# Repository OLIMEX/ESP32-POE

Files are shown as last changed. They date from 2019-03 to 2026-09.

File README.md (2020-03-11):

# ESP32-POE

ESP32-PoE is an IoT WIFI/BLE/Ethernet development board with Power-Over-Ethernet feature.

The Si3402-B chip is IEEE 802.3-compliant, including pre-standard (legacy) PoE support. 

Perfect solution for Internet-of-Things that can be expanded with sensors and actuators taking power from Ethernet cable.

Low-power design consuming less then 100uA in deep sleep mode!

Product page: https://www.olimex.com/Products/IoT/ESP32/ESP32-POE/open-source-hardware

## License
* Hardware is released under Apache 2.0 License
* Software is released under GPL3 License
* Documentation is released under CC BY-SA 3.0

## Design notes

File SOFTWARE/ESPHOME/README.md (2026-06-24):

# ESPHome configurations for Olimex ESP32-POE boards

These YAML files are starter configurations for ESP32-POE and ESP32-POE-ISO
variants.

## Which file to use

- `esp32-poe.yaml`: ESP32-POE with ESP32-WROOM-32E-N4, 4 MB flash.
- `esp32-poe-16mb.yaml`: ESP32-POE with ESP32-WROOM-32E-N16, 16 MB flash.
- `esp32-poe-wrover.yaml`: ESP32-POE with ESP32-WROVER-E-N4R8, 4 MB flash and PSRAM.
- `esp32-poe-iso.yaml`: ESP32-POE-ISO with ESP32-WROOM-32E-N4, 4 MB flash.
- `esp32-poe-iso-16mb.yaml`: ESP32-POE-ISO with ESP32-WROOM-32E-N16, 16 MB flash.
- `esp32-poe-iso-wrover.yaml`: ESP32-POE-ISO with ESP32-WROVER-E-N4R8, 4 MB flash and PSRAM.

External antenna module variants use the same YAML as the matching flash/PSRAM
variant.

## Wi-Fi or Ethernet

The files enable Wi-Fi by default. Add your credentials to `secrets.yaml`:

```yaml
wifi_ssid: "your_wifi_name"
wifi_password: "your_wifi_password"
```

To use Ethernet instead, comment the whole `wifi:` section and
`captive_portal:`, then uncomment the `ethernet:` section in the YAML.

## Notes

- WROOM variants use Ethernet clock output on GPIO17.
- WROVER variants use Ethernet clock output on GPIO0.
- WROVER variants use GPIO33 for UEXT I2C SCL because GPIO16/GPIO17 are used
  by PSRAM.
- UEXT SPI uses GPIO14 SCK, GPIO2 MOSI, GPIO15 MISO, and GPIO5 chip-select.
  These pins are shared with the microSD interface.
- The 16 MB YAMLs set `esp32.flash_size: 16MB`; ESPHome defaults to 4 MB if
  this is not specified.

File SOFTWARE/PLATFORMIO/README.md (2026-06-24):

# PlatformIO board definitions for Olimex ESP32-POE boards

This folder contains custom PlatformIO board manifests for ESP32-POE and
ESP32-POE-ISO variants, plus a `platformio.ini` with ready-to-use environments.

## Which environment to use

- `esp32-poe`: ESP32-POE with ESP32-WROOM-32E-N4, 4 MB flash.
- `esp32-poe-16mb`: ESP32-POE with ESP32-WROOM-32E-N16, 16 MB flash.
- `esp32-poe-wrover`: ESP32-POE with ESP32-WROVER-E-N4R8, 4 MB flash and PSRAM.
- `esp32-poe-iso`: ESP32-POE-ISO with ESP32-WROOM-32E-N4, 4 MB flash.
- `esp32-poe-iso-16mb`: ESP32-POE-ISO with ESP32-WROOM-32E-N16, 16 MB flash.
- `esp32-poe-iso-wrover`: ESP32-POE-ISO with ESP32-WROVER-E-N4R8, 4 MB flash and PSRAM.

External antenna module variants use the same environment as the matching
flash/PSRAM variant.

## How to build

Run PlatformIO from this folder:

```sh
pio run -e esp32-poe
```

Replace `esp32-poe` with the environment for your board. For example:

```sh
pio run -e esp32-poe-iso-16mb
pio run -e esp32-poe-wrover
```

The `platformio.ini` sets `boards_dir = .`, so PlatformIO will find the custom
JSON files in this same folder.

## Board manifest notes

- WROOM N4 manifests set 4 MB flash.
- WROOM N16 manifests set 16 MB flash, `maximum_size: 16777216`, and Arduino
  partition table `default_16MB.csv`.
- WROVER manifests enable PSRAM with `BOARD_HAS_PSRAM` and `psram_type: qspi`.
- All manifests predefine LAN8720 Ethernet macros for Arduino `ETH.begin()`.
- WROOM variants use Ethernet clock output on GPIO17.
- WROVER variants use Ethernet clock output on GPIO0.
- Ethernet MDC is GPIO23, MDIO is GPIO18, PHY address is 0, and PHY power is
  GPIO12.

## Upload and monitor

The manifests allow USB serial upload with `esptool` and OTA upload with
`espota`. Serial monitor speed is set to 115200 in `platformio.ini`.

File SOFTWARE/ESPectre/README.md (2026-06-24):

# Using ESPectre with Olimex ESP32-POE / ESP32-POE-ISO and Home Assistant

This guide shows how to flash an Olimex [ESP32-POE](https://www.olimex.com/Products/IoT/ESP32/ESP32-POE/open-source-hardware) or [ESP32-POE-ISO](https://www.olimex.com/Products/IoT/ESP32/ESP32-POE-ISO/open-source-hardware) board with [ESPectre](https://espectre.dev/) and add it to [Home Assistant](https://www.home-assistant.io/) through ESPHome.

ESPectre is a motion detection system based on Wi-Fi Channel State Information (CSI). It detects movement by analyzing changes in the Wi-Fi signal between an ESP32 board and a Wi-Fi router or access point.

The steps below were tested with:

- Olimex ESP32-POE / ESP32-POE-ISO
- ESPectre `2.8.0`
- Home Assistant running on a Raspberry Pi
- ESPHome integration in Home Assistant

## 1. Install and prepare Home Assistant

First, you need a working Home Assistant server. In this setup, Home Assistant is running on a Raspberry Pi, but you can also use another supported board, mini PC, virtual machine, or computer.

Follow the official Home Assistant installation guide and choose the installation method that fits your hardware:

<https://www.home-assistant.io/installation/>

Make sure you can open your Home Assistant web interface before continuing. For example:

```text
http://homeassistant.local:8123/
```

The Home Assistant server and the ESP32 board must be on the same local network.

## 2. Download the ESPectre firmware

Download the pre-built ESPectre binary for the ESP32 chip from the latest ESPectre release:

<https://github.com/francescopace/espectre/releases/latest>

At the time of writing, this guide used:

<https://github.com/francescopace/espectre/releases/download/2.8.0/espectre-2.8.0-esp32.bin>

If you use a different ESP32 variant, download the correct binary for that chip.

## 3. Flash the Olimex ESP32 board

Connect the Olimex ESP32 board to your computer with a USB data cable.

You can flash the binary using different tools. This guide uses Espressif's online flasher:

<https://espressif.github.io/esptool-js/>

Open the flasher in a supported browser, such as Chrome or Edge.

1. Select a baud rate. A safe option is `115200`.
2. Click **Connect**.
3. Select the serial port for the Olimex ESP32 board.
4. Click **Connect** again.

Set the flash address to:

```text
0x0000
```

This is important. The ESPectre `.bin` file used here is a factory image and must be flashed at address `0x0000`. If it is flashed at another address, for example `0x1000`, the board will not boot correctly.

Click **Choose File** and select the ESPectre binary, for example:

```text
espectre-2.8.0-esp32.bin
```

Leave the other flash settings at their default values unless you have a specific reason to change them.

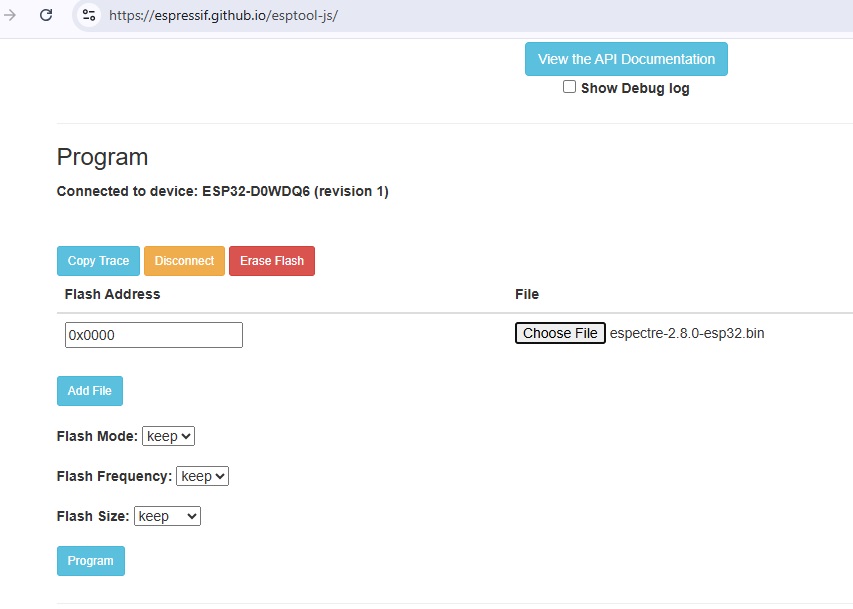
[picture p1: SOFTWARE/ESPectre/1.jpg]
Espressif online flasher configured with ESPectre binary at flash address 0x0000


Click **Program** and wait until flashing completes successfully.

## 4. Connect the board to Wi-Fi

After flashing, the board has the ESPectre firmware installed, but it still needs Wi-Fi credentials.

There are several ways to configure Wi-Fi. This guide uses the fallback Wi-Fi access point from a phone.

1. Reboot the Olimex ESP32 board by pressing the reset button.
2. On your phone, open the Wi-Fi settings.
3. Connect to the network named **ESPectre Fallback**.

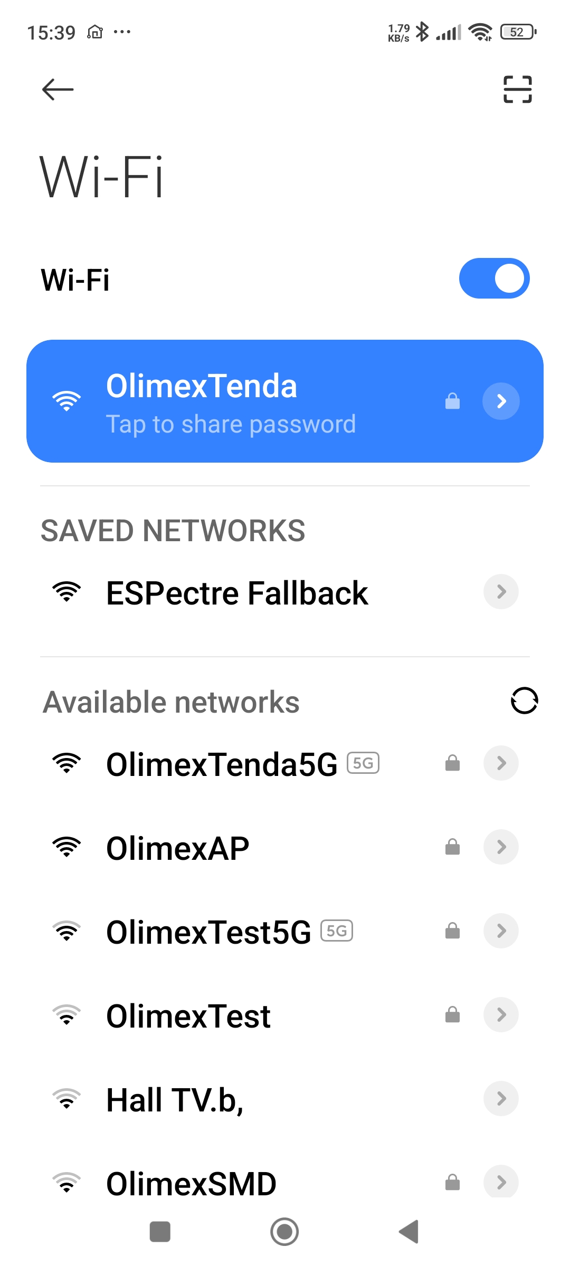
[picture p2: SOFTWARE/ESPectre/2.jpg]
Phone Wi-Fi settings showing the ESPectre Fallback network


After connecting, your phone should open the ESPectre captive portal automatically. If it does not open automatically, try opening:

```text
http://192.168.4.1/
```

Select your normal 2.4 GHz Wi-Fi network and enter its password.

The board and the Home Assistant server must be connected to the same network. In this example, the selected network is `OlimexTenda`.

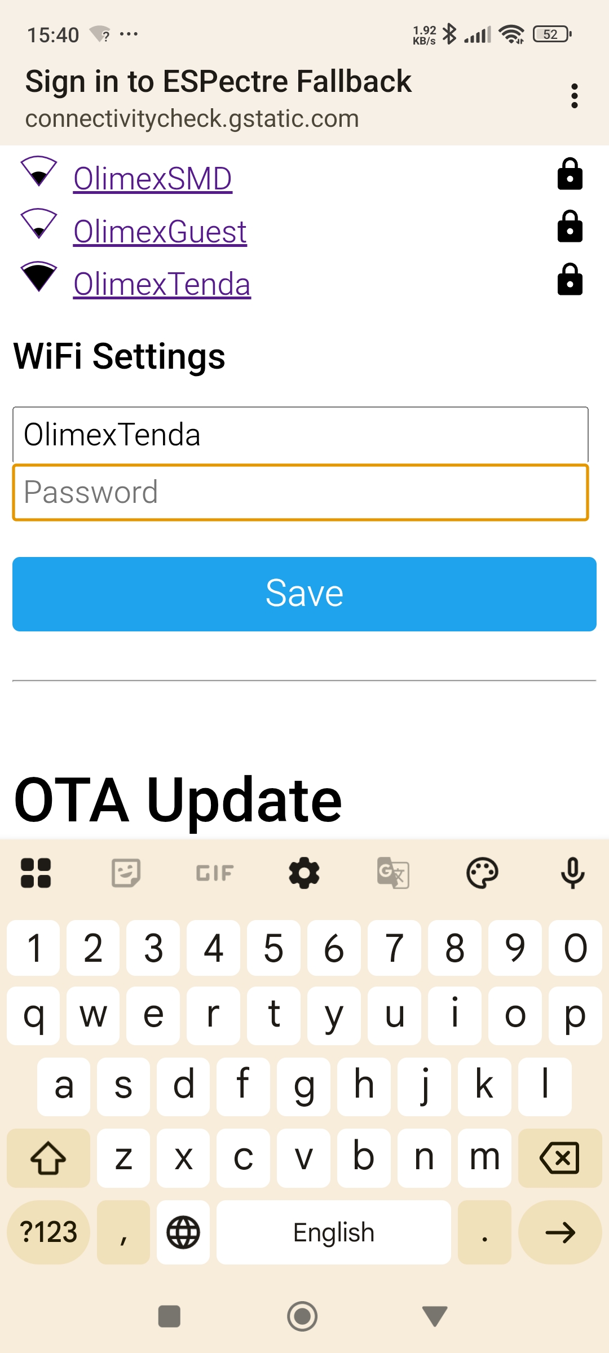
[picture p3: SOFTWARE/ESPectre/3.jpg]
ESPectre captive portal Wi-Fi settings page


Click **Save**. Wait until the page closes or the phone reconnects to your normal Wi-Fi network.

The **ESPectre Fallback** network should disappear after the board successfully joins your Wi-Fi network.

## 5. Add ESPectre to Home Assistant

Open your local Home Assistant web interface and log in with an administrator account:

```text
http://homeassistant.local:8123/
```

Go to:

```text
Settings -> Devices & services
```

Home Assistant should automatically discover the ESPectre device through ESPHome.

Look for **ESPectre** under discovered integrations and click **Add**.

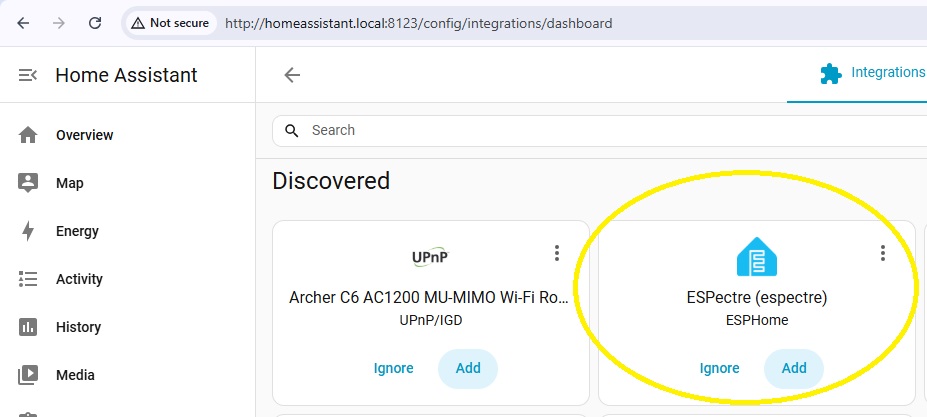
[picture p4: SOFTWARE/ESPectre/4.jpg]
Home Assistant discovered integrations page showing ESPectre


Click **Submit**. You can then assign a name and area/room if you want.

If the device is not discovered automatically, add it manually:

1. Go to **Settings -> Devices & services**.
2. Click **Add integration**.
3. Search for **ESPHome**.
4. Use `espectre.local` as the host.
5. Use port `6053`.

If `espectre.local` does not work, find the board's IP address in your router DHCP/client list and use that IP address instead.

## 6. Test motion detection

After adding the device, open the ESPectre device page in Home Assistant.

You should see entities such as:

- Motion Detected
- Movement Score
- Calibrate
- Threshold

Place the board with the antenna facing upward, preferably on the opposite side of the monitored area from the Wi-Fi router or access point.

For the first test:

1. Keep the room still.
2. Calibrate the sensor with no movement in the room.
3. Walk between the Wi-Fi router and the ESP32 board.
4. Watch the motion state and movement score in Home Assistant.
5. Adjust the threshold if needed.

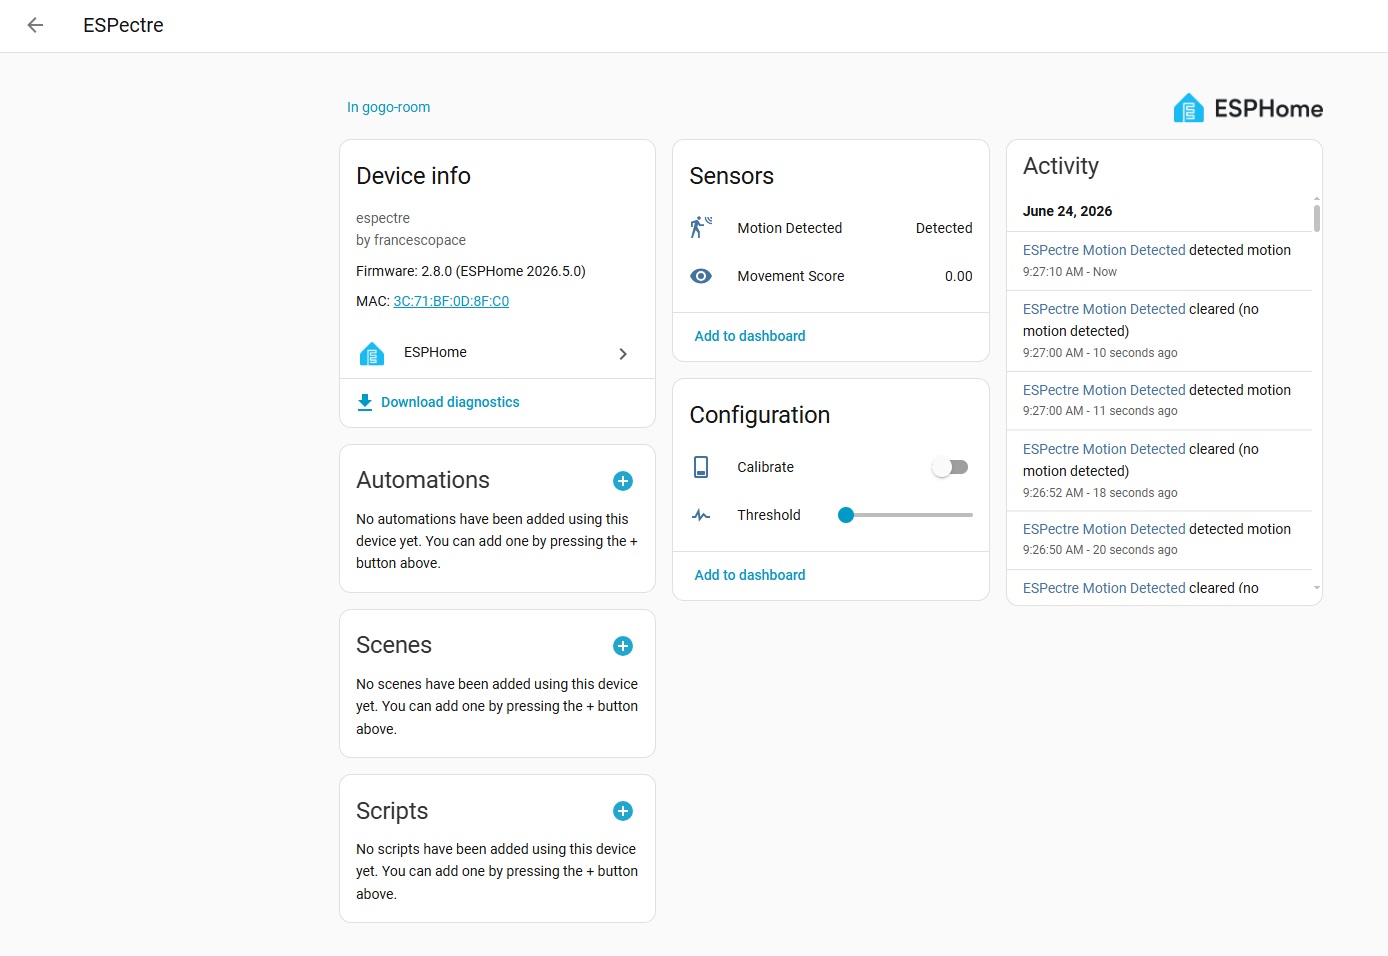
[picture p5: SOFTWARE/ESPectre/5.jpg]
ESPectre device page in Home Assistant showing motion detection and movement score


The best threshold depends on the room, router position, board position, and how sensitive you want the detection to be.

## Notes

- The pre-built ESPectre binary used here is for the original ESP32 chip.
- The ESP32-POE and ESP32-POE-ISO can be powered through PoE, but the pre-built ESPectre firmware uses Wi-Fi for CSI motion detection.
- Use a 2.4 GHz Wi-Fi network. ESP32 boards do not support 5 GHz Wi-Fi.
- If the fallback network appears again after reboot, the board probably failed to connect to your Wi-Fi. Reconnect to **ESPectre Fallback** and enter the Wi-Fi credentials again.
- If Home Assistant does not discover the board, make sure the ESP32 board and Home Assistant server are on the same network.
- If your Home Assistant account cannot see **Settings**, the account needs administrator access.

## Using other ESP32 boards

This guide can be used as a starting point for other ESP32 modules and boards. Make sure to download the correct pre-built ESPectre binary for your chip from the ESPectre releases page.

## Automation ideas

After ESPectre is added to Home Assistant through ESPHome, its motion detection entity can be used as a trigger for automations.

For example, you can use Home Assistant or the ESPHome web interface to create automations that:

- Take a snapshot from a camera when motion is detected.
- Turn on a light or relay.
- Send a notification.
- Start recording from another device.
- Trigger any other Home Assistant action supported by your setup.

This makes ESPectre useful not only as a standalone motion detector, but also as a trigger source for larger Home Assistant automations.

## Further reading

- <https://github.com/francescopace/espectre>
- <https://github.com/esphome>
- <https://github.com/home-assistant>
- <https://www.home-assistant.io/installation/>

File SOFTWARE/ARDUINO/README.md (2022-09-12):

Make sure that you have properly installed the support for ESP32 chips in your Arduino IDE environment. Check the Arduino for ESP32 GitHub page for installation instructions: https://github.com/espressif/arduino-esp32

We commit updates directly to the ESP32's GitHub. When installing the ESP32 for Arduino IDE refer to these instructions:

https://docs.espressif.com/projects/arduino-esp32/en/latest/installing.html

After a successful installation make sure to select the Olimex board in Tools -> Board and its corresponding COM port from Tools -> Port.

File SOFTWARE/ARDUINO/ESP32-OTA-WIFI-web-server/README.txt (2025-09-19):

This code demonstrates Over-the-Air upgrade functionality over WIFI (e.g. remote update).

This demo is compatible with ESP32-POE and ESP32-POE-ISO without any changes.

It is implementation of the free version of ElegantOTA. It is worth checking and supporting the ElegantOTA project.

How to use this demo?

Author used Arduino IDE 1.8.19 and version 3.1.3 of the esp32 package for Arduino released by espressif systems. You also need to install ElegantOTA via the Arduino Library Manager, follow the guide here:

https://docs.elegantota.pro/getting-started/installation

You need to change the WIFI credentials with yours (SSID, PASSWORD).

It is recommended to attach a LED between GND and GPIO4 at the UEXT (pins #2 and #3) for quicker empirical debug.

Make sure the exact board is selected in Arduino IDE and proper COM then open the ota-server.ino and then Upload it to the board. Check the serial for web-page address and go to the address via a browser and append /upload to land the upload page.

The interface requires binary to upload. You can create such binary via Arduino IDE from Sketch -> "Export compiled binary". Open ota-server-gpio1000.ino and ota-server-gpio5000.ino and click export compiled binary on both. Use these binaries to upload to the board via the Ethernet interface. If you have attached a LED to GPIO4 you'd see it start blink every 1s or every 5s depending on the code.

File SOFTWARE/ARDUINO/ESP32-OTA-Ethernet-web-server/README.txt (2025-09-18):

This code demonstrates Over-the-Air upgrade functionality over Ethernet (e.g. remote update).

This demo is compatible with ESP32-POE and ESP32-POE-ISO without any changes. 

WROVER variants of ESP32-POE and ESP32-POE-ISO require slight modifcation (changing GPIO17 to GPIO0).

The other Olimex-made boards require easy edit to fit the hardware setup, just change the defintions in:

ETH.begin(ETH_PHY_LAN8720, 0, 23, 18, 12, ETH_CLOCK_GPIO17_OUT);

What is this demo?

It allows OTA downloads via Ethernet. It creates web-server and prints in the serial terminal the IP address of the web-server. The downloads are done via the interface of the web-page at the IP address assigned by DHCP. The web-page also prints firmware version, IP address and size of binary.

How to use this demo?

Author used Arduino IDE 1.8.19 and version 3.1.3 of the esp32 package for Arduino released by espressif systems.

It is recommended to attach a LED between GND and GPIO4 at the UEXT (pins #2 and #3) for quicker debug.

Make sure the exact board is selected in Arduino IDE and proper COM then load the OTA-ETHERNET-PAGE.ino and then Upload it to the board.

Start serial terminal to see IP address asigned but if you missed it just reset the board from the RST1 button. Then navigate to the IP address via a web browser.

The interface requires binary to upload. You can create such binary via Arduino IDE from Sketch -> "Export compiled binary". Open OTA-ETHERNET-PAGE-BLINK1000.ino and OTA-ETHERNET-PAGE-BLINK5000.ino and click export compiled binary on both. Use these binaries to upload to the board via the Ethernet interface. If you have attached a LED to GPIO4 you'd see it start blinkig and also the web-page should get different firmware version for different binaries you use.

Refer to the pictures.

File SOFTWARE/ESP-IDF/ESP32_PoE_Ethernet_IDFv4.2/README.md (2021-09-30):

# Ethernet Example

## Overview

This example is based on the original example of Espressif "ethernet\basic" and adapted to function with Olimex boards ESP32-PoE and ESP32-PoE-ISO. It demonstrates basic usage of `Ethernet driver` together with `tcpip_adapter`. The work flow of the example could be as follows:

1. Install Ethernet driver
2. Send DHCP requests and wait for a DHCP lease
3. If get IP address successfully, then you will be able to ping the device

If you have a new Ethernet application to go (for example, connect to IoT cloud via Ethernet), try this as a basic template, then add your own code.

## How to use example

### Hardware Required

To run this example, it's recommended that you have one of the Olimex boards [ESP32-PoE](https://www.olimex.com/Products/IoT/ESP32/ESP32-POE/) or [ESP32-PoE-ISO](https://www.olimex.com/Products/IoT/ESP32/ESP32-POE-ISO/). This example should also work for 3rd party ESP32 board as long as it's integrated with a supported Ethernet PHY chip. Up until now, ESP-IDF supports up to four Ethernet PHY: `LAN8720`, `IP101`, `DP83848` and `RTL8201`, additional PHY drivers should be implemented by users themselves.

Notice that Olimex board uses LAN8710 chip but the libraries for LAN8710 and LAN8720 are similar (the chips are very similar).

Besides that, `esp_eth` component can drive third-party Ethernet module which integrates MAC and PHY and provides common communication interface (e.g. SPI, USB, etc).This example will take the **LAN8720** library for the an example, illustrating how to install the Ethernet driver in the same manner. In this project by default this feature is disabled. If you want to enable it:
```
idf.py menuconfig
```
then option and navigate to "Component config -> Ethernet" and check the "Support SPI to Ethernet Module" and then in that submenu check "Use LAN8720".

#### Pin Assignment

| GPIO | RMII Signal | Notes |
| --- | --- | --- |
| GPIO21 | TX_EN | EMAC_TX_EN |
| GPIO19 | TX0 | EMAC_TXD0 |
| GPIO22 | TX1 | EMAC_TXD1 |
| GPIO25 | RX0 | EMAC_RXD0 |
| GPIO26 | RX1 | EMAC_RXD1 |
| GPIO27 | CRS_DV | EMAC_RX_DRV  |
| GPIO17 | CLK | EMAC_CLK_OUT |

* SMI (Serial Management Interface) wiring is not fixed. You may need to changed it according to your board schematic. By default they're connected as follows:

| GPIO | SMI Signal  | Notes |
| --- | --- | --- |
| GPIO23 | MDC | Output to PHY |
| GPIO18 | MDIO | Bidirectional |

* PHY chip has a reset pin, but is not connected to the ESP32-PoE(-ISO) and thus it is left as -1 value.
### Configure the project

```
idf.py menuconfig
```

In the Example Configuration menu:

Choose the kind of Ethernet under Ethernet Type.
If Internal EMAC is selected:
Choose PHY device under Ethernet PHY Device, by default, ESP32-PoE(-ISO) has an LAN8710A on board but it works fine with LAN8720 selected from the menuconfig.
Set GPIO number used by SMI signal under SMI MDC GPIO number and SMI MDIO GPIO number respectively.
If DM9051 Module is selected:
Set SPI specific configuration, including SPI host number, GPIO number and clock rate.
Set GPIO number used by PHY chip reset under PHY Reset GPIO number, you may have to change the default value according to your board schematic. PHY hardware reset can be disabled by set this value to -1.
Set PHY address under PHY Address, you may have to change the default value according to your board schematic.
For this project values are as follows:
| Value  | Option |
| --- | --- |
| Internal | Ethernet Type |
| LAN8720  |  Ethernet PHY Device  |
|  GPIO23  | SMI MDC GPIO |
|  GPIO18  | SMI MDIO GPIO |
| -1 | PHY Reset GPIO number |
| 0 | PHY Address |

In the Component config > Ethernet menu:

Under Support ESP32 internal EMAC controller sub-menu:
In the PHY interface, select Reduced Media Independent Interface (RMII), ESP-IDF currently only support RMII mode.
In the RMII clock mode, select one of the source that RMII clock (50MHz) comes from: Input RMII clock from external or Output RMII clock from internal.
If Output RMII clock from internal is enabled, you also have to set the GPIO number that used to output the RMII clock, under RMII clock GPIO number. In this case, you can set the GPIO number to 16 or 17.
If Output RMII clock from GPIO0 (Experimental!) is also enabled, then you have no choice but GPIO0 to output the RMII clock.
In Amount of Ethernet DMA Rx buffers and Amount of Ethernet DMA Tx buffers, you can set the amount of DMA buffers used for Tx and Rx.
Under Support SPI to Ethernet Module sub-menu, select the SPI module that you used for this example. Currently ESP-IDF only supports DM9051.
For this project values are as follows:
| Value | Option |
| --- | ---|
| RMII | PHY Interface |
|  Output |  RMII clock mode |
| unchecked |  Output RMII clock |
|  GPIO17 |  clock PGIO number |
| 512 | DMA buffer Size  |
| 10 | DMA Rx buffers |
| 10 | DMA Tx buffers |

### Build, Flash, and Run

Build the project and flash it to the board, then run monitor tool to view serial output:

```
idf.py -p PORT build flash monitor
```

(Replace PORT with the name of the serial port to use.)

(To exit the serial monitor, type ``Ctrl-]``.)

See the [Getting Started Guide](https://docs.espressif.com/projects/esp-idf/en/latest/get-started/index.html) for full steps to configure and use ESP-IDF to build projects.

## Example Output

```bash
I (394) eth_example: Ethernet Started
I (3934) eth_example: Ethernet Link Up
I (3934) eth_example: Ethernet HW Addr 30:ae:a4:c6:87:5b
I (5864) tcpip_adapter: eth ip: 192.168.2.151, mask: 255.255.255.0, gw: 192.168.2.2
I (5864) eth_example: Ethernet Got IP Address
I (5864) eth_example: ~~~~~~~~~~~
I (5864) eth_example: ETHIP:192.168.2.151
I (5874) eth_example: ETHMASK:255.255.255.0
I (5874) eth_example: ETHGW:192.168.2.2
I (5884) eth_example: ~~~~~~~~~~~
```

Now you can ping your ESP32 in the terminal by entering `ping 192.168.2.151` (it depends on the actual IP address you get).

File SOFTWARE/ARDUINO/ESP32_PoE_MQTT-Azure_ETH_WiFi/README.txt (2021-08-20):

This example combines two default examples (to add Azure feature with Ethernet as well) from the Espressif Package:
1) ESP32 Azure IoT Arduino --> SimpleMQTT
2) WiFi --> ETH_LAN8720
<<<<<<< HEAD
In order to work you have to choose the prefered network option (ethernet/WiFi) depending on the ETHERNET macro on the top of the project. In case it is commented out, WiFi will be used and you have to input the SSID and password of your WiFi network. Ethernet is chosen by default.
=======
In order to work you have to choose the prefered network option (ethernet/WiFi) depending on the ETHERNET macro on the top of the project. In case it is commented WiFi will be used and you have to input the SSID and password of your WiFi network. Ethernet is chosen by default.
>>>>>>> origin/master
Also you have to input in "connectionString" the HostName, DeviceID and SharedAccessKey from Azure. In order to get these values follow the instructions on the Microsoft guide:
https://docs.microsoft.com/en-us/samples/azure-samples/esp-samples/esp-samples/
https://docs.microsoft.com/en-us/azure/iot-hub/iot-hub-create-through-portal

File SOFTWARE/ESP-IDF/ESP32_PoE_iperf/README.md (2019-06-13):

This demo is based on the original iperf demo in esp-idf with adapted configuration for ESP32-PoE.

In order to make it work:
1) Select the port where the board has connected using menuconfig. To do so type inside the console (msys32 or terminal):
make menuconfig

2) Navigate to "Menu flasher config --> Default serial port" select your port.

3) After that flash the board (this may take a while the first time after you change any of the configurations)
make flash

4) Then run the terminal
make monitor

5) Wait to initialize follow the instructions on the terminal:
5.1) Run the ethernet
ethernet start
5.2) Optionally if you want to see more details (IP address, mask, default gateway) type
ethernet macro

6) Run the iperf
6.1) Server mode:
iperf -s -i 1 -t 10
with this you will run it for 10 seconds transfer (more than that will trigger the watchdog reset) and 1 second interval.

6.2) Client mode:
iperf -c SERVER_IP_ADDRESS -i 1

You can check the sample data inside the ESP32-PoE_Data.txt file.

YYYY/MM/DD
2019/06/13

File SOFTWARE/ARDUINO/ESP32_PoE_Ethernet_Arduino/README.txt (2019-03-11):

This demo is based on the default demo of espressif package "ETH_LAN8720" adapted for Olimex board ESP32-PoE rev.B.
It implements acquiring of an IP address and ethernet event usage which are visible on the terminal.

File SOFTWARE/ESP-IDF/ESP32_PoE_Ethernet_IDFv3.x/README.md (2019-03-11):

This is a simple demo for Olimex ESP32-PoE revision B board.

The demo sets up Ethernet connection and acquires IP address. It is made with ESP-IDF.

In order to get it the software you should:

1) Setup the ESP-IDF development framework. You can download and install it by following the instructions here  https://github.com/espressif/esp-idf

2) Start: "msys32/mingw32.exe" and navigate to this project's directory.

3) Connect ESP32-PoE to the USB and specify the board's USB port in the ESP-IDF menu:

3.1) "make menuconfig"
3.2) Navigate to: Serial flasher config --> Default serial port --> <here select proper USB port>
3.3) Save the settings.

4) Compile this example and upload it to the board with command: "make flash"

5) Wait until firmware is flashed and open terminal on the ESP32-PoE port.

6) Press enter to start the demo and wait until it is initialized. Your network needs DHCP.

7) When you get IP address you can ping the printed IP.

2018/09/14

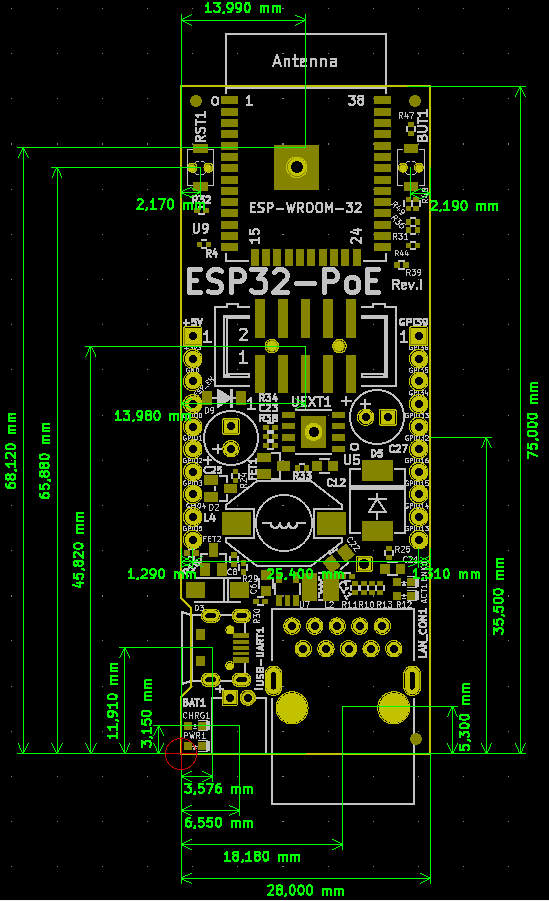
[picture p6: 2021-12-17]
HARDWARE/Dimensions/top.png

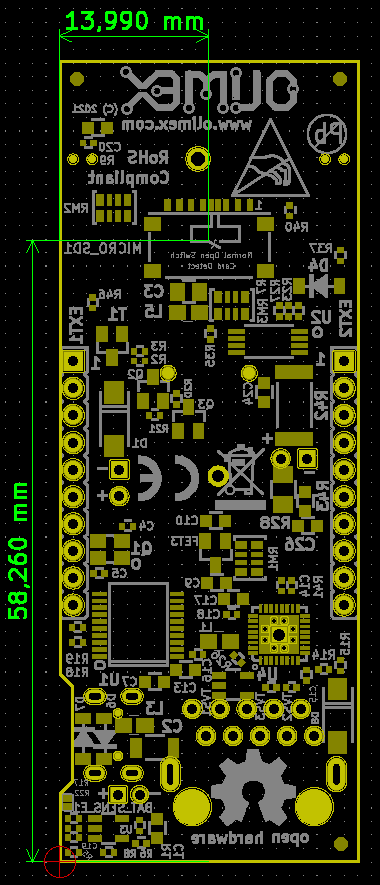
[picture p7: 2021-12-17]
HARDWARE/Dimensions/bottom.png

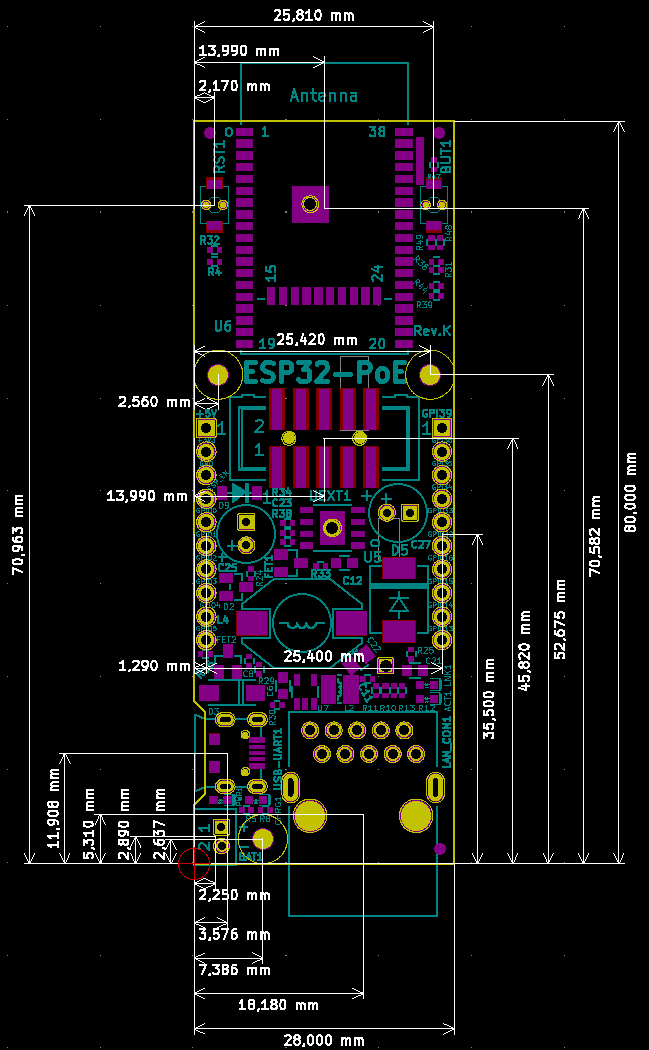
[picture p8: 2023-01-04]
HARDWARE/Dimensions/Revision J and newer/esp32-poe-dimensions.png

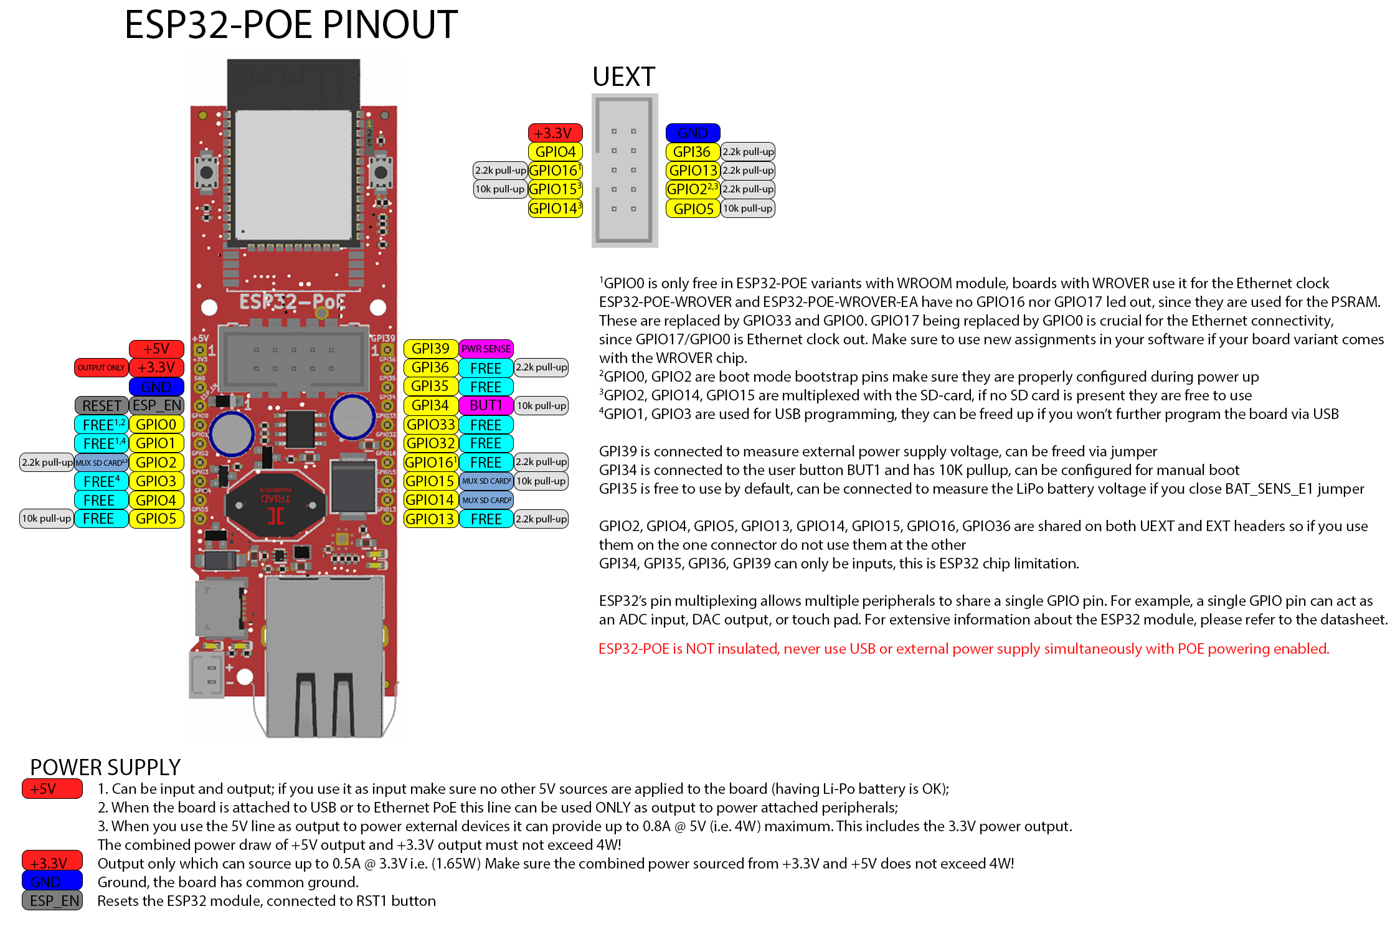
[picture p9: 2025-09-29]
DOCUMENTS/ESP32-POE-PINOUT.png

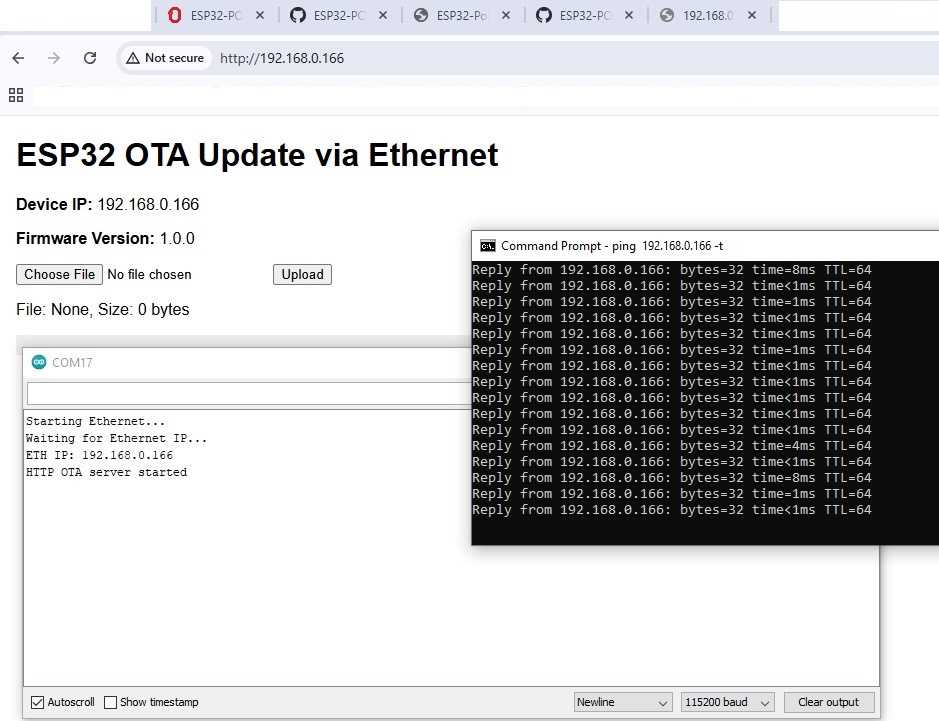
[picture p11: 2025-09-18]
SOFTWARE/ARDUINO/ESP32-OTA-Ethernet-web-server/Web-interface-ping-serial-port-info.jpg

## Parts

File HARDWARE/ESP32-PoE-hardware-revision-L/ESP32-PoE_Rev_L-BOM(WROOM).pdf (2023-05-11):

ESP32-PoE_Rev_L-BOM(WROOM) | 10/06/2022
Quantity | Designation | Package | Designator
1 | 0.03R/1%/R1206 | R1206 | R28
1 | 4.7R/R0402 | R0402 | R33
1 | 10R/R0402 | R0402 | R40
4 | 49.9R/1%/R0402 | R0402 | R10,R11,R12,R13
3 | 220R/R0402 | R0402 | R24,R46,R47
3 | 1k/R0402 | R0402 | R3,R20,R21
8 | 2.2k/R0402 | R0402 | R5,R6,R8,R14,R15, R31,R35,R41
3 | RA1206_(4X0603)_4B8_2.2k | RA1206 | RM1,RM2,RM3
1 | 4.42k/1%/1/16W/R0402 | R0402 | R27
1 | 4.7k/R2512 | R2512 | R42
1 | 5.23k/1%/R0402 | R0402 | R34
11 | 10k/R0402 | R0402 | R1,R2,R18,R19,R25,R32, R36,R37,R39,R48,R51
1 | 12.1k/1%/R0402 | R0402 | R26
1 | 24.9k/1%/R0402 | R0402 | R7
1 | 30.1k/1%/R0402 | R0402 | R38
1 | 47k/R0402 | R0402 | R4
1 | 49.9k/1%/R0402 | R0402 | R30
1 | 100k/R0402 | R0402 | R9
1 | 130k/R0402 | R0402 | R50
1 | 180k/1%/R0402 | R0402 | R23
1 | 220k/R0402 | R0402 | R29
2 | 470k/R0402 | R0402 | R17,R22
3 | FB0805/600R/2A | L0805 | L1,L3,L5
1 | 2.2uH/1.5A/DCR=72mR/ 20%/3.00x3.00x1.50mm/ CD32(NR3015T2R2M) | CD32 | L2
1 | 33uH/2.1A/DCR=0.1R/20%/ DBS135(PD3316MT330) | DBS135 | L4
1 | 12pF/50V/5%/COG/C0402 | C0402 | C23
2 | 27pF/50V/5%/C0G/C0402 | C0402 | C4,C5
1 | 1nF/50V/10%/X7R/C0402 | C0402 | C19
1 | 1nF/2000V/10%/X7R/C1206 | C1206 | C2
6 | 100nF/16V/10%/X7R/C0402 | C0402 | C8,C11,C14,C15, C16,C18
2 | 100nF/100V/10%/X7R/C0603 | C0603 | C12,C24
1 | 1uF/10V/20%/X5R/C0603 | C0603 | C20
1 | 2.2uF/6.3V/10%/X5R/C0603 | C0603 | C17
1 | 15uF/100V/20%/RM2.5/ 6.3x11mm(Farnell:1281844) | CPOL-RM2.5mm_ 6.3x11mm_PTH | C27
6 | 22uF/6.3V/20%/X5R/C0603 | C0603 | C1,C6,C7,C9,C10,C13
2 | 47uF/6.3V/20%/X5R/C0805 | C_0805_5MIL_DWS | C3,C22
1 | 470uF/10V/20%/Low_ESR/ RM2.5/6.0x11mm | CPOL-RM2.5mm_ 6.3x11mm_PTH | C25
1 | BAT54C(SOT23-3) | SOT23-3 | D2

ESP32-PoE_Rev_L-BOM(WROOM) | 10/06/2022
4 | 1N5819S4(SOD-123) | SOD-123 | D4,D6,D7,D9
2 | 1N5822/SS34/SMA | SMA | D1,D3
1 | SS510/100V/5A/0.85V/ DO214AB(SMC) | DO214AB(SMC) | D5
1 | SMAJ58A/SMA | SMA | D8
1 | ESDS314DBVR(SOT-23-5) | SOT-23-5 | TVS1
1 | LED/RED/0603 | LED_0603 | PWR1
1 | LED/GREEN/0603 | LED_0603 | LNK1
2 | LED/YELLOW/0603 | LED_0603 | ACT1,CHRG1
2 | BC817-40(SOT23) | SOT23 | Q2,Q3
1 | LMUN2211LT1G(SOT-23) | SOT23 | T1
3 | WPM2015-3/TR | SOT23 | FET1,FET2,FET3
1 | BL4054B-42TPRN(SOT23-5) | SOT-23-5 | U3
1 | CH340T(SSOP20W) | SSOP-20W | U1
1 | ESP32-WROOM-32E | ESP32-WROVER (WROOM)-UNIVERSAL_ MODULE | U6
1 | LAN8710A-EZC(QFN32) | QFN32 | U4
1 | SY8089AAAC(SOT23-5) | SOT-23-5 | U7
1 | TPS2376D(SO-8) | SOIC-8 | U2
1 | TX4138(ESOIC-8) | ESOIC-8 | U5
1 | Q12MHz/20pF/10ppm/4P/3.2x2.5mm | TSX-3.2x2.5mm | Q1
2 | IT1185AU2 | IT1185AU2 | BUT1,RST1
1 | DW02S | DW02S | BAT1
1 | MISB-SWMM-5B-LF(USB_MICRO) | MISB-SWMM-5B_LF | USB-UART1
1 | RJP-003TC1(LPJ4112CNL) | RJP-003TC1 (LPJ4112CNL) | LAN_CON1
1 | TFC-9P-1.7H(ATFFS150A01BR016) | uSD(TFC-9P-1.xH) | MICRO_SD1
1 | P-B-V-10-LF | GBH-254-SMT-10 | UEXT1
1 | Opened | SJ_1_SMALLER | BAT_SENS_E1
2 | NA/R0402 | R0402 | R44,R49
1 | NA(10R/R0402) | R0402 | R45
1 | NA(22R/R0603) | R0603 | R43
1 | NA(10k/R0402) | R0402 | R16
1 | NA(220pF/100V/C0603) | C0603 | C26
1 | NA(100nF/16V/10%/X7R/C0402) | C0402 | C28
1 | NA(10uF/6.3V/20%/X5R/C0603) | C0603 | C21
2 | NA(GG0402052R542P) | D0402 | TVS2,TVS3
1 | NA(SN74LVC1G04DBVR(SOT23-5)) | SOT-23-5 | U8
2 | NS(HN1x10) | HN1x10
EXT1,EXT2

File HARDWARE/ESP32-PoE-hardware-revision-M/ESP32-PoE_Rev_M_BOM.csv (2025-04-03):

Id | Designator | Footprint | Quantity | Designation | Supplier and ref
1 | FID3,FID1,FID6,FID4 | Fiducial1x3 | 4 | Fiducial
2 | UEXT1 | GBH-254-SMT-10 | 1 | P-B-V-10-LF
3 | D2 | SOT23-3 | 1 | BAT54C(SOT23-3)
4 | FET2,FET1,FET3 | SOT23 | 3 | WPM2015-3/TR
5 | R48,R39,R32,R25,R36,R1,R6,R18,R19,R2,R37 | R_0402_5MIL_DWS | 11 | 10k/R0402
6 | R47,R24,R46 | R_0402_5MIL_DWS | 3 | 220R/R0402
7 | R31,R8,R5,R14,R35,R15,R41 | R_0402_5MIL_DWS | 7 | 2.2k/R0402
8 | R4 | R_0402_5MIL_DWS | 1 | 47k/R0402
9 | CHRG1,ACT1 | LED_0603_KA | 2 | LED/YELLOW/0603
10 | R13,R10,R12,R11 | R_0402_5MIL_DWS | 4 | 49.9R/1%/R0402
11 | R44,R49 | R_0402_5MIL_DWS | 2 | NA/R0402
12 | LAN_CON1 | RJP-003TC1(LPJ4112CNL) | 1 | RJP-003TC1(LPJ4112CNL)
13 | C21 | C_0603_5MIL_DWS | 1 | NA(10uF/6.3V/20%/X5R/C0603)
14 | C22,C6,C9,C1,C7,C10,C13 | C_0603_5MIL_DWS | 7 | 22uF/6.3V/20%/X5R/C0603
15 | R33 | R_0402_5MIL_DWS | 1 | 4.7R/R0402
16 | D9,D4,D6,D7 | SOD-123_1C-2A_KA | 4 | 1N5819S4(SOD-123)
17 | C12,C24 | C_0603_5MIL_DWS | 2 | 100nF/100V/10%/X7R/C0603
18 | RST1,BUT1 | IT1185AU2_V2 | 2 | IT1185AU2
19 | C23 | C_0402_5MIL_DWS | 1 | 12pF/50V/5%/COG/C0402
20 | R34 | R_0402_5MIL_DWS | 1 | 5.23k/1%/R0402
21 | R38 | R_0402_5MIL_DWS | 1 | 30.1k/1%/R0402
22 | L2 | L_2016_MM | 1 | 1.0uH/4.2A/DCR=35mR/20%/2.00x1.60x1.00mm/L2016(PIM201610-1R0MTS00)
23 | FID2,FID5 | Fiducial1x3_Paste | 2 | Fiducial
24 | C27 | CPOL-RM2.5mm_6.3x11mm_PTH | 1 | 15uF/100V/20%/RM2.5/6.3x11mm(Farnell:1281844)
25 | D5 | DO214AB(SMC)_1(K)-2(A) | 1 | SS510/100V/5A/0.85V/DO214AB(SMC)
26 | C25 | CPOL-RM2.5mm_6.3x11mm_PTH | 1 | 470uF/10V/20%/Low_ESR/RM2.5/6.0x11mm
27 | L4 | DBS135 | 1 | 33uH/2.1A/DCR=0.1R/20%/DBS135(PD3316MT330)
28 | R29 | R_0402_5MIL_DWS | 1 | 220k/R0402
29 | R30 | R_0402_5MIL_DWS | 1 | 49.9k/1%/R0402
30 | D3,D1 | SMA-KA | 2 | 1N5822/SS34/SMA
31 | USB-UART1 | USB-MICRO_MISB-SWMM-5B_LF | 1 | MISB-SWMM-5B-LF(USB_MICRO)
32 | U7 | SOT-563-6 | 1 | TPS62A02ADRLR(SOT-563-6)
33 | C11,C15,C16,C18,C8,C14,C28 | C_0402_5MIL_DWS | 7 | 100nF/16V/10%/X7R/C0402
34 | LNK1 | LED_0603_KA | 1 | LED/GREEN/0603
35 | U5 | ESOIC-8 | 1 | TX4138(ESOIC-8)
36 | U6 | ESP32-WROVER_MODULE | 1 | ESP32-WROVER-E
37 | MH1,MH2,MH3 | NPTH_2.2mm | 3 | Mounting_Hole_NPTH
38 | BAT1 | LIPO_BAT_VERTICAL_DW02S | 1 | DW02S
39 | PWR1 | LED_0603_KA | 1 | LED/RED/0603
40 | C29 | C_0402_5MIL_DWS | 1 | NA(120pF/50V/5%/C0G/C0402)
41 | EXT2,EXT1 | HN1x10 | 2 | NS(HN1x10)
42 | RM1,RM2,RM3 | R_MATRIX_4 | 3 | RA1206_(4X0603)_4B8_2.2k
43 | MICRO_SD1 | uSD(TFC-9P-1.xH(ATFFS150A01BR016)) | 1 | TFC-9P-1.7H(ATFFS150A01BR016)
44 | R40,R45 | R_0402_5MIL_DWS | 2 | 10R/R0402
45 | C3 | C_0805_5MIL_DWS | 1 | 47uF/6.3V/20%/X5R/C0805
46 | C17 | C_0603_5MIL_DWS | 1 | 2.2uF/6.3V/10%/X5R/C0603
47 | L1,L3,L5 | L_0805_5MIL_DWS | 3 | FB0805/600R/2A
48 | R22,R17 | R_0402_5MIL_DWS | 2 | 470k/R0402
49 | C19 | C_0402_5MIL_DWS | 1 | 1nF/50V/10%/X7R/C0402
50 | BAT_SENS_E1 | SJ_1_SMALLER | 1 | Opened
51 | Sign_Antistatic | LOGO_ANTISTATIC_1 | 1 | Val**
52 | Sign_RecycleBin | LOGO_RECYCLEBIN_1 | 1
53 | Sign_PB-Free | LOGO_PBFREE | 1
54 | Logo_OSHW | LOGO_OPENHARDWARE_8x8 | 1
55 | C2 | C_1206_5MIL_DWS_ISO | 1 | 1nF/2000V/10%/X7R/C1206
56 | D8 | SMA-KA | 1 | SMAJ58A/SMA
57 | Q2,Q3 | SOT23 | 2 | BC817-40(SOT23)
58 | R21,R20,R3 | R_0402_5MIL_DWS | 3 | 1k/R0402
59 | R16 | R_0402_5MIL_DWS | 1 | NA(10k/R0402)
60 | Logo_Olimex | OLIMEX_LOGO_TB | 1
61 | TVS2,TVS3 | D_0402_5MIL_DWS | 2 | NA(GG0402052R542P)
62 | TVS1 | SOT-23-5 | 1 | ESDS314DBVR(SOT-23-5)
63 | U4 | QFN32_EP(33)_5.00x5.00x0.90mm_Pitch_0.50mm | 1 | LAN8710A-EZC(QFN32)
64 | R26 | R_0402_5MIL_DWS | 1 | 12.1k/1%/R0402
65 | R28 | R_1206_5MIL_DWS | 1 | 0.03R/1%/R1206
66 | R9 | R_0402_5MIL_DWS | 1 | 100k/R0402
67 | CE | CE_Sign | 1 | CE_Sign
68 | R42,R7 | R_2512_MM_DWS | 2 | 9.1k/R2512
69 | C26 | C_0603_5MIL_DWS | 1 | NA(220pF/100V/C0603)
70 | R43 | R_0603_5MIL_DWS | 1 | NA(22R/R0603)
71 | U8 | SOT-23-5 | 1 | SN74LVC1G04DBVR(SOT23-5)
72 | U3 | SOT-23-5 | 1 | TP4054-42-SOT25-R(SOT23-5)
73 | T1 | SOT23 | 1 | LMUN2211LT1G(SOT-23)
74 | C20 | C_0603_5MIL_DWS | 1 | 1uF/10V/20%/X5R/C0603
75 | R52 | R_0402_5MIL_DWS | 1 | 24.9k/1%/R0402
76 | R54 | R_0805_5MIL_DWS | 1 | 66.5R/1%/125mW/R0805
77 | U1 | MSOP-10_Pitch-0.5mm_3.00x3.00x1.00mm | 1 | CH340X(MSOP-10)
78 | R55 | R_0402_5MIL_DWS | 1 | 4.7k/R0402
79 | Class4_EN1 | SJ_Closed | 1 | Closed
80 | R53 | R_0402_5MIL_DWS | 1 | 1.27k/1%/62.5mW/R0402
81 | U9 | ESOIC-8 | 1 | TPS2378DDAR(HSOIC-8)

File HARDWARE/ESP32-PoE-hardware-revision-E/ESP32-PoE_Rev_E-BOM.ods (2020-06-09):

Quantity | Designation | Package | Designator
1 | 10R/R0402 | R0402 | R40
4 | 49.9R/1%/R0402 | R0402 | R10,R11,R12,R13
3 | 220R/R0402 | R0402 | R47,R24,R46
2 | 220R/5%/0.25W/R1206 | R1206 | R43,R45
3 | 1k/R0402 | R0402 | R20,R21,R3
1 | 1k/1%/R0402 | R0402 | R41
7 | 2.2k/R0402 | R0402 | R8,R14,R15,R5,R31,R35,R6
3 | RA1206_(4X0603)_4B8_2.2k | R_MATRIX | RM3,RM2,RM1
1 | 3.01k/1%/R0402 | R0402 | R42
10 | 10k/R0402 | R0402 | R37,R48,R18,R19,R1, R2,R25,R32,R36,R39
1 | 12.1k/1%/R0402 | R0402 | R26
1 | 25.5k/1%/R0603 | R0603 | R38
2 | 47k/R0402 | R0402 | R33,R4
1 | 49.9k/1%/R0402 | R0402 | R30
1 | 100k/R0402 | R0402 | R9
1 | 220k/R0402 | R0402 | R29
2 | 470k/R0402 | R0402 | R17,R22
3 | FB0805/600R/2A | L0805 | L1,L6,L5
1 | 2.2uH/1.5A/DCR=72mR/ 20%/3.00x3.00x1.50mm/ CD32(NR3015T2R2M) | CD32 | L2
1 | 33uH/2.1A/DCR=0.1R/20%/ DBS135(PD3316MT330) | DBS135 | L4
2 | 27pF/50V/5%/C0G/C0402 | C0402 | C4,C5
2 | 1nF/50V/10%/X7R/C0402 | C0402 | C19,C26
1 | 1nF/2000V/10%/X7R/C1206 | C1206 | C2
7 | 100nF/16V/10%/X7R/C0402 | C0402 | C8,C11,C15,C16,C18,C14,C25
1 | 100nF/100V/20%/C1206 | C1206 | C24
1 | 1uF/10V/20%/X5R/C0603 | C0603 | C20
1 | 2.2uF/6.3V/10%/X5R/C0603 | C0603 | C17
1 | 2.2uF/100V/20%/X7R/C1206 (AVX_12061C225KAT2A) | C1206 | C12
1 | 15uF/100V/20%/RM2.5/ 6.3x11mm(Farnell:1281844) | 6.3x11mm RM2.5mm | C27
7 | 22uF/6.3V/20%/X5R/C0603 | C0603 | C7,C9,C13,C1,C6,C30,C10
2 | 47uF/6.3V/20%/X5R/C0805 | C0805 | C3,C22
1 | 680uF/10V/20%/105C/ RM3.5/8x11.5mm | 8.0x11.5mm RM3.5mm | C29
1 | LED/RED/0603 | LED0603 | PWR1
2 | LED/YELLOW/0603 | LED0603 | CHRG1,ACT1
1 | LED/GREEN/0603 | LED0603 | LNK1
1 | BAT54C(SOT23-3) | SOT23-3 | D2
3 | 1N5819S4(SOD-123) | SOD-123 | D4,D6,D7
2 | 1N5822/SS34/SMA | SMA-KA | D1,D3
1 | SS510/100V/5A/0.85V/ DO214AB(SMC) | DO214AB(SMC) | D5
2 | BC817-40(SOT23) | SOT23 | Q2,Q3
1 | LMUN2211LT1G(SOT-23) | SOT23 | T1
3 | WPM2015-3/TR | SOT23 | FET1,FET2,FET3
1 | BL4054B-42TPRN(SOT23-5) | SOT-23-5 | U3
1 | CH340T(SSOP20W) | SSOP-20W | U1
1 | LAN8710A-EZC(QFN32) | QFN32 | U4
1 | Si3402-B-GM(QFN-20_5x5mm) | QFN-20 | U8
1 | SY8089AAAC(SOT23-5) | SOT-23-5 | U7
1 | ESP-WROOM-32 | ESP-WROOM-32 | U9
1 | Q12MHz/20pF/10ppm/ 4P/3.2x2.5mm | 3.2x2.5mm | Q1
2 | IT1185AU2 | IT1185AU2 | BUT1,RST1
1 | RJP-003TC1(LPJ4112CNL) | RJP-003TC1 | LAN_CON1
1 | P-B-V-10-LF | GBH-254-SMT-10 | UEXT1
1 | MISB-SWMM-5B-LF (USB_MICRO) | USB-MICRO | USB-UART1
1 | TFC-9P-1.7H (ATFFS150A01BR016) | TFC-9P-1.xH | MICRO_SD1
1 | DW02R | DW02R | BAT1
2 | NA/R0402 | R0402 | R49,R44
1 | NA(49.9R/1%/R0402) | R0402 | R34
1 | NA(10k/R0402) | R0402 | R16
1 | NA(FB0805/600R/2A) | L0805 | L3
1 | NA(10uF/6.3V/20%/X5R/C0603) | C0603 | C21
2 | NS(HN1x10) | HN1x10 | EXT1,EXT2
1 | Opened | SJ_1 | BAT_SENS_E1
2 | Closed | SJ_1 | EN_CT1,EN_CT2

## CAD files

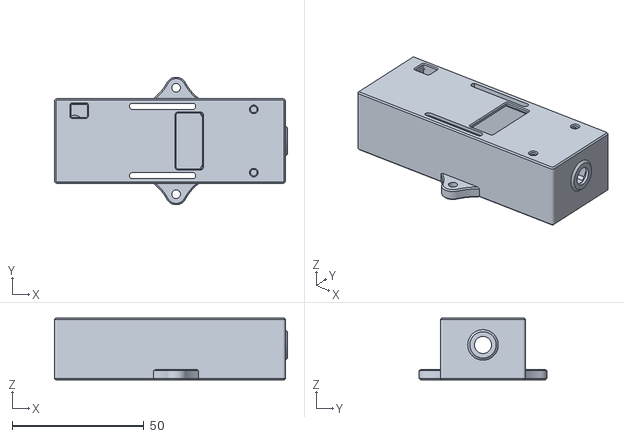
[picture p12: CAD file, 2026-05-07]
HARDWARE/case-3d-files/olimex-esp32-poe-ea-f-v13.stl
88.5 x 48.4 x 23.5

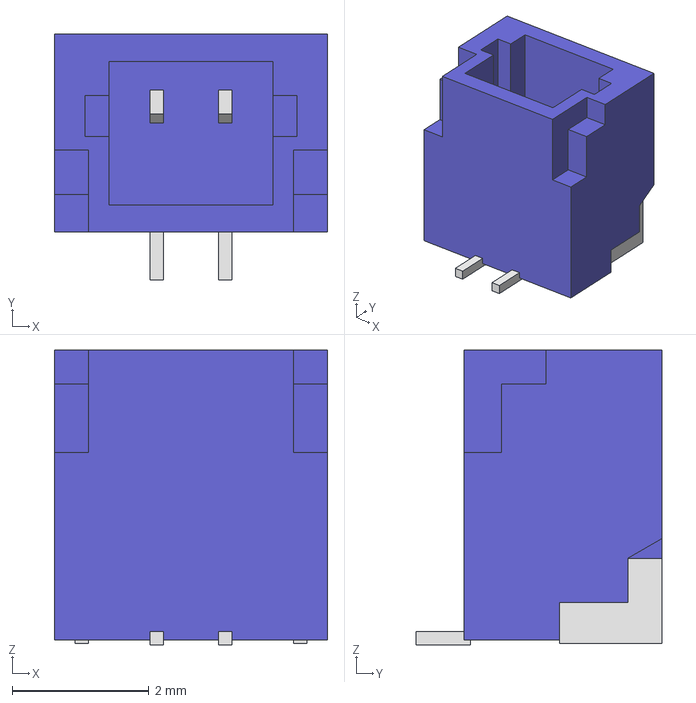
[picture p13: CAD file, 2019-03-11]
HARDWARE/ESP32-PoE-hardware-revision-C1/3d/BM02B-SRSS-TB.step
4.00 x 3.60 x 4.32 mm

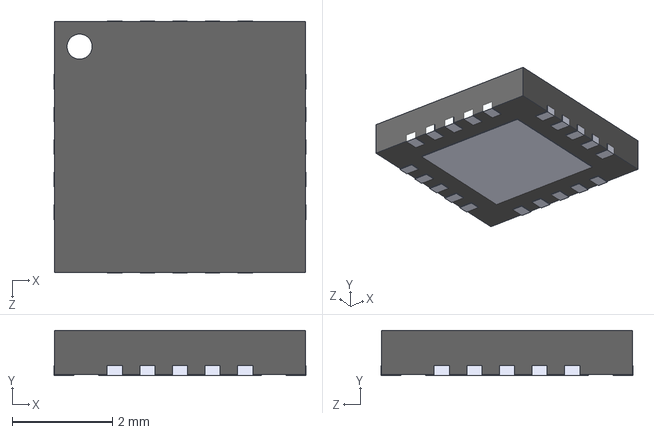
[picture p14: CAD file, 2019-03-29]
HARDWARE/ESP32-PoE-hardware-revision-E/3d/QFN-20_5x5x0_9mm.step
5.02 x 0.9 x 5.02 mm

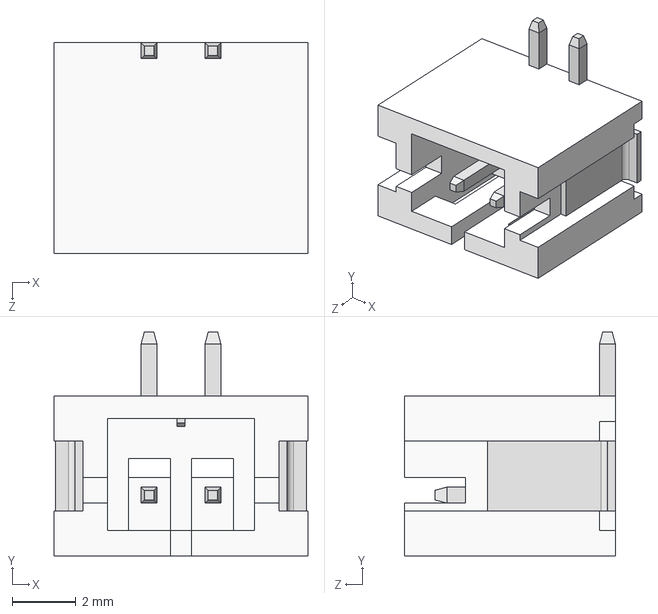
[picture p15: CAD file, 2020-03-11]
HARDWARE/ESP32-PoE-hardware-revision-I/3d/JST_B2B-PH-SM4-TB(DW02R).step
7.95 x 7.00 x 6.60 mm

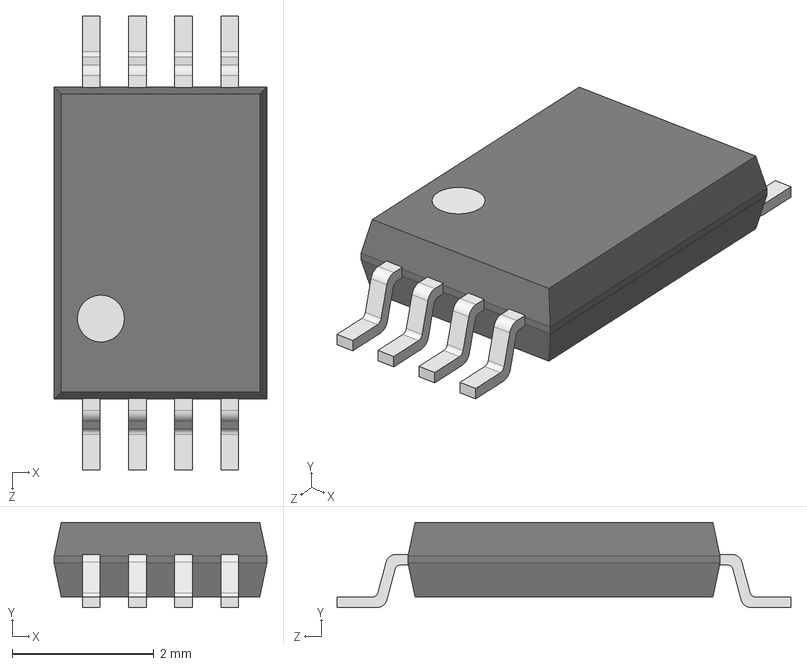
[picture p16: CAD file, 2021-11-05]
HARDWARE/ESP32-PoE-hardware-revision-J/3d/TSSOP-8_P0.65mm.STEP
3.00 x 1.20 x 6.40 mm
_X2_041A043E0440043F04430441_X0_
_X2_041C04350442043A0430_X0_
_X2_041D043E0436043A0430_X0_ x 4

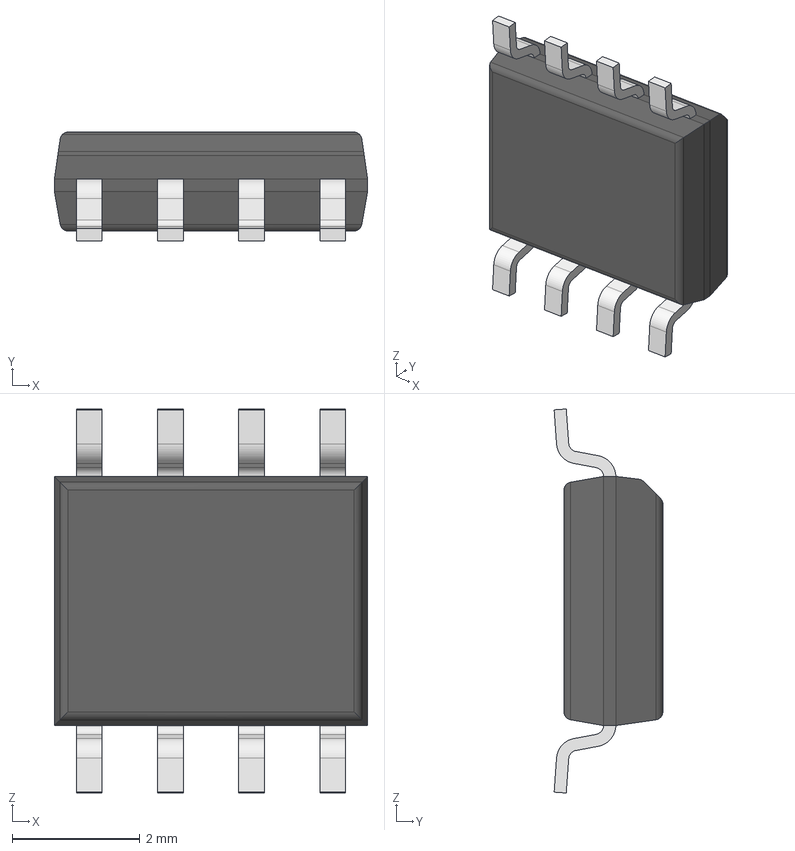
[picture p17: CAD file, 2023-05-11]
HARDWARE/ESP32-PoE-hardware-revision-L1/3d/lm358ad.stp
4.90 x 1.70 x 6.01 mm

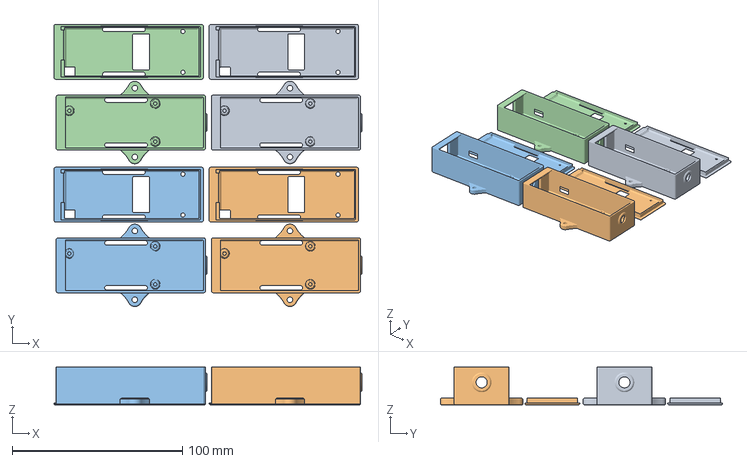
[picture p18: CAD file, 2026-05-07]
HARDWARE/case-3d-files/bambu-lab-pattern-olimex-esp32-poe-ea-f.3mf
180.8 x 165.6 x 22.3 mm
Assembly x 4

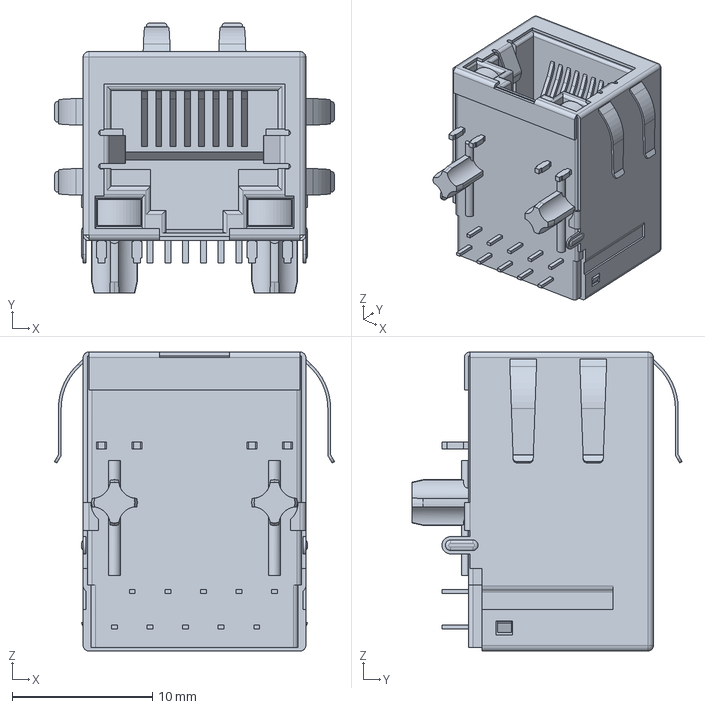
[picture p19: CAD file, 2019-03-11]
HARDWARE/ESP32-PoE-hardware-revision-C1/3d/RJ45_GB_LEDS.stp
20.0 x 19.3 x 21.4 mm

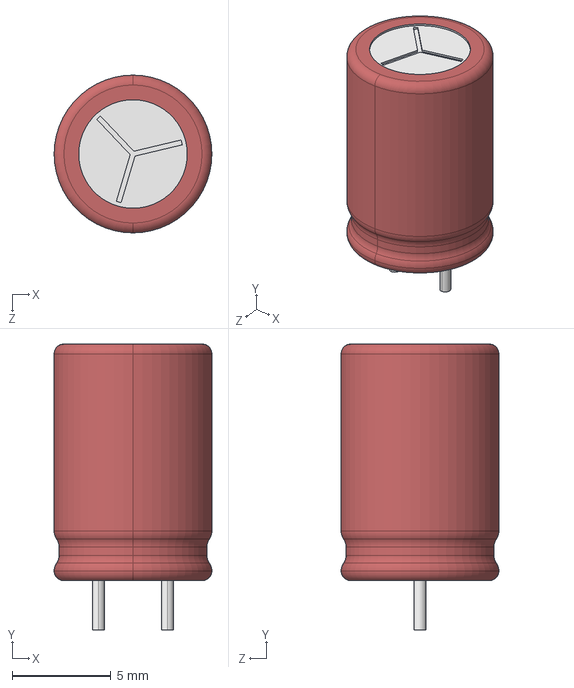
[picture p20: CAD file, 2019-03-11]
HARDWARE/ESP32-PoE-hardware-revision-E/3d/ELECTROLITIC_CAPACITOR_RADIAL_8X12.step
8.00 x 14.5 x 8.00 mm

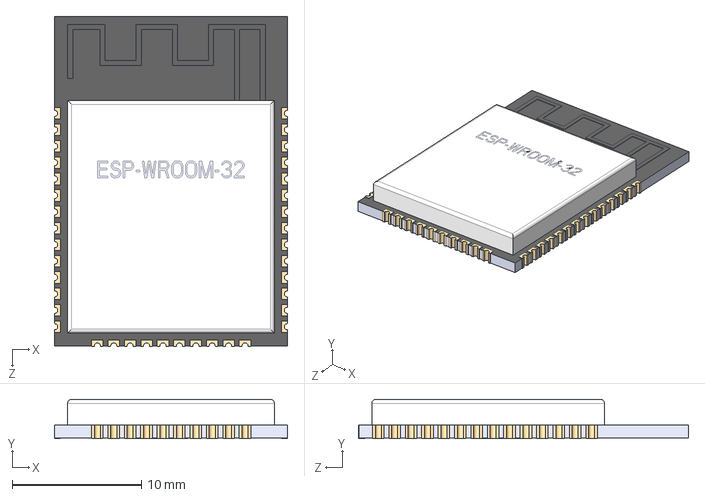
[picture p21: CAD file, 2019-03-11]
HARDWARE/ESP32-PoE-hardware-revision-I/3d/esp-wroom-32.step
18.1 x 3.04 x 25.5 mm

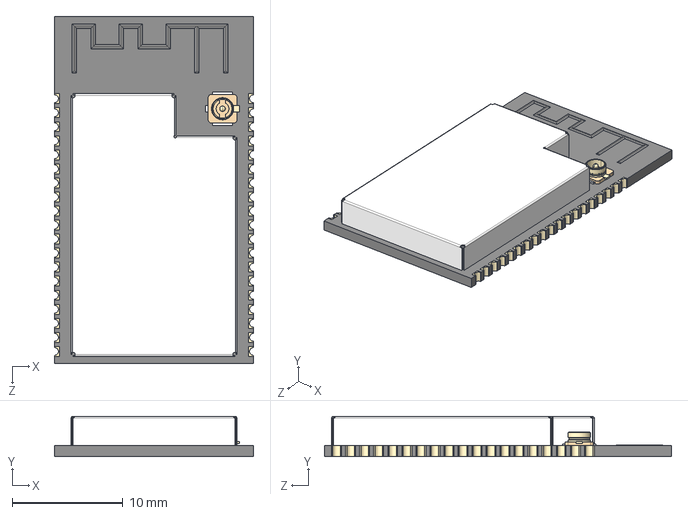
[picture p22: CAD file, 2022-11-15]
HARDWARE/ESP32-PoE-hardware-revision-L1/3d/ESP32-WROVER-I-56544.STEP
18.0 x 3.65 x 31.4 mm

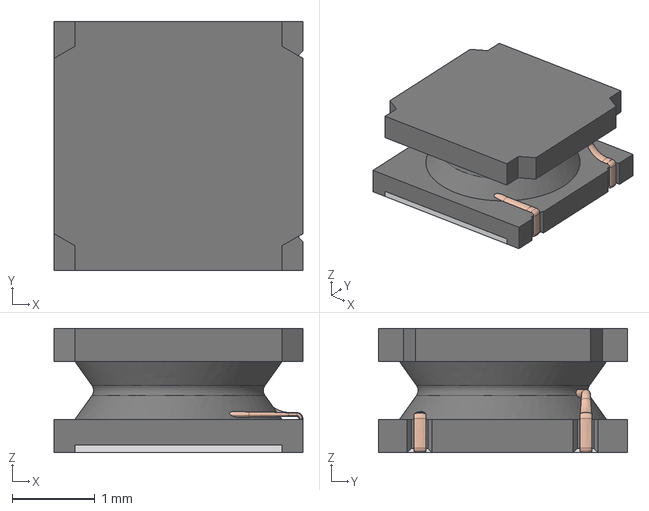
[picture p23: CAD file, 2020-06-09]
HARDWARE/ESP32-PoE-hardware-revision-L1/3d/L-CD32_shielded.step
3.00 x 3.00 x 1.50 mm

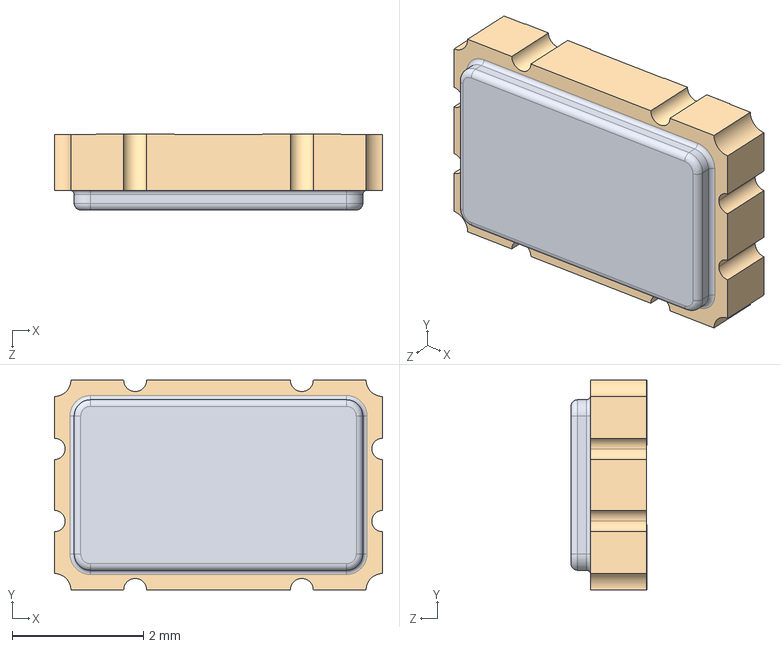
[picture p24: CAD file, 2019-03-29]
HARDWARE/ESP32-PoE-hardware-revision-L1/3d/QSG5032.step
5.00 x 3.20 x 1.16 mm

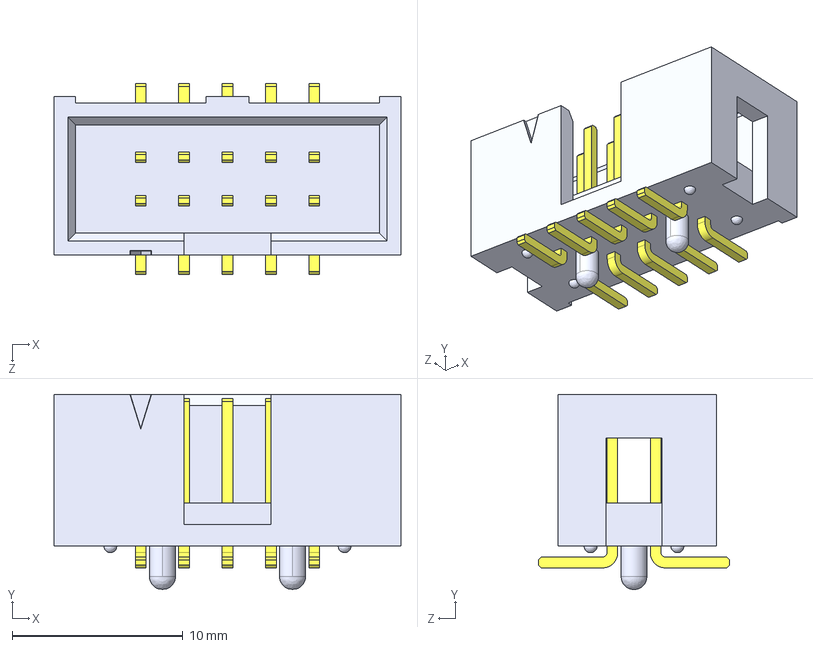
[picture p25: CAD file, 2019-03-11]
HARDWARE/ESP32-PoE-hardware-revision-L1/3d/UEXT-SMD.STEP
20.3 x 11.4 x 11.2 mm
User Library-HTST-105-01-F-DV-A__HTST-105-01-DV-A_header
User Library-HTST-105-01-F-DV-A__HTST-First_Position_Indicator
User Library-HTST-105-01-F-DV-A__T-1S6-05-01-DV_

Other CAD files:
HARDWARE/ESP32-PoE-hardware-revision-L1/3d/Micro_SD_card.step
HARDWARE/ESP32-PoE-hardware-revision-D/3d/CD32_inductor.step

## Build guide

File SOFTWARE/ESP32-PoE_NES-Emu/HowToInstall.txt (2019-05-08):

In order to compile and upload the project you need esp-idf installed. Follow the instructions here: https://docs.espressif.com/projects/esp-idf/en/latest/get-started/ for details.

If you are using Windows you need to install MSYS2 as well.

Change the directory within terminal to the folder of the game. Should be something like this C:\esp\msys32\home\ESP32_PoE_NES_Emu
 - cd "C:\esp\msys32\home\ESP32_PoE_NES_Emu"

If you want to change to port where your ESP32-PoE(-ISO) has connected go to menuconfig
 - make menuconfig

Then navigate to "Serial flasher config"-->"Default serial port"-->write the port on which YOUR BOARD has connected.
If you wish you can change from here also the pins of the SPI or I2C for the display and the controller. Just need to navigate to: "Nofrendo ESP32-specific configuration"
Also from here you are able to select the controller. You choose either Touch screen and/or the MOD-Wii-UEXT-Nunchuck.

NOTE!!! Using both controllers at the same time is possible but this will occasionally cause spikes on the picture.

Leave the menuconfig by selecting "exit" option and SAVE the changes (if needed).

Compile and upload the program to the board.
 - make flash
Wait until compiling and uploading is finished. First time after each change within menuconfig takes very long time so wait a little bit.

Without anything else the screen will be blank (black) and nothing else will happened. In order to have a game running you need to upload your own rom (they are not provided with the project). In order to do so open the file "flashrom.sh" (it is located within the root directory of the project) as text file and after the "--port" option within the quotes write the port your board has connected.

Go back to the terminal and run this file with parameter the name of your rom file
 - ./flashrom "my_own_rom.nes"

If you have done all this the game should be running.

If you have selected touch screen as a controller there are different sections on the screen that acts as buttons.
Top left corner     - Start
Top right corner    - Select
Bottom left corner  - Button A
Bottom right corner - Button B
Top middle          - Up
Bottom middle       - Down
Left middle         - Left
Right middle        - Right

A combo of two buttons is also supported although it is not very precise since the touch screen doesn't support double touch and instead makes some approximations to the middle of the two locations. Thus it may cause unexpected actions due to some close sections. Inexisting combos are Up+Down; Left+Right; ButA+ButB; Start/Select with anything.

Another option for controller is the MOD-Wii-UEXT-Nunchuck.
The Joystick axis are used for the 4 directions.
Button 'C' on the Nunchuck (the circle one) triggers Button 'A' of the NES emulator.
Button 'Z' on the Nunchuck (the square one) triggers Button 'B' of the NES emulator.
Accelerometer data of the Nunchuck is not used.
On board button is used to trigger Start/Select buttons of the NES emulator. Press it quickly for Select or longer for Start.

2019/03/14

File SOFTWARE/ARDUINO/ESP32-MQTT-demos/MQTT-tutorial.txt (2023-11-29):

MQTT examples between Olimex ESP32-POE and Olimex ESP32-POE-ISO and public broker mqttx 

Each folder contains example with own ino file suitable for Arduino IDE. The four examples are:

ESP32-PoE_MQTT_GPIO - scans for the button state with commands via the MQTT app; uses WIFI for connecting to the internet;

ESP32-PoE_MQTT_GPIO_ETH - scans for the button state with commands via the MQTT app; uses Ethernet for connecting to the internet;

ESP32-PoE_MQTT_I2C - uses MOD-RTC module that is connected to the UEXT and I2C, allows to print data from MOD-RTC via the MQTT app using commands (time and date); uses WIFI for connecting;

ESP32-PoE_MQTT_I2C_ETH - uses MOD-RTC module that is connected to the UEXT and I2C, allows to print data from MOD-RTC via the MQTT app using commands (time and date); uses Ethernet for the Internet connection.

- Setting the ESP32-PoE with the code:

1. Pick one of the three Arduino examples. "ESP32-PoE_MQTT_GPIO" is easier to use since it requires no extra hardware. Demo  allows to scan the button state.
2. Edit the WIFI settings inside the example with the one of your WIFI network. Refer to the comments in the code. 
3. Make sure to install the library Sketch --> Include Library --> Manage Libraries... --> search for PubSubClient by Nick O'Leary
4. Build the example and download it to the ESP32-POE or ESP32-POE-ISO via Arduino IDE (remember to install the ESP32 for Arduino package, selected ESP32-POE or ESP32-POE-ISO from the board selector).

- Setting the MQTT application:

1. Download the app from: https://mqttx.app/ and install it
2. Start the application
3. Create a "New Connection"
4. Enter a name and Client ID (they can be whatever)
5. Leave Host and Port with their default values: (mqtt://broker.emqx.io:1883)
6. Connect
7. Create a "New Subscription"
  7.1. At the Topic field you must enter the same topic that is defined in the Arduino sketch (for example: emqx/ESP32-POE_GPIO). This is the topic you will listen to.
  7.2  At the bottom of the screen (just above the text box with the message) you type the same topic. This is the topic you will send to.
8. Click connect and you are ready to send and receive data.

Note: If you need, you can have multiple topics, from which you receive messages within the same connection.

Check the comments in the code for better understanding.

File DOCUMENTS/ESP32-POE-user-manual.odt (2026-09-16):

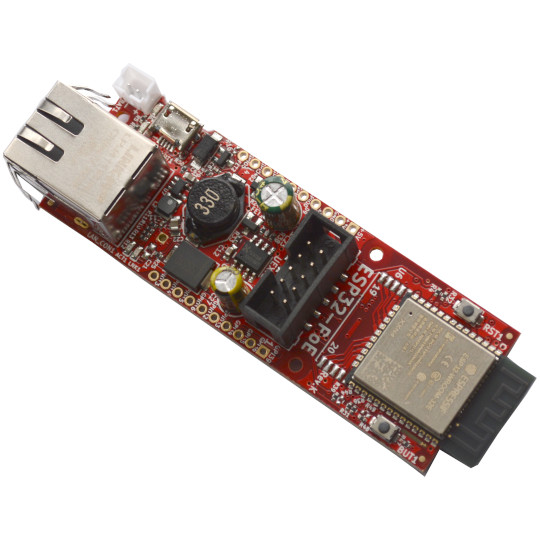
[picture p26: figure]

ES32-POE

ESP32-POE-ISO

User Manual

Document revision 2.7.

September 2026

www.olimex.com

# 1. Introduction to ESP32-POE and ESP32-POE-ISO

ESP32-PoE (https://www.olimex.com/Products/IoT/ESP32/ESP32-POE/open-source-hardware) and ESP32-PoE-ISO (https://www.olimex.com/Products/IoT/ESP32/ESP32-POE-ISO/open-source-hardware) are ESP32-powered Wi-Fi/Bluetooth/Ethernet development boards with Power-Over-Ethernet feature. The boards are the perfect addition to any project that requires extra connectivity.

The PoE is currently handled by TPS2375/6 chip (Si3402-B in older revisions) that is IEEE 802.3af-compliant, including pre-standard (legacy) PoE support.

The PoE powering requires at least 37V DC to operate successfully. The board can takes power from the Ethernet cable and can be expanded with sensors and more. Perfect solution for Internet-of-Things projects.

Both ESP32-POE and ESP32-POE-ISO are mature, popular, and well-known products, with wide software support.

+ Important notice: ESP32-PoE (https://www.olimex.com/Products/IoT/ESP32/ESP32-POE/open-source-hardware) has no galvano isolation of Ethernet's power supply, when you program the board via the micro USB connector the Ethernet cable should be disconnected (if you have power over the Ethernet enabled)! Consider using Olimex USB-ISO (https://www.olimex.com/Products/USB-Modules/USB-ISO/) to protect your computer and board from accidental short circuits. Also consider using Olimex ESP32-PoE-ISO (https://www.olimex.com/Products/IoT/ESP32/ESP32-POE-ISO/open-source-hardware) board instead since it is insulated.

## 1.1. ESP32-POE features

Features depend on the exact variant of the board chosen, the common features are:

- ESP32-WROOM module WiFi + Bluetooth ® + Bluetooth LE module from Espressif Inc (ESP32-WROOM-32E/IE-N4 or ESP32-WROVER-E/IE or ESP32-WROOM-32E/UE-N16 depending on variant)
- ESP32-WROOM-32E/UE-N4 have 4MB flash and 520 KB SRAM
- ESP32-WROOM-32E/UE-N16 has 16MB flash and 520 KB SRAM
- ESP32-WROVER-E/IE have 4MB flash 520KB SRAM and 8MB PSRAM
- CE-RED and LVD certification
- Original design by OLIMEX Ltd
- Low power design – 200uA consumption in deep sleep
- Power Over Ethernet negotiation circuit, 802.3af-compliant, with minimum operating voltage of 37VDC
- Li-Po battery charger and connector
- Battery level monitor pin on ADC
- External power supply detection pin on ADC
- UEXT connector (https://www.olimex.com/Products/Modules/UEXT/)
- User button
- Reset button
- Micro USB with programmer for ESP32 programming
- MicroSD card working in 1-bit mode
- Two extension connectors 0.1" step spaced at 1"
- PCB dimensions: (80 x 28)mm ~ (3.15 x 1.10)"

These following features are available in some of the board variants:

- External antenna variant (-EA)
- High reliable industrial grade (-40+85C) variant available (-IND)
- Bigger flash variant available (-16MB)
- PSRAM version available (-WROVER)

## 1.2. ESP32-POE-ISO features

- ESP32-WROOM-32 (https://documentation.espressif.com/esp32-wroom-32e_esp32-wroom-32ue_datasheet_en.pdf) WiFi + Bluetooth ® + Bluetooth LE module by Espressif Inc (ESP32-WROOM-32E/IE-N4 or ESP32-WROVER-E/IE or ESP32-WROOM-32E/UE-N16 depending on variant)
- ESP32-WROOM-32E/IE-N4 and ESP32-WROOM-32UE have 4MB flash and 520 KB SRAM
- ESP32-WROOM-32E/UE-N16 has 16MB flash and 520 KB SRAM
- ESP32-WROVER-E/IE (https://documentation.espressif.com/esp32-wrover-e_esp32-wrover-ie_datasheet_en.pdf) have 4MB Flash 520KB SRAM and 8MB PSRAM
- Power Over Ethernet negotiation circuit 802.3 compliant, with minimum operating voltage of 35VDC
- High reliable industrial grade -40+85C available (-IND)
- CE-RED and LVD certification
- Original design by OLIMEX Ltd
- Low power design – 200uA consumption in deep sleep
- Ethernet 100Mb interface with IEEE 802.3 PoE support
- 3000VDC galvanic insulation between the PoE Ethernet part and board's power supply circuit Micro USB connector for ESP32 programming
- MicroSD card working in 1-bit mode
- LiPo battery charger with LiPo battery connector
- Battery level monitor pin on ADC
- External power supply detection pin on ADC
- UEXT connector (https://www.olimex.com/Products/Modules/UEXT/)
- User button
- Reset button
- Two extension connectors, 0.1" step spaced at 1"
- PCB dimensions: (98x28)mm ~ (3.8x1)"

The following features are available in some of the board variants:

- External antenna variant (-EA)
- High reliable industrial grade (-40+85C) variant available (-IND)
- Bigger flash variant available (-16MB)
- PSRAM version available (-WROVER)

## 1.3. PoE standard

ESP32-POE and ESP32-POE-ISO are compliant with the IEEE 802.3af PoE standard with network devices that provide up to 15.4 W of DC power (minimum 37V DC and 350 mA). The PoE boards have LAN connectors suitable for both modes of PoE operation (mode A and mode B) – the LAN connector is visible in the schematic.

## 1.4. The difference between ESP32-POE and ESP32-POE-ISO

ESP32-POE is not galvanically isolated which means that it’s not safe to connect it to other devices which use non isolated power supply while it is powered. It should have only one power supply and one ground attached to it at a time.

+ This means YOU SHOULD NOT CONNECT ESP32-POE to computer’s USB port while it is powered by Ethernet POE!!! If you connect USB while ESP32-POE is powered by Ethernet you will damage the board or your computer or both. This will also void the warranty!

ESP32-POE-ISO, on the other hand comes with 3000VDC galvanic insulation between the Ethernet POE part and ESP32 power supply, so there is no problem to connect to USB and program or debug while the board is also powered from a PoE source.

ESP32-POE can provide more power to devices powered from it – up to 4W. ESP32-POE-ISO can provide only up to 2W for additionally connected devices (due to the 2W DC-DC 5V-5V insulation converter which prevents electrical influence between different sources of power)! If you need more power for your circuits, consider ESP32-POE2 (https://www.olimex.com/Products/IoT/ESP32/ESP32-POE2/open-source-hardware) board.

## 1.5. The differences between different variants of ESP32-POE and ESP32-POE-ISO

ESP32-POE (https://www.olimex.com/Products/IoT/ESP32/ESP32-POE/open-source-hardware) and ESP32-POE-ISO (https://www.olimex.com/Products/IoT/ESP32/ESP32-POE-ISO/open-source-hardware) are the base versions with ESP32-WROOM-32E-N4 module with 4MB flash memory and nothing extra.

ESP32-POE-16MB (https://www.olimex.com/Products/IoT/ESP32/ESP32-POE-16MB/open-source-hardware), ESP32-POE-EA-16MB (https://www.olimex.com/Products/IoT/ESP32/ESP32-POE-EA-16MB/open-source-hardware), ESP32-POE-ISO-16MB (https://www.olimex.com/Products/IoT/ESP32/ESP32-POE-ISO-16MB/open-source-hardware) and ESP32-POE-ISO-EA-16MB (https://www.olimex.com/Products/IoT/ESP32/ESP32-POE-ISO-EA-16MB/open-source-hardware) feature ESP32-WROOM with 16MB flash memory (as opposed to 4MB).

ESP32-POE-EA (https://www.olimex.com/Products/IoT/ESP32/ESP32-POE-EA/open-source-hardware) and ESP32-POE-ISO-EA (https://www.olimex.com/Products/IoT/ESP32/ESP32-POE-ISO-EA/open-source-hardware) have ESP32-WROOM-32UE module with U.FL connector and external antenna attached.

ESP32-POE-IND (https://www.olimex.com/Products/IoT/ESP32/ESP32-POE-IND/open-source-hardware) and ESP32-POE-EA-IND (https://www.olimex.com/Products/IoT/ESP32/ESP32-POE-EA-IND/open-source-hardware) and ESP32-POE-ISO-IND (https://www.olimex.com/Products/IoT/ESP32/ESP32-POE-ISO-IND) and ESP32-POE-ISO-EA-IND (https://www.olimex.com/Products/IoT/ESP32/ESP32-POE-ISO-EA-IND) use industrial grade components suitable for -40+85C operating temperature.

ESP32-POE-WROVER (https://www.olimex.com/Products/IoT/ESP32/ESP32-POE-WROVER/open-source-hardware) and ESP32-POE-ISO-WROVER (https://www.olimex.com/Products/IoT/ESP32/ESP32-POE-ISO-WROVER) comes with ESP32-WROVER-E chip with 4MB flash and 8MB PSRAM, while ESP32-POE-WROVER-EA (https://www.olimex.com/Products/IoT/ESP32/ESP32-POE-WROVER-EA/open-source-hardware) and ESP32-POE-ISO-WROVER-EA (https://www.olimex.com/Products/IoT/ESP32/ESP32-POE-ISO-WROVER-EA) have a WROVER module with extra U.FL connector and external antenna attached.

Features table:

Name/Features | ESP32 module | Flash size, MB | External antenna | Industrial range | PSRAM, MB | Isolated POE
ESP32-POE | ESP32-WROOM-32E-N4 | 4 | - | - | - | -
ESP32-POE-16MB | ESP32-WROOM-32E-N16 | 16 | - | - | - | -
ESP32-POE-EA | ESP32-WROOM-32UE | 4 | Y | - | - | -
ESP32-POE-EA-16MB | ESP32-WROOM-32UE-N16 | 16 | Y | - | - | -
ESP32-POE-EA-IND | ESP32-WROOM-32UE | 4 | Y | Y | - | -
ESP32-POE-IND | ESP32-WROOM-32E-N4 | 4 | - | Y | - | -
ESP32-POE-WROVER | ESP32-WROVER-E | 4 | - | - | 8 | -
ESP32-POE-WROVER-EA | ESP32-WROVER-IE | 4 | Y | - | 8 | -
ESP32-POE-ISO | ESP32-WROOM-32E-N4 | 4 | - | - | - | Y
ESP32-POE-ISO-16MB | ESP32-WROOM-32E-N16 | 16 | - | - | - | Y
ESP32-POE-ISO-16MB-IND | ESP32-WROOM-32E-N16 | 16 | - | Y | - | Y
ESP32-POE-ISO-EA | ESP32-WROOM-32UE | 4 | Y | - | - | Y
ESP32-POE-ISO-EA-16MB | ESP32-WROOM-32UE-N16 | 16 | Y | - | - | Y
ESP32-POE-ISO-EA-IND | ESP32-WROOM-32UE | 4 | Y | Y | - | Y
ESP32-POE-ISO-IND | ESP32-WROOM-32E-N4 | 4 | - | Y | - | Y
ESP32-POE-ISO-WROVER | ESP32-WROVER-E | 4 | - | - | 8 | Y
ESP32-POE-ISO-WROVER-EA | ESP32-WROVER-IE | 4 | Y | - | 8 | Y

+ WROVER module uses two extra ESP32 pins for the PSRAM and these pins can’t be used for other purposes. This is important especially if you switch from regular version to WROVER version. This is easily noticeable in the middle of the schematic. GPIO16 and GPIO17 are used by the PSRAM, so GPIO17 that was used for Ethernet clock was replaced by GPIO0 and GPIO16 was replaced by GPIO33. You should do the requires software changes in your code if you switch from ESP32-POE to WROVER version.

## 1.6. Order codes for ESP32-POE and accessories

ESP32-POE (https://www.olimex.com/Products/IoT/ESP32/ESP32-POE/open-source-hardware) commercial grade 0-70C board with internal antenna

ESP32-POE-16MB (https://www.olimex.com/Products/IoT/ESP32/ESP32-POE-16MB/open-source-hardware) commercial grade 0-70C board with internal antenna and 16MB flash

ESP32-POE-EA (https://www.olimex.com/Products/IoT/ESP32/ESP32-POE-EA/open-source-hardware) commercial grade 0-70C board with external antenna

ESP32-POE-EA-16MB (https://www.olimex.com/Products/IoT/ESP32/ESP32-POE-EA-16MB/open-source-hardware) commercial grade 0-70C board with external antenna and 16MB flash

ESP32-POE-IND (https://www.olimex.com/Products/IoT/ESP32/ESP32-POE-IND/open-source-hardware) industrial grade -40+85C board with internal antenna

ESP32-POE-EA-IND (https://www.olimex.com/Products/IoT/ESP32/ESP32-POE-EA-IND/open-source-hardware) industrial grade -40+85C board with external antenna

ESP32-POE-WROVER (https://www.olimex.com/Products/IoT/ESP32/ESP32-POE-WROVER/open-source-hardware) commercial grade 0-70C board with 8MB PSRAM and internal antenna

ESP32-POE-WROVER-EA (https://www.olimex.com/Products/IoT/ESP32/ESP32-POE-WROVER-EA/open-source-hardware) commercial grade 0-70C board with 8MB PSRAM and external antenna

(https://www.olimex.com/Products/Power/Lipo-battery/BATTERY-LIPO1400mAh/)

BATTERY-LIPO1400mAh (https://www.olimex.com/Products/Power/Lipo-battery/BATTERY-LIPO1400mAh/) Lipo battery 3.7V 1400mAh – note these batteries can be shipped only by ground so we can deliver only to EU destinations.

UEXT modules (https://www.olimex.com/Products/Modules/) Different sensors, relays, LCDs, RTC, GSM, GPS, accessories which can be connected to UEXT connector

## 1.7. Order codes for ESP32-POE-ISO and accessories

ESP32-POE-ISO (https://www.olimex.com/Products/IoT/ESP32/ESP32-POE-ISO/open-source-hardware) commercial grade 0-70C board with internal antenna

ESP32-POE-ISO-16MB (https://www.olimex.com/Products/IoT/ESP32/ESP32-POE-ISO-16MB/open-source-hardware) commercial grade 0-70C board with internal antenna and 16MB flash

ESP32-POE-ISO-16MB-IND (https://www.olimex.com/Products/IoT/ESP32/ESP32-POE-ISO-16MB-IND/open-source-hardware) industrial grade -40+85C board with internal antenna and 16MB flash

ESP32-POE-ISO-EA (https://www.olimex.com/Products/IoT/ESP32/ESP32-POE-ISO-EA/open-source-hardware) commercial grade 0-70C board with external antenna

ESP32-POE-ISO-EA-16MB (https://www.olimex.com/Products/IoT/ESP32/ESP32-POE-ISO-EA-16MB/open-source-hardware) commercial grade 0-70C board with external antenna and 16MB flash

ESP32-POE-ISO-IND (https://www.olimex.com/Products/IoT/ESP32/ESP32-POE-ISO-IND/open-source-hardware) industrial grade -40+85C board with internal antenna

ESP32-POE-ISO-EA-IND (https://www.olimex.com/Products/IoT/ESP32/ESP32-POE-ISO-EA-IND/open-source-hardware) industrial grade -40+85C board with external antenna

ESP32-POE-ISO-WROVER (https://www.olimex.com/Products/IoT/ESP32/ESP32-POE-ISO-WROVER/open-source-hardware) commercial grade 0-70C board with 8MB PSRAM, internal antenna

ESP32-POE-ISO-WROVER-EA (https://www.olimex.com/Products/IoT/ESP32/ESP32-POE-ISO-WROVER-EA/open-source-hardware) commercial grade 0-70C board with 8MB PSRAM, external antenna

(https://www.olimex.com/Products/Power/Lipo-battery/BATTERY-LIPO1400mAh/)

BATTERY-LIPO1400mAh (https://www.olimex.com/Products/Power/Lipo-battery/BATTERY-LIPO1400mAh/) Lipo battery 3.7V 1400mAh – note these batteries can be shipped only by ground so we can deliver only to EU destinations.

UEXT modules (https://www.olimex.com/Products/Modules/) different sensors, relays, LCDs, RTC, GSM, GPS, accessories which can be connected to UEXT connector

# 2. HARDWARE

## 2.1. ESP32-POE layout

Ethernet connector

User button

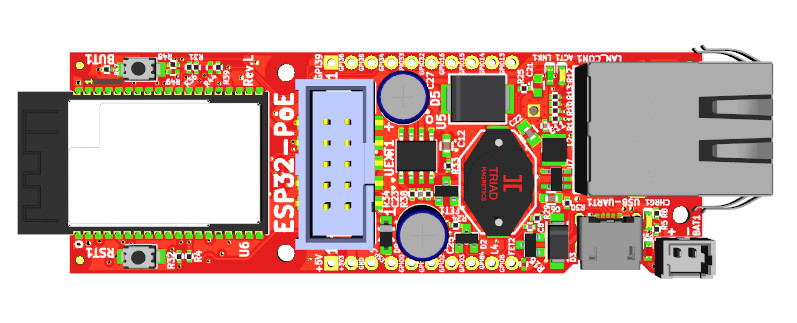
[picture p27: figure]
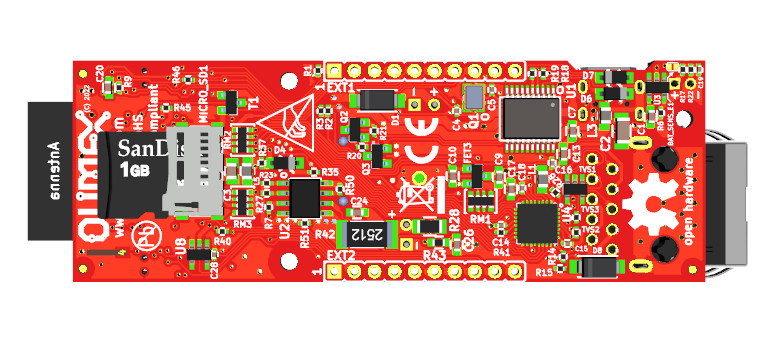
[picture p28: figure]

Micro SD card connector

mout hole

LiPo battery connector

USB connector

GPIOs

GPIOs

mout hole

reset button

ESP32 module

mout hole

## 2.2. ESP32-POE GPIOs

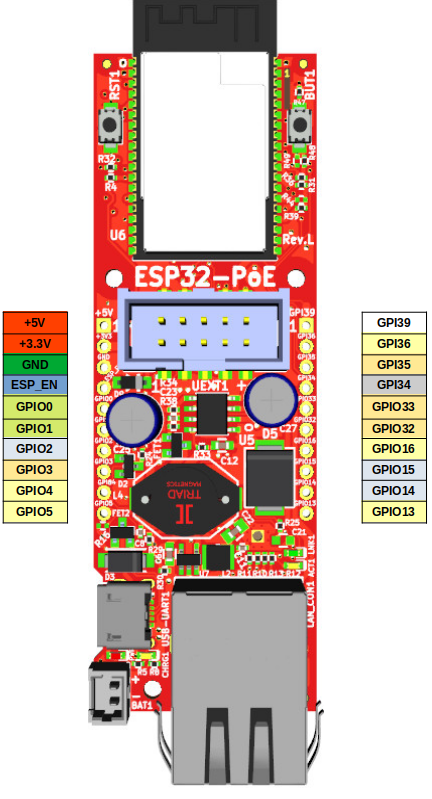
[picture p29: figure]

POWER SUPPLY pads:

+5V 1. Can be input and output; if you use it as input make sure no other 5V sources are applied to the board (having Li-Po battery is OK);

2. When the board is attached to USB or to Ethernet PoE this line can be used ONLY as output to power attached peripherals;

3. If you want to use as input i.e. to feed power from external 5V to this line make sure that board is not connected to USB!

4. When you use the 5V line as output to power external devices it can provide up to 0.8A @ 5V (i.e. 4W) maximum. This includes the 3.3V power output. The combined power draw of +5V output and +3.3V output must not exceed 4W!

+3.3V output which can source up to 0.5A @ 3.3V i.e. (1.65W) Make sure the combined power sourced from +3.3V and +5V does not exceed 4W!

GND Ground, the board has common ground.

GPIO pads:

ESP_EN resets the ESP32 module

GPIO0, GPIO2 are boot mode bootstrap pins make sure they are properly configured during power up

GPIO1, GPIO3 are used for USB programming, they can be freed up if you won’t further program the board via USB

GPIO2, GPIO14, GPIO15 are used for the SD-card, if no SD card is preset they are free to use

GPIO2, GPIO4, GPIO5, GPIO13, GPIO14, GPIO15, GPIO16, GPIO36 are shared on both UEXT and EXT headers so if you use them on the one connector do not use them at the other

GPI39 is connected to measure external power supply voltage

GPI34 is connected to user button and has 10K pullup

GPI35 is free to use by default but may be connected to measure the LiPo battery voltage if you close BAT_SENS_E1 jumper

+ESP32-POE-WROVER and ESP32-POE-WROVER-EA have no GPIO16 or GPIO17 led out, since they are used for the PSRAM. These are replaced by GPIO33 and GPIO0. GPIO17 being replaced by GPIO0 is crucial for the Ethernet connectivity, since GPIO17/GPIO0 is Ethernet clock out. Make sure to use new assignments in your software if your board variant comes with the WROVER chip.

The ESP32 chip has very advanced multiplexing and you can define any free GPIO pin for I2C, UART, SPI operation as long as you are within the maximum supported (some penalties to SPI's maximum frequency apply, when not using the dedicated pins). Notice that some ESP32 pins can only be inputs. Defining pins for another function is purely software effort.

For further analysis of pins it is highly recommended to check on the schematic and also check the ESP32-WROOM/ESP32-WROVER documentation.

## 2.3. ESP32-POE-ISO GPIOs

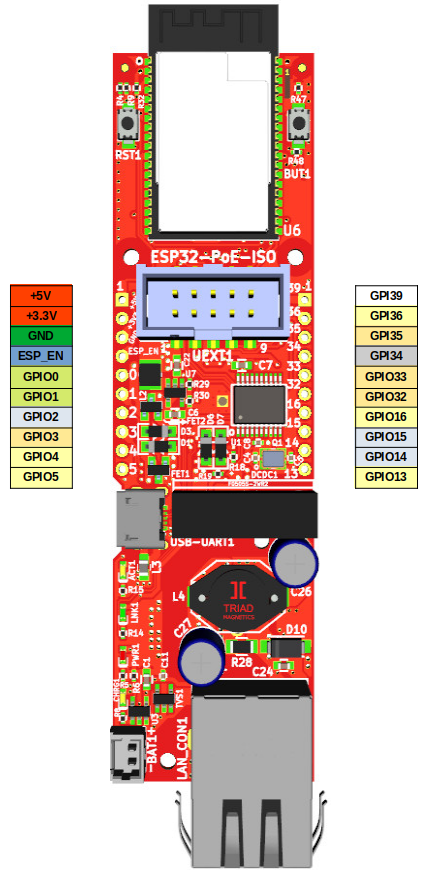
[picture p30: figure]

POWER SUPPLY pads:

+5V 1. Can be used as either input and output. f you use it as input make sure no other 5V source is applied to the board (Li-Po battery is OK);

2. When the board is connected to USB or to Ethernet PoE this line can be used as output and power supplement electronic

3. if you want to use as input i.e. to feed power from external 5V to this line make sure board is not connected to USB!

4. when you use as output i.e. you feed external electronics from it up to 0.4A @ 5V (i.e. 2W) can be sourced maximum. This includes the 3.3V power output. The combined power must not exceed 2W.

+3.3V output which can source up to 0.6A @ 3.3V i.e. (2W) - make sure the combined power sourced from +3.3V and +5V does not exceed 2W; notice the board itself requires some wattage to operate

GPIO pads:

ESP_EN resets ESP32 module

GPIO0, GPIO1 are used only during programming, after that are free to use

GPIO2, GPIO14, GPIO15 are used for the SD-card, if no SD card they are free to use

GPIO2, GPIO4, GPIO5, GPIO13, GPIO14, GPIO15, GPIO16, GPIO36 are shared on both UEXT and EXT headers so if you use them on the one connector do not use on the other

GPI39 is connected to measure external power supply voltage;

GPI35 is used for battery measurement of the LiPo battery;

GPI34 is connected to used button and has a 10K pullup resistor.

+ESP32-POE-ISO-WROVER and ESP32-POE-ISO-WROVER-EA have no GPIO16 and GPIO17 led out, since they are used for the PSRAM. GPIO16 is replaced by GPIO33. GPIO17 is replaced by GPIO0, this is important for the Ethernet connectivity, since GPIO17/GPIO0 is Ethernet clock out. Make sure to use new assignments if your board variant comes with the WROVER chip.

The ESP32 chip has very advanced multiplexing and you can define any free GPIO pin for I2C, UART, SPI operation as long as you are within the maximum supported (some penalties to SPI's maximum freqncy apply, when not using the dedicated pins). Notice that some ESP32 pins can only be inputs. Defining pins for another function is purely software effort.

For further analysis of pins it is highly recommended to check on the schematic and also check the ESP32-WROOM/ESP32-WROVER documentation.

## 2.4. ESP32-POE(-ISO) schematics

This is an open hardware design made with KiCAD. All design files and exports can be found at our GitHub.

ESP32-POE schematics are available at GitHub (https://github.com/OLIMEX/ESP32-POE/tree/master/HARDWARE)

ESP32-POE board revision changes are at GitHub (https://github.com/OLIMEX/ESP32-POE/blob/master/HARDWARE/Revision-changes.txt)

ESP32-POE-ISO schematics are available at GitHub (https://github.com/OLIMEX/ESP32-POE-ISO/tree/master/HARDWARE)

ESP32-POE-ISO board revision changes are at GitHub (https://github.com/OLIMEX/ESP32-POE-ISO/blob/master/HARDWARE/Hardware-changes-log.txt)

## 2.5. ESP32-POE(-ISO) power supply

ESP32-POE(-ISO) can be powered by 4 sources:

- Ethernet PoE
- USB-micro connector
- Li-Po battery
- EXT1 pin 1 (+5V) but note that this signal is connected to USB 5V signal so when you power via this EXT1 pin you should not connect the board to the USB!

- The standard power consumption of ESP32-POE(-ISO) is between 50mA and 200mA depending on the operation mode. When using power-down modes and Li-Po battery power it can go down to micro amperes.

- Li-Po battery gets automatically charged with about 100mA when external power supply is present.

When the LiPo battery is attached and external power supply is missing internal DCDC step-up converter and switching circuit automatically powers ESP32-POE from the battery. 1400mAh battery will provide about 8 hours of stand alone operation.

+The LiPo battery connector is JST 2.0 mm connector and with Olimex’s battery polarity. If you use batteries from other manufacturers please make PLUS and MINUS are connected properly as you may damage the board!

+ Is it safe to have USB and PoE connected and enabled at the same time? If you are using ESP32-POE or any of its variants – no, it is not safe and should be avoided at all costs. If you are using ESP32-POE-ISO or any of its variants – yes, it is safe to have them both attached and enabled.

### 2.5.1. External power sense feature

This allows to detect when the board has external powering. This is helpful if you want to switch between different power modes depending on whether the board is powered from a battery or external power source. By default the external power sense is enabled and it is available on GPI39!

Refer to this Arduino IDE example to see how you can check for the presence external power and check the battery measurement:

https://github.com/OLIMEX/ESP32-POE/blob/master/SOFTWARE/ARDUINO/ESP32_PoE_PowerReading/ESP32_PoE_PowerReading.ino

### 2.5.2. Battery measurement feature

This allows to measure the Li-Po battery’s voltage. This is helpful so you can evaluate when the battery is going to drain out so you can power off the board safely or switch to more conservative power method.

In ESP32-POE and its variants the battery measurement features is disabled by default but you can enabled it by soldering together the pads of STM jumper BAT_SENS_E1 jumper, after closing it – it will be routed to GPI35!

In ESP32-POE-ISO and its variants – the battery measurement is enabled and it is available on GPI35!

Refer to this Arduino IDE example to see how you can check for external power and check the battery measurement:

https://github.com/OLIMEX/ESP32-POE/blob/master/SOFTWARE/ARDUINO/ESP32_PoE_PowerReading/ESP32_PoE_PowerReading.ino

## 2.6. UEXT connector

UEXT connector stands for Universal EXTension connector and typically contains +3.3V, GND, UART, I2C, SPI signals.

UEXT is 0.1” 2.54mm step boxed plastic connector. All signals are with 3.3V levels.

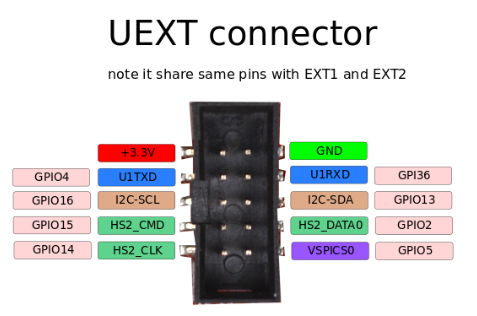
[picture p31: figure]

The 3.3V pin is output only!

In board variants with WROVER module GPIO16 is replaced by GPIO33 (since WROVER uses GPIO16 and GPIO17 for the PSRAM)!

Notice that the ESP32 GPIOs have to be defined in the code for their respective functions, e.g. define GPIO4 and GPIO36 for UART function before using them; define GPIO16 and GPIO13 for I2C, define GPIO15, GPIO2, GPIO14, GPIO5 for SPI.

GPIO15, GPIO2, GPIO14 are multiplexed with the SD card and if you have SPI device attached to them you’d have to use the chip select to switch between the card and the device connected to the UEXT.

Olimex has developed number of extension MODULES (https://www.olimex.com/Products/Modules/) compatible with this connector. There are temperature, humidity, pressure, magnetic field, light sensors. Modules with LCDs, LED matrix, relays, Bluetooth, Zigbee, Wi-Fi, GSM, GPS, RFID, RTC, EKG, sensors, and more.

## 2.7. ESP32-POE(-ISO) Ethernet connector

ESP32-POE and ESP32-POE-ISO have ETH8720 chip. All board variants use RJ45 LAN connector that is compatible with both PoE mode A and PoE mode B for PoE power delivery. Either mode is fine for the board.

How to define the Ethernet in the software?

It Arduino IDE this is done in the board configuration and you don’t have to specify the pins. Install the espresiff ESP32 package for Arduino IDE and make sure ESP32-POE or ESP32-POE-ISO is selected in the board selector and you are good to go. You can run the default Ethernet demo for LAN8720 without changes, go to File → Examples → Ethernet → ETH_LAN8720 verify and upload and open the serial terminal to see the results.

In other tools you might need to manually configure the pins. The pinout is as follows:

MDC – 23

MDIO – 18

PHY reset – 12

PHY RMII clock – 17 or 0 (17 in boards with WROOM module, 0 in boards with WROVER module)

If you use ESP-IDF v5.5 or newer just load the default Ethernet demo that comes with it and configure manually via menuconfig and edit the settings. Run:

idf.py menuconfig

Then navigate under "Example Ethernet Configuration" and make sure internal EMAC is selected and Ethernet PHY device is LAN87xx and set:

MDC – 23

MDIO – 18

PHY Reset – 12

PHY address – 0

It should look like this:

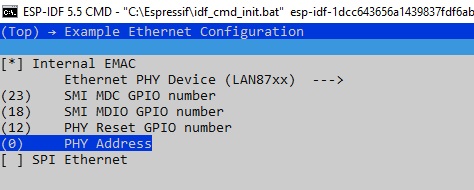
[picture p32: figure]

Then you also need to edit the settings for the Ethernet clock source – go back to Component config -> Ethernet -> Support ESP32 internal EMAC controller and remove the tick from Output RMII clock from GPIO0 (Experimental) and put RMII clock GPIO number to 17. Notice that if you use WROVER variant of the board put the tick om Output RMII clock from GPIO0 (Experimental).

For a regular board with WROOM module it should look like this:

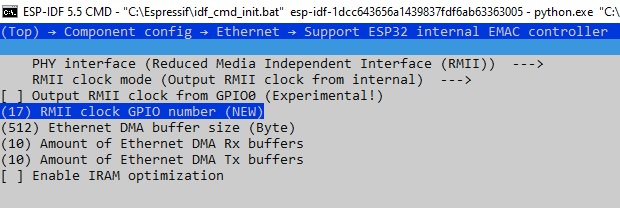
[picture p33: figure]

Notice the ESP32-POE and ESP32-POE-ISO boards use LAN8720A Ethernet chip. It is very important the LAN8720A to stay in reset (via GPIO12) until the ESP32 has generated the PHY clock (GPIO17/GPIO0, depending whether WROOM or WROVER variant). If there is no PHY clock generated when LAN8720A gets powered, the LAN8720A might hang! For more info refer to LAN8720A’s datasheet.

Usually the libraries take care of this by keeping the board in reset via GPIO12, but if it doesn’t you can do in your code. For example, in Arduino IDE you can first enable pin 17 (or pin 0 in WROVER module) to output and then hold pin 12 in reset for some moments BEFORE the Ethernet initialization like this:

pinMode(17, OUTPUT);

digitalWrite(17, HIGH); // enable external clock

// PHY reset sequence

pinMode(12, OUTPUT);

digitalWrite(12, LOW); // Hold PHY in reset

delay(300); // Keep it low for 300ms

digitalWrite(12, HIGH); // Release PHY reset

delay(50); // Wait 50ms for PHY clock to stabilize

// Start Ethernet: PHY reset = 12, PHY clock = 17

ETH.begin(ETH_PHY_LAN8720, 0, 23, 18, 12, ETH_CLOCK_GPIO17_OUT);

## 2.8. LED description

Board comes with 4 on-board status LEDs. These are not connected to the ESP32 directly and can’t be used as general purpose LEDs.

LED CHRG1 shows whether the Li-Po battery attached to the board is currently charging. When it is off it means that either there is no battery attached or it is already fully charged. Refer to "BL4054/BL4054B" datasheet and check for "CHRGb" port for more detailed information.

LED PWR1 is turned on when there is 5V DC applied to the board. It only actives from external power supply, USB power supply, or PoE powering. It won't turn on when board is powered from a Li-Po battery at BAT1 connector (to conserve energy required to power that LED).

LEDs LNK1 and ACT1 are Ethernet link and activity LEDs. LNK1 is turned on when 100 Mbps speed is detected, and turns off at 10Mbps or less. ACT1 blinks when activity is detected. For more information about their behavior, refer to the manual of "LAN8710A/LAN8710AI" and check the table describing "REGOFF" port (ACT1 is connected to it) and "nINTSEL" port (LNK1 is connected to it).

During USB power up the CHRG1 and PWR1 LEDs should light up.

Important! In order to reduce current consumption the LEDs would remain off when the board is powered from Li-Po battery! Do not count on the LEDs when the board is powered only from a Li-Po battery!

# 3. SOFTWARE

ESP32-POE and ESP32-POE-ISO are very popular boards and supported by a lot of software tools, among them (there are ready-to-use configs for ESP32-POE and ESP32-POE-ISO):

- Espressif ESP-IDF (https://docs.espressif.com/projects/esp-idf/en/latest/esp32/get-started/)
- Arduino IDE (https://github.com/espressif/arduino-esp32)
- MicroPython (https://micropython.org/download/OLIMEX_ESP32_POE/)
- ESPhome (https://github.com/esphome/bluetooth-proxies/blob/main/olimex-esp32-poe-iso.yaml)
- PlatformIO (https://docs.platformio.org/en/latest/boards/espressif32/esp32-poe.html)

## 3.1. Olimex-made software

We provide some examples for basic functions at our GitHub:

- For Arduino you can find them here:

https://github.com/OLIMEX/ESP32-POE/tree/master/SOFTWARE/ARDUINO

- For ESP-IDF here:

https://github.com/OLIMEX/ESP32-POE/tree/master/SOFTWARE/ESP-IDF

# 4. Frequently asked questions

- Is it safe to have USB powering and PoE powering connected and enabled at the same time?
  - If you are using ESP32-POE or any of its variants – no, it is not safe and should be avoided at all costs.
  - If you are using ESP32-POE-ISO or any of its variants – yes, it is safe to have them both enabled.
- Where are I2C, UART, SPI pins exposed?
  The ESP32 chip has very advanced multiplexing and you can define any free GPIO pin for I2C, UART, SPI operation as long as you are within the maximum supported (some penalties to SPI's maximum frequency apply, when not using the dedicated pins). Notice that some ESP32 pins can only be inputs. Double check if the pins you want to use are free. Defining pins for another function is a purely software effort.
- I provide 24V to the Ethernet of ESP32-PoE-ISO's but it doesn't seem powered. What is the problem?
  TPS2375PW (Si3402) would NOT work with 24V DC. The recommended voltage is 48V DC and the minimum is around 37V DC. For more info refer to TPS2375PW's (Si3402-B's) datasheet.
- What is the PoE class of the devices?
  ESP32-POE and ESP32-POE-ISO are set for class PoE class 0 operation (0.44W-12.95W).  There was one batch of ESP32-POE devices, hardware revision M, that are setup to class 4 operation (similar to ESP32-POE2). Class 4 operation might require more current since it requires at least 12.95W up to 25.5W, if you have trouble with ESP32-POE revision M devices refer to the schematic and remove resistor R54 to switch back to class 0 operation. This only applies to ESP32-POE boards from hardware revision M. ESP32-POE revision M1 were set to class 0 operation again.
- I have 10 of your boards connected to my switch but some doesn't seem to work. Are they broken?
- Switches reserve the maximum power for the board. Make sure the total power output of the switch is not exceeded. For 10 of these boards it needs to be capable to provide at least 150W (this is with the default setting for PoE Class 0, and if you changed the jumper state to upgrade the Class 0 to Class 4, then double it).
- What is the power delivery mode of these boards? Is it mode A or mode B?
  ESP32-POE and ESP32-POE-ISO and all variants use LAN connector that is compatible with both mode A or mode B. Either one is fine.
- I power the board from the Ethernet connector. What current do I have available for additional circuits?
  The ESP32-POE circuit can safely provide up to 4W in total. Part of this wattage is used to power the ESP32 module, the battery charger, and other circuits part of the board design; the remaining wattage is available for additional circuits (up to around 3W). So you can use 3W for own circuits around 600mA @ 5V or 900mA @ 3.3V (combined draw from 3.3V and 5V lines shouldn't be more than 3W) safely.
  The isolated DCDC in the design of ESP32-POE-ISO provides up to 2W in total but some power is used for the module itself and the battery charger. So you can use around 1.5W for own circuits around 300mA @ 5V or 450mA @ 3.3V (combined draw from 3.3V and 5V lines shouldn't be more than 1.5W) safely.
- I power the board from the battery connector. The LEDs remain off. Is it broken?
  Probably not. This is a low-power design. The LEDs would not turn on when operating on battery to save power. You need other ways to determine if it works or not. For example, something over the serial lines or over the Ethernet (with no PoE enabled else it would get powered from there).
- A specific resistor gets very hot! What is this component? Is it safe? Can I remove it?
  This resistor is required by the IEEE standards. It is used for MPS (maintain power signature).
  Search online "maintain power signature poe" to get the general idea. It consumes around 0.5W, when the board is powered from Power-Over-Ethernet (notice the MPS resistor consumes 0 when the board is powered from other sources). We didn't ensure MPS in the first hardware revisions of the board (e.g. had no resistor in place), but this caused availability problems when using some power saving modes – the board consumed less wattage than PoE equipment can detect, which led to PoE equipment shutting the board off.
  If you have soldering experience and the resistor bothers you, you might try desoldering it and see if that effects your setup negatively. Notice that we don't recommend doing so.
- ESP32-PoE and ESP32-POE-ISO don't work well with bauds over 115200. What to do? We use CH340 daily for bauds up to 2M so it is not a hardware issue. Some older drivers might have wrong timings, causing worse throughput. Download and install the latest drivers for CH340. If you are using Linux make sure to try with these drivers: high-speed driver for Linux (https://github.com/OLIMEX/ch340-dkms).
- Help! Ethernet is not working. I use ESP32-POE-WROVER and ESP32-POE-ISO-WROVER. Is the device broken?
  Your board with a WROVER chip is not broken and we test each device with Ethernet, chances of broken device are very low. However, there is hardware difference in the pinout between boards with WROOM and WROVER modules – the WROVER module requires two extra pins for the PSRAM memory. One of the pins affects the Ethernet, the other – the I2C. When WROVER module is used (instead of the default WROOM) then GPIO16 and GPIO17 are unavailable (both are used for the PSRAM inside the module). In that case we have set GPIO33 to go on UEXT1 pin #5 (instead of GPIO16). Also the clock for the Ethernet is now GPIO0 (instead of GPIO17). Modify your software for these differences.
- Help! Ethernet is not working always upon power-up. If I press the reset or power cycle the board a few times it starts working. Is my device faulty?
  It is probably because your software didn’t utilize the PHY_PWR pin (GPIO12) properly. This behavior happens when the PHY controller (LAN8720) gets powered before the ESP32 module can generate the PHY clock. What your software should do is hold the LAN8720 in reset for few milliseconds via the PHY_PWR pin and release it from reset only after PHY clock is already generated by the ESP32 module. Simple software workarounds that can be tested are adding delay before Ethernet initialization or toggling GPIO12 to reset only the Ethernet chip until connection is restored.
- Even if I power the board from power jack the USB-serial converter CH340T appears to remain powered. This affects my readings of the serial. What can I do?
  Look at the schematic, the CH340 can get parasitically powered via GPIO3 if you haven't set the GPIO as input. It is a problem if GPIO3 is set as output. So make sure it is set as input.

# 5. Useful links

The main pages of ESP32-POE and ESP32-POE-ISO are the main hubs for other locations, make sure to first check the product page at our web-site.

ESP32-POE main product page:

https://www.olimex.com/Products/IoT/ESP32/ESP32-POE/open-source-hardware

ESP32-POE-ISO main product page:

https://www.olimex.com/Products/IoT/ESP32/ESP32-POE-ISO/open-source-hardware

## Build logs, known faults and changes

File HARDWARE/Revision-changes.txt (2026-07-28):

ESP32-PoE

This hardware design is made with KiCAD. If you have problems opening the design, try getting newer KiCAD version (probably even latest nightly build).

Hardware revision M2
---

Patched CH340 circuitry to reduce chances of hardware damage. Patch is over D7.

Hardware revision M1
---

1. Reverted back the PoE class from class 4 to class 0 due to complaints. Class 4 devices reserve double the power and the minimum consumption is much higher, it makes sense for a device like ESP32-POE2 but not much sense to ESP32-POE or ESP32-POE-ISO. Switching to class 4 was a problem for customers that used one PD for many ESP32-POE devices and now the switch runs out of wattage for same amount of devices.

Hardware revision M
---

1. Moved design to KiCad 7.x;
2. PWR switch (U9) chased with TPS2378DDAR(HSOIC-8);
3. Changed PoE class from class 0 (0.44W to 12.95W) to class 4 (12.95W to 12.95W);
4. R7 was getting too hot, so we lowered the value and added r42 in parallel with 9.1k values;
5. Chanaged USB to UART chip to CH340X;
6. Changed battery charger to TP4054-42-SOT25-R(SOT23-5);

Hardware revision L1

---

Overview: minor design improvements

Notable changes:

1. Lower the battery charge current to 100mA (down from 455mA). Changed R6 from 2.2k to 10k;
2. U2 changed from TPS2376D(SO-8) to TPS2375D and related resistors no longer placed (R50 and R51). This is because of small differnces between TPS237D and TPS2375D.

---

Hardware revision L

---

Overview: minor design improvements

Notable changes:

U2 changed from TPS2376PW(TSSOP-8) to TPS2376D(SO-8), because of this, U2's package changed from TSSOP-8 to SOIC-8_1.75mm;
Elements were moved, at the bottom, to free place for the SOIC-8 package.

---

Hardware revision K

---

Overview: minor design improvements

Notable changes:

1. Added voltage divider R50(130k/R0402) / R51(10k/R0402) to set the undervoltage lockout (UVLO) when TPS2376PW is used;
2. U2 changed from TPS2375PW(TSSOP-8) to TPS2376PW(TSSOP-8).

---

Hardware revision J (internal, not released)

Overview: Major layout changes - bigger size, added mount holes, a lot of other components (buttons, SD card, etc) moved

Notable changes:

1. The board PCB extended with 5mm from 28x75mm to 28x80mm;
2. Added U8(SN74LVC1G04DBVR(SOT23-5)) and C28(100nF/16V/10%/X7R/C0402), for WROVER-module compatibility. When WROVER is populated, for GPIO17 is then NC and Ethernet's clock will be supplied by GPIO0;
3. Added R45(10R/R0402) to connect, when populated, I2C-SCL to GPIO33, for WROVER-module compatibility. When WROVER is populated, GPIO16 is also NC;
4. Added three mounting holes, 2.2mm drills;
5. BAT1 changed from DW02R to DW02S and rotated;
6. Both buttons, SD card and many other components moved too;
7. Added numbering of the layers: 1-F.Cu, 2-In1.Cu, 3-In2.Cu, 4-B.Cu.

---

Hardware revision I

---

Overview:

- Changed PCB from 2-layer to 4-layer. Inner layer helps cooling down the DCDC.

Notable changes:

1. Added C26 and R43.

---

Hardware revision H1

Overview:

- fixed problems related to boards losing Ethernet connectivity when you draw any current off the board

Notable changes:

1. R33 changed from 4.7 Ohms to 15 Ohms 
2. Added RC patch betweem the coil and GND. R=22 Ohm and C=220p/110V

---

Hardware revision G1

Overview:

- released, improved behavior during low power modes 

Notable changes:

1. Added resistors R41 and R42(both 3.9k/R1206). Visible in the schematics.

---

Hardware revision G

Overview:

- unreleased, major chages to PoE circuit

Notable changes:

1. The Si3402-B-GM(QFN-20_5x5mm) changed with TPS2375PW(TSSOP-8) + TX4138(ESOIC-8)! Because of this, many related changes:

Deleted: U8, C12, C25, C26, R33, R34, R38, C29, L6, R41, R42, R43, R45, C30, EN_CT1 and EN_CT2

In the schematic added the following elements:

SMAJ58A/SMA as D8
TX4138(ESOIC-8) as U5
TPS2375PW(TSSOP-8) as U2
30.1k/1%/R0402 as R38
5.23k/1%/R0402 as R34
4.7R/R0402 as R33
0.03R/1%/R1206 as R28
4.42k/1%/1/16W/R0402 as R27
180k/1%/R0402 as R23
24.9k/1%/R0402 as R7
470uF/10V/20%/Low_ESR/RM2.5/6.0x11mm as C25
12pF/50V/5%/COG/C0402 as C23
100nF/100V/20%/X7R/C1206 as C12

2. Added D9(1N5819S4(SOD-123)) to protect ESP_EN from 4.2V levels during the process of programming the board;
3. No PTH pad at MTDI(pin 14);
4. 7 i 8 krak na LAN_CON1 ste si ostanat vyrzani kym GND kakto si bqha - tova okon4atelno resi Gogo;
5. Korpusite na PTH elektrolitnite kondenzatori stanaha ot SMD na PTH;
6. C12 i C24 - 100nF/100V se promeniha v korpus ot 1206 na 0603;
7. ESP-WROOM-32 se updaitna
8. pone s 20mils se izliza ot padovete
9. Sloji se CE.
10. C20 otide na bot strana.
11. Kvoto moje se barna.
12. L3 stana FB0805/600R/2A
13. mrudnaha se kolkoto e vyzmojno nqkolko pisti, kolkoto mqsto tolkova mnogo e sbutano.
14. Smeni se simvola na t1 s pravilniq.
15. Razchisti se kolkoto e po vyzmonostite mi i vremeto za tova.

---

Hardware revision F

Overview:

- unreleased, general improvements

Notable changes:

1. Added ESDS314DBVR(SOT-23-5) v sch i pcbnew. Slojen e v B.Cu;
2. Dobaveni sa 2 x NA(GG0402052R542P) v sch i pcbnew. Dobaveni sa v B.Cu;
3. C22 e premeseten mejdu L4 i GND padovete na U4;
4. R29 e premesten do C8;
5. R30 e zavartqn an 90 gradуsa i e slohen pod C6;
6. U7 e zavartqn na 90 gradуs;
7. R26 e premesten ot B.Cu v F.Cu. za da se sloji TVS1. Namesten e pod L2;
8. C6 e zavartqn na 90 gradusa;
9. C11 premesten ot B.Cu v F.Cu i e slojen mejdu L2 i GND pads na U4;
10. R10, R11, R12, R13 sa premesteni ot B.Cu v F.Cu i sa slojeni pod GND pads na U4 za da se namestqt TVS3 i TVS2;
11. L2, U7, C6, R30 bqha premesteni s nqkolko mils na lqvo;
12. C6 be premesten po blizo do U1 za da ima mqsto za TVS1;
13. C13 e namesten pod C6 i U1 za da se namesti TVS1;
14. C7 e izmesteno v lqvo s nqkolko mils za da se osvobodi mqsto za defirencialnite dvoiki TD+ i TD-;
15. C16 e doblijen do U1;
16. Net - (L3 - Pad1) be premahnat (Po preporaka ot Nikito) ot ednata strana na USB - UART1 za da moje da se osvobodi mqsto za routvane.

---

Hardware revision E

Overview:

- improved behavior after reset 

Notable changes:

1. Added C20(1uF/10V/20%/X5R/C0603) to the ESP_EN signal;
2. R32 changed from 470k/R0402 to 10k/R0402;
3. C27 decreased length of the pads (the footprint was changed locally) to avoid short circuits during manual soldering;
4. D2 rotated and moved away from C29;
5. C22 changed from 22uF/6.3V/20%/X5R/C0603 to 47uF/6.3V/20%/X5R/C0805;
6. T1 changed from DTC114YKA(SOT-23) to LMUN2211LT1G(SOT-23);
7. UEXT1 changed from B-V-10-LF(GBH254SMT-10) to P-B-V-10-LF;

---

Hardware revision D

Overview:

- introduced major low-power mode improvements - deep sleep mode now consumes under 100uA;
- added battery measurement option;

Notable changes:

1. R29 changed from 4.99k/1%/R0402 to 220k/R0402;
2. R30 changed from 1.1k/1%/R0402 to 49.9k/1%/R0402;
3. L2 changed from 2.2uH/1.5A/DCR<0.1R/CD32 to 2.2uH/1.5A/DCR=72mR/20%/3.00x3.00x1.50mm/CD32(NR3015T2R2M);
4. R32 changed from 1k/R0402 to 470k/R0402;
5. U1(CH340T(SSOP20W))'s pin<20>, NOS#, disconnected from GND and left open;
6. D6 and D7 (1N5819S4(SOD-123)) added;
7. R18 and R19 changed from 220R/R0402 to 10k/R0402;
8. R16(NA(10k/R0402)) added just in case;
9. C26 changed from 1nF/50V/10%/X7R/C0603 to 1nF/50V/10%/X7R/C0402;
10. To enable battery measurement, added: C19(1nF/50V/10%/X7R/C0402), R17, and R22 - both resistors (470k/R0402);
11. R7(0R(board_mounted)) shorted and deleted;
12. BAT_SENS_E1 jumper added (to enable battery sense);
13. 3D models improved.

---

Hardware revision C1 notable changes:

1. Added 3D view

---

Hardware revision C notable changes:

1. Moved buttons RST1 and BUT1 0.5mm towards the ESP-WROOM-32 module.
2. USB-UART1's shield was disconnected from Vneg, now it is floating. Added L3 ferrite bead, NA(FB0805/600R/2A), between USB-UART1's shield and GND, in case there is a need to connect the shield to the GND.
3. U3 was changed from MCP73833(MSOP10) to BL4054B-42TPRN(SOT23-5). This required additional changes:
- R22(2.2k/R0402) was renamed to R5(2.2k/R0402). So, R22 is now removed;
- R16(1k/R0402) was removed;
- R17(10k/R0402) was removed;
- THERM1 pad was removed;
- The LED COMPL1(LED/GREEN/0603) was removed;
4. Added C12 -> 2.2uF/100V/20%/X7R/C1206(AVX_12061C225KAT2A_Comet) in parallel to C27 -
15uF/100V/20%/RM2.5/6.3x11mm(Farnell:1281844).
5. MICRO_SD1's housing was disconnected from Vneg and connected to GND.
6. Added resistor divider - R4(47k/R0402)/R9(100k/R0402) between +5V and GND to GPI39 for External Power Sense purposes.
7. R34 changed from 49.9R/1%/R0402 to NA(49.9R/1%/R0402) -> Default Class 0 (0.44 to 12.95 W) instead of Class 3 (6.49 to 12.95 W)!!!
8. EN_CT1 and EN_CT2 changed from Open to Closed package by default!

---

Hardware revision B2 notable changes:

1. R34 changed from 49.9R/1%/R0402 to NA(49.9R/1%/R0402). This changes PoE's Class 3 to Class 0(Default)
2. EN_CT1 and EN_CT2 changed from position open to closed (soldered).
3. One 2.2uF/100V/20%/X7R/C01206(C12) is manually soldered in parallel to C27(15uF/100V/20%/RM2.5/6.3x11mm(Farnell:1281844))

---

Hardware revision B1 - initial release

---

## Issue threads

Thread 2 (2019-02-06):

PoE output power specification

mangtronix, 2019-02-06:
What is the amount of power that can be drawn from the PoE module?  I looked and couldn't find any specification.  Something like 5W at 5V?  It looks like the output is fixed at 5V?

I want to attach some NeoPixel-style LED strips. Thanks!

DanKoloff, 2019-02-06:
We have tested up to 800mA at 5V.  This is the safe threshold. 5W at 5V might be possible but depends on other load and the unit would probably heat up.

jcstaudt, 2019-02-18:
FYI: I noticed these relevant power output concerns listed on [Crowd Supply](https://www.crowdsupply.com/silicognition/wesp32).

> Olimex provides no specification on available output power. The inductor specified in the schematic is specified for a maximum of 2 A, which, at 5 V, would limit the available power to a maximum of 10 W. The classification resistor in the schematic would indicate 12.95 W max, but between the power inductor limits and the lack of cooling features on the circuit board, achieving this output power is very unlikely.

TsvetanUsunov, 2019-02-18:
When you build network of many sensors, you try to lower your power consumption as much as possible. What is the reason to make one node which to suck all available power from the POE hub?

mangtronix, 2019-02-18:
I’d like to build a network of lights. Using a 12W RGBW LED would be great. It’s a different application than a sensor network.

TsvetanUsunov, 2019-02-18:
We definitely can't cover all use cases, when we design something we try to balance the features most customer would need and keep budget low. You can choose other solution like the x3 times more expensive Crowd Supply solution quoted above for your appication.

mangtronix, 2019-02-18:
No problem, if the spec sheet said "tested at 4W" I would have known. Best luck with your products!

jcstaudt, 2019-02-18:
@TsvetanUsunov Sorry, I didn't intend to make a business case for one product or another with my previous post. I found some tested information that might help fill in some gaps and potentially help in designing a power output specification, and I thought it would help add to the discussion.

Closed 2019-04-09.

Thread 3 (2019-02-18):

Power isolation for IEEE 802.3at compliance

jcstaudt, 2019-02-18:
I stumbled across a criticism of the ESP32-POE and wanted to submit a project issue for awareness and potential resolution:

> No isolation. The IEEE 802.3at spec demands isolation up to 1500 Vrms and the product page of the Olimex ESP32-POE specifically mentions that there is no isolation and that you should not have Ethernet and USB plugged in simultaneously.

Source: [Crowd Supply](https://www.crowdsupply.com/silicognition/wesp32)

TsvetanUsunov, 2019-02-18:
Yes, I read this, the guy was desperately to justify his high price and I didn't want to spoil his pitch and campain.
Please show me where 802.3at state 1500Vrms insulation is necessary?
Making insulation adds parts to the board, which in most of the cases people would not need.
ESP32-POE works in field connected mostly to sensors or relays etc. There is no need for such insulation in most of the cases.

jcstaudt, 2019-02-20:
> **33.4  -  Additional Electrical Requirements**
> 33.4.1 - Isolation

> PDs and PSEs shall provide isolation between all accessible external conductors, including frame ground (if any), and all MDI leads including those not used by the PD or PSE. Any equipment that can
be connected to a PSE or PD through a non-MDI connector that is not isolated from the MDI leads
needs to provide isolation between all accessible external conductors, including frame ground (if any), and the non-MDI connector. Accessible external conductors are specified in subclause 6.2.1b) of IEC60950-1:2001.

> This electrical isolation shall withstand at least one of the following electrical strength tests:
a) 1500Vrms at 50Hz to 60Hz for 60s, applied as specified in subclause5.2.2 of IEC60950-1:2001.
b) 2250Vdc for 60s, applied as specified in subclause5.2.2 of IEC60950-1:2001.
c) An impulse test consisting of a 1500V, 10/700μs waveform, applied 10 times, with a 60s interval
between pulses. The shape of the impulses shall be 10/700μs (10μs virtual front time, 700μsvirtual
time of half value), as defined in IEC60950-1:2001 Annex N.

> There shall be no insulation breakdown, as defined in subclause5.2.2 of IEC60950-1:2001, during the test. The resistance after the test shall be at least 2MΩ, measured at 500Vdc. Conductive link segments that have differing isolation and grounding requirements shall have those requirements provided by the port-to-port isolation of network interface devices (NID).

[Source](https://www.silvertel.com/images/appsnotes/ANX-POE-Isolation-Barrier-explained.pdf)

Also, I saw your blog post today about the new [ESP32-POE-ISO](https://olimex.wordpress.com/2019/02/20/open-source-hardware-esp32-poe-board-now-has-new-version-with-3000vdc-galvanic-insulation) with 3000VDC isolation!

TsvetanUsunov, 2019-02-21:
Note that ESP32-POE is neither PD neither PSE and has no MDI.
No one is supposed to touch this board while it's powered, and usually it is mounted in well isolated plastic box somewhere in the field.
If one wants to implement IP phone, router, or other device or want to use ESP32-POE as power supply for other equipment definitely should take measures to not allow people to make physical contact with the board metal parts which is the purpose of this part of the standard and the insulation may not be done necessary INSIDE the board, but with the enclosure where this board is installed.

jcstaudt, 2019-02-21:
I see. Based solely on this information, I understand that compliance for this spec is determined at the system level and not necessarily at the level of each individual component. If I'm correct, this would mean that the system (including ESP32-POE) could be compliant with this portion of the specification if isolation is also incorporated within the neighboring components (in an enclosure or otherwise). My interpretation of the snippet above tells me that power isolation is not required without onboard PD/PSE/MDI, which resolves this issue.

mlopezegi, 2019-10-10:
ESP32-POE is indeed a PD (Powered device) and has MDI (Medium Dependent Interface, in 100BaseT case: RJ45 and circuitry).
All external connectors and the frame must be isolated from line ethernet cable.
If there are no connectors available in the device and the frame is isolated from the circuits there is no problem.
Otherwise, ESP32-POE is not applicable and ESP32-POE-ISO must be used.

Closed 2019-02-21.

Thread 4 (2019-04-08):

Analog pins?

rdehuyss, 2019-04-08:
On the ESP32 POE, which are the analog pins? They are not mentioned in the connector on your website.

Am I correct to assume that GPIO pins 39, 36, 35 and 34 can be used for measuring analog voltages?

d3v1c3nv11, 2019-04-09:
Nope. Only GPIO35, GPIO39 (EXT2 p.3, p.1)

tusharvb19, 2019-04-13:
So on GPIO35 which is HSPI and GPIO39 we can connect analog signal to measure???

danalytixx, 2022-07-27:
I am using an current sensor, to measure current. I used GPIO 39 and it is not working properly. Which pins should i use for this example? the other pins like 39 etc. are measuring voltage as i understood.

DanKoloff, 2022-07-27:
If by "analog pins" you mean ADC, it is like 12 pins that can be used for ADC, basically all pins that have the ADC function can be used, use this picture as a reference:

https://www.olimex.com/Products/IoT/ESP32/ESP32-POE/resources/ESP32-POE-GPIO.png

It is another question whether all of these 12 pins are free to use, some of them are probably used for one of their functions.

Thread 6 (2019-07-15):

MQTT client over the wired connection

zorce, 2019-07-15:
Hi,
I have tried most of the MQTT libraries without success to get it to work on the wired connection. Could you please provide an example on native MQTT and not azure example.

Best regards!

DanKoloff, 2019-07-16:
What about this:

https://github.com/knolleary/pubsubclient

https://esp32.com/viewtopic.php?t=10328

zorce, 2019-07-16:
Thank you!
I finally managed to get it working! Thanks for the links!

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

DanKoloff, 2019-07-16:
Since we don't have a published example, if you can share your experience or demo code that would be awesome. I might even test it and publish it to this github if I manage to get something working.

zorce, 2019-07-16:
Will do. Currently testing stability. Will post my example here soon.

Den tis 16 juli 2019 09:22DanKoloff <notifications@github.com> skrev:

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

zorce, 2019-07-16:
Hi,
I have uploaded my example code at https://github.com/zorce/ESP32-POE_MQTT_example
Take a look and feel free to add it to your example repository.

lancelon, 2020-07-24:
Can I just confirm MQTT on the ESP32-POE is no problem? I'm about to buy a few for this express purpose and came across this thread...! Cheers

zorce, 2020-07-24:
For my purpose it has been stable enough. Have been running with 3 boards
for quite a while now.

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

DanKoloff, 2021-04-01:
We also tested Azure via Ethernet in Arduino IDE with this code, refer to the README.txt for installation instructions

[MQTT-Azure_ETH_WiFi.txt](https://github.com/OLIMEX/ESP32-POE/files/6241968/MQTT-Azure_ETH_WiFi.txt)
[README.txt](https://github.com/OLIMEX/ESP32-POE/files/6241969/README.txt)

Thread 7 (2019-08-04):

no longer builds against the latest esp-idf master

mangodan2003, 2019-08-04:
Additionally the basic Ethernet example in esp-idf doesn't seem to work with this board. It gives a mac timeout error. Seems like this board may have powered enabled via a GPIO which the esp-idf libraries don't provide a configuration option for. Having added a few lines to the example to provide the power the it gets a little but further but then times out awaiting reset. Not had time to looked any further.

DanKoloff, 2019-08-04:
Did you test exactly with this example: https://github.com/OLIMEX/ESP32-POE/tree/master/SOFTWARE/ESP-IDF/ESP32_PoE_Ethernet ?

mangodan2003, 2019-08-04:
Away from my dev system atm but that sure looks like the one. I first tried it some months ago and it built and worked fine but due to lack of websockets client and time the project halted. There is now a websocket client and example in the latest idf sdk but I've not been able to get the PoE board to work with it.

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

--
Sent from my Android device with K-9 Mail. Please excuse my brevity.

DanKoloff, 2019-08-21:
We tested it today. It seems to work fine. Make sure to use the demo that I linked since the default Ethernet demo has no configuration for LAN8710A only for LAN8720.

mangodan2003, 2019-08-21:
I've got my project going by modifying one one of the esp-idf examples to enable the PHY power and set the PHY address so its no big deal for me any more, but I tried anyway. With a current fresh clone of the esp-idf and the above example it fails as shown here below.
I ran make twice and omitted the output of the first run to keep it a bit shorter.

```
dan@grape:~/workspace/esp/esp32/projects$ git clone https://github.com/OLIMEX/ESP32-POE.git
Cloning into 'ESP32-POE'...
remote: Enumerating objects: 49, done.
remote: Counting objects: 100% (49/49), done.
remote: Compressing objects: 100% (46/46), done.
remote: Total 406 (delta 5), reused 36 (delta 3), pack-reused 357
Receiving objects: 100% (406/406), 6.75 MiB | 3.45 MiB/s, done.
Resolving deltas: 100% (119/119), done.
dan@grape:~/workspace/esp/esp32/projects$ cd ESP32-POE/
.git/     HARDWARE/ SOFTWARE/
dan@grape:~/workspace/esp/esp32/projects$ cd ESP32-POE/SOFTWARE/
ARDUINO/           ESP32-PoE_NES-Emu/ ESP-IDF/   
dan@grape:~/workspace/esp/esp32/projects$ cd ESP32-POE/SOFTWARE/ESP-IDF/ESP32_PoE_
ESP32_PoE_Ethernet/ ESP32_PoE_iperf/
dan@grape:~/workspace/esp/esp32/projects$ cd ESP32-POE/SOFTWARE/ESP-IDF/ESP32_PoE_Ethernet/ESP32_PoE_Ethernet/
dan@grape:~/workspace/esp/esp32/projects/ESP32-POE/SOFTWARE/ESP-IDF/ESP32_PoE_Ethernet/ESP32_PoE_Ethernet$ make
Toolchain path: /home/dan/.espressif/tools/xtensa-esp32-elf/esp32-2019r1-8.2.0/xtensa-esp32-elf/bin/xtensa-esp32-elf-gcc
Toolchain version: esp32-2019r1
Compiler version: 8.2.0
Python requirements from /home/dan/workspace/esp/esp32/esp-idf/requirements.txt are satisfied.

App "ESP32-PoE" version: 98aa6c8-dirty
CC build/main/main.o
In file included from /home/dan/workspace/esp/esp32/projects/ESP32-POE/SOFTWARE/ESP-IDF/ESP32_PoE_Ethernet/ESP32_PoE_Ethernet/main/main.c:23:
/home/dan/workspace/esp/esp32/esp-idf/components/esp32/include/rom/uart.h:1:2: warning: #warning rom/uart.h is deprecated, please use esp32/rom/uart.h instead [-Wcpp]
 #warning rom/uart.h is deprecated, please use esp32/rom/uart.h instead
  ^~~~~~~
/home/dan/workspace/esp/esp32/projects/ESP32-POE/SOFTWARE/ESP-IDF/ESP32_PoE_Ethernet/ESP32_PoE_Ethernet/main/main.c:27:10: fatal error: eth_phy/phy_lan8720.h: No such file or directory
 #include "eth_phy/phy_lan8720.h"
          ^~~~~~~~~~~~~~~~~~~~~~~
compilation terminated.
/home/dan/workspace/esp/esp32/esp-idf/make/component_wrapper.mk:291: recipe for target 'main.o' failed
make[1]: *** [main.o] Error 1
/home/dan/workspace/esp/esp32/esp-idf/make/project.mk:584: recipe for target 'component-main-build' failed
make: *** [component-main-build] Error 2
```

DanKoloff, 2019-08-22:
It certainly looks like the whole component structure related to the Ethernet was changed since the most recent v4.1-dev tag. This change probably breaks all Ethernet examples for all ESP32 boards with Ethernet. The change is not only in the directory naming and structure, it also changes the way the ESP-IDF header files related to the Ethernet are used.

Check how the directory structure looked in v4.0-dev: https://github.com/espressif/esp-idf/tree/v4.0-dev/components/ethernet/eth_phy

Check how it looks now: https://github.com/espressif/esp-idf/tree/v4.1-dev/components/esp_eth/include

We are looking into this, and need to decide what is the best way to go.

g-mocken, 2019-09-05:
@DanKoloff I can compile and successfully run the linked olimex demo code only with release-3.3 of esp-idf.
@mangodan2003 would you mind to share more details regarding your modifications of the esp-idf examples code?

DanKoloff, 2019-09-06:
@g-mocken Yes, 3.3 is fine. The issue here is present only for newest versions of esp-idf - 4.1v-dev and newer.

g-mocken, 2019-09-06:
@DanKoloff Sorry if I was not clear enough: My point is that 4.0 does not work either. And I would like to use 4.0 (or later) because of other improvements. I would not mind ignoring 4.1 for the time being. If the demo code is supposed to work with 4.0, then I would appreciate some hints as to what I might be doing wrong.

DanKoloff, 2019-09-06:
@g-mocken We still haven't published an updated example. Everything I said about the issue here still applies for 4.0: https://github.com/OLIMEX/ESP32-POE/issues/7#issuecomment-523761856

TsvetanUsunov, 2019-09-06:
Espressif official ESP32 IDF is 3.3 https://www.espressif.com/en/support/download/sdks-demos
if you decide to use experimental, unstabile, preliminary releases we would rather not spend time on them, until they are officially released as they may bear bugs and we do not recommend anyone to use them in production

mangodan2003, 2019-09-06:
@TsvetanUsunov I hadn't actually checked the releases page, I merely followed the getting started documents here https://docs.espressif.com/projects/esp-idf/en/latest/get-started/. It does appear that that hes left me with a dev version tho :

```
dan@grape:~/workspace/esp/esp32/esp-idf$ git describe
v4.0-dev-1443-g39f090a4f
```

@g-mocken Sure. Copy examples/common_components/protocol_examples_common to the projects local components dir and amend the start function in connect.c around about line 191

```
    eth_phy_config_t phy_config = ETH_PHY_DEFAULT_CONFIG();
    phy_config.phy_addr = 0; //Add this to set the PHY address to 0 - its hard coded to 1 by ETH_PHY_DEFAULT_CONFIG above.
```

Before the last 3 lines of the same function add the following to power up the PHY

```
#define PIN_PHY_POWER 12
    gpio_pad_select_gpio(PIN_PHY_POWER);
    gpio_set_direction(PIN_PHY_POWER, GPIO_MODE_OUTPUT);
    gpio_set_level(PIN_PHY_POWER, 1);
    vTaskDelay(pdMS_TO_TICKS(10));
```

You will need to also amend the make file to point to the new components instead of the original one.

Then in the sdkconfig of your project, or via the menuconfig utility find and set each of  the following :

```
# CONFIG_EXAMPLE_USE_SPI_ETHERNET is not set
# CONFIG_EXAMPLE_ETH_PHY_IP101 is not set
# CONFIG_EXAMPLE_ETH_PHY_RTL8201 is not set
CONFIG_EXAMPLE_ETH_PHY_LAN8720=y
# CONFIG_ETH_RMII_CLK_INPUT is not set
CONFIG_ETH_RMII_CLK_OUTPUT=y
# CONFIG_ETH_RMII_CLK_OUTPUT_GPIO0 is not set
CONFIG_ETH_RMII_CLK_OUT_GPIO=17
CONFIG_ETH_SMI_MDC_GPIO=23
CONFIG_ETH_SMI_MDIO_GPIO=18
```

If you are using a different board these settings may differ. I only have experience with the PoE board. Check the relevant schematics.

Hope that makes sense and is of some help.

will-emmerson, 2019-11-18:
The instructions above didn't work for me for v4.1, but the following did:

```
static esp_err_t phy_device_power_enable_via_gpio() {
    gpio_pad_select_gpio(PIN_PHY_POWER);
    gpio_set_direction(PIN_PHY_POWER, GPIO_MODE_OUTPUT);
    gpio_set_level(PIN_PHY_POWER, 1);
    vTaskDelay(100 / portTICK_PERIOD_MS);   // note <100ms didn't work
    return ESP_OK;
}

// after defining config, set this
esp_eth_config_t config = ETH_DEFAULT_CONFIG(mac, phy);
config.on_lowlevel_init_done = phy_device_power_enable_via_gpio;
```

ArendJan, 2019-11-30:
Thanks for the instructions! I can now use Websockets over ethernet! (added in v4)

To make it easier for other people I made a repo with the changes applied(tested with POE rev C): https://github.com/ArendJan/esp32POE-example-v4.1
and these changes also work for the ESP32 GATEWAY(rev F).

will-emmerson, 2019-12-04:
Unfortunately I'm not convinced this code works properly - there seem to be corrupt heap errors when doing an OTA update:

```
      CORRUPT HEAP: multi_heap.c:432 detected at 0x3fff1958
      abort() was called at PC 0x40093817 on core 0
      0x40093817: multi_heap_assert at /home/willemmerson/esp/esp-idf/components/heap/multi_heap_platform.h:59
       (inlined by) multi_heap_malloc_impl at /home/willemmerson/esp/esp-idf/components/heap/multi_heap.c:432

      ELF file SHA256: b4505d213febafc83734033f8d64bae971764286d4fe8c5f04aed2c6b707663c

      Backtrace: 0x400912a5:0x3ffd97b0 0x4009169d:0x3ffd97d0 0x40093817:0x3ffd97f0 0x40093d89:0x3ffd9810 0x400824c9:0x3ffd9830 0x400824f9:0x3ffd9850 0x4009727d:0x3ffd9870 0x400eed85:0x3ffd9890 0x400eee03:0x3ffd98b0 0x400eee80:0x3ffd98d0 0x400ef895:0x3ffd98f0 0x400efa71:0x3ffd9910 0x4015f51a:0x3ffd9940 0x401760a5:0x3ffd9960 0x400ebeb1:0x3ffd9980 0x4017816e:0x3ffd99a0 0x40093f81:0x3ffd99d0
      0x400912a5: invoke_abort at /home/willemmerson/esp/esp-idf/components/esp32/panic.c:157

      0x4009169d: abort at /home/willemmerson/esp/esp-idf/components/esp32/panic.c:174

      0x40093817: multi_heap_assert at /home/willemmerson/esp/esp-idf/components/heap/multi_heap_platform.h:59
       (inlined by) multi_heap_malloc_impl at /home/willemmerson/esp/esp-idf/components/heap/multi_heap.c:432

      0x40093d89: multi_heap_malloc at /home/willemmerson/esp/esp-idf/components/heap/multi_heap_poisoning.c:191

      0x400824c9: heap_caps_malloc at /home/willemmerson/esp/esp-idf/components/heap/heap_caps.c:115

      0x400824f9: heap_caps_malloc_default at /home/willemmerson/esp/esp-idf/components/heap/heap_caps.c:144

      0x4009727d: malloc at /home/willemmerson/esp/esp-idf/components/newlib/heap.c:32

      0x400eed85: mem_malloc at /home/willemmerson/esp/esp-idf/components/lwip/lwip/src/core/mem.c:237

      0x400eee03: do_memp_malloc_pool at /home/willemmerson/esp/esp-idf/components/lwip/lwip/src/core/memp.c:254

      0x400eee80: memp_malloc at /home/willemmerson/esp/esp-idf/components/lwip/lwip/src/core/memp.c:350 (discriminator 2)

      0x400ef895: pbuf_alloc_reference at /home/willemmerson/esp/esp-idf/components/lwip/lwip/src/core/pbuf.c:336

      0x400efa71: pbuf_alloc at /home/willemmerson/esp/esp-idf/components/lwip/lwip/src/core/pbuf.c:237

      0x4015f51a: ethernetif_input at /home/willemmerson/esp/esp-idf/components/lwip/port/esp32/netif/ethernetif.c:166

      0x401760a5: esp_netif_receive at /home/willemmerson/esp/esp-idf/components/esp_netif/lwip/esp_netif_lwip.c:660

      0x400ebeb1: eth_stack_input at /home/willemmerson/esp/esp-idf/components/esp_eth/src/esp_eth.c:89

      0x4017816e: emac_esp32_rx_task at /home/willemmerson/esp/esp-idf/components/esp_eth/src/esp_eth_mac_esp32.c:255

      0x40093f81: vPortTaskWrapper at /home/willemmerson/esp/esp-idf/components/freertos/port.c:143
```

I don't think it's OTA update that's the problem itself, I think it's just the throughput. When I use Wifi instead it works fine. Annoyingly it's quite intermittent so *sometimes* it works. Also sometimes the ethernet doesn't work after `esp_restart()`, probably because it needs de-initialising properly.

will-emmerson, 2019-12-09:
It seems `CONFIG_ETH_DMA_BUFFER_SIZE=1524` fixes the above problem in v4, see https://github.com/espressif/esp-idf/issues/4454

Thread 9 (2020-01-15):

ESP32-POE-ISO Hanging up

TeKiLLa1985, 2020-01-15:
hi i used this code

`#define ETH_CLK_MODE ETH_CLOCK_GPIO17_OUT
#define ETH_PHY_POWER 12

#include <ETH.h>

static bool eth_connected = false;

void WiFiEvent(WiFiEvent_t event)
{
  switch (event) {
    case SYSTEM_EVENT_ETH_START:
      delay(1000);
      Serial.println("ETH Started");
      //set eth hostname here
      ETH.setHostname("esp32-ethernet");
      Serial.println("Hostname: esp32-ethernet");
      delay(1000);
      break;
    case SYSTEM_EVENT_ETH_CONNECTED:
    delay(1000);
      Serial.println("ETH Connected");
      break;
    case SYSTEM_EVENT_ETH_GOT_IP:
      Serial.print("ETH MAC: ");
      Serial.print(ETH.macAddress());
      Serial.print(", IPv4: ");
      Serial.print(ETH.localIP());
      if (ETH.fullDuplex()) {
        Serial.print(", FULL_DUPLEX");
      }
      Serial.print(", ");
      Serial.print(ETH.linkSpeed());
      Serial.println("Mbps");
      eth_connected = true;
      break;
    case SYSTEM_EVENT_ETH_DISCONNECTED:
      Serial.println("ETH Disconnected");
      eth_connected = false;
      break;
    case SYSTEM_EVENT_ETH_STOP:
      Serial.println("ETH Stopped");
      eth_connected = false;
      break;
    default:
      break;
  }
}

void testClient(const char * host, uint16_t port)
{
  Serial.print("\nconnecting to ");
  Serial.println(host);

  WiFiClient client;
  if (!client.connect(host, port)) {
    Serial.println("connection failed");
    return;
  }
  client.printf("GET / HTTP/1.1\r\nHost: %s\r\n\r\n", host);
  while (client.connected() && !client.available());
  while (client.available()) {
    Serial.write(client.read());
  }

  Serial.println("closing connection\n");
  client.stop();
}

void setup()
{
  Serial.begin(115200);
  WiFi.onEvent(WiFiEvent);
  ETH.begin();
}

void loop()
{
  if (eth_connected) {
    testClient("google.com", 80);
  }
  delay(10000);
}`

and get this output

`14:34:58.966 -> e⸮⸮⸮0Q0080⸮X⸮H⸮ETH Started
14:35:00.279 -> Hostname: esp32-ethernet
14:42:36.269 -> ETH Connected`

and nothing else happend with a other ESP32-POE-ISO the sketch runs fine i tested it on 2 ESP32-POE-ISO and 3 different networks

I hope some one have a Idea to solve this issue

DanKoloff, 2020-01-16:
Each board has the Ethernet interface tested here empirically after manufacturing. So it is likely some sort of software or configuration issue. Try this example:

https://github.com/espressif/arduino-esp32/blob/1.0.3/libraries/WiFi/examples/ETH_LAN8720/ETH_LAN8720.ino

And follow the instructions here:

https://www.olimex.com/Products/IoT/ESP32/_resources/Arudino-ESP32.txt

The last few times someone encountered similar issue it turned out to be some improper network configuration, unrelated to the the ESP32-POE-ISO. For example here:

https://www.olimex.com/forum/index.php?topic=7158.0

DanKoloff, 2020-01-16:
What operating system are you using?

TeKiLLa1985, 2020-01-16:
Win 10 Pro with the last updates

DanKoloff, 2020-01-16:
If the board was working fine, and then stopped working without any changes to the hardware or software setup - then either the board or something in the setup broke somehow.

Did you also test with the ESP-IDF example? This would reduce the chances of a software issue.

TeKiLLa1985, 2020-01-16:
i will try it with the IDF

Closed 2020-10-15.

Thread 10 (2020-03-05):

PxMatrix controling

elektron95, 2020-03-05:
Hi, just a quick question,
As I have significantly less pins, how can I connect and control a PxMatrix 32X64 LED Matrix ?
It's using a HUB75 connection with the falling pins:

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

Thank you for the help!

DanKoloff, 2020-03-05:
Hello,

This is issue tracker for problems with the hardware design of ESP32-PoE. This is not the appropriate place to ask for advice.

Please join the Olimex forums: https://www.olimex.com/forum/

For general advice related to ESP32 and ESP8266 make sure to also join the big espressif forums here (probably the English section): https://www.esp32.com/

Best regards,
Lub/OLIMEX

Closed 2020-03-05.

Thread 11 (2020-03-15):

first upload worked, second did not

karls0, 2020-03-15:
### Hardware:
Board:							Olimex ESP32-PoE
Core Installation version:			Core 4.2.1  Home 3.1.1
IDE name:						platform.io
Flash Frequency:					default
PSRAM enabled:                                    don't know
Upload Speed:					tried default, now at 115200
Computer OS:                                         Linux Mint 19.3

### Description:
I recently bought an Olimex ESP32-PoE and an Olimex ESP32-EVB and uploaded a test-sketch to both. No problem with this.
Next day I wanted to try another sketch, but the upload failed with
 "A fatal error occurred: Failed to connect to ESP32: Timed out waiting for packet header"
From my experience with ESP8266 I checked the supply, but I measure 5.1V at the board. The USB-cable is the same as yesterday, but nevertheless I tried another and it did not help.

I also tried different versions of pressing RST- and BUT-button - no help.

Since I could upload a sketchd yesterday, I really do not understand what could be wrong. Thank you for any tips to help me.
Regards, Karl

DanKoloff, 2020-03-16:
Make sure you are using same USB port as previously. Also try re-installing the drivers, since you use Linux use these instructions: https://github.com/OLIMEX/ch340-dkms - check if this improves the behavior.

I'd also recommend testing with another software tool, maybe some update broke the software. Try Arduino for ESP32: https://github.com/espressif/arduino-esp32 or ESP-IDF

Finally, make sure to also check and report the issue to the platform.io community, maybe it is a well known problem.

If the issue remains tell me if:

Both the PoE and the EVB can't be programmed second time or just the PoE?

karls0, 2020-03-16:
Hi Dan,
thank you for the quick reply and your tips.
First I installed the driver from the OLIMEX-repository, rebooted and tried again.
Uploading to a  OLIMEX ESP32-PoE, Olimex ESP32-EVB and AZ-delivery ESP32 Dev did not work - uploading to a ESP8266 works. This makes me think, that it cannot be the serial-driver.

I then installed Arduino 1.8.12 and the ESP-boards too (following https://www.heise.de/ct/artikel/Arduino-IDE-installieren-und-fit-machen-fuer-ESP8266-und-ESP32-4130814.html ) with the same results. No uploading to ESP32-boards, but everything OK with a ESP8266.

Since the probability that all 3 new ESP32-boards are defective is very low, I must have missed something basic :-((  I have also tried to use a lower upload speed of 115200 - same results.
Any further tips?

TIA, Karl

DanKoloff, 2020-03-16:
I don't think it is three defective boards. It is something trivial, like Linux gave new COM port number for the devices, or some other peripheral used and blocked the COM port, or the driver associated changed and it stopped toggling reset, maybe wrong board configuration was selected. What is the chip in the ESP8266 that works? Is it CH340T? If not - the comparison in behavior is inconclusive, since it probably uses different driver. If the ESP8266 board has CH340T then it is less likely to be a driver issue but still not completely out of question.

I think it is a popular problem so make sure to check for what others might have suggested online.

Also share the test program that you used. I might run it on our boards to compare.

karls0, 2020-03-16:
Hi Dan,
I finally found a solution :-)
https://randomnerdtutorials.com/solved-failed-to-connect-to-esp32-timed-out-waiting-for-packet-header/ describes how to solve the problem. After reading all the comments I started with a 100nF capacitor between EN and GND. This did not work. ThenI tried the 10µF and connected a resistor (the commenter says 1k - I had 5k6 at hand) from EN to +3.3V. Now the upload works and the program starts after uploading.
Thanks for your help and your tips.
Karl

DanKoloff, 2020-03-17:
@karls0 Hello,

Thanks for the update!

Can you confirm all the three boards worked after this fix? Can you also tell me what are the hardware revisions of each of the three boards as printed on the board?

The reason I need that information is to test here and maybe make some hardware changes. Thanks!

karls0, 2020-03-17:
Hi Dan,
I am at it. Did some tests with the AZ-delivery ESP32-Dev and now I tried the ESP32-PoE. Yesterday this worked as I told you. Today I got a new Error. There is no /dev/ttyUSB0 when I connect one of the Olimex-boards (with ch340), but is there with tht AZ-delivery which uses a CP2102. So I tried to install the ch340-driver again (as you told me in your first post). Finally I found out that I had to remove the driver completely and build and install it again. Now /dev/ttyUSB0 is here again :-))
I am continuing my work now and send the results asap.
Karl

karls0, 2020-03-17:
Hi Dan
find enclosed my findings about ploading code to ESP32-boards. I hope this helps you.
The HW-revisions are:
OLIMEX ESP32-PoE  Rev.D
OLIMEX ESP32-EVB  Rev.F
AZ-delivery ESP32 Dev   (no revision on board, but was bought only one week ago)

[upload-check.zip](https://github.com/OLIMEX/ESP32-POE/files/4343544/upload-check.zip)

hth, Karl

DanKoloff, 2020-03-17:
Thank you for the tests and the thorough reports! Pretty helpful. Future hardware revisions would have improved values on EN line but we are still deciding on what values exactly. Unfortunately, we can't replicate the "no upload scenario" here. That is why I have one final request - can you test also with 1uF if you have 1uF capacitor?

karls0, 2020-03-18:
Hi Dan, sorry for the delay. I did my tests with 1µF too and rearranged the table a bit. looks like 1µF is to small. 10M and a resistor between 4k7 and 10k seem to be best (for me). Did you think of a power-manager like TPS3839? Maybe this is a solution?

[upload-check.zip](https://github.com/OLIMEX/ESP32-POE/files/4348592/upload-check.zip)

Again, I hope my findings help. Please inform me of your solution.
Best wishes, Karl

karls0, 2020-03-20:
Hi again,
I forgot to mention that with some combinations reset did not work! Since I don't have a TPS3839DBRZ or a KA75290 for 3.3V I cannot test this, but as soon as I place my next order in China, I will order some of these and test again.
Best wishes and stay healthy!
Karl

karls0, 2020-03-23:
Hi,
as mentioned above, I think that a power-monitor could solve the problem. So I ordered a few TPS3809K33 (SMD) and a few MCP102-300 (for breadboard tests). Since the MCP102 has an open collector output, you can connect it directly to ESP_EN (pin4 on EXTERN1). But since there is button (RST) to GND, I suggest a resistor (I use 4k7 since it only draws current while RST is pressed) in between the output of the IC and EN.
For me this is the best solution, since it is not dependent on the time constant and now even the RST-button works flawlessly. Now I can upload code and use the RST-button.
Regards, Karl

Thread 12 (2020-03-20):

Understanding the RJ45 Jack

zgibson21, 2020-03-20:
I have a question about why this particular RJ45 jack was used. I can see that is has the magnetics built in but why does it also have a diode bridge rectifier? Is the rectifier necessary?

TsvetanUsunov, 2020-03-20:
please read https://en.wikipedia.org/wiki/Power_over_Ethernet
DC power component uses same cable pairs as the AC data component, the bridge rectifier separates the DC from AC components.

thermseekr, 2023-08-08:
I'm having a very hard time finding RJ45 jacks with integrated diode bridges. My usual sources are JLCPCB where I order my assembled PCBs from, and Mouser Electronics. Are there any other good sources you could share?
Thanks!

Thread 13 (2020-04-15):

Timed out waiting for PHY register

Gnubsch, 2020-04-15:
Hello,
I have bought three ESP32-POE-ISO boards With two copies the demo for the ethernet interface works. With the third board I get the timeout error.
It has probably something to do with the clock.

I used the ESP32_PoE_Ethernet_Arduino file for this.
Any tips how I can solve the problem?
I have already tried it on different PC's with different USB cables and ports.

Thanks a lot.

Error: Timed out waiting for PHY register 0x2 to have value 0x0007(mask 0xffff). Current value 0x0000[0m

Arduino 1.8.12 / Board-Lib esp32 1.0.4

DanKoloff, 2020-04-15:
What operating system are you using? What is the baud rate selected?

Gnubsch, 2020-04-15:
OS: Windows 10 Pro / 10.0.18363
Board: Olimex ESP32-POE-ISO Rev.C
Uploadspeed: 115200
Flash Frequency: 80 Mhz
Partition Scheme: Standard
Programmer: AVRSIP mkII
Driver: CH341Ser.INF 01/30/2019, 3.5.2019

`esptool.py v2.6
Serial port COM3
Connecting.....
Chip is ESP32D0WDQ5 (revision 1)
Features: WiFi, BT, Dual Core, VRef calibration in efuse, Coding Scheme None
MAC: 24:0a:c4:25:99:2c
Uploading stub...
Running stub...
Stub running...
Configuring flash size...
Auto-detected Flash size: 4MB
Compressed 8192 bytes to 47...

Writing at 0x0000e000... (100 %)
Wrote 8192 bytes (47 compressed) at 0x0000e000 in 0.0 seconds (effective 6553.6 kbit/s)...
Hash of data verified.
Compressed 15856 bytes to 10276...

Writing at 0x00001000... (100 %)
Wrote 15856 bytes (10276 compressed) at 0x00001000 in 0.9 seconds (effective 139.7 kbit/s)...
Hash of data verified.
Compressed 706784 bytes to 393190...

Writing at 0x00010000... (4 %)
Writing at 0x00014000... (8 %)
Writing at 0x00018000... (12 %)
Writing at 0x0001c000... (16 %)
Writing at 0x00020000... (20 %)
Writing at 0x00024000... (25 %)
Writing at 0x00028000... (29 %)
Writing at 0x0002c000... (33 %)
Writing at 0x00030000... (37 %)
Writing at 0x00034000... (41 %)
Writing at 0x00038000... (45 %)
Writing at 0x0003c000... (50 %)
Writing at 0x00040000... (54 %)
Writing at 0x00044000... (58 %)
Writing at 0x00048000... (62 %)
Writing at 0x0004c000... (66 %)
Writing at 0x00050000... (70 %)
Writing at 0x00054000... (75 %)
Writing at 0x00058000... (79 %)
Writing at 0x0005c000... (83 %)
Writing at 0x00060000... (87 %)
Writing at 0x00064000... (91 %)
Writing at 0x00068000... (95 %)
Writing at 0x0006c000... (100 %)
Wrote 706784 bytes (393190 compressed) at 0x00010000 in 34.7 seconds (effective 163.0 kbit/s)...
Hash of data verified.
Compressed 3072 bytes to 128...

Writing at 0x00008000... (100 %)
Wrote 3072 bytes (128 compressed) at 0x00008000 in 0.0 seconds (effective 1536.0 kbit/s)...
Hash of data verified.

Leaving...
Hard resetting via RTS pin...`

DanKoloff, 2020-04-15:
You used this example, right:

https://github.com/OLIMEX/ESP32-POE/blob/master/SOFTWARE/ARDUINO/ESP32_PoE_Ethernet_Arduino/ESP32_PoE_Ethernet_Arduino.ino

Gnubsch, 2020-04-15:
Correct.

DanKoloff, 2020-04-15:
When you get the error, what happens if you press the on-board reset button?

Gnubsch, 2020-04-15:
The error occurs after restarting the device or when I press the hardware button. The same error occurs.

DanKoloff, 2020-04-16:
Please drop an e-mail at support@olimex.com with short introduction and link to this GitHub issue, I will tell you how to proceed with the return.

We don't have this problem here and each board's Ethernet is tested empirically so I have no idea what might be wrong. The clock comes from the ESP32, so I don't think it is clock issue.

Gnubsch, 2020-04-16:
Thank you for your efforts. I am writing the email to the support.

danieltang3434, 2020-10-12:
Hi @Gnubsch, did you get any feedback from Olimex? I'm facing the same problem also.

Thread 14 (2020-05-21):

SD card reader conflicts with Ethernet interface PHY_PWR pin

cyberman54, 2020-05-21:
GPIO12 is used for PHY_PWR switch on this board.
But in ESP IDF it is used for Data3 of 4bit SDMMC interface.
Unfortunately forcing to 1bit SDMMC interface seems not to work with arduino esp32.
I posted a PR to solve this: https://github.com/espressif/arduino-esp32/pull/4020

DanKoloff, 2020-05-22:
Ummm 1bit SDMMC works with Arduino IDE, we have also defined it in our board configuration as "#define BOARD_HAS_1BIT_SDMMC":

https://github.com/espressif/arduino-esp32/blob/master/variants/esp32-poe/pins_arduino.h

Make sure you are selecting the proper board. Try this example:

https://raw.githubusercontent.com/OLIMEX/ESP32-POE/master/SOFTWARE/ARDUINO/ESP32_PoE_Ethernet_SD_Card_Arduino/ESP32_PoE_Ethernet_SD_Card_Arduino.ino

DanKoloff, 2020-05-22:
https://github.com/espressif/arduino-esp32/issues/3903

DanKoloff, 2020-05-22:
Thanks, I see it was merged now.

cyberman54, 2020-05-24:
For reference, from esp32 Forum:

https://www.esp32.com/viewtopic.php?t=4838

Closed 2020-05-22.

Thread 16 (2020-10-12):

Ethernet initialization error on Olimex ESP32-PoE Rev E

danieltang3434, 2020-10-12:
When I try to initialize and start using the ethernet on Olimex ESP32-PoE, I encounter with the error message below:

```
E (1039) emac: Timed out waiting for PHY register 0x2 to have value 0x0007(mask 0xffff). Current value 0x0000
E (2040) emac: Timed out waiting for PHY register 0x3 to have value 0xc0f0(mask 0xfff0). Current value 0x0000
E (2041) emac: Initialise PHY device Timeout
[E][ETH.cpp:101] begin(): esp_eth_enable error: -1
```

The platform/framework/tool that I using is: PlatformIO, Arduino Framework, Visual Studio Code Editor.

Code snippet:

```
// Ethernet port parameters
// ETH_CLOCK_GPIO17_OUT - 50MHz clock from internal APLL inverted output on GPIO17 - tested with LAN8720.
#define ETH_CLK_MODE ETH_CLOCK_GPIO17_OUT
// Pin number of the enable signal for the external crystal oscillator (-1 to disable for internal APLL source).
#define ETH_POWER_PIN -1
// Type of the Ethernet PHY (LAN8720 or TLK110).
#define ETH_TYPE ETH_PHY_LAN8720
// I²C-address of Ethernet PHY (0 or 1 for LAN8720, 31 for TLK110).
#define ETH_ADDR 0
// Pin number of the I²C clock signal for the Ethernet PHY.
#define ETH_MDC_PIN 23
// Pin number of the I²C IO signal for the Ethernet PHY.
#define ETH_MDIO_PIN 18

#include <Arduino.h>
#include <ETH.h>
#include <WiFi.h>

void WiFiEvent(WiFiEvent_t event)
{
    switch (event)
    {
    case SYSTEM_EVENT_ETH_START:
        Serial.println("ETH Started");
        //set eth hostname here
        ETH.setHostname("esp32-ethernet");
        break;
    case SYSTEM_EVENT_ETH_CONNECTED:
        Serial.println("ETH Connected");
        break;
    case SYSTEM_EVENT_ETH_GOT_IP:
        Serial.print("ETH MAC: ");
        Serial.print(ETH.macAddress());
        Serial.print(", IPv4: ");
        Serial.print(ETH.localIP());
        if (ETH.fullDuplex())
        {
            Serial.print(", FULL_DUPLEX");
        }
        Serial.print(", ");
        Serial.print(ETH.linkSpeed());
        Serial.println("Mbps");
        eth_connected = true;
        break;
    case SYSTEM_EVENT_ETH_DISCONNECTED:
        Serial.println("ETH Disconnected");
        eth_connected = false;
        break;
    case SYSTEM_EVENT_ETH_STOP:
        Serial.println("ETH Stopped");
        eth_connected = false;
        break;
    default:
        break;
    }
}

void setup()
{
    Serial.begin(115200);
    Serial.println();
    Serial.println();
    Serial.println();

    // Set on connected event
    WiFi.onEvent(WiFiEvent);
    // Init Ethernet
    ETH.begin(ETH_ADDR, ETH_POWER_PIN, ETH_MDC_PIN, ETH_MDIO_PIN, ETH_TYPE, ETH_CLK_MODE);
    Serial.print("Waiting for Ethernet... ");
    // Wait for connected status
    while(!eth_connected) {
        Serial.print(".");
        delay(500);
    }
    Serial.println("Ethernet connected! ");
}
```

The board cannot connect to Internet and the LAN cable has been tested with other board such as "Olimex ESP32-EVB" and it is working, so probably not the LAN cable issue.
Can anyone help to point out any false parts? Thank you so much.

DanKoloff, 2020-10-13:
ESP32-EVB and ESP32-POE have different Ethernet clock circuit - it is not surprising that the code that works on ESP32-EVB doesn't run on ESP32-POE without changes! Good news is that only few changes for the pins for the Ethernet are required!

ESP32-EVB uses external clock generator, while ESP32-POE uses internal clock generator and power enable/disable pin.

For ESP32-POE the two pins are:

#define ETH_CLK_MODE ETH_CLOCK_GPIO17_OUT
#define ETH_PHY_POWER 12

The reason for this difference is that ESP32-EVB has a lot of hardware (since the design was research, evaluation and development) and the external generator saves one GPIO pin. ESP32-POE has less hardware and more available pins, so it is not a problem to switch to the more common Ethernet circuit with internal clock and GPIO for power enable and disable.

Closed 2022-11-02.

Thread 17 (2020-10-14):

step file for board with all components

cycleworm, 2020-10-14:
hi,
is there a step file that includes the board and all components (in one file). i want to use it in fusion 360 to create a case.
thanks.

DanKoloff, 2020-10-15:
https://www.olimex.com/forum/index.php?topic=7868.msg29540#msg29540

Also this is not the proper place for such queries and requests, this is a place to report issues with the ESP32-POE board.

Closed 2020-10-15.

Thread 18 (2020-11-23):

GPIO floating whilst power over ethernet and using internal pullup

trevm8, 2020-11-23:
I am using a pushbutton connected to GPIO3 and configured to use the internal pull-up resistor. I find that when I have non-powered wired ethernet connected and USB powered - the code executes as expected with consistent results recorded.

However; when I use the POE functionality, whilst using the exact same code - GPIO3 is now read as constantly changing low to high (floating).

I am using a TP-Link POE switch

DanKoloff, 2020-11-24:
It should work but my general advice is to avoid using GPIO3 since it is connected to CH340T.
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

However, if there is no way to avoid using it, try with external pull-up maybe the internal one is not good enough. I suspect when CH340T is not powered, maybe it gets powered from the GPIO3 line for some reason.

Closed 2021-05-17.

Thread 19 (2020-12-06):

SD card and Serial1 not working together

aboronkai, 2020-12-06:
I use Serial0 and Serial1 UARTs the same time, but when I try to use the SD card (with the given examples) the Serial1 stops working (Serial0 still OK),

What could be the problem?

Even if I don't do anything (read, write...) with the SD card, just call the SD_MMC.begin at the Setup(), the Serial1 doesn't respond.

aboronkai, 2020-12-10:
I made a ton of search on this topic, but found no usable answer.
BUT found the solution.
Interestingly if I placed the SD_MMC.begin() BEFORE the ETH.begin() line, the SD card was working, the serial1 was working.
I don't really understand why, but it works.

DanKoloff, 2020-12-15:
Did you update everything first? What you mentioned should not happen anymore if you use latest releases.

This used to happen because of this: https://github.com/espressif/arduino-esp32/issues/3903

The issue was re-iterated and clarified here: https://github.com/espressif/arduino-esp32/pull/4020

It was fixed in this commit: https://github.com/espressif/arduino-esp32/commit/594ee6d249f726a0f3335533b911a401d4eb028d

aboronkai, 2020-12-27:
Thanks for the reply!
I use Arduino 1.8.13, installed at 2020.oct. 13.
Using the default SD-MMC example from Olimex, the working mode is 1 bit by default.
Anyway as I mentioned I found a way to work...

Closed 2021-01-04.

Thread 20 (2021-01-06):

Example uses depricated calls, please post example with 4.1++

bbulkow, 2021-01-06:
Given that Espressif has moved to ESP-IDF quite a while ago - maybe a year - perhaps it's time to stop using the depricated called, and post an example after the changes?

Here is the migration webpage:
https://docs.espressif.com/projects/esp-idf/en/latest/esp32/api-reference/network/tcpip_adapter_migration.html

Here is the deprication example, exactly as one expects from 4.0 code in a post-4.2 world.

../main/ethernet_example_main.c: In function 'app_main':
../main/ethernet_example_main.c:69:5: warning: 'tcpip_adapter_init' is deprecated [-Wdeprecated-declarations]
     tcpip_adapter_init();

DanKoloff, 2021-01-06:
Thanks for the help. It is in our TODO list but our software back log is huge and we have trouble updating everything all the time. Overall, our goal had never been to provide the best examples with the latest software tools, just good enough examples to prove that the hardware works. There is a reason our projects are published here on the GitHub - we hope that more knowledgeable people can contribute with their feedback or with patches.

bbulkow, 2021-01-06:
If it were true that these changes were in the last few months, I would have some sympathy. However, I believe the 4.1 release is somewhere around a year old, and contains very major changes to the networking stack. If you aren't able to push the example in this period of time, I would suggest updating the readme to state you only support 4.0 and nothing more recent.

It is regrettably the Espressif people seem so flagrant about breaking shipping APIs, but they are, which makes it hard to just switch my project back to 4.0.

DanKoloff, 2021-01-06:
Is the tag one year old, tho?
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

The project folders of each of our demos has the exact version of ESP-IDF required mentioned in the folder name and also every resource is available before and without any purchase, so it clear what resources are exactly available. Also the examples, can be used as basis for any version of ESP-IDF. Most of the demos are simple pin assignments.

bbulkow, 2021-01-06:
It's much older than that. Espressif moves the tags.

bbulkow, 2021-01-07:
https://github.com/bbulkow/Olimex-ESP32-POE-example

DanKoloff, 2021-01-07:
Thank for this, I tested what you published and it works here, one small thing that I spotted in the description is that the boards use CH340, not CH341 but the difference between them is not big anyway. My main problem is the initial report for the issue. I also tested our 4.0 version example and it compiles here with version 4.1 and 4.2, it also works when empirically tested, so I am puzzled what was the original issue? The 4.0 project didn't build at your side? Maybe I don't understand something.

DanKoloff, 2021-01-08:
We've added a 4.2 example, like the previous ones - we just used the default demo and did some re-mapping to fit ESP32-PoE's hardware. It is located here https://github.com/OLIMEX/ESP32-POE/tree/master/SOFTWARE/ESP-IDF/ESP32_PoE_Ethernet_IDFv4.2

Closed 2021-01-06.

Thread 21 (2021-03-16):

Can it work like an access point?

fr33soul, 2021-03-16:
Is there any way to make it work as an access point?
For example, does it take network data from the ethernet port and release it through the wifi with only one IP address for both? Even with mesh architecture?!

DanKoloff, 2021-03-17:
Sure both Ethernet and WIFI can work at the same time. This is a simple test for using both WIFI and Ethernet under Arduino IDE:

https://github.com/OLIMEX/ESP32-POE/tree/master/SOFTWARE/ARDUINO/ESP32_PoE_Ethernet_WIFI_test

If you want more info search online for:

"esp32 ethernet wifi bridge"

fr33soul, 2021-03-17:
I tried to google and the only solution would look like this: [https://github.com/espressif/esp-idf/tree/master/examples/ethernet/eth2ap](url)
now i tried to compare your eth_wifi_test with that of espressif. I would like to try with Espressif's ESP-IDF solution and I wanted to know if Are there any parameters that are specific to your Olimex that I need to take into consideration?

fr33soul, 2021-03-17:
ho notato che anche voi avete ESP-IDF [https://github.com/OLIMEX/ESP32-POE/tree/master/SOFTWARE/ESP-IDF/ESP32_PoE_Ethernet_IDFv4.2](url)
si può utilizzare per questo scopo? a cosa si riferisce il vostro esempio ESP-IDF?

DanKoloff, 2021-03-17:
We have ESP-IDF examples and you can use the example that you linked, of course, as basis for Ethernet connectivity. But we haven't published ESP-IDF example that demonstrates both WIFI and Ethernet (in the same example).

fr33soul, 2021-03-17:
ok i will try the Espressif example than. I will let you know if it works.

Closed 2021-05-17.

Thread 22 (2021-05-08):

Changes for revision F & G missing from change log?

glynhudson, 2021-05-08:
What's changed in the two latest revisions?

DanKoloff, 2021-05-17:
There are no hardware revisions F and G of ESP32-POE yet... Maybe you meant to post this under ESP32-EVB repo?

glynhudson, 2021-05-17:
Apologies, I was referring to the ESP32-GATEWAY. I've now found the hardware change log for this unit here:   https://github.com/OLIMEX/ESP32-GATEWAY/tree/master/HARDWARE

Closed 2021-05-17.

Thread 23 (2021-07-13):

Discrepancy between readme, schematics, and example code

squintz, 2021-07-13:
ESP32-POE/SOFTWARE/ESP-IDF/ESP32_PoE_Ethernet_IDFv4.2/README.md

The Ethernet README says that a DM9051 will be used but when you look at the schematics (ESP32-PoE_Rev_E.pdf) a LAN8710A is shown. Furthermore, the example code has options for the DM9051 as well as other phys but does not have the LAN8710A listed. Instead it has the LAN8720A. I know these LAN chips are pretty much the same but when combined with the information in the README it makes it confusing.

DanKoloff, 2021-07-14:
That's correct. It seems that our developer copy-pasted the default README from ESP-IDF and didn't change the text. I will change it to LAN8720 in the text. LAN8720 and LAN8710 are slightly different, 8710 can also work as 10Mbit/s and uses two pins more compared to 8720 that only works at max rate 100Mbit/s.

Closed 2021-08-17.

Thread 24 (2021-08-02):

Ethernet + DMA I/O driven SPI display causes display corruption.

jonshouse1, 2021-08-02:
I am having trouble using a display with the POE board, issue described here:

https://github.com/espressif/esp-iot-solution/issues/110

DanKoloff, 2021-08-17:
1) Looking at your video you have ESP32-POE-ISO. Not ESP32-POE...

2) A lot of cables connected at the header, probably you are using a pin that is already used for on-board peripheral. Quite likely one of the pins related to the Ethernet. Double check if the pins you are using are free.

3) What is the display that you are using? Is it ours MOD-LCD2.8RTP, it seems so? Why are you not connecting it to the board via the UEXT cable?

jonshouse1, 2021-08-17:
> Looking at your video you have ESP32-POE-ISO. Not ESP32-POE...

I have both the ISO and non ISO models, I get the same results on both.

>  A lot of cables connected at the header, probably you are using a pin that is already used for on-board peripheral. Quite likely one of the pins related to the Ethernet. Double check if the pins you are using are free.

https://github.com/jonshouse1/ESPVNCC/blob/main/esp32_lcd_touch_screen_wiring.png
The only used connection has button with a pullup. I tried moving my GPIOs around, it did not make a difference.

>   What is the display that you are using? Is it ours MOD-LCD2.8RTP, it seems so? Why are you not connecting it to the board via the UEXT cable?

Not your display module, no. I have several projects under way with this board (If I can make it reliable!), I am using the header to connect sensors rather than display.

DanKoloff, 2021-08-17:
Meanwhile I tested with our MOD-LCD2.8RTP and ESP32-POE-ISO with and without Ethernet connected and it has no such issue. Mind that our display uses same controller. Here is a picture of my setup:

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

Here is the code and libraries that I used (quick and dirty combination of LCD and Ethernet demo):

[lcd-esp32-poe-iso.zip](https://github.com/OLIMEX/ESP32-POE/files/6998136/lcd-esp32-poe-iso.zip)

DanKoloff, 2021-08-17:
The hardware connection that you linked seem alright on first look.

If you have both ESP32-POE and ESP32-POE-ISO, start debugging the issue by using ESP32-POE. Leave ESP32-POE-ISO aside. The reason is that ESP32-POE-ISO has less free pins.

jonshouse1, 2021-08-17:
I am not a C++ programmer or Arduino ide user.

The best test I have found is to write a single colour to every line of the display over and over again as fast as possible, then send Ethernet data to the host and see if the display corrupts. Because the display is a single colour only your eye is drawn instantly to any change in colour.

At the moment it looks like the ESP IDF SPI driver has a bug that I am finding but it is a little early to be completely sure.

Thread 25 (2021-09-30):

Alternatives for component LAN8710A-EZC ,SI3402-B-GM

mightChamp, 2021-09-30:
Hello,
I have followed your work, It helps me lot.
I need alternative solution for below components, mentioned in  ESP32-PoE_Rev_E.sch Doc:
1)  LAN8710A-EZC
2) SI3402-B-GM

Could you please suggest alternative for these?

Thank You

TsvetanUsunov, 2021-10-01:
1. LAN8710A can be replaced by LAN8720
2. There are plenty of alternatives from MPS, Texas Instruments etc. For instance MP8007 or TPS23XXX

Closed 2021-11-16.

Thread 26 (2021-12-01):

Will this Circuit works as an Active PoE or Passive PoE Device?

mightChamp, 2021-12-01:

DanKoloff, 2021-12-01:
It is active PoE, the TPS2375PW chip in the design has detection, classification and undervoltage lockout (UVLO),  also these controllers include an adjustable inrush limiting feature.

Closed 2021-12-01.

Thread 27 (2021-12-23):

ESP32-PoE Rev. G alot of crc errors

Berjastein, 2021-12-23:
Hi, we have been using ESP32-PoE Rev. E without any problems.
Now we received Rev. G boards, and they give alot of crc errors.

We are running same code on Rev. E without any problems, i think its something with the power supply, from PoE.
Because if we run usb and ethernet it works without any problems.

Seems like the new poe is not working like the old one?
When a battery is charging it gets even worse.

Any advice on what to do?

TsvetanUsunov, 2021-12-23:
contact support@olimex.com with description

Closed 2022-02-11.

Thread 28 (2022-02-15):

Schematics for Revision "I"?

dfijma, 2022-02-15:
The HARDWARE-folder contains the schematics for revisions upto G1. Today, I received an ESP-POE board (ordered directly from Olimex) that shows "Revision I" (capital-i, I guess) on the PCB. Could the schematics for that revision also be made available?

DanKoloff, 2022-02-15:
Thanks for the notice, should be available here now: https://github.com/OLIMEX/ESP32-POE/tree/master/HARDWARE

Closed 2022-02-16.

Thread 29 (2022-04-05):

Problems with certain GPIOs

bmangodt, 2022-04-05:
I have designed a Raspberry Pi hat at work that has Wiegand, 4 external inputs and 3 relays with the function of it being used as an access control hat.
Now, I want the ESP32-POE to function with this instead of designing something from scratch, so I designed a simple adapter pcb for this.
Everything works fine except 3 GPIOs.
GPI 0, 1, 2 and 3 are connected to inputs 1, 2, 3 and 4 respectively. Only GPIO 0 and 3 are reading correctly, the other ones are floating.
Relay 3 is connected to GPI36. This GPIO stays in a high state even though it is configured as output and set low.

All other GPIOS are configured in the exact same way and are behaving as they should. Also, according to the ESP32-POE pinout, all my chosen pins are available to use.
I cannot upload any schematic of the hat I designed as this is company property and is under NDA. I can however tell you all ports work on a Raspberry Pi.

Also, steps to recreate aren't included because standard Arduino GPIO setup is straight forward and I'm only looking for why these specific GPIOs aren't behaving like they should. Are they used for something that is not mentioned? If so, then why are they available externally? Thanks in advance.

DanKoloff, 2022-04-12:
GPI36 is not GPIO. It is only input for the board...

Closed 2022-07-20.

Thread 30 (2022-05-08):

Applying these settings to the official sample app causes crash - what else needs changing?

gherlein, 2022-05-08:
https://github.com/OLIMEX/ESP32-POE/blob/master/SOFTWARE/ESP-IDF/README.md#common-configurations 404s

Also the build fails:

../main/ethernet_example_main.c:13:10: fatal error: tcpip_adapter.h: No such file or directory
 #include "tcpip_adapter.h"
          ^~~~~~~~~~~~~~~~~
compilation terminated.

I suspect I need to install or config something, but the [README](https://github.com/OLIMEX/ESP32-POE/blob/master/SOFTWARE/ESP-IDF/README.md) is missing.

idf.py --version
ESP-IDF v5.0-dev-2586-ga82e6e63d9

I tried in the ESP32_PoE_Ethernet_IDFv4.0  ESP32_PoE_Ethernet_IDFv4.2  ESP32_PoE_Ethernet_IDFv4.4 folders, all no joy.

I need that README!

DanKoloff, 2022-05-13:
Well, if you wish to compile, for example "ESP32_PoE_Ethernet_IDFv4.4", it is recommended to use ESP-IDF version 4.4.

ESP-IDF v5.0-dev-2586-ga82e6e63d9 is nightly developer build for ESP-IDF developers. It is not an official release aimed at ESP32 developers, but aimed at ESP-IDF developers.

gherlein, 2022-05-15:
Good catch, but that's not the problem.  I did revert to using 4.4.  The OLIMEX repo is copied from the master Espressif repo but uses a relative link. The broken spot is "See common pin assignments for Ethernet examples from [upper level](https://github.com/OLIMEX/ESP32-POE/blob/master/SOFTWARE/ESP-IDF/README.md#common-pin-assignments)."

The proper link is:  https://github.com/OLIMEX/ESP32-POE/tree/master/SOFTWARE/ESP-IDF/ESP32_PoE_Ethernet_IDFv4.0

I'll submit a PR.

I can now build this and it works.  But I am trying to understand the deltas between this working example and the official sample app.  It looks like the working app has:

 Ethernet Type (Internal EMAC)  --->
    Ethernet PHY Device (LAN8720)  --->
(23) SMI MDC GPIO number
(18) SMI MDIO GPIO number
(-1) PHY Reset GPIO number
(0) PHY Address

Closest I can get with the official ethernet sample app is:

[*] Internal EMAC
        Ethernet PHY Device (LAN87xx)  --->
(23)    SMI MDC GPIO number (NEW)
(18)    SMI MDIO GPIO number (NEW)
(-1)    PHY Reset GPIO number
(0)     PHY Address

but that crashes:

0x400810c4: call_start_cpu1 at /home/gherlein/esp/esp-idf/components/esp_system/port/cpu_start.c:160

I (242) cpu_start: App cpu up.
I (269) cpu_start: Pro cpu start user code
I (269) cpu_start: cpu freq: 160000000
I (269) cpu_start: Application information:
I (274) cpu_start: Project name:     ethernet_basic
I (279) cpu_start: App version:      1
I (284) cpu_start: Compile time:     May 15 2022 06:53:02
I (290) cpu_start: ELF file SHA256:  305b8665e38598d2...
I (296) cpu_start: ESP-IDF:          v4.4.1-dirty
I (301) heap_init: Initializing. RAM available for dynamic allocation:
I (308) heap_init: At 3FFAE6E0 len 00001920 (6 KiB): DRAM
I (314) heap_init: At 3FFB3BF0 len 0002C410 (177 KiB): DRAM
I (321) heap_init: At 3FFE0440 len 00003AE0 (14 KiB): D/IRAM
I (327) heap_init: At 3FFE4350 len 0001BCB0 (111 KiB): D/IRAM
I (333) heap_init: At 4008B9CC len 00014634 (81 KiB): IRAM
I (341) spi_flash: detected chip: generic
I (344) spi_flash: flash io: dio
I (349) cpu_start: Starting scheduler on PRO CPU.
I (0) cpu_start: Starting scheduler on APP CPU.
E (459) esp.emac: emac_esp32_init(349): reset timeout
E (459) esp_eth: esp_eth_driver_install(214): init mac failed
ESP_ERROR_CHECK failed: esp_err_t 0x107 (ESP_ERR_TIMEOUT) at 0x40085548
0x40085548: _esp_error_check_failed at /home/gherlein/esp/esp-idf/components/esp_system/esp_err.c:42

file: "../main/ethernet_example_main.c" line 122
func: app_main
expression: esp_eth_driver_install(&config, &eth_handle)

abort() was called at PC 0x4008554b on core 0
0x4008554b: _esp_error_check_failed at /home/gherlein/esp/esp-idf/components/esp_system/esp_err.c:43

Backtrace:0x40081932:0x3ffb67a00x40085555:0x3ffb67c0 0x4008a6be:0x3ffb67e0 0x4008554b:0x3ffb6850 0x400d6359:0x3ffb6870 0x400ffdf9:0x3ffb6900 0x40088169:0x3ffb6920
0x40081932: panic_abort at /home/gherlein/esp/esp-idf/components/esp_system/panic.c:402

0x40085555: esp_system_abort at /home/gherlein/esp/esp-idf/components/esp_system/esp_system.c:128

0x4008a6be: abort at /home/gherlein/esp/esp-idf/components/newlib/abort.c:46

0x4008554b: _esp_error_check_failed at /home/gherlein/esp/esp-idf/components/esp_system/esp_err.c:43

0x400d6359: app_main at /home/gherlein/src/esp32-poe-ea/basic/build/../main/ethernet_example_main.c:122 (discriminator 1)

0x400ffdf9: main_task at /home/gherlein/esp/esp-idf/components/freertos/port/port_common.c:129 (discriminator 2)

0x40088169: vPortTaskWrapper at /home/gherlein/esp/esp-idf/components/freertos/port/xtensa/port.c:131

gherlein, 2022-05-15:
Fixed a few other settings, but this one

CONFIG_EXAMPLE_ETH_PHY_LAN8720=y                              | CONFIG_EXAMPLE_ETH_PHY_LAN87XX=y

is probably causing the crash now.

I (382) system_api: read default base MAC address from EFUSE
E (402) lan87xx: lan87xx_init(499): wrong chip ID
E (402) esp_eth: esp_eth_driver_install(215): init phy failed
ESP_ERROR_CHECK failed: esp_err_t 0xffffffff (ESP_FAIL) at 0x40085548
0x40085548: _esp_error_check_failed at /home/gherlein/esp/esp-idf/components/esp_system/esp_err.c:42

file: "../main/ethernet_example_main.c" line 122
func: app_main
expression: esp_eth_driver_install(&config, &eth_handle)

abort() was called at PC 0x4008554b on core 0
0x4008554b: _esp_error_check_failed at /home/gherlein/esp/esp-idf/components/esp_system/esp_err.c:43

I suspect I need to install the driver code, but with no instructions this is not easy.

gherlein, 2022-05-15:
oh hoo boy, the actual code is substantially different.

I guess we can close this issue.  The real problem is that to use this board on a new project my only choice is to basically derive off this sample code, preventing me from taking advantage of the nice "create a new project" features in Visual Code.  Boo.

Closed 2022-07-20.

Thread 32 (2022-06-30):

Example ESP32_PoE_Ethernet_Arduino does not connect (last event SYSTEM_EVENT_ROC_DONE ) ESP32-POE Rev G

edrethardo, 2022-06-30:
Heyho,
I'm using [the example code ](https://github.com/OLIMEX/ESP32-POE/tree/master/SOFTWARE/ARDUINO/ESP32_PoE_Ethernet_Arduino) with added debug prints on the ESP32-POE Rev G Board

My console ouput is:
starting Ethernet
ETH Any other event 18
ETH Any other event 20
ETH Any other event 22

I'm connected to a Router with DHCP but I'm not using POE right now as I'm using the serial console via USB for debugging purposes to avoid damaging my Computer. The device is powered by my computers USB 3 connector

it's notable that the gateway and dns server are not the same in our network, could it be I need to set those parameters manually?
Did maybe anything relevant to this change between Rev.B and G I didn't notice?
do I explicitly need to use POE in this example?
My code is attached below

```
#define ETH_CLK_MODE ETH_CLOCK_GPIO17_OUT
#define ETH_PHY_POWER 12

#include <ETH.h>

static bool eth_connected = false;

void WiFiEvent(WiFiEvent_t event)
{
  switch (event) {
    case SYSTEM_EVENT_ETH_START:
      Serial.println("ETH Started");
      //set eth hostname here
      ETH.setHostname("esp32-ethernet");
      break;
    case SYSTEM_EVENT_ETH_CONNECTED:
      Serial.println("ETH Connected");
      break;
    case SYSTEM_EVENT_ETH_GOT_IP:
      Serial.print("ETH MAC: ");
      Serial.print(ETH.macAddress());
      Serial.print(", IPv4: ");
      Serial.print(ETH.localIP());
      if (ETH.fullDuplex()) {
        Serial.print(", FULL_DUPLEX");
      }
      Serial.print(", ");
      Serial.print(ETH.linkSpeed());
      Serial.println("Mbps");
      eth_connected = true;
      break;
    case SYSTEM_EVENT_ETH_DISCONNECTED:
      Serial.println("ETH Disconnected");
      eth_connected = false;
      break;
    case SYSTEM_EVENT_ETH_STOP:
      Serial.println("ETH Stopped");
      eth_connected = false;
      break;
    default:
    Serial.printf("ETH Any other event %u \n", event);
      break;
  }
}

void testClient(const char * host, uint16_t port)
{
  Serial.print("\nconnecting to ");
  Serial.println(host);

  WiFiClient client;
  if (!client.connect(host, port)) {
    Serial.println("connection failed");
    return;
  }
  client.printf("GET / HTTP/1.1\r\nHost: %s\r\n\r\n", host);
  while (client.connected() && !client.available());
  while (client.available()) {
    Serial.write(client.read());
  }

  Serial.println("closing connection\n");
  client.stop();
}

void setup()
{
  Serial.begin(115200);
  delay(10000);
  Serial.println("\n starting Ethernet");
  WiFi.onEvent(WiFiEvent);
  ETH.begin();
}

void loop()
{
  if (eth_connected) {
    testClient("google.com", 80);
  }
  delay(10000);
}
```

Thank You for any suggestions

FStefanni, 2022-07-19:
Hi,

I have a rev D, but it does not work too.
I am using PoE with 48V, since it is stated that the chip to work must be powered.

No fix found at the moment...

Regards

FStefanni, 2022-07-19:
Hi,

some news: it seems to be a BSP bug, that I reported here:

<https://github.com/espressif/arduino-esp32/issues/7007>

Regards.

FStefanni, 2022-07-20:
Hi,

the issue is resolved: as pointed out in the previously linked issue, the updated example works.
Events have changed names, but the Olimex example has not been updated.
Here the link to the updated official esp32/arduino example: <https://github.com/espressif/arduino-esp32/blob/master/libraries/Ethernet/examples/ETH_LAN8720/ETH_LAN8720.ino>

Regards

DanKoloff, 2022-07-20:
Thanks for the update, I will keep it open as a reminder until we find time to update all Ethernet examples to the new definitions.

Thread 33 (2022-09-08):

Can GPIO5 be used ? Reading 2,5V on it all the time

Ulrar, 2022-09-08:
Hi,

I've been using Panasonic PIR sensors connected to esp32 (not poe) boards without issues, configured with esphome's binary_sensor in input_pulldown mode.

Trying to use the same config on an esp32-poe however and I can't get it to work on GPIO5, that pin reads 2,5V regardless of what's connected to it. [This PNG](https://www.olimex.com/Products/IoT/ESP32/ESP32-POE/resources/ESP32-POE-GPIO.png) doesn't say anything about that pin, but is there something connected to it already that would prevent me from using it for a binary_sensor ?

Thanks

DanKoloff, 2022-09-09:
GPIO5 has a 10k external pull-up - check it the schematic near the UEXT part. I see in your code "input_pulldown" so it probably creates some sort of divider (pull-up - pull-down). I don't know what is the sensor and the requirements but the issue is probably related to the hardware pullup on the board. There are different ways to overcome that issue but that would depend on the exact hardware and goals. If it was me, I'd probably fix this issue by removing the pull-up resistor - unsolder R36.

Ulrar, 2022-09-09:
Okay, I went and tried a bunch of pins and after quite a few I found one that worked : GPIO32.
So you're saying some of the pins are connected to pullup resistors but it's not mentioned on that png on the website, is there another document I should be referring to when choosing pins ?
Thanks

DanKoloff, 2022-09-09:
It is always best idea to check the schematic, or the export of the schematic in PDF format:

https://github.com/OLIMEX/ESP32-POE/blob/master/HARDWARE/ESP32-PoE-hardware-revision-I/ESP32-PoE_Rev_I.pdf

Download it and find and trace the GPIO you are interested in. ESP32 chip doesn't have a lot of pins and there is heavy multiplexing usually, so finding absolutely free pin is tough. But usually the GPIO pins at the UEXT are free to use, as long as you are aware of the pull ups.

Ulrar, 2022-09-13:
Ah, that's very helpful, I see the resistor you were referring to for GPIO5 now, so I know what to look out for.
Thanks !

Closed 2022-09-13.

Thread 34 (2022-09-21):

ESP32-POE-ISO-IND fails Ethernet.begin()

MihaMarkic, 2022-09-21:
I've just got ESP32-POE-ISO-IND and trying to get ip address through DHCP.
I'm using Arduino framework with arduino-libraries/Ethernet@^2.0.1
My code would be like:
```cpp
#include <Ethernet.h>
  byte mac[] = {0xDE, 0xAD, 0xBE, 0xEF, 0xFE, 0xED};
  int result = Ethernet.begin(mac);
  Serial.print("Ethernet.begin ");
  Serial.println(result);
```
The problem is that begin method always returns 0 (AFAIK it should return 1 when successful https://www.arduino.cc/reference/en/libraries/ethernet/ethernet.begin/).

The question is why it doesn't work. Is it MAC the problem as I just copied the one from sample code?

MihaMarkic, 2022-09-21:
Nevermind, I guess I have to use ETH & WifiClient for some reason instead.

Closed 2022-09-21.

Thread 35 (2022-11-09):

RevK Changelog

tube0013, 2022-11-09:
Just received a batch of RevK Boards. they appear 6mm longer than previous versions. Please post the rest of the changes in this version.

thanks.

DanKoloff, 2022-11-15:
It is 5mm longer indeed, this is due to mount holes that are now available. Some other components had been moved too. Schematics, exports and notes had been updated, dimensions would take a little longer.

DanKoloff, 2023-01-10:
Dimension picture is now also updated.

Closed 2023-01-10.

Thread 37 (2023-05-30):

ESP32-POE-WROVER and Ethernet

mikkle, 2023-05-30:
Hello,

Since the WROVER-edition of EP32-POE uses GPIOs 16 and 17 for the PSRAM, it would seem there is a conflict with the Ethernet PHY, which also depends on GPIO17.

By default, and in the sample code (Arduino framework) it says
`#define ETH_CLK_MODE ETH_CLOCK_GPIO17_OUT`
With that setting, ETH.begin() fails.
I got the PHY to start up by overriding that to
`#define ETH_CLK_MODE ETH_CLOCK_GPIO0_OUT`
but that seems a bit random, since the schematic for ESP32-POE shows pin 5 (XTAL/CLKIN) as connected to GPIO17.

And, indeed, I have some code that runs fine on the WROOM-edition, but borks on the WROVER-edition when powered over ethernet (which basically means that the the Eth connection is up).

So the big question: Is it at all possible to use the wired ethernet on ESP32-POE-WROVER, and if there is, are there any other restrictions apart from not using GPIOs 16-17 compared to the WROOM-edition - any low-level config options/settings that can solve the (as I see it) internal pin conflict?

Cheers,
Mikkle

DanKoloff, 2023-05-31:
Good point. In WROVER version, GPIO0 serves as EMAC clock. Refer to the picture that is an excerpt from the schematic:

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

mikkle, 2023-05-31:
Thanks very much!

By that except of the schematic, is GPIO33 safe to use on the WROVER, or will it potentially interfere with the PSRAM SPI on GPIO16?

Cheers
Mikkle

DanKoloff, 2023-06-01:
Since the WROVER board has no GPIO16, we connect GPIO33 on its place. GPIO33 can be used for all purposes but it would be routed to the UEXT (this is done so when we use WROVER, there is no free pin on the UEXT).

mikkle, 2023-06-01:
Ah, thanks, got it, and just tested that indeed, that "GPIO16" on both UEXT and EXT2 are connected to and driven from GPIO33.
Thanks again!

Closed 2023-06-01.

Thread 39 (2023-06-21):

Do these boards use the ethernet for network too?

buzurk26, 2023-06-21:
Hi

Looking at these boards for home automation and want hard wired where possible, I have a PoE switch already

Do these boards also communicate over the ethernet port to your network or are yous till required to joint he esp32 module to your WIFI?

Do these support running ESPHome??

DanKoloff, 2023-06-21:
> Do these boards also communicate over the ethernet port to your network or are yous till required to joint he esp32 module to your WIFI?

I don't understand this question. Please paraphrase. Are you asking of Ethernet and WIFI can work simultaneously?

> Do these support running ESPHome??

A lot of customers have reported success in using ESP32-POE with esphome. Just Google "ESP32-POE esphome" and check the results for customer feedback.

woodenplastic, 2023-07-05:
Hi, when i try the examples i cant get a ethernet connection. Wifi works, POE aswell. There seeems to be an issue Dan. Can you please tell me how to give you information?

DanKoloff, 2023-07-06:
@woodenplastic Which Olimex ESP32 board exactly do you own? ESP32-POE?

woodenplastic, 2023-07-06:
ESP32-POE-ISO-EA-IND is the name, but i couldnt find the revision.

woodenplastic, 2023-07-06:
digging through some forums i found this solution:
when using the arduino IDE you have to change your example posted here.
all SYSTEM_EVENT_ETH... commands have to be changed to ARDUINO_EVENT_ETH....
then everything works. why that is i dont know. maybe you could make the examples clearer for beginners like me.

DanKoloff, 2023-07-06:
The ETH_LAN8720 example code from Arduino IDE works just fine with ESP32-POE-ISO board and should be used as starting point. No need of any changes.

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

Make sure you have selected Olimex ESP32-POE-ISO from the board selector.

If the issue remains with same code and settings, then probably the issue is somewhere in your network equipment or settings (like bad LAN cable, no DHCP enabled, router filtering or blocking the board, etc).

B48D81EFCC, 2023-07-30:
> Do these support running ESPHome??

Hi,

I am using several ESP-POE and ESP-POE-ISO modules exclusively with esphome.
I use the RJ45 for the network connection (and power supply of course). I disabled Wifi.
The modules are running 24/7. No issues so far.

thermseekr, 2023-08-10:
Take a look at the Tasmota project here on Guthub. It is an open source firmware to the ESP8266 and ESP32. I think it will do basically everything you need regarding home automation. And there is a template to enable the ethernet port on the ESP32-POE and -POE-ISO.

https://github.com/arendst/Tasmota

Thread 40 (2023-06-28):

Private DNS Zone

podexperfectussum, 2023-06-28:
Hello,

I am testing the ESP32-POE-ISO using the [suggested ethernet example](https://www.olimex.com/Products/IoT/ESP32/_resources/Arudino-ESP32.txt).  As long as the "host" I send to testClient is a public FQDN (ends in .com, .org, or .net), it works.  If I use an internal lan FQDN (*.local, *.lan), it does not.  Is this expected behavior?

DanKoloff, 2023-06-28:
As you can see from the instructions, we just point people on how to install official ESP32 support for Arduino and use default Ethernet example. Consider asking the ESP32 Arduino community about that, maybe it is something well known. Also quick google returns:

https://forum.arduino.cc/t/arduino-local-doesnt-work/184371/19

https://forum.arduino.cc/t/not-able-to-connect-arduino-to-localhost/664556/2

podexperfectussum, 2023-06-28:
Thanks, I'll find somewhere to ask questions.

I saw those yesterday when I was using other search engines for a couple of hours. Neither of those is applicable here though, they're trying to find their Arduino on the network from other things where as I'm trying to find things on the network from the esp32-poe-iso running Arduino.  So, the opposite.

podexperfectussum, 2023-06-28:
Thanks, I'll find somewhere to ask questions.

I saw those yesterday when I was using other search engines for a couple of hours. Neither of those is applicable here though, they're trying to find their Arduino on the network from other things where as I'm trying to find things on the network from the esp32-poe-iso running Arduino. So, the opposite.

Closed 2023-06-28.

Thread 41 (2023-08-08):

R-DET and UVLO voltage divider

thermseekr, 2023-08-08:
Hello,

First of all, thank you very much for making your design open source. It helped me a lot to understand how to design and build ethernet and PoE around the ESP32. I have sucessfully designed and built a board with ethernet and 16 inputs/16 outputs using MCP23017 expanders, and now I'm working on a version with PoE supply. I have a doubt about the resistor choice for R-DET on the TPS2376 that I would like to ask you about.

The IEEE 802.3af/at standards state that the allowed range for R-DET is 23,75k to 26,25k. For most applications a 24,9k resistor is recommended, and this is what we see on ESP32-POE.

Now considering the UVLO voltage divider: the voltage at the UVLO pin should be 2,5V when VDD is at the desired turn on voltage. On the ESP32-POE there is a 130k/10k divider. Calculating for 2,5V on the tap we find that the voltage at VDD will be 35V, which is OK considering the 42V maximum turn  on voltage and 30V minimum turn off voltages.

The problem is that according to the TPS datasheet, the total resistance of the voltage divider (140k) will appear in parallel with R-DET (24,9k), bringing the resulting value of R-DET down to 21,14k which is below the minimum allowed value. Is there any standard detail or design consideration that I'm missing?

Thanks
Tales

thermseekr, 2023-08-08:
If you check TI's SLVU188 Reference Design, it uses 909k/61.9k for the voltage divider at UVLO, and 25.5k at R-DET, which combined gives a 24847R resistor at R-DET. It makes sense.

DanKoloff, 2023-08-21:
Thanks for questions and the feedback. Was there any issue with the original values that you noticed or is it theoretical question?

I think the discrepancy in values came from the fact that we originally used TPS2375 but it was unavailable for purchase for some time and that resistor divider stayed the same when we purchased TPS2376.I believe we used values suggested in SLVU108.

We will look into the values for next hardware revision, but not sure whether we stock TPS2375 or TPS2376 (if we are back to TPS2375 the values would have to stay as they are). I am forwarding this to the hardware team.

thermseekr, 2023-08-21:
My boards are from an older revision and I probably have the TPS2375. So no issues here.

I upgraded a 16in/16out board that I use internally at work to include the ESP32 onboard and I used your design as reference for power and ethernet, that's how I noticed the discrepancy.

You can set the resistor values for UVLO divider and RDET in such a way that the TPS2376 will behave exactly like the TPS2375, compliant to the IEEE standards. The values are in the datasheet, I can't check them now but they're easy to find.

Thanks for replying! Cheers!

DanKoloff, 2023-10-17:
It seems like this issue was resolved, closing.

Closed 2023-10-17.

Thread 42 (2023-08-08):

External power sense exceeds analogue voltage max

CZEMacLeod, 2023-08-08:
Looking at R4/R9 voltage divider taking the +5V nominal supply voltage (which might be slightly over depending on the power source), it would appear that the input voltage on GPI39 would be 3.4V. While this might not technically damage the chip (I believe the IO pins are rated up to 3.6V) this still means that we can't see full scale voltages and any potential brown out on the 5V rail.

The battery has R22/R17 of 470k/470k for a ~4.2V max input giving ~2.1V or 63% of full scale. This actually seems kind of low, unless the charge voltage is significantly higher... Perhaps 330k/470k might be a better choice. This would give ~2.5V at full charge and be 75% of full-scale giving a slightly better resolution.
This would also be a good choice for the R4/R9 pair to give ~2.94V for a 5V input at 89% full-scale.

I don't know if there are any other reasons behind these choices, but it feels like this is a mistake.

DanKoloff, 2023-08-21:
We reviewed your input and we can't find mistakes here.

R4/R9 is for detection presence of external power supply via digital input, not to measure it.

R22/R17 is always connected to the battery and should be higher impedance so the battery won't discharge via it. You have enough scale to measure it.

CZEMacLeod, 2023-08-21:
@DanKoloff R4/R9 can still apply a voltage of 3.4V to a 3.3V input using 47k/100k assuming 5V is 5V. Is the drop across D1 or FET1 sufficient to prevent this? What happens if 5V is fed in externally through EXT1?

DanKoloff, 2023-08-22:
No problem to provide 5V on EXT1 as long as you don't have USB attached at the same time. 3.4V is not a problem for the ESP32.

Closed 2023-08-22.

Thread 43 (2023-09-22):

Capacitors in revision L are too high

fredlcore, 2023-09-22:
Hi,
my BSB-LAN board (https://github.com/fredlcore/BSB-LAN/blob/master/BSB_LAN/schematics/Logic%20Level%20Adapter.jpg) is no longer fitting nicely on a revision L board because the two capacitors right next to the UEXT connector are too high, see attached image.
Could you adjust this in the next revision because it fit perfectly fine before and I assume that other UEXT boards that plug right in will be affected, too?
Thanks
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

DanKoloff, 2023-09-25:
Which revision did you use previously? Not sure if it would be possible to alter the design, I suspect that these capacitors were introduced when we migrated to the Texas PoE chip. Previously it was possible to place them sideways but now there is no space left. As a workaround use a cable between the ESP32-PoE and your board or think of a spacer of two connectors (male-female) to place in-between.

fredlcore, 2023-09-25:
Thanks for getting back to me. I think the previous revision was "K". In which revision was the Texas PoE introduced?
A cable would not be ideal because you'd then have to fixate the board in some other way. Now our project offers users the STL of a 3D printed case where everything just fits.
As for the spacer, do you have an image on how that would look like?
I assume that other projects will be affected by this as well, so maybe it's worth to look into it in terms of alternative board population or something like that because just plugging a daughter-board into the UEXT connector was always an advantage compared to other microcontrollers.

DanKoloff, 2023-09-25:
I think your older boards were older than revision G. I compared revisions older than G and newer ones and I understand the problem. Previously we bent the two capacitors so that they were placed side ways on top of the PCB. We don't do that anymore and keep them straight up. Both ways have their advantages and disadvantages. But advantages of having them up exceeded those of having them bent. I guess the advantage of having them sideways was the better access to the UEXT connector and the disadvantages were too many - harder to solder (had to be soldered on top); lack of uniformity between different boards (some are bent slightly right, other slightly left); possible reliability issues with the capacitor bent on top of a DCDC converter that heats up (electrolytic capacitors might dry up faster when placed on top of that hot convertor); it takes more time to manufacture.

We will have to discuss it again if we want bent capacitors back in a newer revision and when there is a decision I'd let you know.

fredlcore, 2023-09-25:
Thank you. I understand that this was most likely not an easy decision, but if you keep the accessibility of the UEXT connector in mind, I'm sure you will find the overall best solution. Thank you.

DanKoloff, 2023-09-27:
Hello,

After reviewing this change the team design team decided to not revert this change. The capacitors would be placed the current way. Sorry for the inconvenience and compatibility issues caused, but reliability of the board had been deemed more important.

The ways to circumvent this change are:

- alter your design and use higher connector (there are taller 10-pin female connectors) compared to the one you used
- create a spacer from female and male connectors soldered back to back
- use a cable
- trim the size of the PCB or mill the edge (if possible)

Best regards,
Lub/OLIMEX

fredlcore, 2023-09-27:
Thank you for getting back to me. I can understand the reasons, but such changes are nevertheless disappointing when they happen without advance notive. If you have a significant amount of boards prepared where your customers have to tell you that they no longer fit, then that is not the most reliable choice for a microcontroller. Maybe something to keep in mind for future changes that break especially hardware compatibility.

DanKoloff, 2023-12-12:
I've forwarded the suggestion to the team and they concluded moving the UEXT would create even more compatibility issues for other customers that used it. Again sorry for this change but it was necessary for reliability and safety of the board and the products it gets embedded into.

fredlcore, 2023-12-12:
Ok, understood, thanks for checking.

Closed 2023-09-25.

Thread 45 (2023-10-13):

WifiEvent not being fired in sample code

bergerb-com, 2023-10-13:
https://github.com/OLIMEX/ESP32-POE/blob/master/SOFTWARE/ARDUINO/ESP32_PoE_Ethernet_Arduino/ESP32_PoE_Ethernet_Arduino.ino

I had to change all the SYSTEM_EVENT_ to ARDUINO_EVENT_ to get the WiFiEvent's to work.

DanKoloff, 2023-10-18:
It doesn't happen here in our tests, we still can't figure out why it behaves differently.

Stanimir-Petev, 2023-10-18:
The examples have being updated (both ESP32_PoE_Ethernet_Arduino and ESP32_PoE_Ethernet_SD_Card_Arduino). Not sure in which version of the package but Espressif decided to change these macros and broke quite a lot of our old examples (like these). Thanks for the feedback!

Closed 2023-10-18.

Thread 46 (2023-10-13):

SD-Card "Card mount Failed!" in sample code

bergerb-com, 2023-10-13:
https://github.com/OLIMEX/ESP32-POE/blob/master/SOFTWARE/ARDUINO/ESP32_PoE_Ethernet_SD_Card_Arduino/ESP32_PoE_Ethernet_SD_Card_Arduino.ino

since the ESP32-POE has a 1-bit SD interface, would you be so kind and also include that in your sample code?

`SD_MMC.begin()`
needs to be
`SD_MMC.begin("/sdcard", true)`

without that line, the SD-Card wont mount.

DanKoloff, 2023-10-17:
We tested it here and it seems to work fine. We have to reproduce the problem first before we can apply any changes or fixes. What card are you using (size and formatting)? What is the structure on the card? Which version of ESP32 package do you use, is it the latest one?

bergerb-com, 2023-10-18:
FAT32, 64GB Card, reduced to 32GB
What do you mean by structure? There was no data on the card.
Do you mean your rev. by package? it neither works on rev. L or rev. K.
I am using PlatformIO, maybe that makes a difference?

DanKoloff, 2023-10-18:
Yeah structure meant if you have folders or files or if it is blank.

Revision package meant package revision # in Arduino IDE.

We've used Arduino IDE and this sample code was made and tested in Arduino IDE. The folder with the example is named "ARDUINO".

Maybe it is related to PlatformIO and Arduino differences indeed.

Closed 2023-11-20.

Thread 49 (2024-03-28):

Power supply via POE not stable

fredlcore, 2024-03-28:
I'm maintaining a hardware project (https://www.bsb-lan.de) where probably half of the installations run on an Olimex (either EVB or POE). About a dozen users using the Olimex ESP32-POE have now reported back to me that when they use WiFi on the Olimex, the system becomes unstable which shows in disconnects or slow WiFi connections.
The matter immediately changes when powering the Olimex via a stable USB power supply (a laptop's USB for example) and the issues are gone. Also, the matter does not seem to be noticeable if an Ethernet connection instead of WiFi is used.

I have also created an issue in the Olimex EVB section, feel free to close one of them if that is better for your workflow.

For the time being, we will add a recommendation to only power the Olimex via a reliable USB power supply, but since POE powering is often a specific demand by our users, I wanted to let you know about this problem, so that hopefully you can fix it in the next hardware revision.

thermseekr, 2024-03-29:
This is very odd. I'll be following out of curiosity. I developed an ESP32 based system and I used Olimex ESP32-POE as one of the hardware references so I studied the circuit a lot. As far as I could see the PoE power supply is pretty standard, nothing weird in it. I haven't studied a lot the isolated version tho.

Also, I'm curious as for why someone would connect PoE and use WiFi. Since you already have an Ethernet cable connected, why not use it also for data? Is it only an analog 24/48V power connection? Or do you need two different IP addresses?

Cheers.
Tales.

fredlcore, 2024-03-29:
You're right, it doesn't really make sense to have WiFi running on the POE, and I would have to check if they actually did run the system on WiFi (which, in my project, makes sense because it sets up an AP so you can configure it through via WiFi).
I mentioned WiFi because on the EVB this was the most obvious proof for the instability of the system, but it was not limited to that. On both boards, however, the problems ceased once it was powered by a reliable USB power supply. If the power supply was cheap (despite high ampere ratings), it could still result in the same instabilities as when powered via barrel connector or POE.

fredlcore, 2024-10-18:
Most likely the reason for this issue is the same as @DanKoloff explained [here](https://github.com/OLIMEX/ESP32-EVB/issues/57#issuecomment-2162757027).

fredlcore, 2025-03-12:
Just FYI for everyone who is getting here via Google: We came to a conclusion [in this thread](https://github.com/fredlcore/BSB-LAN/issues/715#issuecomment-2716701711) that the corrupted data can be taken care of if the data stream has some form of checksum in place, as at least 97% of the data transmitted in the test scenario is not affected. For those setups that rely on accurately receiving via GPIO36 (and maybe other GPIOs as well), these should not power their Olimex via PoE or barrel power plug.

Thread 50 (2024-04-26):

LAN8710A Ethernet Transceiver getting into weird state

JwAtTEC, 2024-04-26:
We have several of the ESP32-POE-ISO board in the field operated 24/7 on a POE network.  We have had a few instances where the device has stopped sending data to the server.  Without physical access to the device it is difficult to diagnose, but if the POE on the port is cycled, the device starts up properly again.

We recently got one of the boards back and have had it running internally.  When we reset the server, one of the boards showed a weird state where the  Link (LNK1) and activity (ACT1) LEDs were both steadily blinking at about a 1 second on/off cycle.  This seems like an error condition of the transceiver.  Probing the IC we could see that the ESP32 was still sending data to the transceiver but it was not getting transmitted to the LAN.  When we reset the transceiver by bringing NRST to ground temporarily, the transceiver started transmitting again and returned to normal operation.

Upon examining the circuitry at pin 19 NRST, there is a 10K resistor to _3.3VLAN and a 10uF Cap that is not installed (physically and per the schematic).  Section 3.8.5.1 of the datasheet calls out "A hardware reset (nRST assertion) is required following power-up" which, I assume, is why the 10uF cap was part of the design.  However, we aren't seeing issues on power up, so that's likely not an issue.

My questions are:  1.  Can anyone think of why the transceiver might get into this odd state,, and 2. Is there a software method from the ESP32 to correct?   Right now we are contemplating using GPIO32 to tie to the NRST line to instigate a reset when we are failing to get acknowledgments on our transmits.  Appreciate any feedback!

DanKoloff, 2024-04-27:
What Kv603 wrote - there is already PHY_PWR pin which is GPIO12 and it can be used to toggle just PHY power. This is a workaround of course. If you are looking for reasons why Ethernet might hang, it is often this (especially if you are using custom software and libraries):

"A Hardware reset is asserted by driving the nRST input pin low. When driven, nRST should be held low for the minimum
time detailed in Section 5.5.3, "Power-On nRST & Configuration Strap Timing," on page 59 to ensure a proper transceiver reset. During a Hardware reset, an external clock must be supplied to the XTAL1/CLKIN signal."

If you've held the main ESP32 chip powered down, you need to delay LAN8710A chip power up until the PHY clock is available, else it might hang. This is done by GPIO12 usually in the software, enabling the LAN few moments after ESP32 gets powered.

The reason why one out of many boards behaves differently is usually some hardware damage on LAN8710A chip. It can occur due to many reasons like grounds loops or from malfunctioning uninsulated POE switch/splitter, bare-hand handling, ESD, etc.

JwAtTEC, 2024-04-29:
Thanks everyone for your helpful inputs.  I had overlooked the PHY_PWR pin so that's the direction we will investigate.  Closing this issue as resolved.

Closed 2024-04-29.

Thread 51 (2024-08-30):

çeviri

prensmiskin, 2024-08-30:

DanKoloff, 2024-08-30:
I don't know what is this but will close it.

prensmiskin, 2024-08-30:
I want to buy 120 pieces of this module from Turkey. But first I need to buy 1 god and test it. If I buy 1 piece from www.olimex.com it will take more than 1 week to arrive. But I have a project to deliver. Is there anyone in Turkey who has bought the ESP32-POE board before and wants to sell it to me?

I know this is not the place for this question, but I am trying everything to find this module in Turkey. Thank you for your understanding.
[
](https://www.olimex.com/Products/IoT/ESP32/ESP32-POE/open-source-hardware)

Closed 2024-08-30.

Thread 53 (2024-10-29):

3D File of the entire ESP-POE

bmueller78, 2024-10-29:
Could you please upload the 3D file in STEP format of the entire ESP-POE Rev. L? Thank you very much.

DanKoloff, 2024-10-29:
You can export STEP from the KiCAD sources on your own, it is the free software we use to design these boards. Install KiCAD and download the sources from the GitHub page for ESP32-POE (better download the whole repo from this link [ESP32-POE repo](https://github.com/OLIMEX/ESP32-POE/archive/refs/heads/master.zip) ).

Extract the archive, open the project file in KiCAD, open the PCB layout editor, and click File -> Export and chose one of the formats (STEP in your case). Furthermore, there is a built-in 3D viewer in KiCAD, again open the PCB and navigate to View -> 3D Viewer.

DanKoloff, 2024-10-30:
One thing I forgot to mention is that the component heights in our designs are approximate. Length and width are exact. But always doubt the height of components, since we don't need it for manufacturing. Compare what you get from the STEP with the real board.

Closed 2025-01-21.

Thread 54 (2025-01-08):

adding wifi.h module

wolfgangsmdt, 2025-01-08:
you need to add `#include <WiFi.h>` in the [beginning here](https://github.com/OLIMEX/ESP32-POE/blob/4054ce5d80dcf66261ed52aa4d99f8d5f8ca1f5c/SOFTWARE/ARDUINO/ESP32_PoE_Ethernet_Arduino/ESP32_PoE_Ethernet_Arduino.ino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)

So the code can compile!!

DanKoloff, 2025-01-10:
Done, thanks!

Closed 2025-01-10.

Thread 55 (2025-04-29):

Why not use 3.3V PG pin as ESP_EN?

marekm72, 2025-04-29:
The simple RC delay may not reset properly for brown-outs or very short power failures (not enough time to fully discharge to 0V, possibly leading to incorrect operation).  But the 3.3V switcher (TPS62A02A) has that nice but currently unused PG pin - why not use it?  It is open drain exactly as needed, just connect it to ESP_EN and it should ensure proper reset in all conditions.

One possible reason why not - if you want the device to work on battery until completely discharged, down to UVLO at 2.3V typ, while PG reset would trigger at about 3.1V.  But it's almost discharged at that point, in this part of discharge characteristics the voltage is already falling quickly so not much run time to gain, and too deep discharge might damage the cell.  If board space permits, the connection from PG to ESP_EN could be made via a small resistor that could be desoldered if necessary.

DanKoloff, 2025-04-30:
Thanks for the suggestion, using the power good pin of TPS62A02A as an extra reset IC is a good idea. We would evaluate and test empirically if that works and will consider it for future revisions.

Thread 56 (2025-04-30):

Move MPS load to +5VP, optimize for less heat

marekm72, 2025-04-30:
Pulsed MPS with 25% duty cycle would be the best, but if that adds too much complexity - I'd suggest to move the dummy load to the 5V output side.  About 100 ohms parallel to C25 should be fine, looking at the TX4138 efficiency graphs it should sink almost constant 10 mA at the input, and if a bit too low at high voltage then add a little more switching losses by populating C26 and R43 (switching losses increase with input voltage to compensate decreasing current due to constant power).

The current way (in Rev. M - R42 and R7, two 9k1 in parallel at PoE DC/DC input) was made to sink 10 mA at the low end of the voltage range, but power loss rises with voltage squared and the high end of voltage range is the most common case (little voltage drop on the cable at light load), consumes 0.71 W at 57 V when 0.57 W (10 mA) would be enough.

If pulsed MPS is considered - it could actually be done on the secondary side too, and a SOT23-6 MCU like ATtiny4/5 or PIC10F20x could sink the requred current using all 3 of its I/O pins loaded with 3 small resistors, and generate the pulses without any external components.  As an added bonues, the loads could be switched in smaller steps at slightly different times to be nicer to the DC/DC (transient response).  The MCU could also be held in reset (using the remaining input-only pin) to disable the load if not really needed (very likely not needed if the Ethernet PHY is powered up).  This is easy with non-isolated PoE, becomes more complex in the isolated version (but then, the isolated DC/DC converter also contributes some load so the MPS load could be reduced further).

DanKoloff, 2025-04-30:
Thanks for the suggestions. Maybe I miss something but the resistor in parallel to C25 doesn't make a lot of sense since we are moving the heat over the TX4138 and the resistor after it, also there would be much less current available to the board (like 100-150mA less).

We added a second resistor to reduce the heat, it was a single resistor before, we'd probably wait for some customer feedback before doing any changes.

marekm72, 2025-04-30:
Another optimization could be to enable the extra load only when the PHY is powered down - then the current available to the board would not be reduced.  Much (if not all - this would need to be measured) of the MPS required minimum power is already consumed by the Ethernet PHY.  Probably the simplest way could be with N-FET switch, gate controlled from T1 collector, drain via load resistor to +5VP (only powered from PoE, not USB or battery).

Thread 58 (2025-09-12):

ESP32_PoE_Ethernet_IDFv5.3 missing all customization to make it work with Olimex ESP32-POE board

hachi, 2025-09-12:
This example appears to be a verbatim copy of the ESP-IDF generic example, it defaults to the wrong PHY, it has several models of PHY in the code that are not the one documented by Olimex to be the one on the board.

The section in the manual specifically says:

> It is probably because your software didn’t utilize the PHY_PWR pin (GPIO12) properly. This
behavior happens when the PHY controller (LAN8720) gets powered before the ESP32 module
can generate the PHY clock. What your software should do is hold the LAN8720 in reset for few
milliseconds via the PHY_PWR pin and release it from reset only after PHY clock is already
generated by the ESP32 module. Simple software workarounds that can be tested are adding delay
before Ethernet initialization or toggling GPIO12 to reset only the Ethernet chip until connection
is restored.

There is no mention in the manual of which direction to drive GPIO12 to power on or off... whether there is pull up or down, and it's also not in this example code.

I would have expected this example to show exactly which pins, levels, chips, and addresses are correct for the Olimex ESP32-POE board, but it doesn't

Even the manual fails to address these things directly. Nowhere does the manual declare what PHY is on the board, but in passing it is mentioned to be a LAN 8710 in one section, and a LAN 8720 in another... which is it? I'm half betting that what is on the schematic is not what's on the actual board at this point.

hachi, 2025-09-13:
My application had a conflicting GPIO pin with MDC which was causing init timeout after all the code was set up. Thank you for the fast replies and support.

Closed 2025-09-13.

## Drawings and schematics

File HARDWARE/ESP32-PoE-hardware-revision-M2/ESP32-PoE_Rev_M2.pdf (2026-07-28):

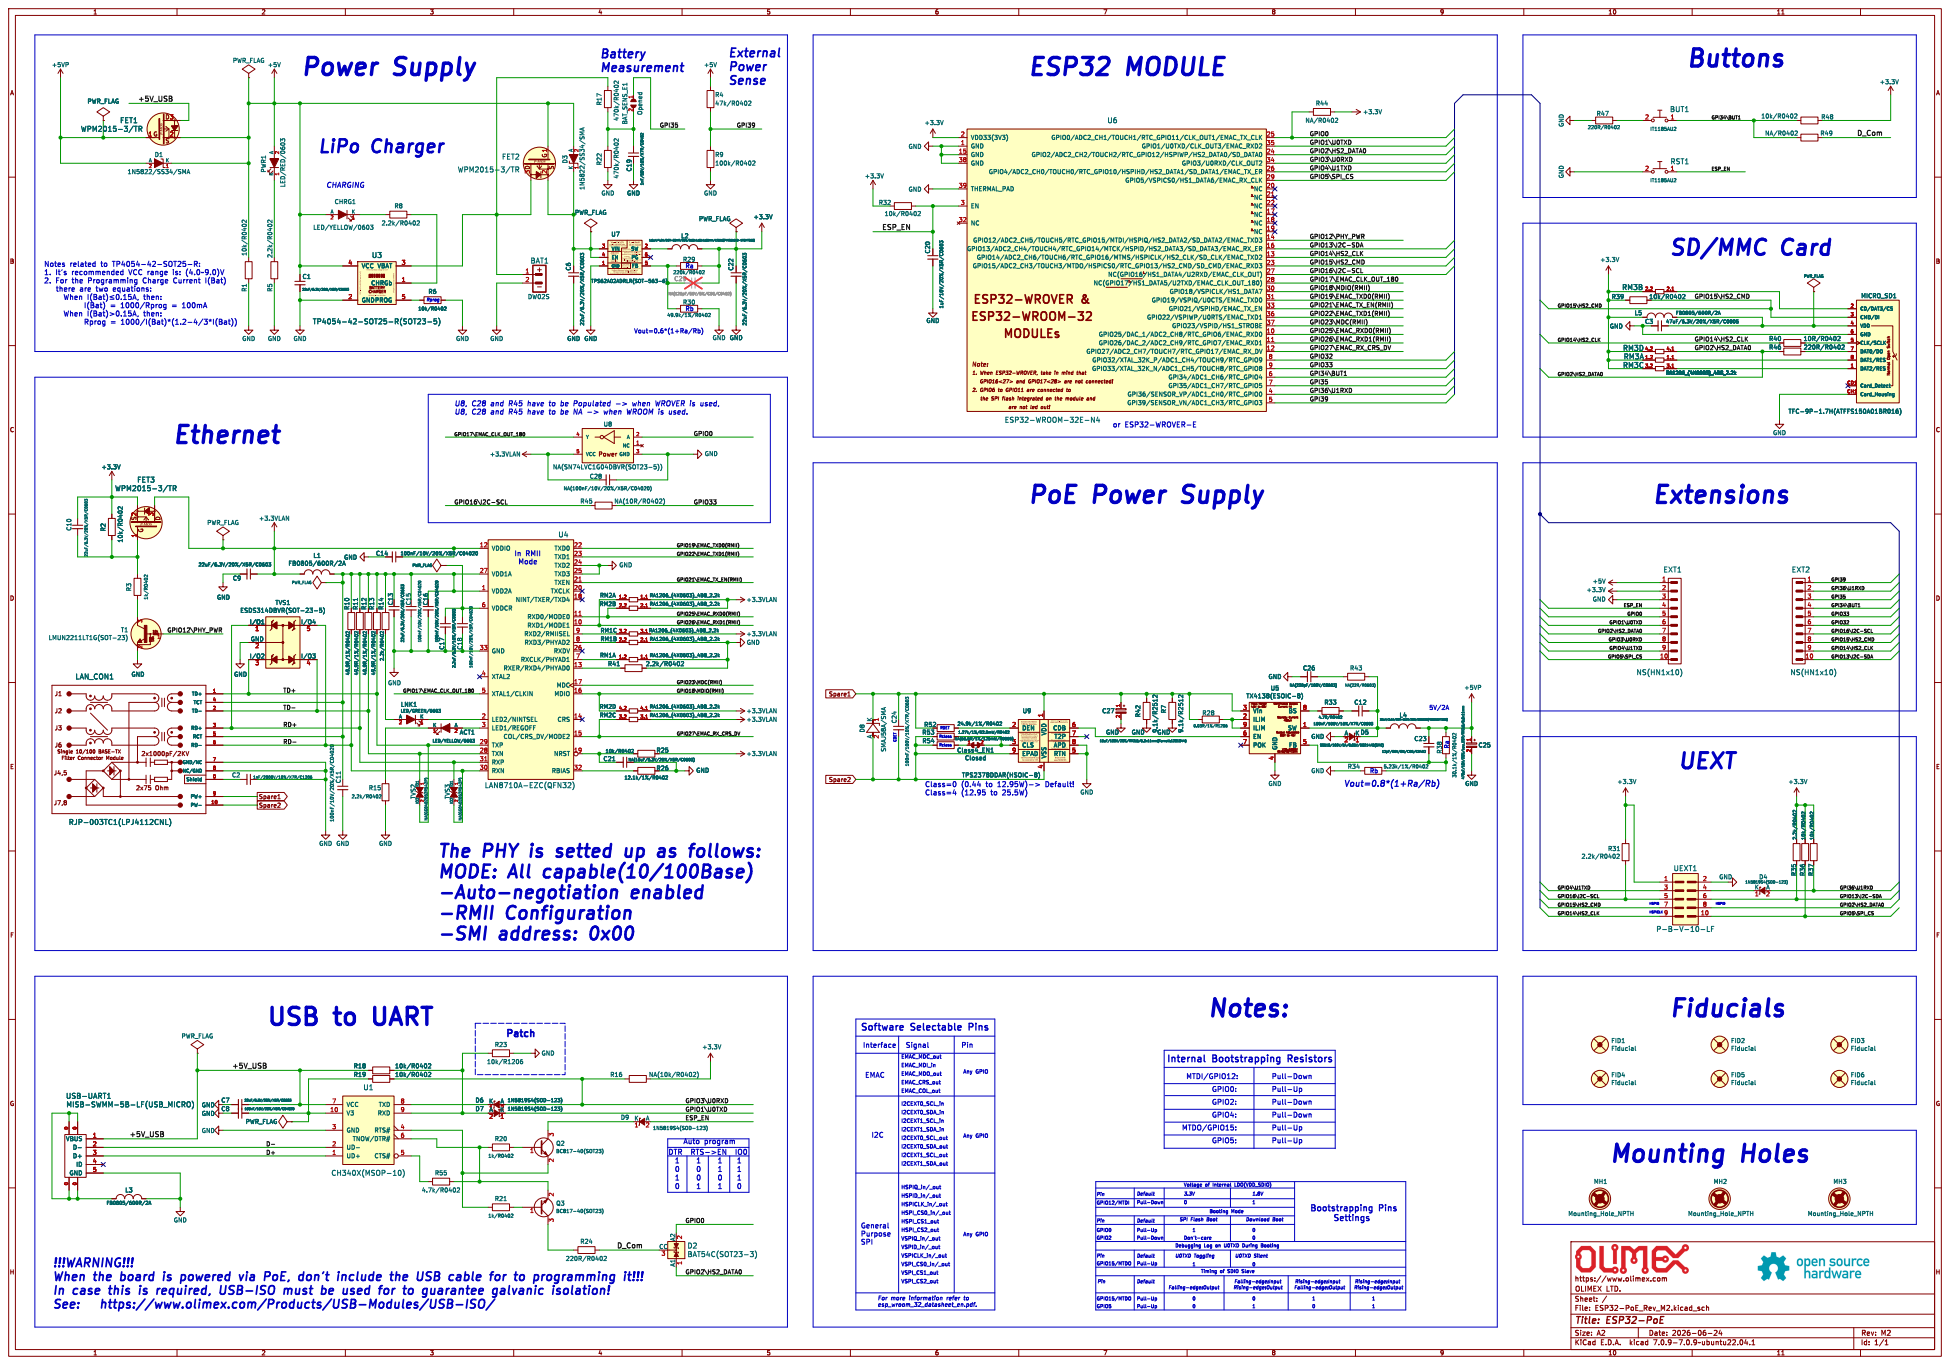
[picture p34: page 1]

2. 2. 2. 2. 2. 2. 2. GPIO6 to GPIO11 are connected to
22 GPIO15/ADC2_CH3/TOUCH3/MTDO/HSPICS0/RTC_GPIO13/HS2_CMD/SD_CMD/EMAC_RXD3

Cout=(10~22)uF/6.3V/X5Rþÿ(Vout"e1.8V). 22uFRecommended! Cout=22uF/6.3V/X5Rþÿ(1.2V"dVout<1.8V) Cout=44uF/6.3V/X5Rþÿ(0.6V"dVout<1.2V) DCR<50mR

In casea loweroutputrippleisdesired,higheroutputcapacitancecanhelpreducetheripple. Lx=1.0uH

Donotfloat. Enablecontrol. FB Input Current,I(FB)=100nA(max) FeedbackReferenceVoltage,V(REF)=0.6V
Rb mustnotbehigherthanþÿ100k© toprovideacceptablenoisesensitivity. ShutdownCurrentI(SHDN)=0.01-2uA

Maximumoutputcurrent2.0A
Ra Vout=0.6*(1+Ra/Rb)

Notes related to TP4054-42-SOT25-R: 1. It's recommended VCC range is: (4.0~9.0)V

are not led out! ESP32-WROOM-32

HSPIQ PoE Power Supply

4 RTN 5 CDB 6 T2P 7 APD 8 EPAD 9 U9 TPS2378DDAR(HSOIC-8) R7 GND 9.1k/R2512 R42 9.1k/R25121 2 C27

AuxiliaryPowerDetect Activelowindicatestype2 Activelow,open-drainconverterdisable output,referencedtoRTN. Connect24.9þÿk©toVDD for detection. ConnectresistorfromCLS toVSStoprogram classificationcurrent.

4 RTN 5 CDB 6 T2P 7 APD 8 EPAD Class4_EN1 9 Closed

If notused,connectAPD toRTN. PSEconnectedor APD active. ThePowerPadTMmustbe connectedtoVSS.VDD

The controllerplacesa voltageof approximately 2.5Vacrosstheexternal resistorwheneverthevoltage differentialbetweenVDD andVSS liesfromabout10.9Vto22V. Drain ofPoEpass MOSFET.

0 The PHY is setted up as follows:
MODE: All capable(10/100Base)
-RMII Configuration
-SMI address: 0x00

1 Booting Mode SPI Flash Boot 3.3V MTDI/GPIO12: USB to UART

Voltage of Internal LDO(VDD_SDIO) EMAC

U0TXD Silent Debugging Log on U0TXD During Booting 1

Default Pull-Up Pull-Up Pull-Down Pin

GPIO15/MTDO !!!WARNING!!!
When the board is powered via PoE, don't include the USB cable for to programming it!!!

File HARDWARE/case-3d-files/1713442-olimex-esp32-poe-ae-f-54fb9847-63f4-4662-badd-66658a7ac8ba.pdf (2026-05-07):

## Olimex ESP32-POE-AE-F

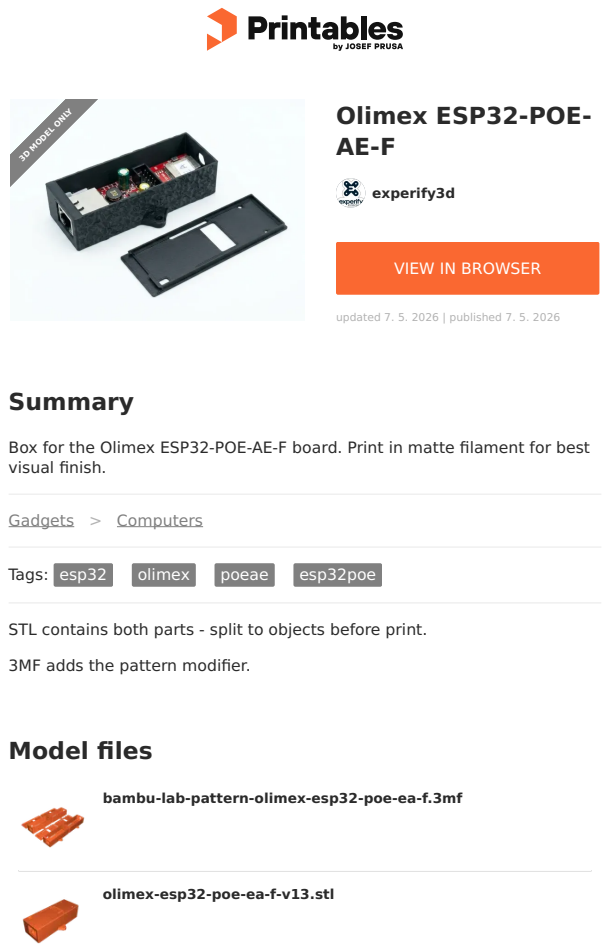
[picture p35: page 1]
Model files; Summary; Gadgets > Computers; Tags: esp32; olimex; poeae; esp32poe; experify3d; updated 7. 5. 2026 | published 7. 5. 2026; 3D MODEL ONLY

VIEW IN BROWSER (https://printables.com/model/1713442-olimex-esp32-poe-ae-f)

Box for the Olimex ESP32-POE-AE-F board. Print in matte filament for best
visual finish.

STL contains both parts - split to objects before print.

3MF adds the pattern modifier.

bambu-lab-pattern-olimex-esp32-poe-ea-f.3mf

olimex-esp32-poe-ea-f-v13.stl

## License

This work is licensed under a
Creative Commons (4.0 International License)

Attribution (http://creativecommons.org/licenses/by/4.0/)

✖ | Sharing without ATTRIBUTION
✔ | Remix Culture allowed
✔ | Commercial Use
✔ | Free Cultural Works
✔ | Meets Open Definition

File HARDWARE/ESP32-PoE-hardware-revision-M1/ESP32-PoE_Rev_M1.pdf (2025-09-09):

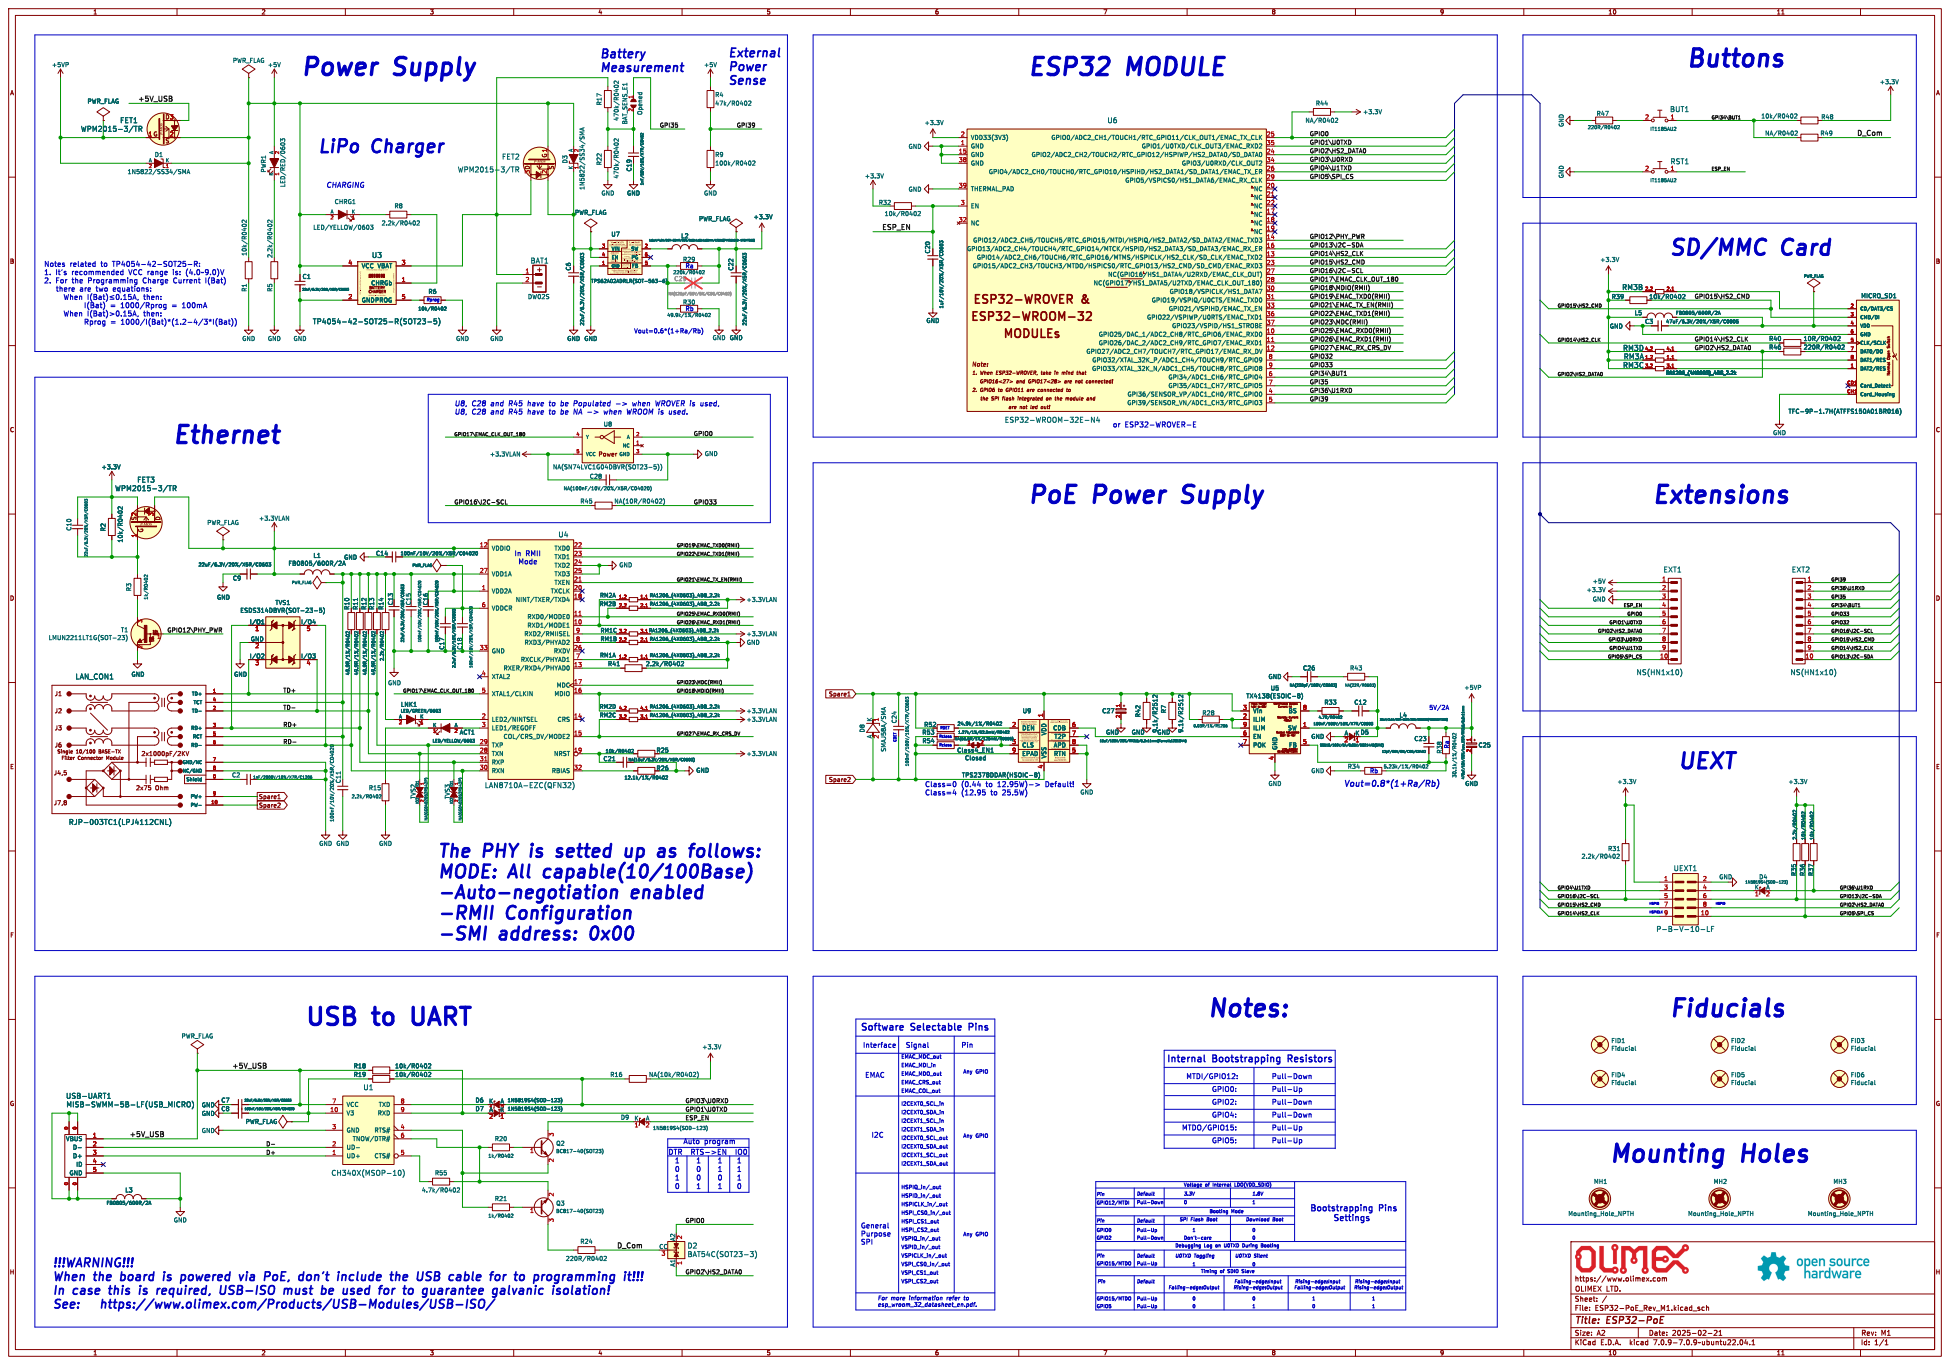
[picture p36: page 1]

GPIO18\MDIO(RMII) GPIO16\I2C-SCL GPIO0 GPIO32 GPI34\BUT1 GPI36\U1RXD GPIO23\MDC(RMII) GPIO33 GPI35 GPI39 GPIO21\EMAC_TX_EN(RMII)
GPIO2\HS2_DATA0 GPIO4\U1TXD GPIO3\U0RXD GPIO1\U0TXD GPIO15\HS2_CMD GPIO12\PHY_PWR GPIO5\SPI_CS GPIO13\I2C-SDA GPIO14\HS2_CLK

2 PWR1 LED/RED/0603 R1 10k/R0402 GND R5 2.2k/R0402 GND

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

In casea loweroutputrippleisdesired,higheroutputcapacitancecanhelpreducetheripple. Lx=1.0uH

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

Maximumoutputcurrent2.0A
Ra Vout=0.6*(1+Ra/Rb)

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

Rb USB to UART

are not led out! ESP32-WROOM-32

4 RTN 5 CDB 6 T2P 7 APD 8 EPAD 9 R52 24.9k/1%/R0402 R53 1.27k/1%/62.5mW/R0402 R54 NA(66.5R/1%/125mW/R0805) C14 100nF/10V/20%/X5R/C04020

4 RTN 5 CDB 6 T2P 7 APD 8 EPAD 9 U9 TPS2378DDAR(HSOIC-8) 1 2 Class4_EN1 Closed GND GND

AuxiliaryPowerDetect Activelowindicatestype2 Activelow,open-drainconverterdisable output,referencedtoRTN. Connect24.9þÿk©toVDD for detection. ConnectresistorfromCLS toVSStoprogram classificationcurrent.

If notused,connectAPD toRTN. PSEconnectedor APD active. ThePowerPadTMmustbe connectedtoVSS.VDD

The controllerplacesa voltageof approximately 2.5Vacrosstheexternal resistorwheneverthevoltage differentialbetweenVDD andVSS liesfromabout10.9Vto22V. Drain ofPoEpass MOSFET.

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

MISB-SWMM-5B-LF(USB_MICRO)GND

Pull-Up Pull-Down Pull-Up

Voltage of Internal LDO(VDD_SDIO) 1.8V

0 Rising-edge:Input Any GPIO

0 Debugging Log on U0TXD During Booting U0TXD Silent

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

Rising-edge:Output 1 Falling-edge:Input

Rising-edge:Output Rising-edge:Input

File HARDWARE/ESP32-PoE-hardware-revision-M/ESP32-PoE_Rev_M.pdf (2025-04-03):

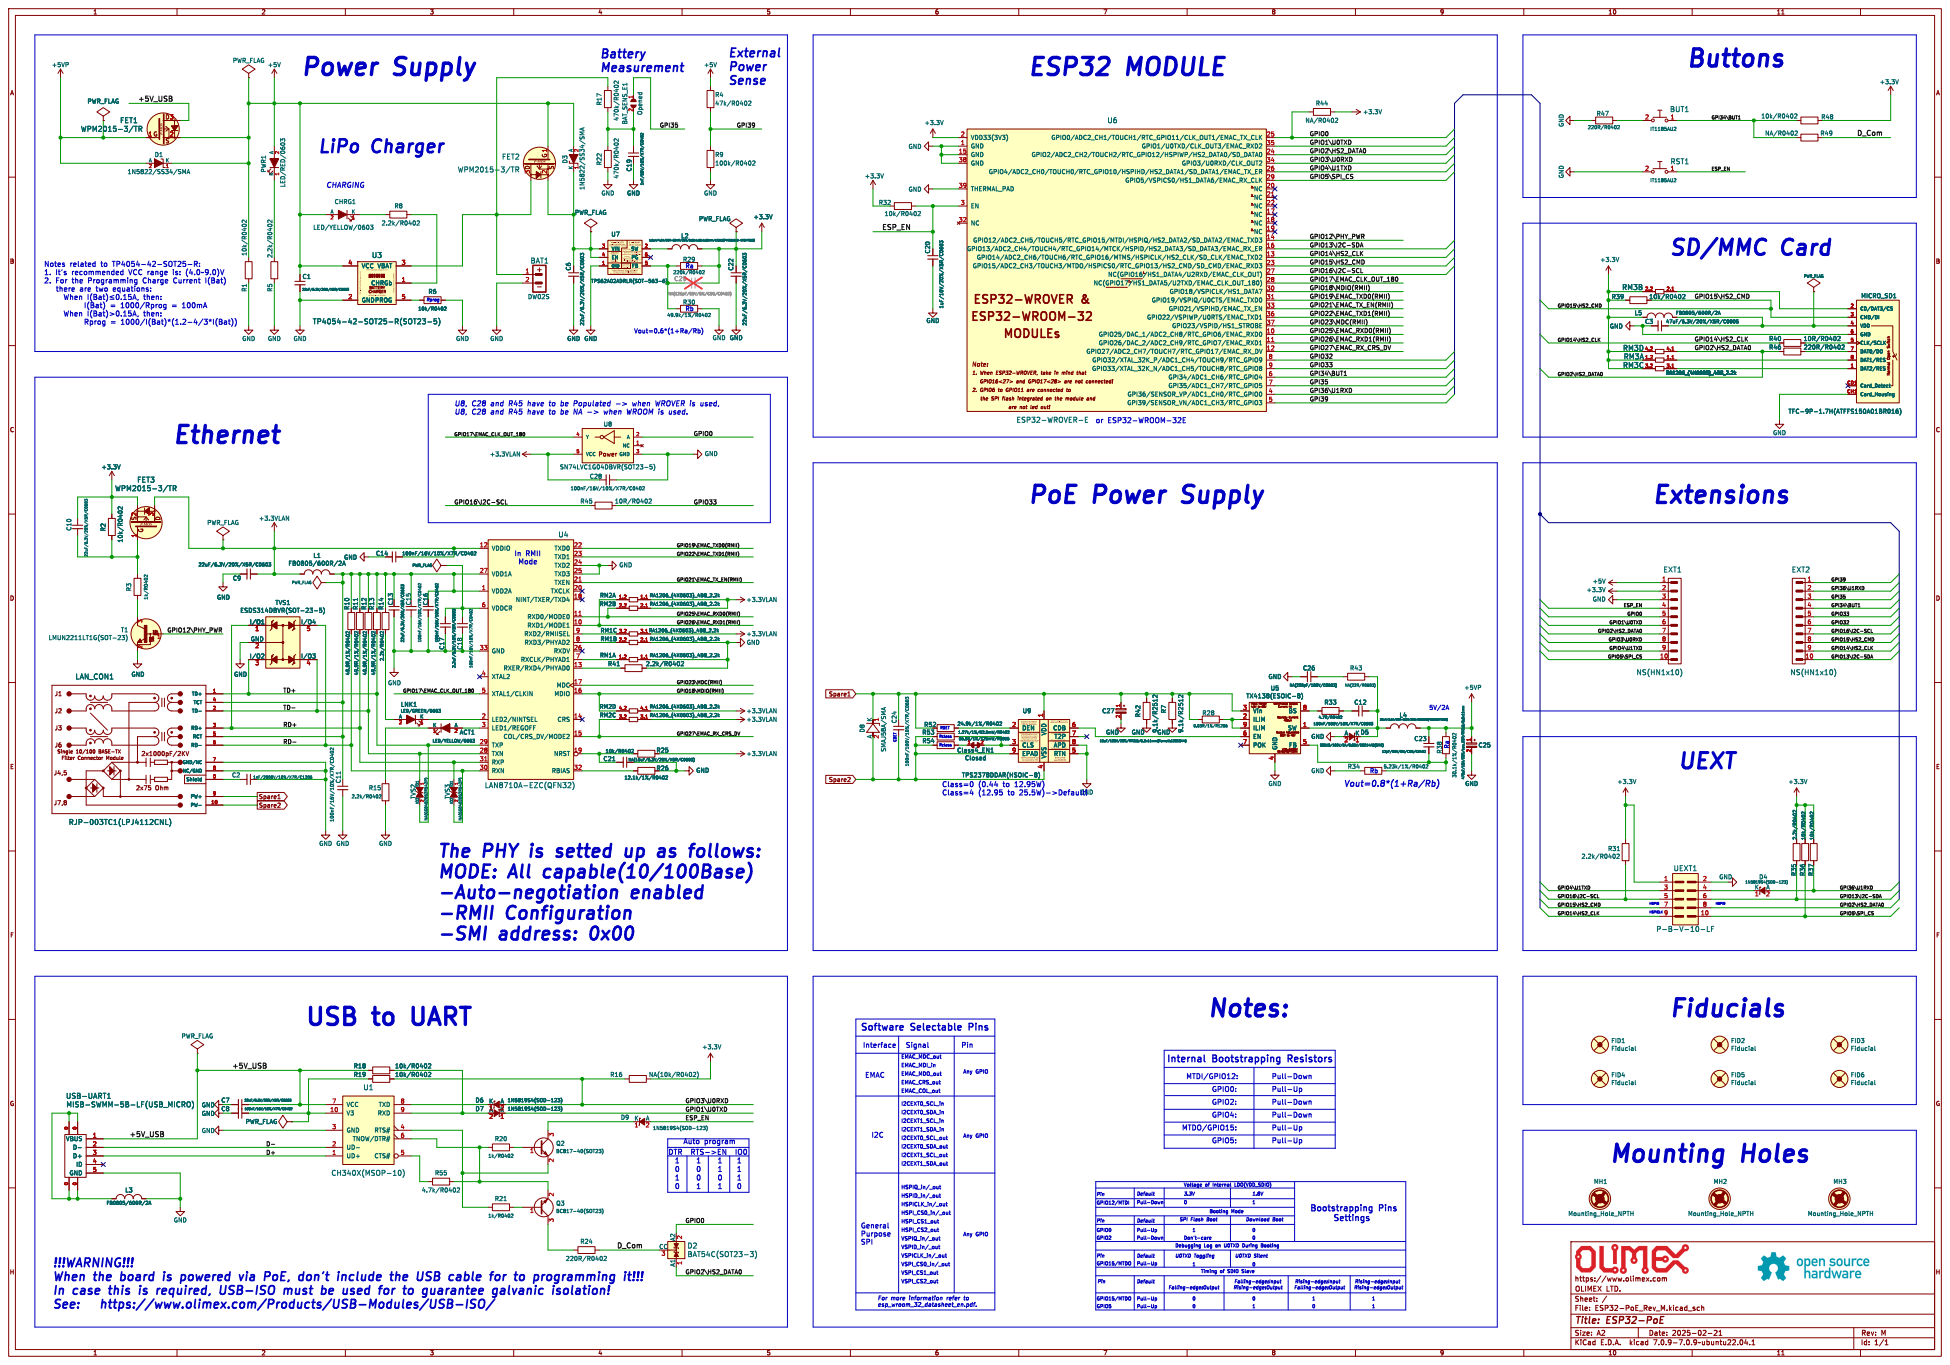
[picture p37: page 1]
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

In casea loweroutputrippleisdesired,higheroutputcapacitancecanhelpreducetheripple. Lx=1.0uH

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

are not led out! ESP32-WROOM-32

2 GND 3 Y
GPIO23\MDC(RMII) GPIO26\EMAC_RXD1(RMII) GPIO21\EMAC_TX_EN(RMII) GPIO19\EMAC_TXD0(RMII) GPIO22\EMAC_TXD1(RMII)

4 RTN 5 CDB 6 T2P 7 APD 8 EPAD 9 U9 TPS2378DDAR(HSOIC-8) Filter Connector Module Single 10/100 BASE-TX 2x1000pF/2KV

AuxiliaryPowerDetect Activelowindicatestype2 Activelow,open-drainconverterdisable output,referencedtoRTN. Connect24.9þÿk©toVDD for detection. ConnectresistorfromCLS toVSStoprogram classificationcurrent.

4 RTN 5 CDB 6 T2P 7 APD 8 EPAD Class4_EN1 9 Closed

If notused,connectAPD toRTN. PSEconnectedor APD active. ThePowerPadTMmustbe connectedtoVSS.VDD

The controllerplacesa voltageof approximately 2.5Vacrosstheexternal resistorwheneverthevoltage differentialbetweenVDD andVSS liesfromabout10.9Vto22V. Drain ofPoEpass MOSFET.

Vout=0.8*(1+Ra/Rb) Rb USB to UART

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

Pull-Up Pull-Down Pull-Up

Timing of SDIO Slave GPIO12/MTDI Pin GPIO0 GPIO15/MTDO

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

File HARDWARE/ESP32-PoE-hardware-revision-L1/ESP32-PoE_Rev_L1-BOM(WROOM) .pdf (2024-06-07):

## ESP32-PoE_Rev_L1-BOM(WROOM) 06/07/2024

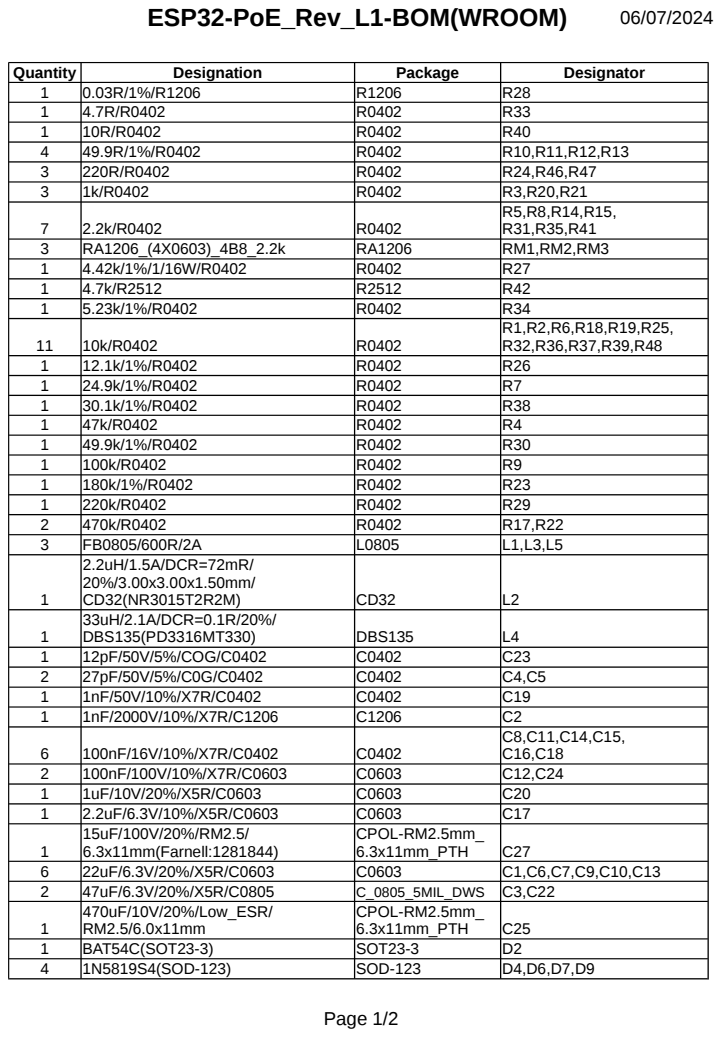
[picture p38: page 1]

## ESP32-PoE_Rev_L1-BOM(WROOM) 06/07/2024

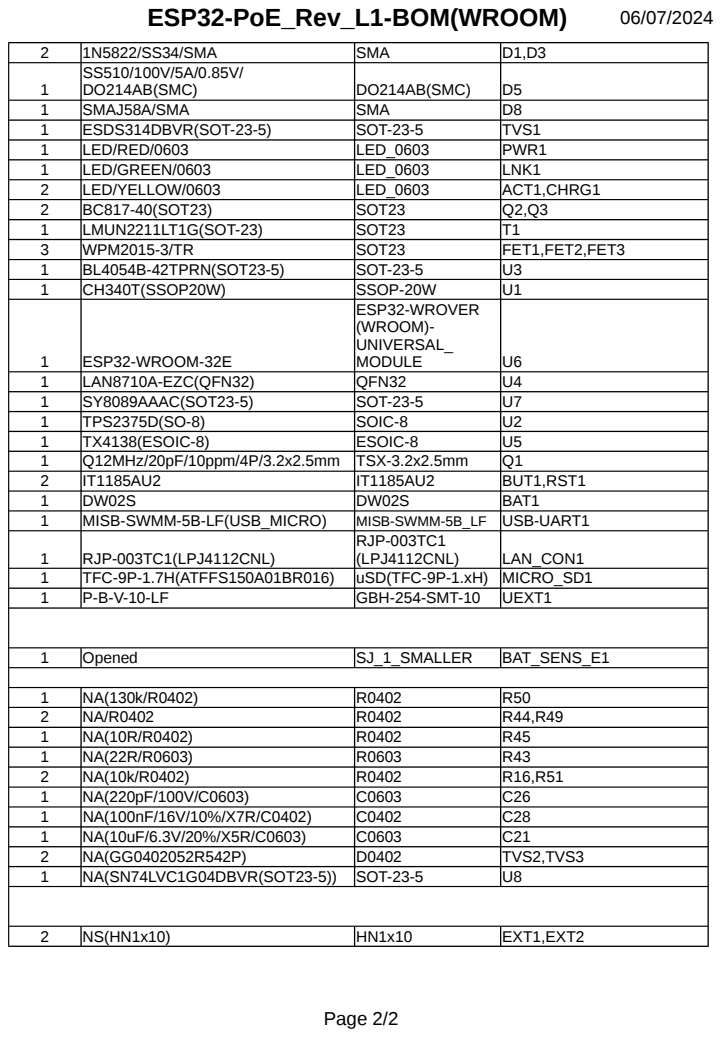
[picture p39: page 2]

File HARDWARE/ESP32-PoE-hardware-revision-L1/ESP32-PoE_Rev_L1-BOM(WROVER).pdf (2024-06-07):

## ESP32-PoE_Rev_L1-BOM(WROVER) 06/07/2024

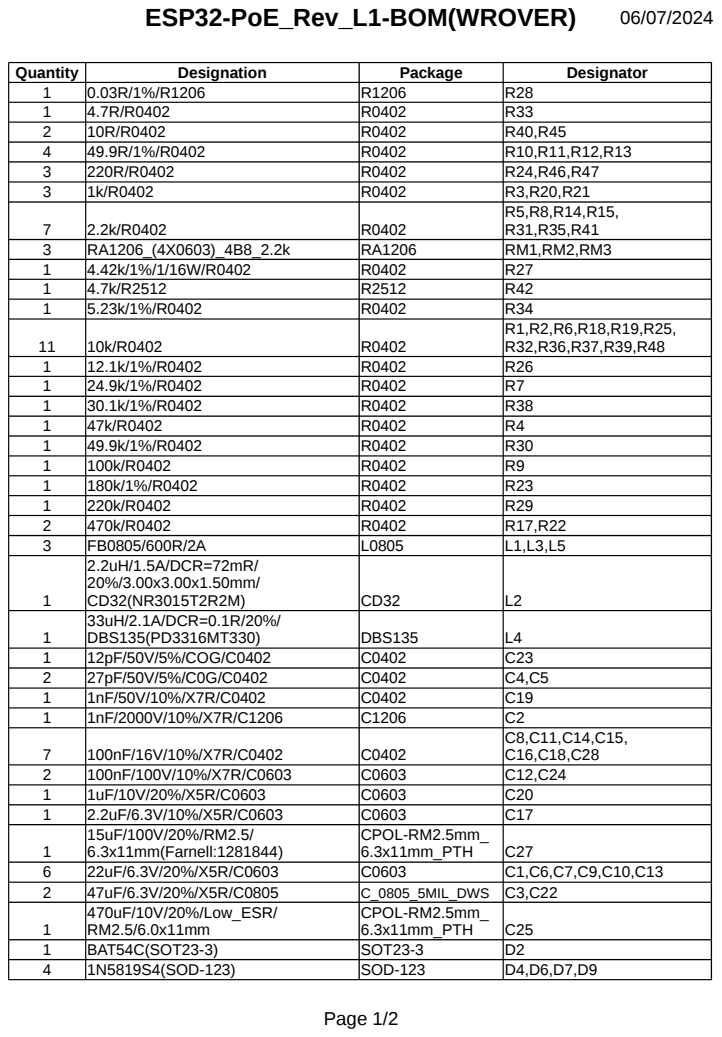
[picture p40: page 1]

## ESP32-PoE_Rev_L1-BOM(WROVER) 06/07/2024

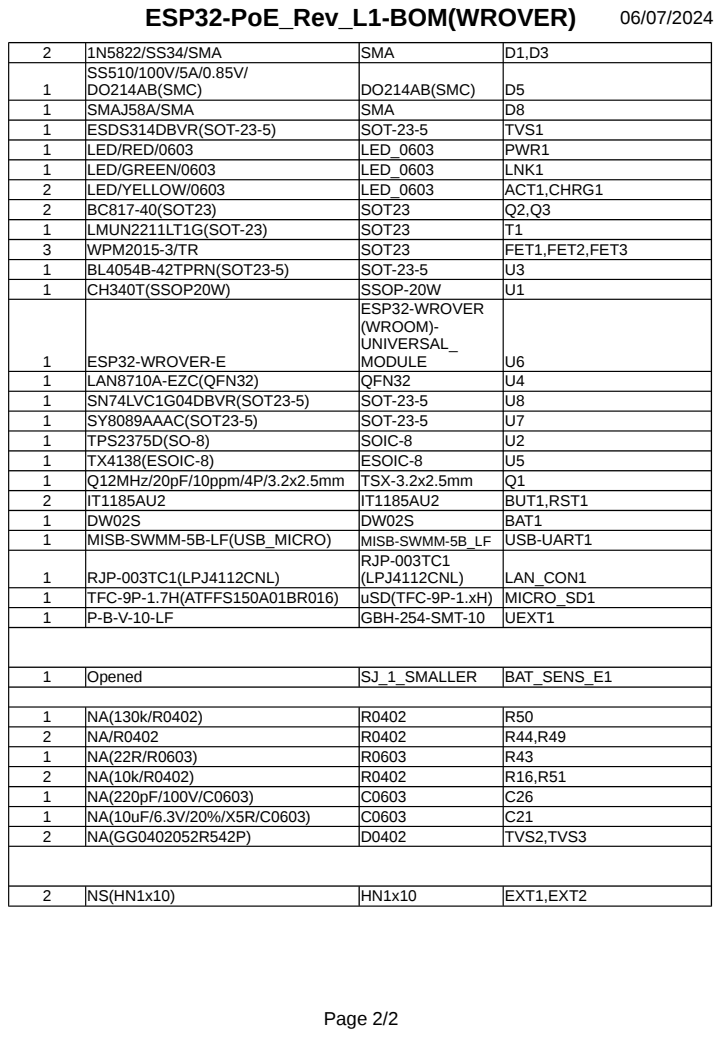
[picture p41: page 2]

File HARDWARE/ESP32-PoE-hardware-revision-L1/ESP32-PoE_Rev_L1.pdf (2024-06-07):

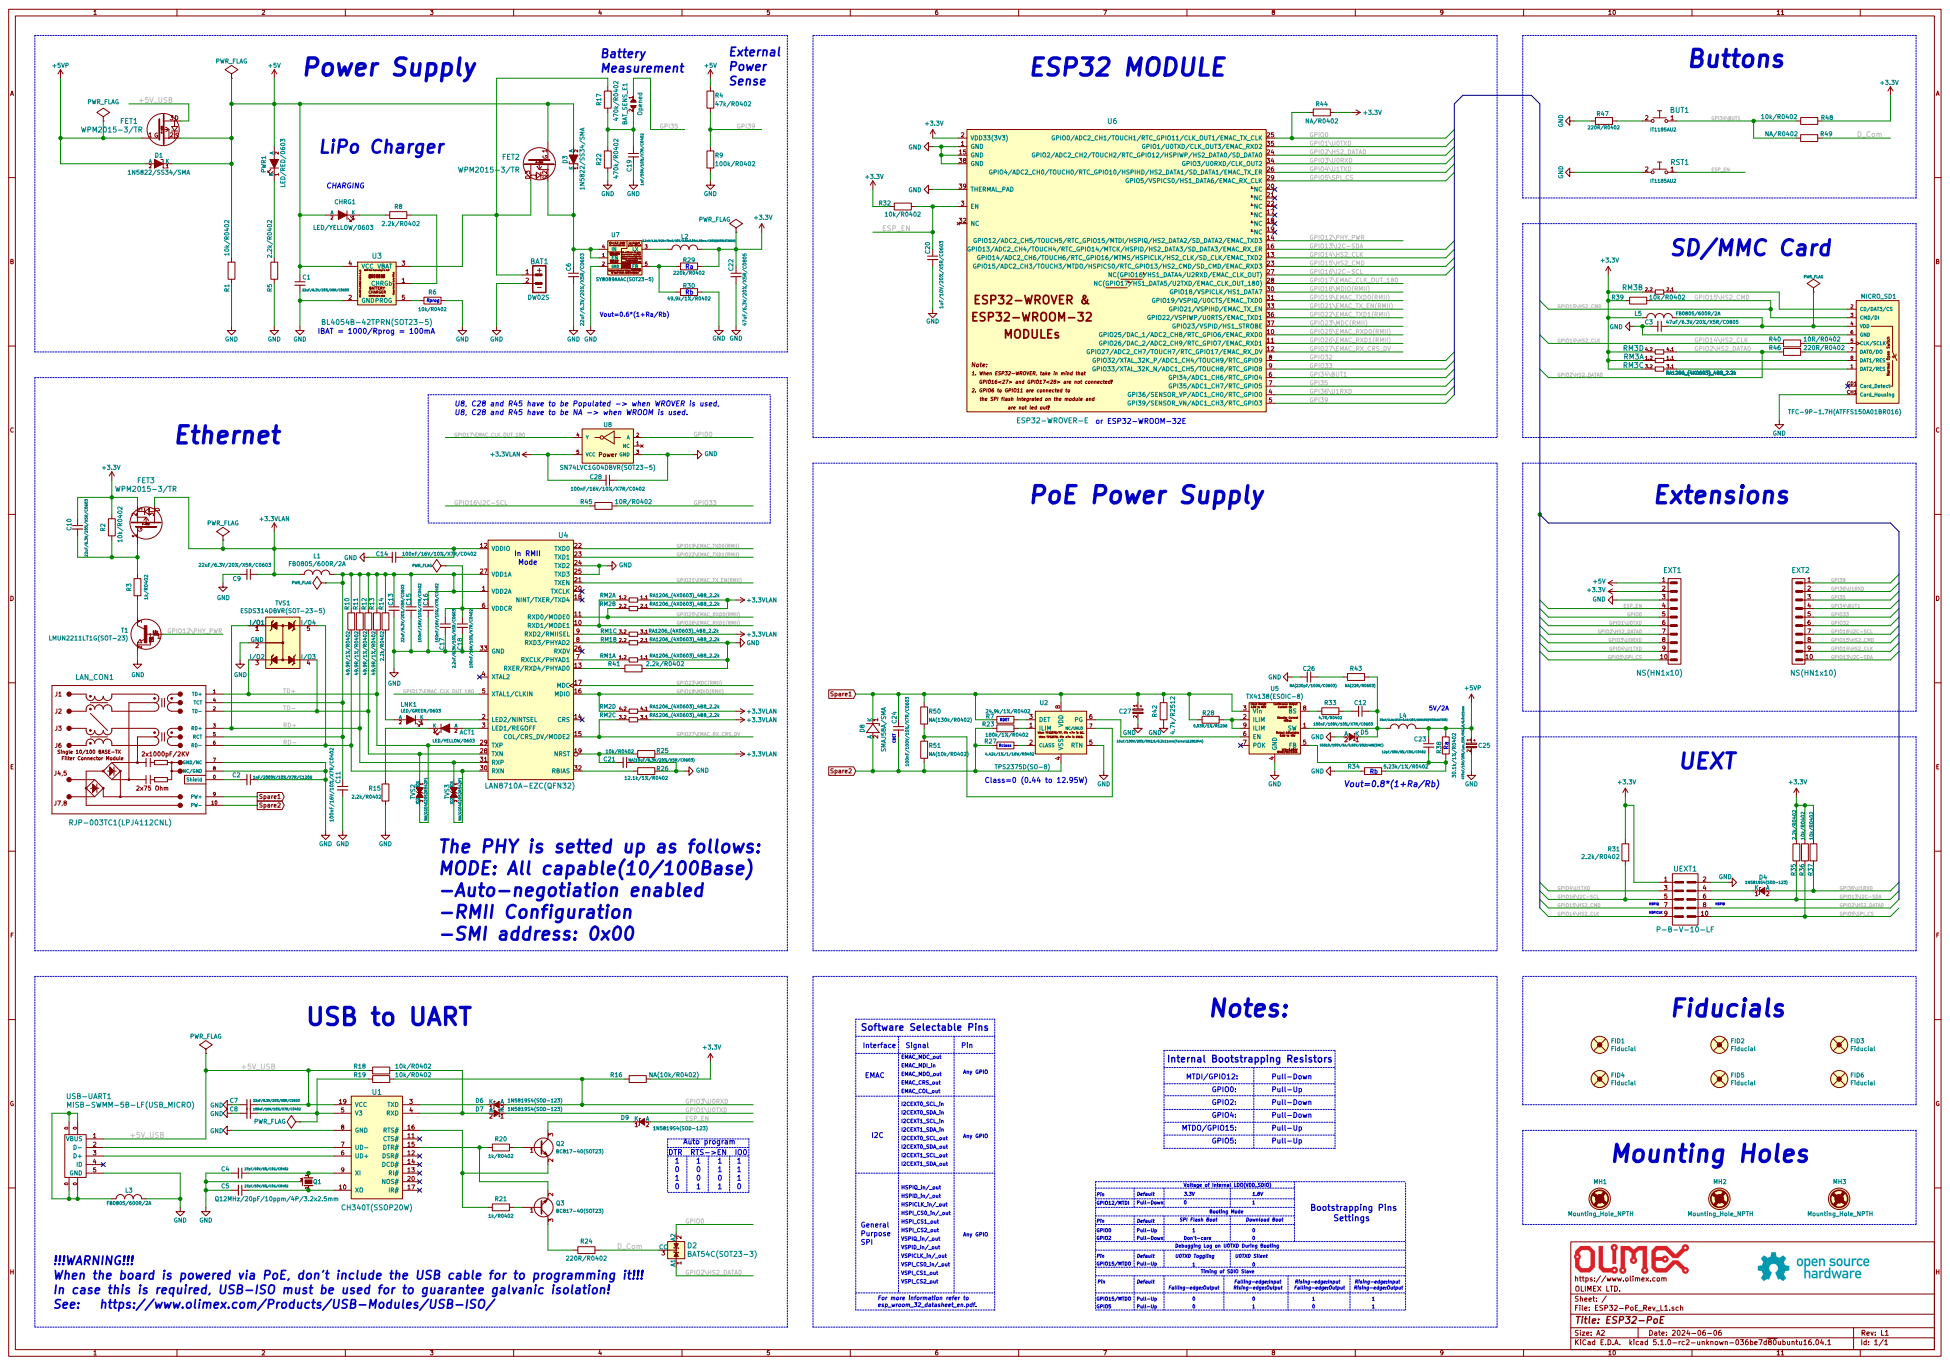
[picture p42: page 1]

2. 2. 2. 2. 2. 2. 2. GPIO6 to GPIO11 are connected to are not led out! ESP32-WROOM-32

load current capability! Lx=2.2uH

Do not float. Enable control. FB Input Current, I(FB)=50nA(max) Feedback Reference Voltage, V(REF)=0.6V

1. 1. 1. When ESP32-WROVER, take in mind that
ESP32-WROVER &

PWR_FLAG The PHY is setted up as follows:

GPIO16<27> and GPIO17<28> are not connected! MODULEs

!!!WARNING!!!
When the board is powered via PoE, don't include the USB cable for to programming it!!!
In case this is required, USB-ISO must be used for to guarantee galvanic isolation!
See: https://www.olimex.com/Products/USB-Modules/USB-ISO/

File: ESP32-PoE_Rev_L1.sch Sheet: / OLIMEX LTD. https://www.olimex.com

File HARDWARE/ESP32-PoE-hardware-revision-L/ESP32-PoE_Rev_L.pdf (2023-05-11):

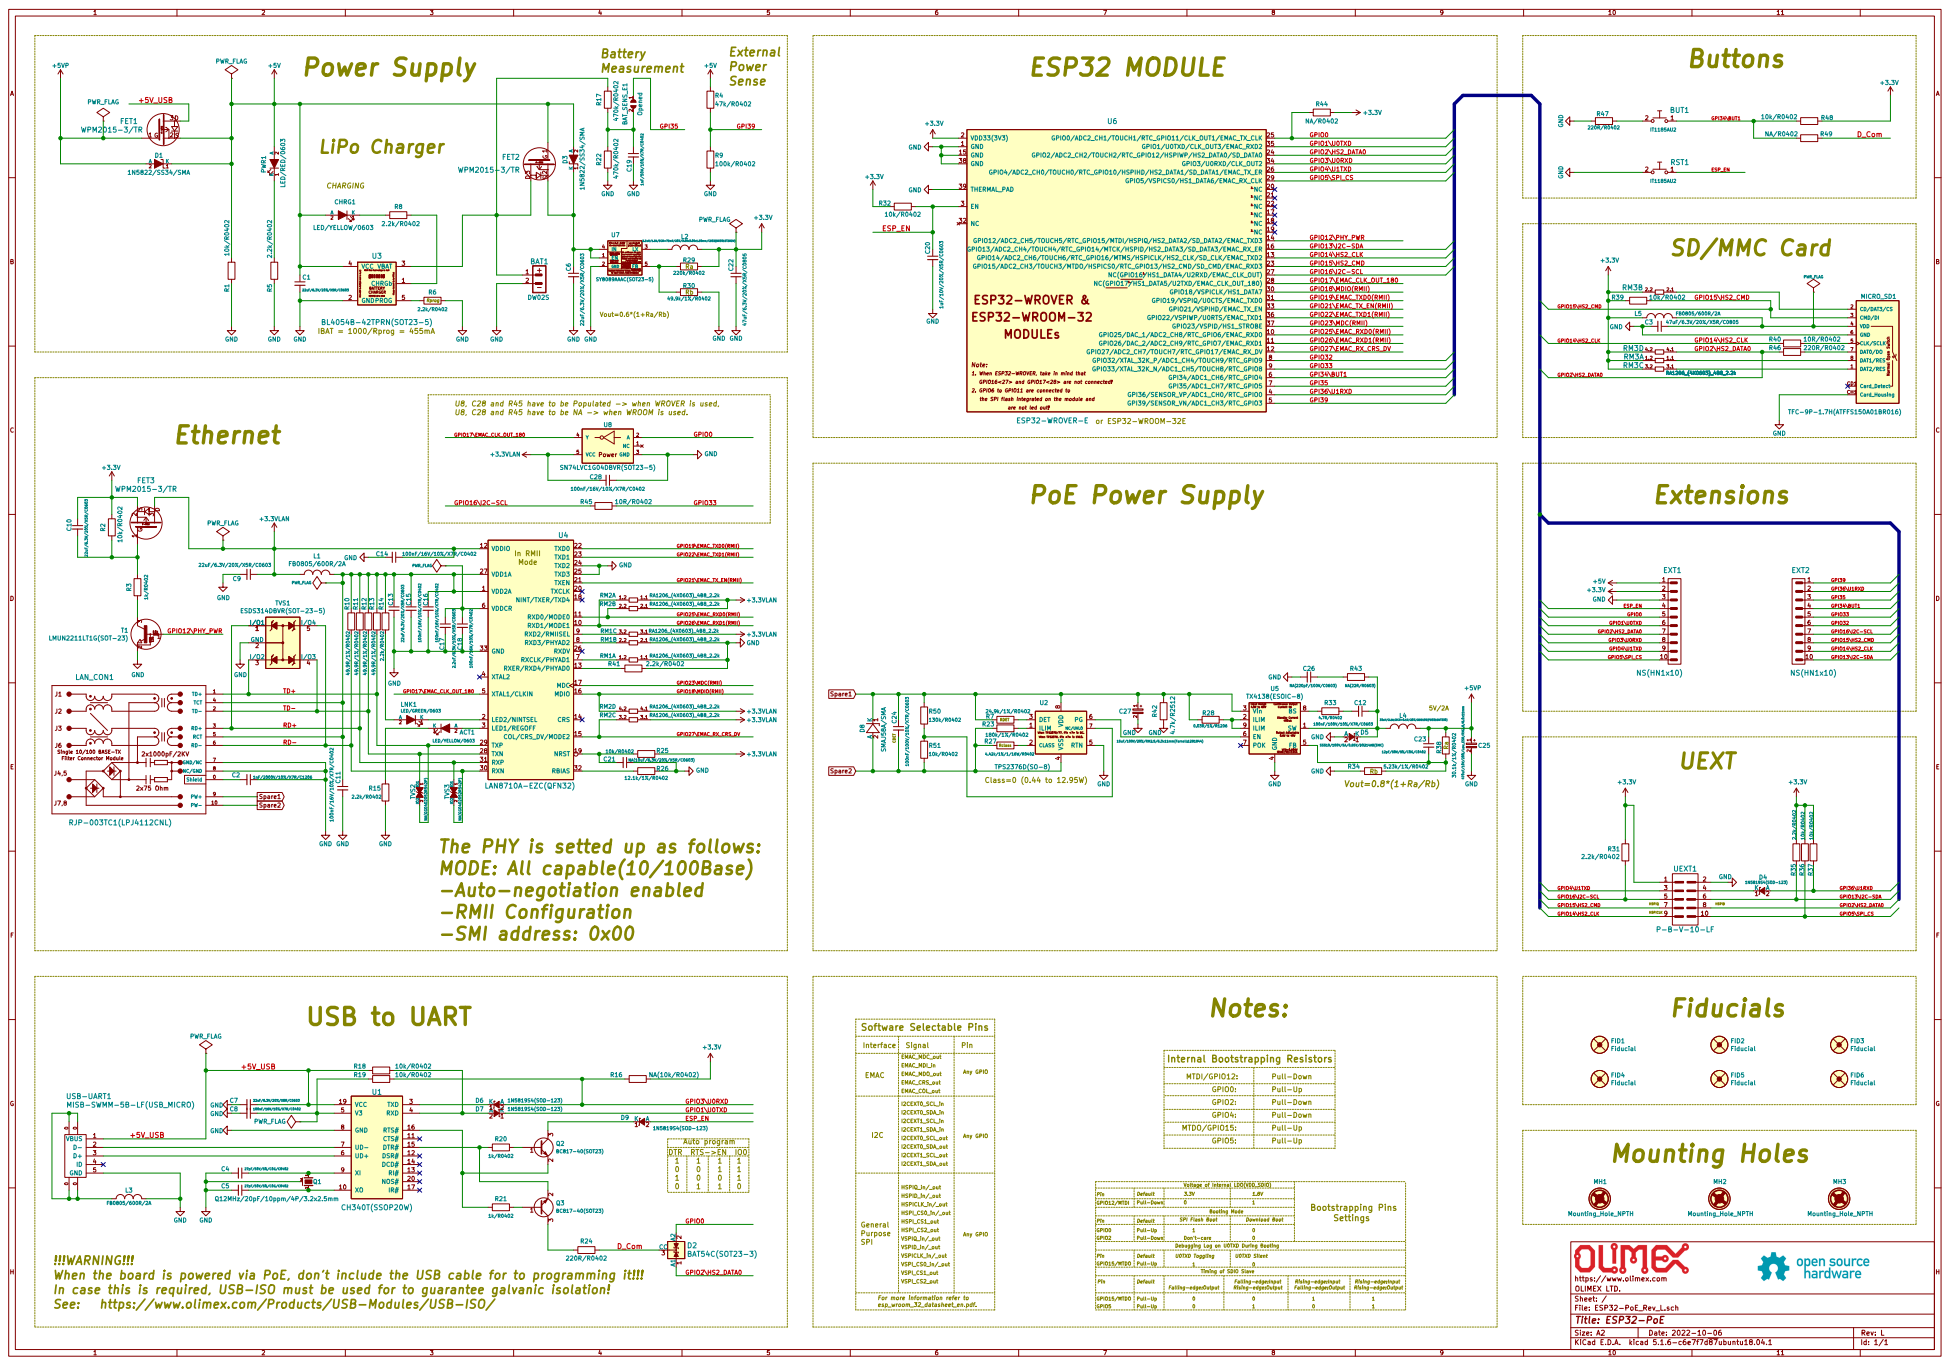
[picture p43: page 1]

2. 2. 2. 2. 2. 2. 2. GPIO6 to GPIO11 are connected to are not led out! ESP32-WROOM-32 ESP32-WROVER &

load current capability! Lx=2.2uH
Cout=2x22uF/6.3V/X5R DCR<50mR

Vout=0.6*(1+Ra/Rb) EN 1 GND 2

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

1. 1. 1. When ESP32-WROVER, take in mind that

GPIO16<27> and GPIO17<28> are not connected! MODULEs

U8, C28 and R45 have to be Populated -> when WROVER is used, U8, C28 and R45 have to be NA -> when WROOM is used.

4 FB 5 EN 6 POK 7 BS 8

The PHY is setted up as follows:
MODE: All capable(10/100Base)
-Auto-negotiation enabled
-RMII Configuration
-SMI address: 0x00

HSPIQ Download Boot U0TXD Silent USB to UART

1N5819S4(SOD-123)
1 Rising-edge:Input DTR RTS->EN IO0 Auto program

1 Debugging Log on U0TXD During Booting

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

In case this is required, USB-ISO must be used for to guarantee galvanic isolation!

File: ESP32-PoE_Rev_L.sch Sheet: / OLIMEX LTD. https://www.olimex.com

Pull-Up

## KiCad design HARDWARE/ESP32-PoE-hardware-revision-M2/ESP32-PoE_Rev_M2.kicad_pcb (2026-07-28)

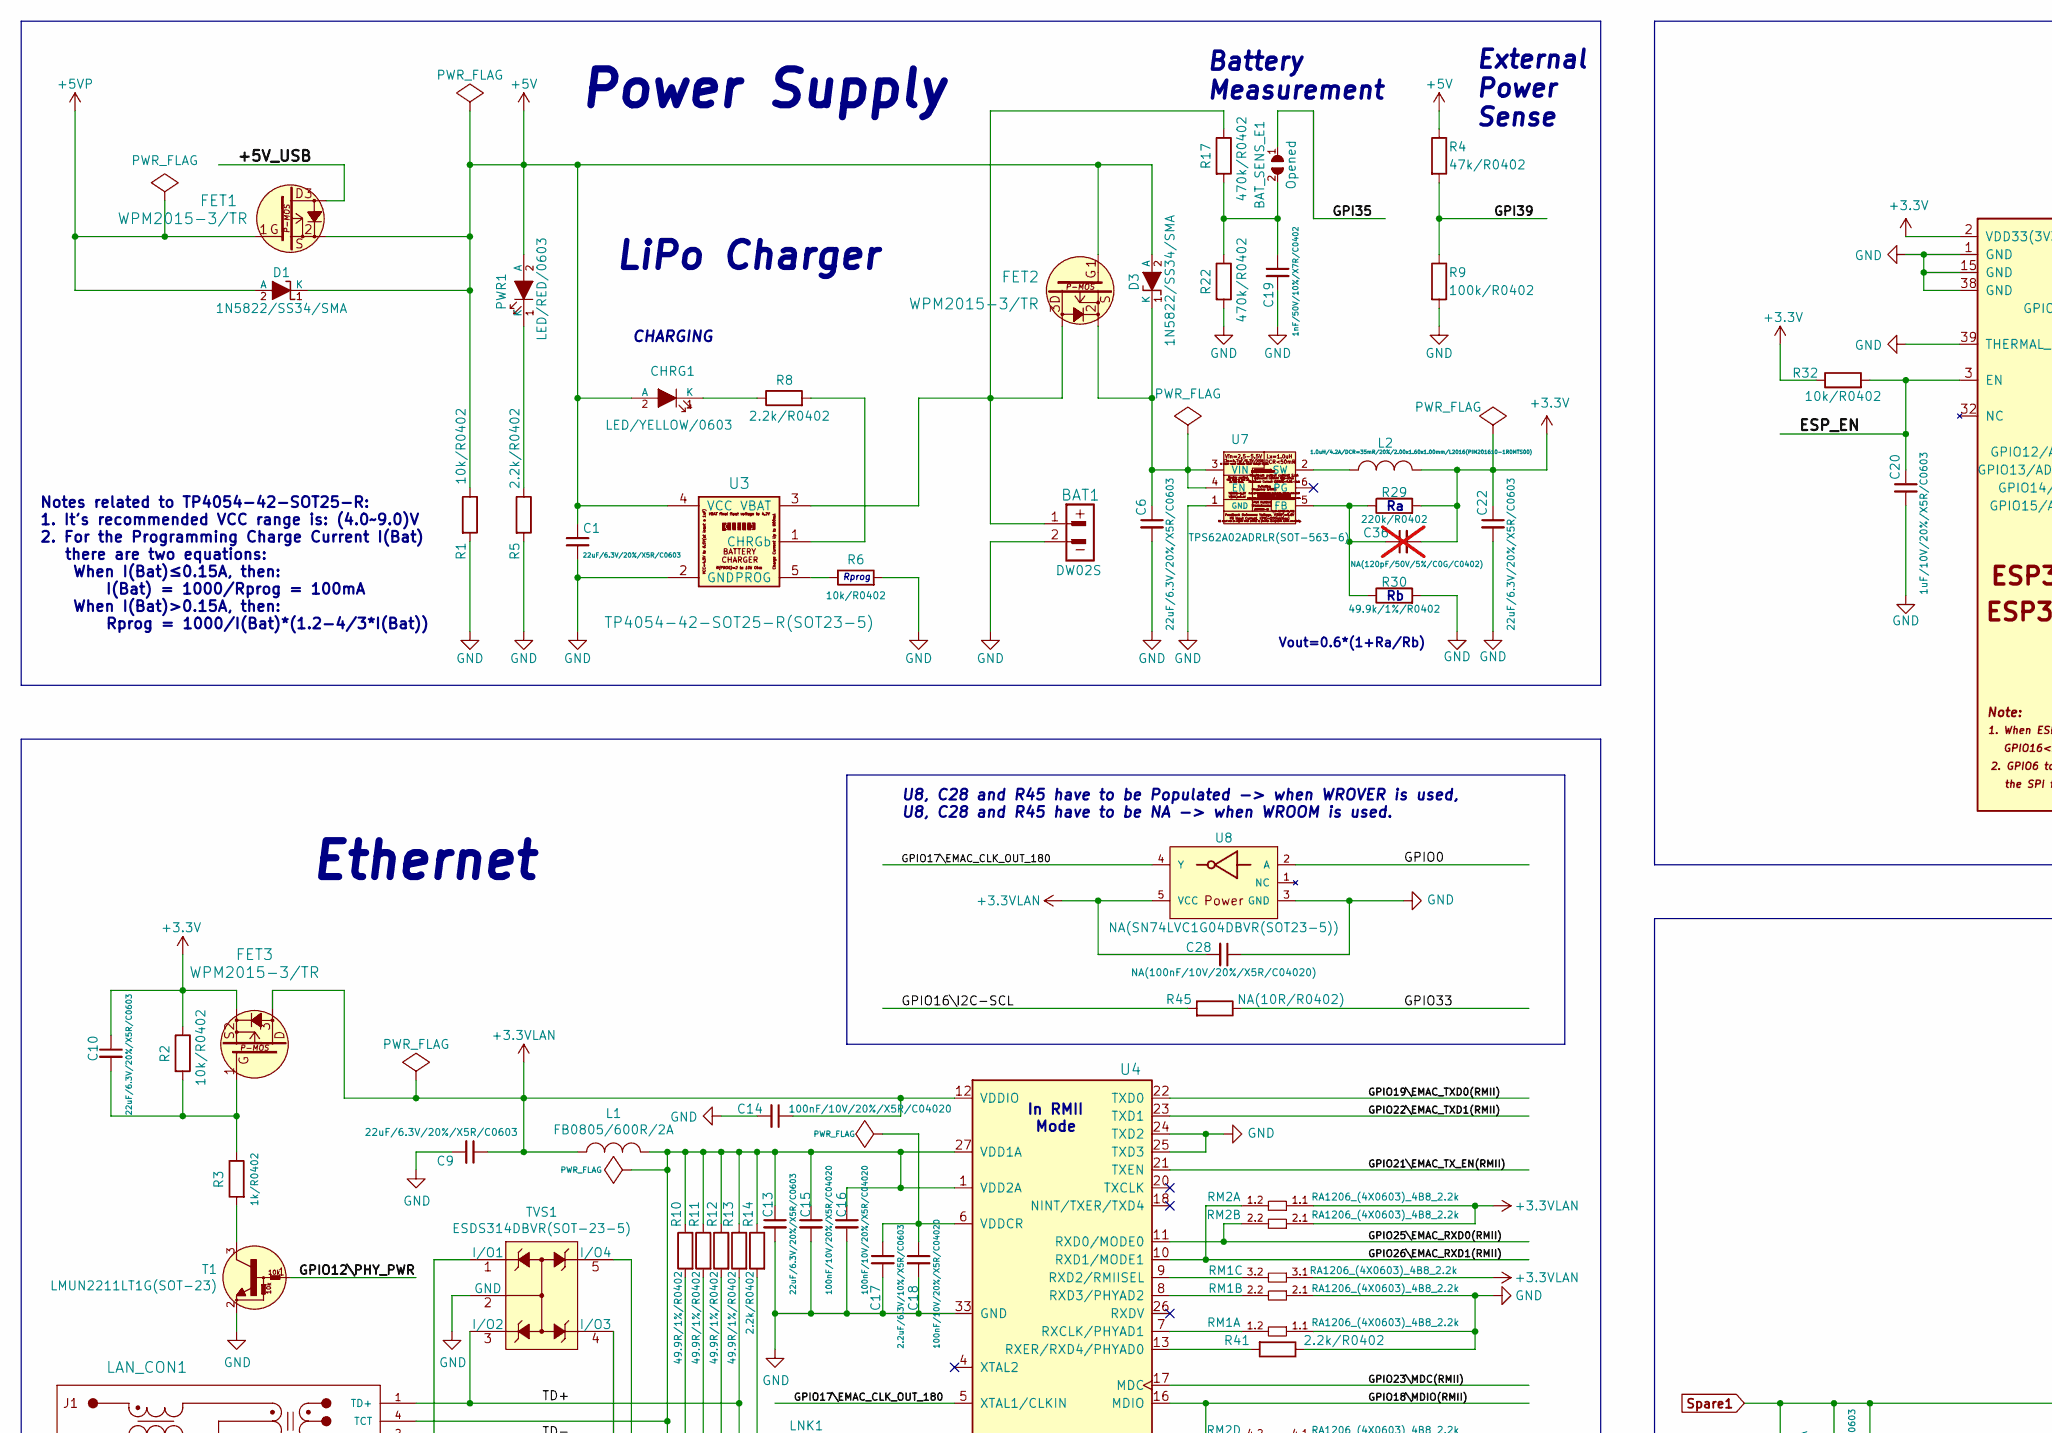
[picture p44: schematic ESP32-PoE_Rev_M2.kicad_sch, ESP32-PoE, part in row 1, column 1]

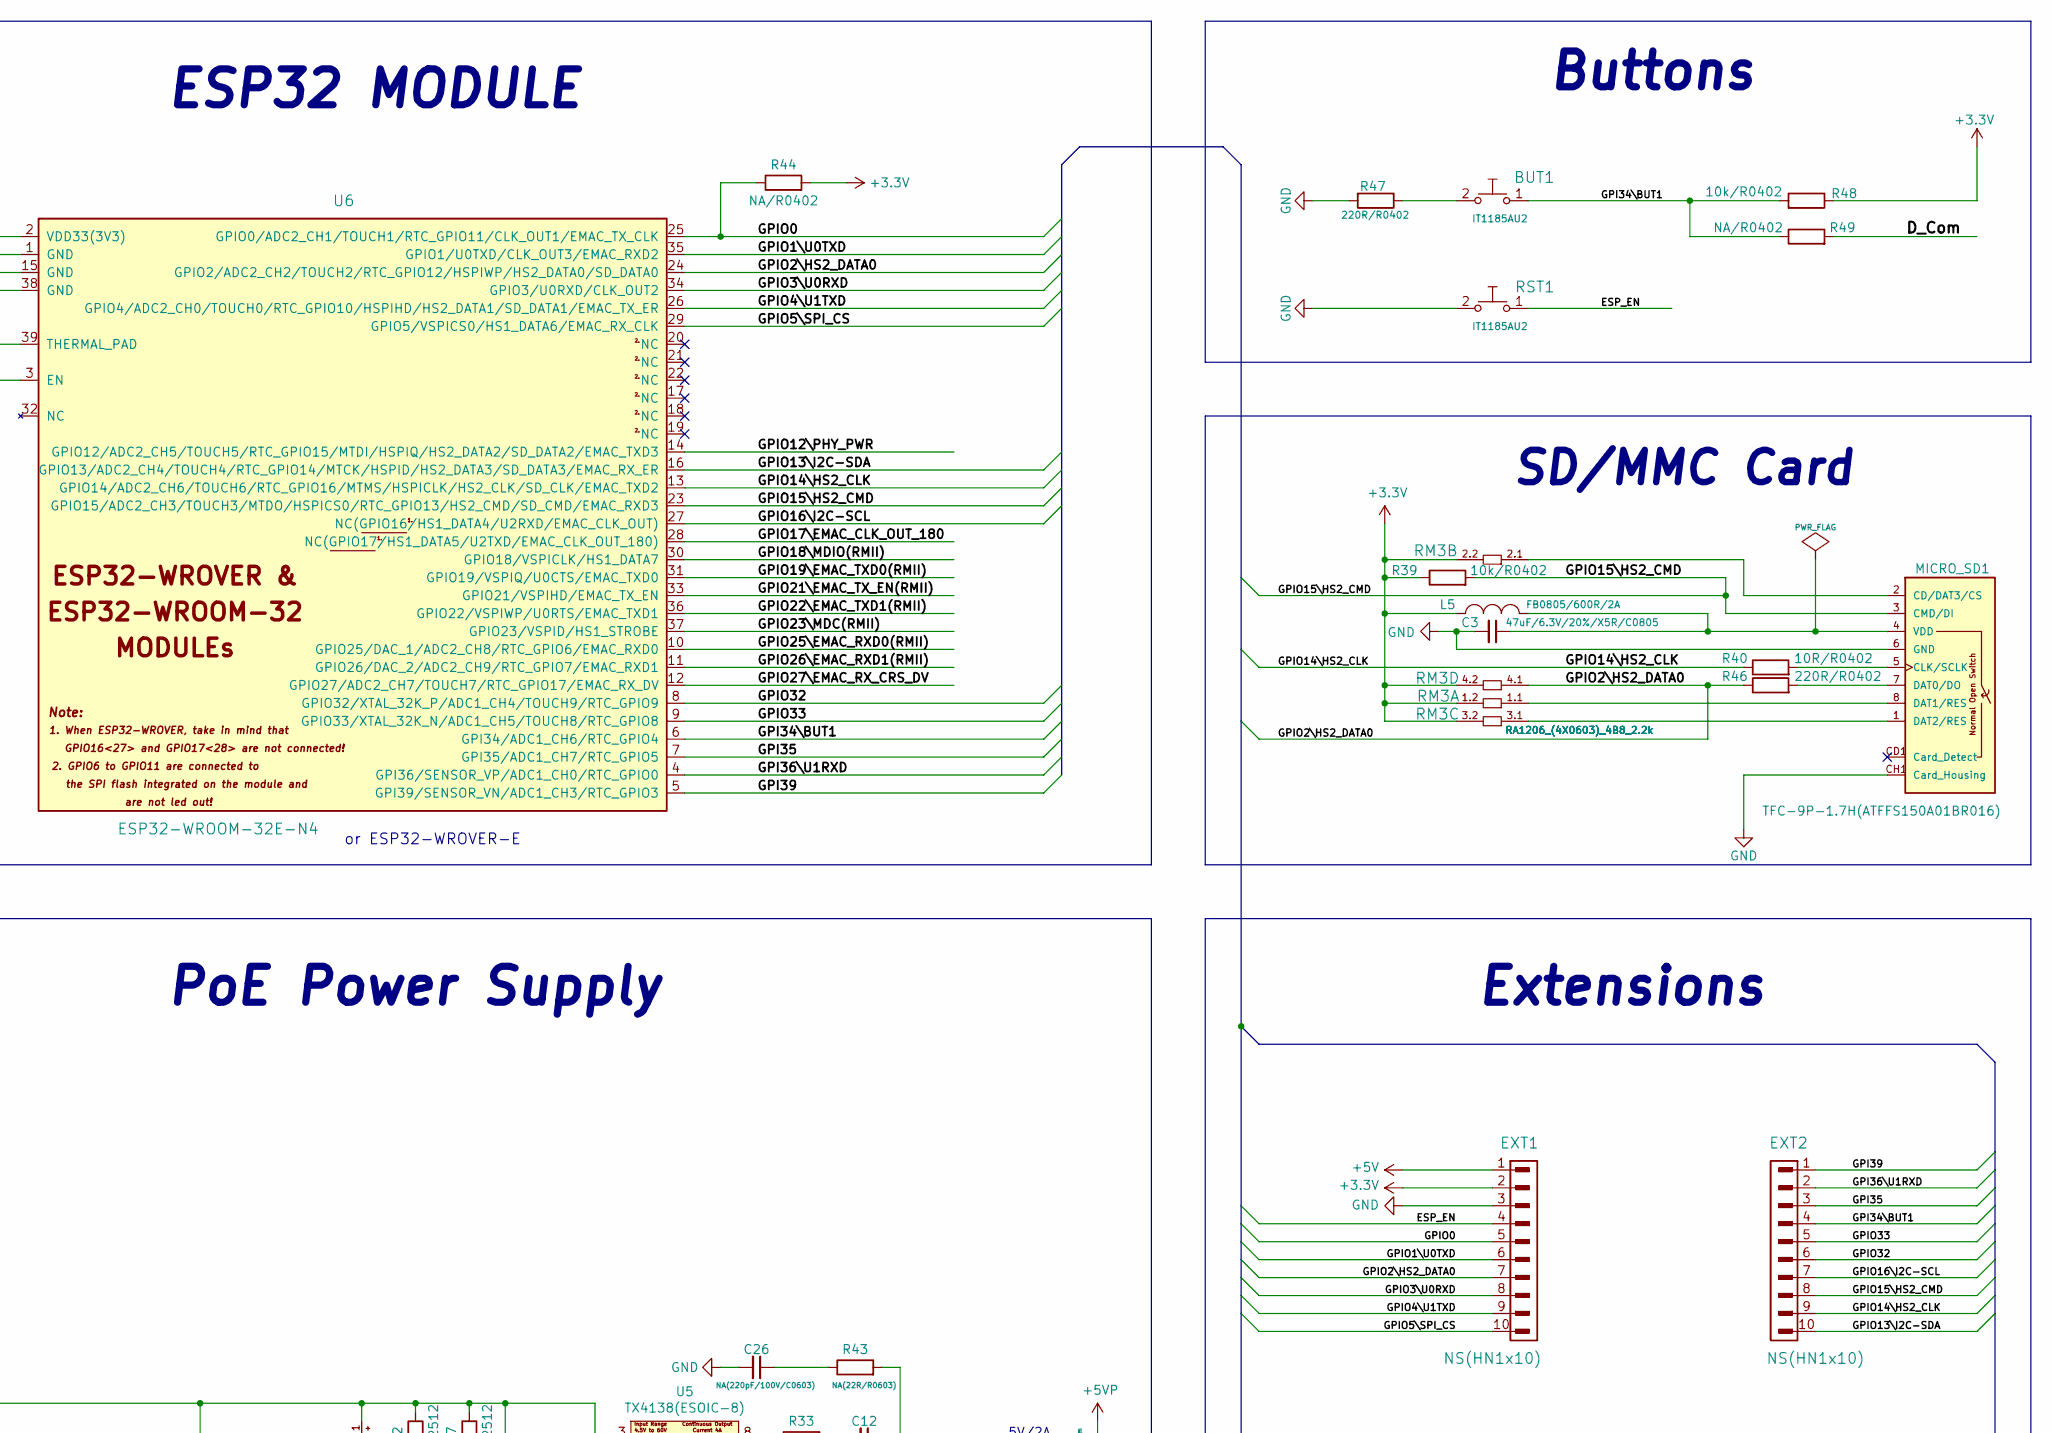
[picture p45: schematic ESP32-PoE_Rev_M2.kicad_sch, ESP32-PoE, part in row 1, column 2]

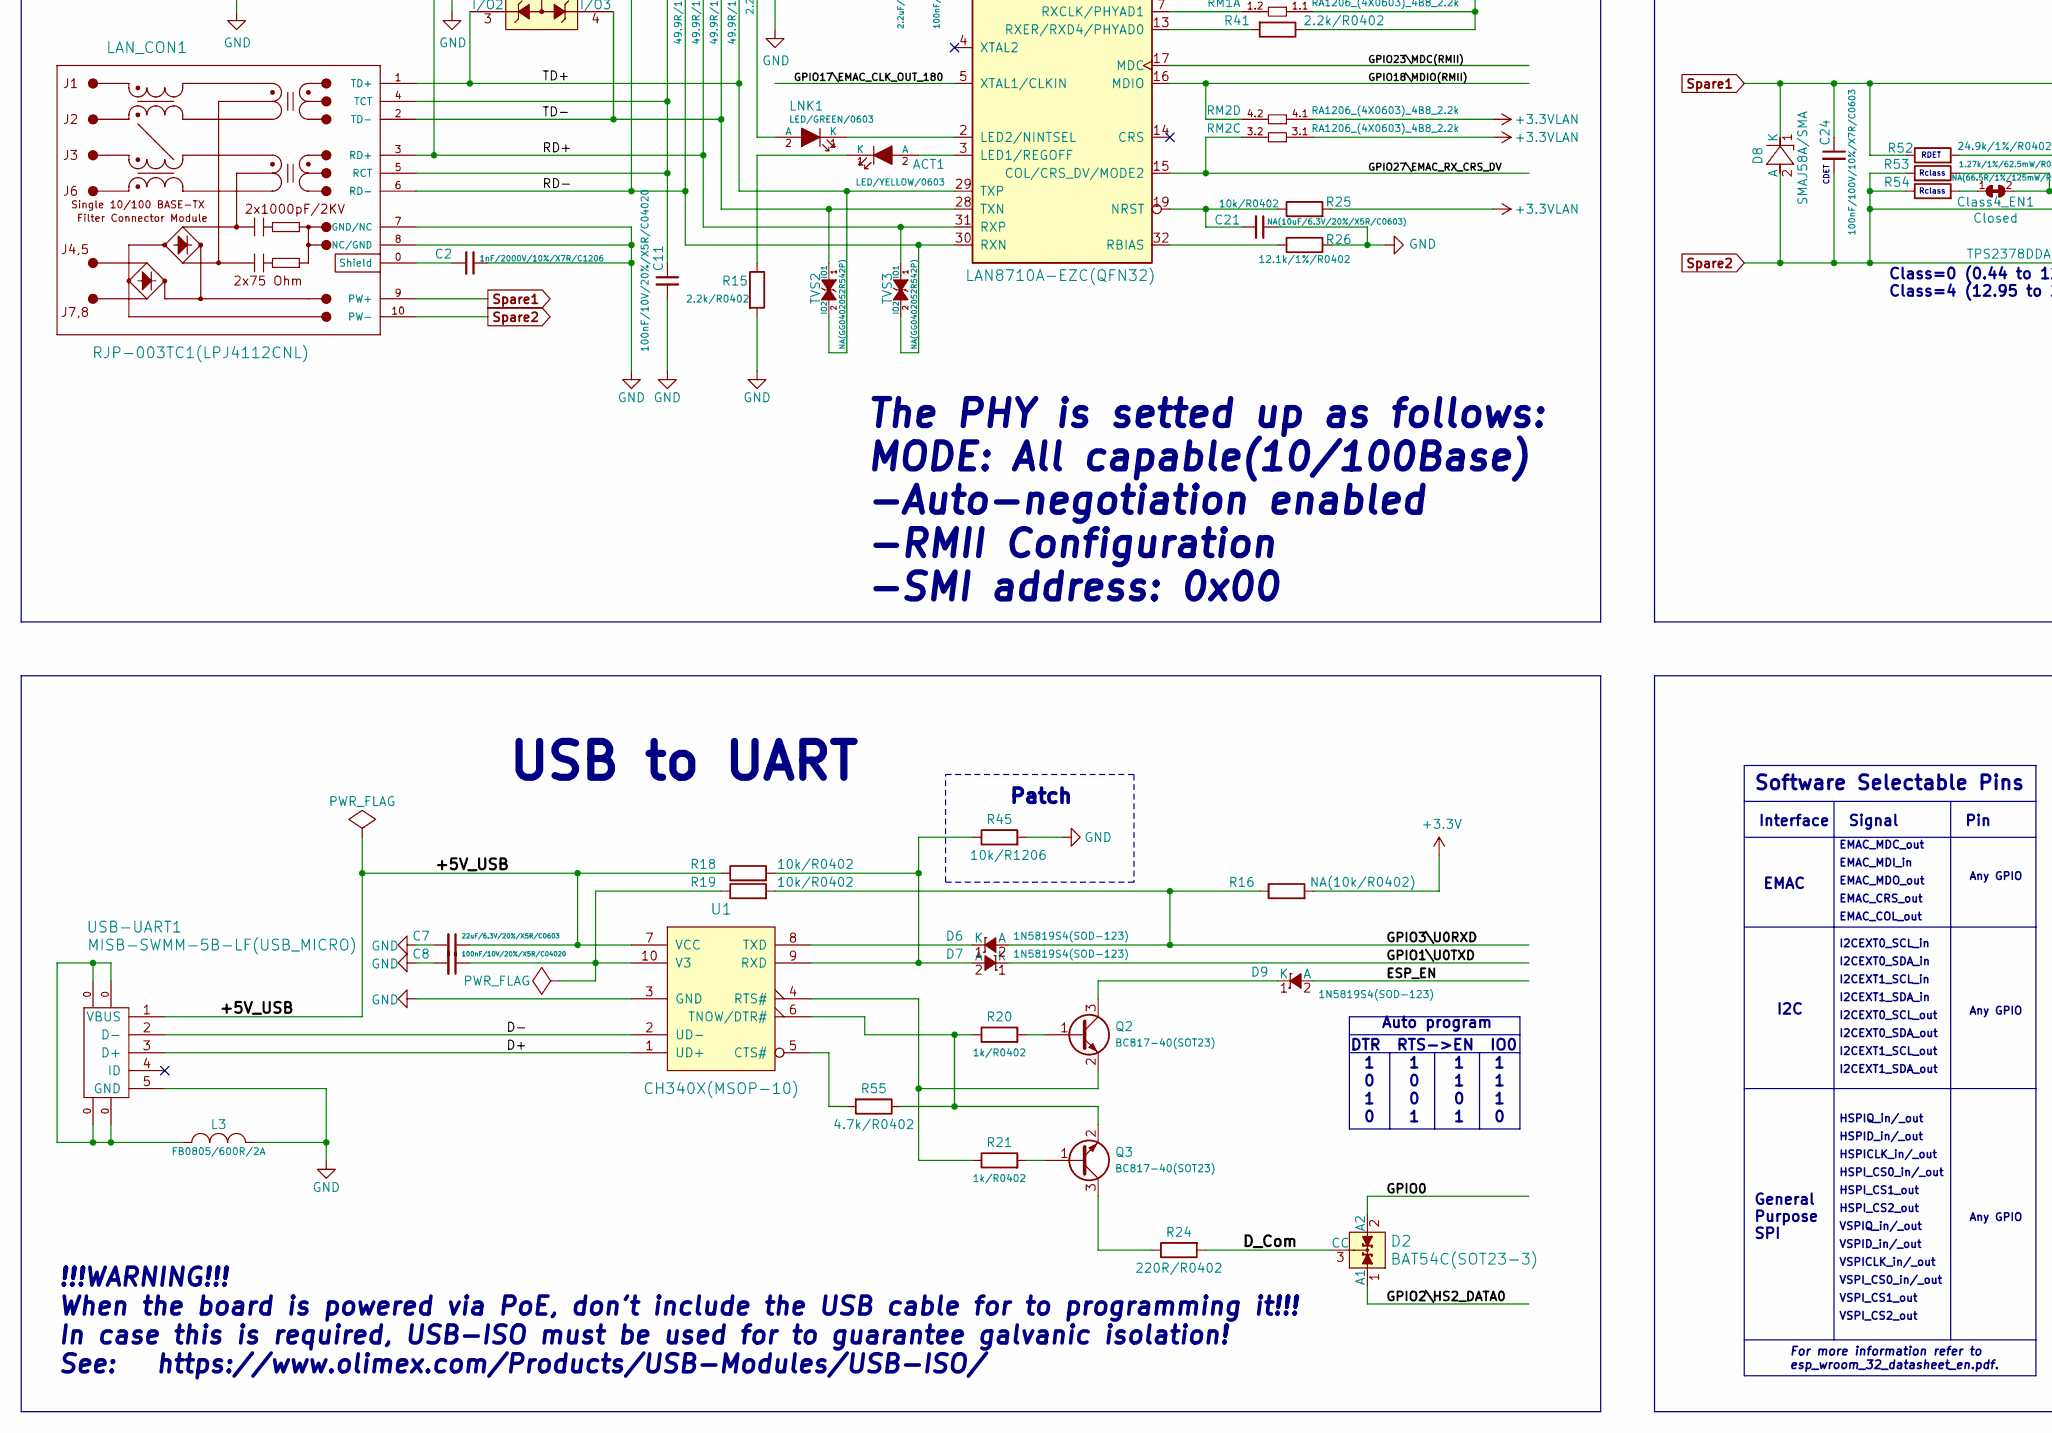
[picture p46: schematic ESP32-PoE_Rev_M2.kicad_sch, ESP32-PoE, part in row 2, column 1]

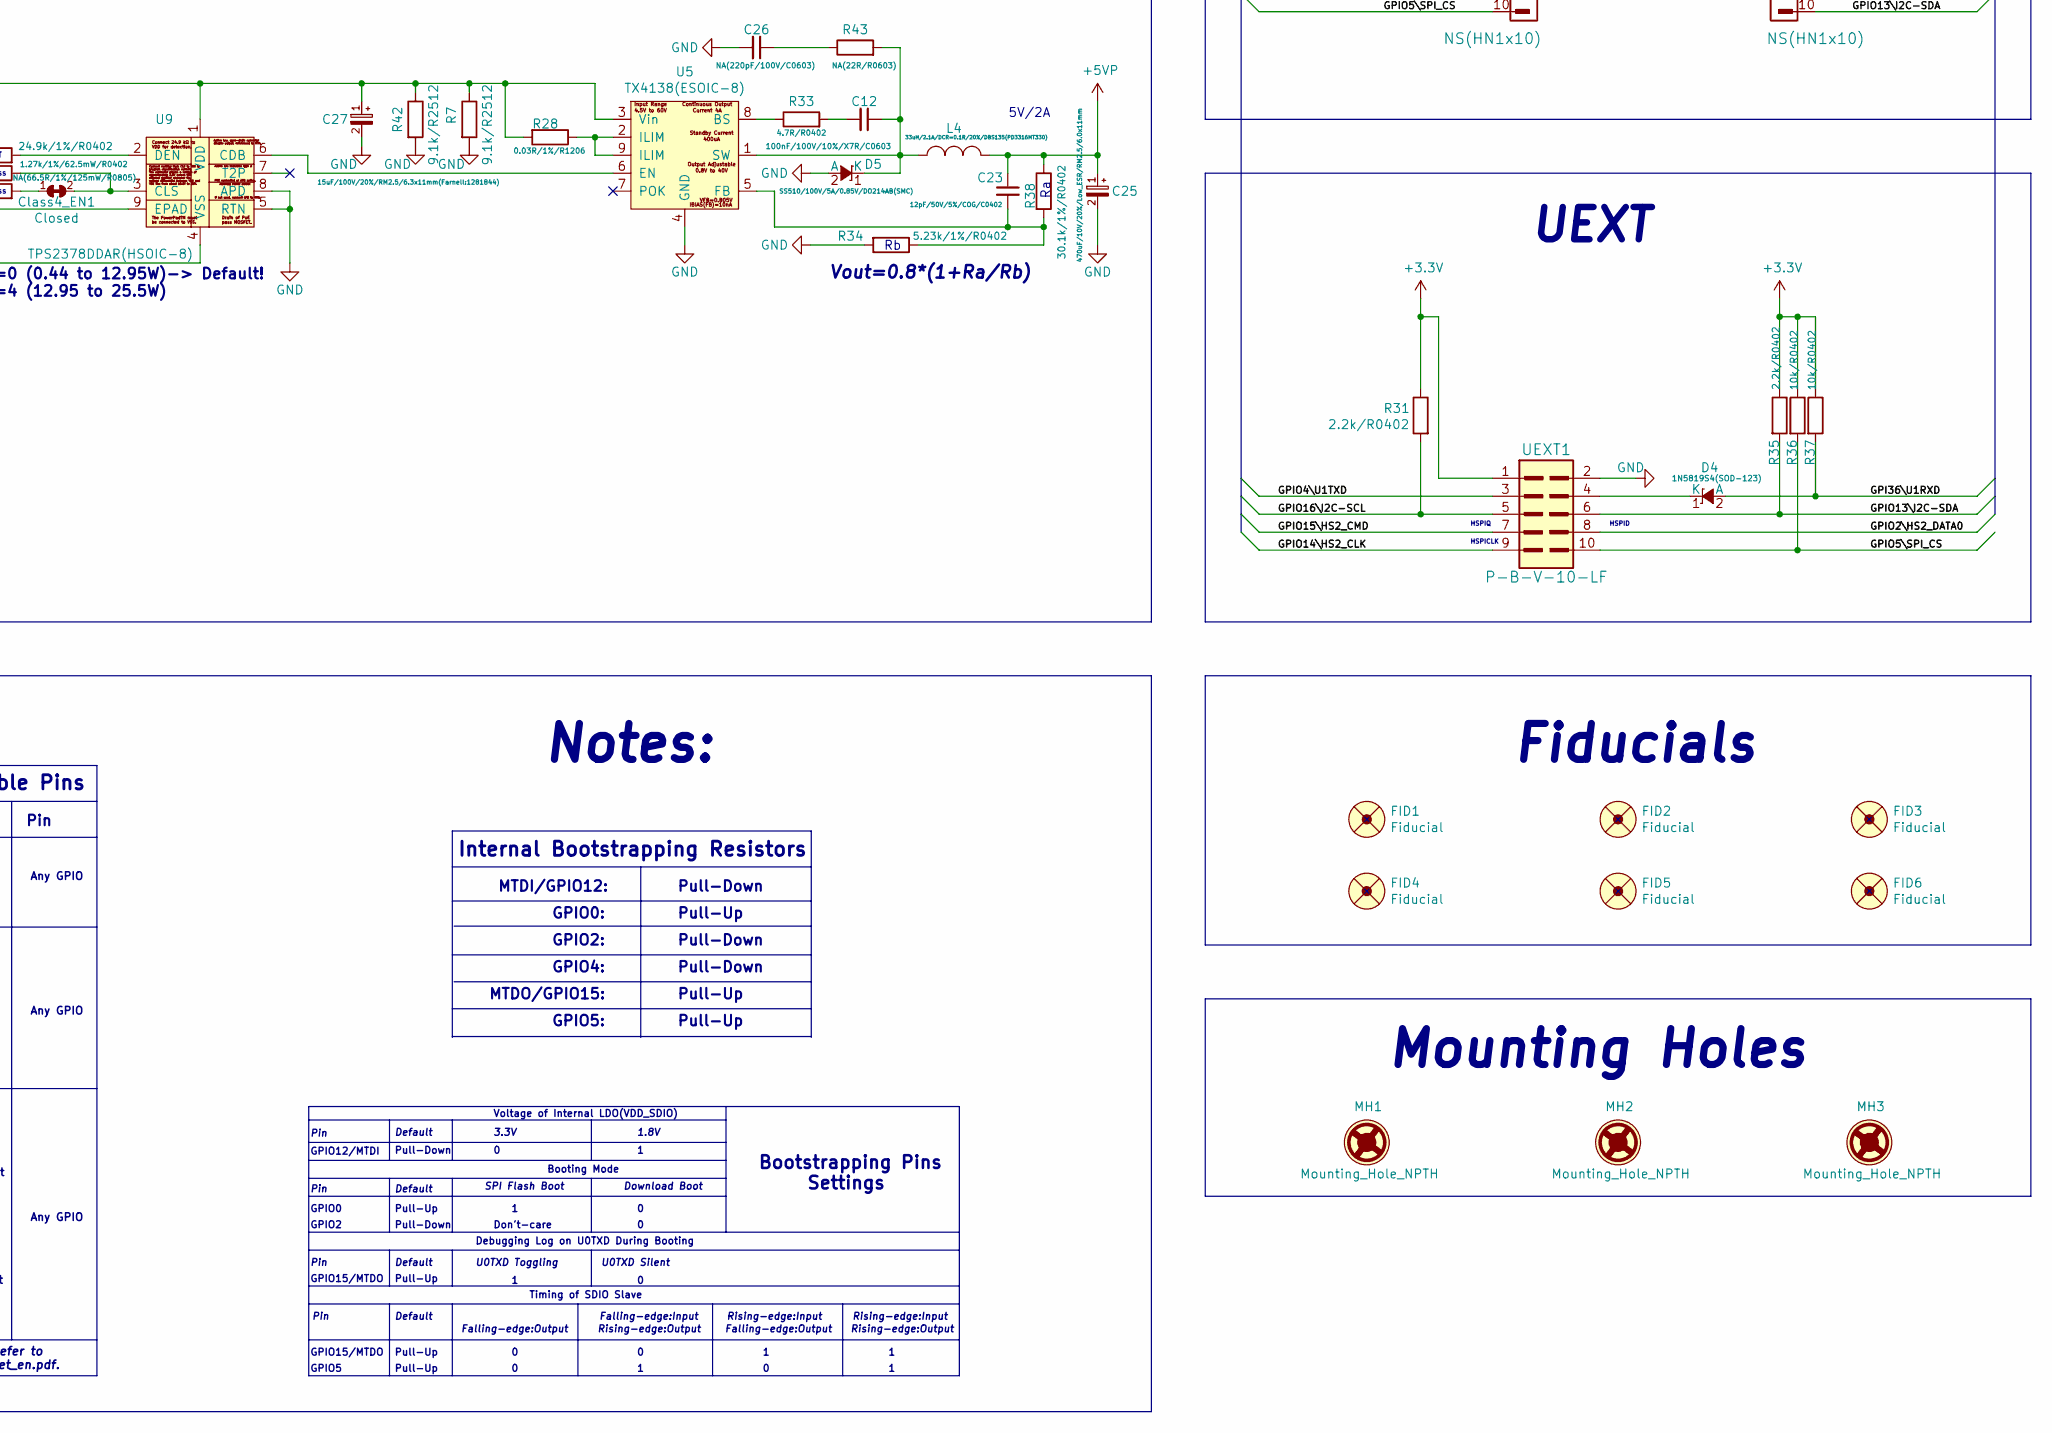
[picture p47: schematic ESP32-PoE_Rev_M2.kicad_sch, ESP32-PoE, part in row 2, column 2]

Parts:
ACT1: LED/YELLOW/0603; LED_0603_KA
BAT1: DW02S; LIPO_BAT_VERTICAL_DW02S
BAT_SENS_E1: Opened; SJ_1_SMALLER
BUT1: IT1185AU2; IT1185AU2_V2
C1, C6, C7, C9, C10, C13, C22: 22uF/6.3V/20%/X5R/C0603; C_0603_5MIL_DWS
C2: 1nF/2000V/10%/X7R/C1206; C_1206_5MIL_DWS_ISO
C3: 47uF/6.3V/20%/X5R/C0805; C_0805_5MIL_DWS
C8, C11, C14, C15, C16, C18: 100nF/10V/20%/X5R/C04020; C_0402_5MIL_DWS
C12, C24: 100nF/100V/10%/X7R/C0603; C_0603_5MIL_DWS
C17: 2.2uF/6.3V/10%/X5R/C0603; C_0603_5MIL_DWS
C19: 1nF/50V/10%/X7R/C0402; C_0402_5MIL_DWS
C20: 1uF/10V/20%/X5R/C0603; C_0603_5MIL_DWS
C21: NA(10uF/6.3V/20%/X5R/C0603); C_0603_5MIL_DWS
C23: 12pF/50V/5%/COG/C0402; C_0402_5MIL_DWS
C25: 470uF/10V/20%/Low_ESR/RM2.5/6.0x11mm; CPOL-RM2.5mm_6.3x11mm_PTH
C26: NA(220pF/100V/C0603); C_0603_5MIL_DWS
C27: 15uF/100V/20%/RM2.5/6.3x11mm(Farnell:1281844); CPOL-RM2.5mm_6.3x11mm_PTH
C28: NA(100nF/10V/20%/X5R/C04020); C_0402_5MIL_DWS
C36: NA(120pF/50V/5%/C0G/C0402); C_0402_5MIL_DWS; not fitted
CHRG1: LED/YELLOW/0603; LED_0603_KA
Class4_EN1: Closed; SJ_Closed
D1, D3: 1N5822/SS34/SMA; SMA-KA
D2: BAT54C(SOT23-3); SOT23-3
D4, D6, D7, D9: 1N5819S4(SOD-123); SOD-123_1C-2A_KA
D5: SS510/100V/5A/0.85V/DO214AB(SMC); DO214AB(SMC)_1(K)-2(A)
D8: SMAJ58A/SMA; SMA-KA
EXT1, EXT2: NS(HN1x10); HN1x10
FET1, FET2, FET3: WPM2015-3/TR; SOT23
FID1, FID3, FID4, FID6: Fiducial; Fiducial1x3
FID2, FID5: Fiducial; Fiducial1x3_Paste
L1, L3, L5: FB0805/600R/2A; L_0805_5MIL_DWS
L2: 1.0uH/4.2A/DCR=35mR/20%/2.00x1.60x1.00mm/L2016(PI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; L_2016_MM
L4: 33uH/2.1A/DCR=0.1R/20%/DBS135(PD3316MT330); DBS135
LAN_CON1: RJP-003TC1(LPJ4112CNL)
LNK1: LED/GREEN/0603; LED_0603_KA
MH1, MH2, MH3: Mounting_Hole_NPTH; NPTH_2.2mm
MICRO_SD1: TFC-9P-1.7H(ATFFS150A01BR016); uSD(TFC-9P-1.xH(ATFFS150A01BR016))
PWR1: LED/RED/0603; LED_0603_KA
Q2, Q3: BC817-40(SOT23); SOT23
R1, R2, R6, R18, R19, R25, R32, R36, R37, R39, R48: 10k/R0402; R_0402_5MIL_DWS
R3, R20, R21: 1k/R0402; R_0402_5MIL_DWS
R4: 47k/R0402; R_0402_5MIL_DWS
R5, R8, R14, R15, R31, R35, R41: 2.2k/R0402; R_0402_5MIL_DWS
R7, R42: 9.1k/R2512; R_2512_MM_DWS
R9: 100k/R0402; R_0402_5MIL_DWS
R10, R11, R12, R13: 49.9R/1%/R0402; R_0402_5MIL_DWS
R16: NA(10k/R0402); R_0402_5MIL_DWS
R17, R22: 470k/R0402; R_0402_5MIL_DWS
R24, R46, R47: 220R/R0402; R_0402_5MIL_DWS
R26: 12.1k/1%/R0402; R_0402_5MIL_DWS
R28: 0.03R/1%/R1206; R_1206_5MIL_DWS
R29: 220k/R0402; R_0402_5MIL_DWS
R30: 49.9k/1%/R0402; R_0402_5MIL_DWS
R33: 4.7R/R0402; R_0402_5MIL_DWS
R34: 5.23k/1%/R0402; R_0402_5MIL_DWS
R38: 30.1k/1%/R0402; R_0402_5MIL_DWS
R40: 10R/R0402; R_0402_5MIL_DWS
R43: NA(22R/R0603); R_0603_5MIL_DWS
R44, R49: NA/R0402; R_0402_5MIL_DWS
R45: NA(10R/R0402); R_0402_5MIL_DWS
R52: 24.9k/1%/R0402; R_0402_5MIL_DWS
R53: 1.27k/1%/62.5mW/R0402; R_0402_5MIL_DWS
R54: NA(66.5R/1%/125mW/R0805); R_0805_5MIL_DWS
R55: 4.7k/R0402; R_0402_5MIL_DWS
RM1, RM2, RM3: RA1206_(4X0603)_4B8_2.2k; R_MATRIX_4
RST1: IT1185AU2; IT1185AU2_V2
T1: LMUN2211LT1G(SOT-23); SOT23
TVS1: ESDS314DBVR(SOT-23-5); SOT-23-5
TVS2, TVS3: NA(GG0402052R542P); D_0402_5MIL_DWS
U1: CH340X(MSOP-10); MSOP-10_Pitch-0.5mm_3.00x3.00x1.00mm
U3: TP4054-42-SOT25-R(SOT23-5); SOT-23-5
U4: LAN8710A-EZC(QFN32); QFN32_EP(33)_5.00x5.00x0.90mm_Pitch_0.50mm
U5: TX4138(ESOIC-8); ESOIC-8
U6: ESP32-WROOM-32E-N4; ESP32-WROVER_MODULE
U7: TPS62A02ADRLR(SOT-563-6); SOT-563-6
U8: NA(SN74LVC1G04DBVR(SOT23-5)); SOT-23-5
U9: TPS2378DDAR(HSOIC-8); ESOIC-8
UEXT1: P-B-V-10-LF; GBH-254-SMT-10
USB-UART1: MISB-SWMM-5B-LF(USB_MICRO); USB-MICRO_MISB-SWMM-5B_LF

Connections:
+3.3V: C10.1, C22.1, EXT1.2, FET3.2, L2.2, L5.1, R2.1, R16.2, R29.2, R31.1, R32.1, R35.1, R36.1, R37.1, R39.1, R44.2, R48.1, RM3.1.2, RM3.2.2, RM3.3.2, RM3.4.2, U6.2 (VDD33(3V3)), UEXT1.1; also elsewhere on the board
+3.3VLAN: C9.1, C14.1, C28.2, FET3.3, L1.1, R25.2, RM1.3.1, RM2.1.1, RM2.2.1, RM2.3.1, RM2.4.1, U4.12 (VDDIO), U8.5 (VCC)
+5V: C1.1, CHRG1.2 (A), D1.1 (K), D3.2 (A), EXT1.1, FET1.2, FET2.1, PWR1.2 (A), R1.1, R4.1, U3.4 (VCC)
+5VP: C23.1, C25.1 (+), D1.2 (A), FET1.1, L4.2, R38.1
/+5V_USB: C7.1, FET1.3, R18.1, U1.7 (VCC), USB-UART1.1 (VBUS)
/D+: U1.1 (UD+), USB-UART1.3 (D+)
/D-: U1.2 (UD-), USB-UART1.2 (D-)
/D_Com: D2.3 (CC), R24.2, R49.2
/ESP_EN: C20.1, D9.2 (A), EXT1.4, R32.2, RST1.1, U6.3 (EN)
/GPI34\BUT1: BUT1.1, EXT2.4, R48.2, R49.1, U6.6 (GPI34/ADC1_CH6/RTC_GPIO4)
/GPI35: BAT_SENS_E1.1, EXT2.3, U6.7 (GPI35/ADC1_CH7/RTC_GPIO5)
/GPI36\U1RXD: D4.2 (A), EXT2.2, R37.2, U6.4 (GPI36/SENSOR_VP/ADC1_CH0/RTC_GPIO0)
/GPI39: EXT2.1, R4.2, R9.1, U6.5 (GPI39/SENSOR_VN/ADC1_CH3/RTC_GPIO3)
/GPIO0: D2.2 (A2), EXT1.5, R44.1, U6.25 (GPIO0/ADC2_CH1/TOUCH1/RTC_GPIO11/CLK_OU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), U8.2 (A)
/GPIO1\U0TXD: D7.1 (K), EXT1.6, U6.35 (GPIO1/U0TXD/CLK_OUT3/EMAC_RXD2)
/GPIO2\HS2_DATA0: D2.1 (A1), EXT1.7, R46.1, RM3.4.1, U6.24 (GPIO2/ADC2_CH2/TOUCH2/RTC_GPIO12/HSPIWP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), UEXT1.8
/GPIO3\U0RXD: D6.2 (A), EXT1.8, R16.1, R19.2, U6.34 (GPIO3/U0RXD/CLK_OUT2)
/GPIO4\U1TXD: EXT1.9, U6.26 (GPIO4/ADC2_CH0/TOUCH0/RTC_GPIO10/HSPIHD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), UEXT1.3
/GPIO5\SPI_CS: EXT1.10, R36.2, U6.29 (GPIO5/VSPICS0/HS1_DATA6/EMAC_RX_CLK), UEXT1.10
/GPIO12\PHY_PWR: T1.1 (B), U6.14 (GPIO12/ADC2_CH5/TOUCH5/RTC_GPIO15/MTDI/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)
/GPIO13\I2C-SDA: EXT2.10, R35.2, U6.16 (GPIO13/ADC2_CH4/TOUCH4/RTC_GPIO14/MTCK/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), UEXT1.6
/GPIO14\HS2_CLK: EXT2.9, R40.1, U6.13 (GPIO14/ADC2_CH6/TOUCH6/RTC_GPIO16/MTMS/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), UEXT1.9
/GPIO15\HS2_CMD: EXT2.8, MICRO_SD1.3 (CMD/DI), R39.2, U6.23 (GPIO15/ADC2_CH3/TOUCH3/MTDO/HSPICS0/RTC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), UEXT1.7
/GPIO17\EMAC_CLK_OUT_180: U4.5 (XTAL1/CLKIN), U6.28 (NC(GPIO17/HS1_DATA5/U2TXD/EMAC_CLK_OUT_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), U8.4 (Y)
/GPIO18\MDIO(RMII): RM2.4.2, U4.16 (MDIO), U6.30 (GPIO18/VSPICLK/HS1_DATA7)
/GPIO19\EMAC_TXD0(RMII): U4.22 (TXD0), U6.31 (GPIO19/VSPIQ/U0CTS/EMAC_TXD0)
/GPIO21\EMAC_TX_EN(RMII): U4.21 (TXEN), U6.33 (GPIO21/VSPIHD/EMAC_TX_EN)
/GPIO22\EMAC_TXD1(RMII): U4.23 (TXD1), U6.36 (GPIO22/VSPIWP/U0RTS/EMAC_TXD1)
/GPIO23\MDC(RMII): U4.17 (MDC), U6.37 (GPIO23/VSPID/HS1_STROBE)
/GPIO25\EMAC_RXD0(RMII): RM2.2.2, U4.11 (RXD0/MODE0), U6.10 (GPIO25/DAC_1/ADC2_CH8/RTC_GPIO6/EMAC_RX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)
/GPIO26\EMAC_RXD1(RMII): RM2.1.2, U4.10 (RXD1/MODE1), U6.11 (GPIO26/DAC_2/ADC2_CH9/RTC_GPIO7/EMAC_RX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)
/GPIO27\EMAC_RX_CRS_DV: RM2.3.2, U4.15 (COL/CRS_DV/MODE2), U6.12 (GPIO27/ADC2_CH7/TOUCH7/RTC_GPIO17/EMAC_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)
/GPIO32: EXT2.6, U6.8 (GPIO32/XTAL_32K_P/ADC1_CH4/TOUCH9/RTC_G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)
/RD+: LAN_CON1.3 (RD+), R11.2, TVS1.1 (I/O1), TVS3.1 (IO1), U4.31 (RXP)
/RD-: LAN_CON1.6 (RD-), R10.2, TVS1.5 (I/O4), TVS3.2 (IO2), U4.30 (RXN)
/TD+: LAN_CON1.1 (TD+), R13.2, TVS1.3 (I/O2), TVS2.2 (IO2), U4.29 (TXP)
/TD-: LAN_CON1.2 (TD-), R12.2, TVS1.4 (I/O3), TVS2.1 (IO1), U4.28 (TXN)
unnamed: ACT1.2 (A), U4.3 (LED1/REGOFF)
unnamed: ACT1.1 (K), R15.1
unnamed: BAT_SENS_E1.2, C19.1, R17.2, R22.1
unnamed: BUT1.2, R47.1
unnamed: C10.2, FET3.1, R2.2, R3.1
unnamed: C12.2, R33.2
unnamed: C26.1, R43.1
unnamed: CHRG1.1 (K), R8.1
unnamed: Class4_EN1.1, R54.2
unnamed: C6.1, D3.1 (K), FET2.2, U7.3 (VIN), U7.4 (EN)
unnamed: D4.1 (K), UEXT1.4
unnamed: C12.1, D5.1 (K), L4.1, R43.2, U5.1 (SW)
unnamed: D6.1 (K), U1.8 (TXD)
unnamed: D9.1 (K), Q2.3 (C)
unnamed: L3.1, USB-UART1.0
unnamed: C11.1, C13.1, C15.1, C16.1, L1.2, LAN_CON1.4 (TCT), LAN_CON1.5 (RCT), R10.1, R11.1, R12.1, R13.1, R14.1, U4.1 (VDD2A), U4.27 (VDD1A)
unnamed: C2.2, LAN_CON1.0 (Shield)
unnamed: LNK1.2 (A), R14.2
unnamed: LNK1.1 (K), U4.2 (LED2/NINTSEL)
unnamed: MICRO_SD1.2 (CD/DAT3/CS), RM3.2.1
unnamed: MICRO_SD1.5 (CLK/SCLK), R40.2
unnamed: MICRO_SD1.7 (DAT0/DO), R46.2
unnamed: MICRO_SD1.8 (DAT1/RES), RM3.1.1
unnamed: MICRO_SD1.1 (DAT2/RES), RM3.3.1
unnamed: C3.1, L5.2, MICRO_SD1.4 (VDD)
unnamed: PWR1.1 (K), R5.1
unnamed: Q2.1 (B), R20.2
unnamed: Q2.2 (E), R21.1, U1.4 (RTS#)
unnamed: Q3.1 (B), R21.2
unnamed: Q3.3 (C), R24.1
unnamed: Q3.2 (E), R20.1, R55.1, U1.6 (TNOW/DTR#)
unnamed: R28.1, U5.2 (ILIM), U5.9 (ILIM)
unnamed: R3.2, T1.3 (C)
unnamed: R55.2, U1.5 (CTS#)
unnamed: C8.1, R19.1, U1.10 (V3)
unnamed: R8.2, U3.1 (CHRGb)
unnamed: R6.1, U3.5 (PROG)
unnamed: BAT1.1, FET2.3, R17.1, U3.3 (VBAT)
unnamed: C21.2, R25.1, U4.19 (NRST)
unnamed: R26.1, U4.32 (RBIAS)
unnamed: RM1.1.2, U4.7 (RXCLK/PHYAD1)
unnamed: RM1.3.2, U4.9 (RXD2/RMIISEL)
unnamed: RM1.2.2, U4.8 (RXD3/PHYAD2)
unnamed: R41.2, U4.13 (RXER/RXD4/PHYAD0)
unnamed: C17.1, C18.1, U4.6 (VDDCR)
unnamed: R33.1, U5.8 (BS)
unnamed: U5.6 (EN), U9.6 (CDB)
unnamed: C23.2, R34.1, R38.2, U5.5 (FB)
unnamed 85: R29.1, R30.1, U7.5 (FB); also elsewhere on the board
unnamed: L2.1, U7.2 (SW)
unnamed: Class4_EN1.2, R53.1, U9.3 (CLS)
unnamed: R52.2, U9.2 (DEN)
Spare1: C24.1, C27.1 (+), D8.1 (K), LAN_CON1.9 (PW+), R7.1, R28.2, R42.1, R52.1, U5.3 (Vin), U9.1 (VDD)
Spare2: C24.2, D8.2 (A), LAN_CON1.10 (PW-), R53.2, R54.1, U9.4 (VSS), U9.9 (EPAD)

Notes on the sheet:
Pull-Up
Pull-Down
GPIO2:
Rising-edge:Output
HSPID
Pin
MTDO/GPIO15:
HSPI_CS1_out
Don't-care
Rprog
HSPICLK
PoE Power Supply
EMAC_COL_out
Fiducials
GPIO15/MTDO
I2CEXT0_SCL_in
I2C
I2CEXT1_SCL_in
DTR RTS->EN IO0
Software Selectable Pins
CHARGING
Rising-edge:Input
The PHY is setted up as follows: MODE: All capable(10/100Base) -Auto-negotiation enabled -RMII Configuration -SMI address: 0x00
LiPo Charger
EMAC
GPIO5
Signal
Timing of SDIO Slave
Internal Bootstrapping Resistors
Buttons
Notes:
GPIO0
I2CEXT1_SDA_in
VSPI_CS0_in/_out
Vout=0.6*(1+Ra/Rb)
RDET
MTDI/GPIO12:
Default
HSPID_in/_out
VSPI_CS2_out

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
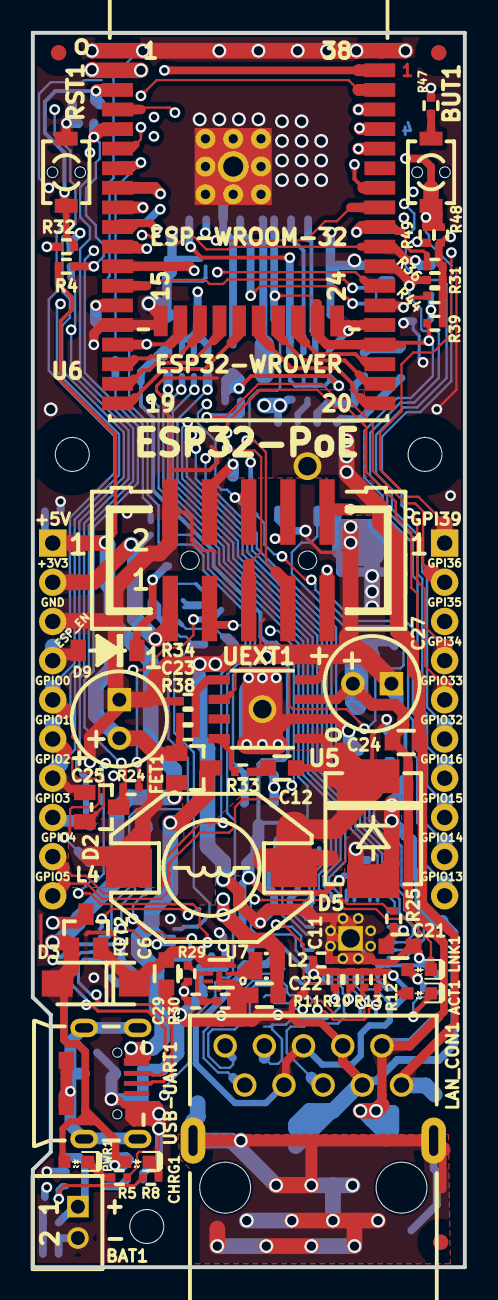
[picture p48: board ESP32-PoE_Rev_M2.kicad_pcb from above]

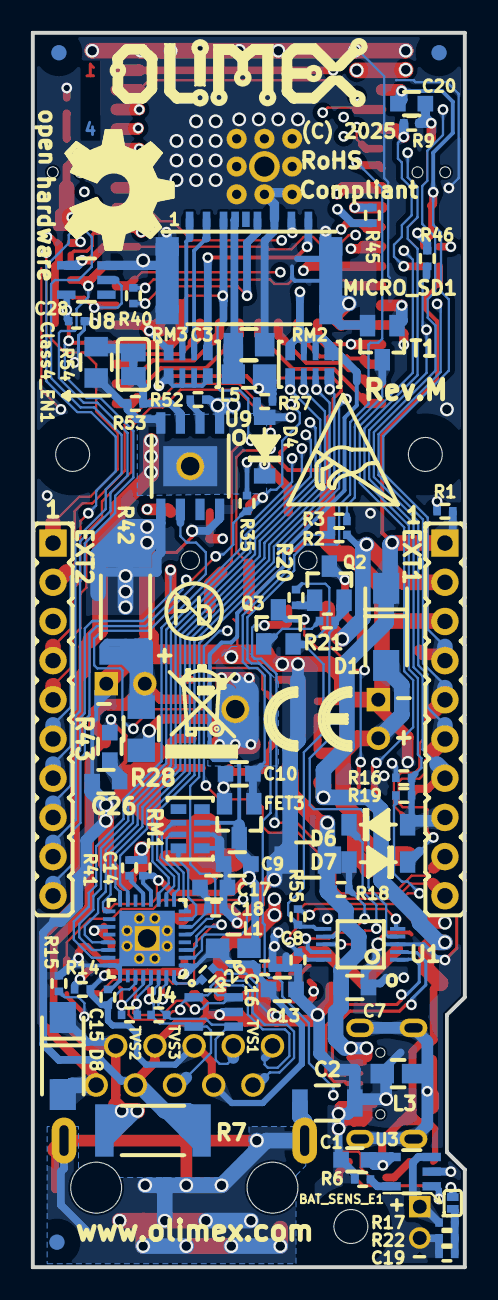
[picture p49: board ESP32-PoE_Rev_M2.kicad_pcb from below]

Board: 4 copper layers, 28.0 x 80.0 mm, 143 parts (84 on the bottom side), 95 nets.

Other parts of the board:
C29: NA(120pF/50V/5%/C0G/C0402); C_0402_5MIL_DWS
CE: CE_Sign
Logo_OSHW: LOGO_OPENHARDWARE_8x8
Logo_Olimex: OLIMEX_LOGO_TB
R23: 10k/R1206; R_1206_5MIL_DWS
Sign_Antistatic: Val**; LOGO_ANTISTATIC_1
Sign_PB-Free: LOGO_PBFREE
Sign_RecycleBin: LOGO_RECYCLEBIN_1

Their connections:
+3.3V: C29.2; also elsewhere on the board
unnamed 85: C29.1; also elsewhere on the board

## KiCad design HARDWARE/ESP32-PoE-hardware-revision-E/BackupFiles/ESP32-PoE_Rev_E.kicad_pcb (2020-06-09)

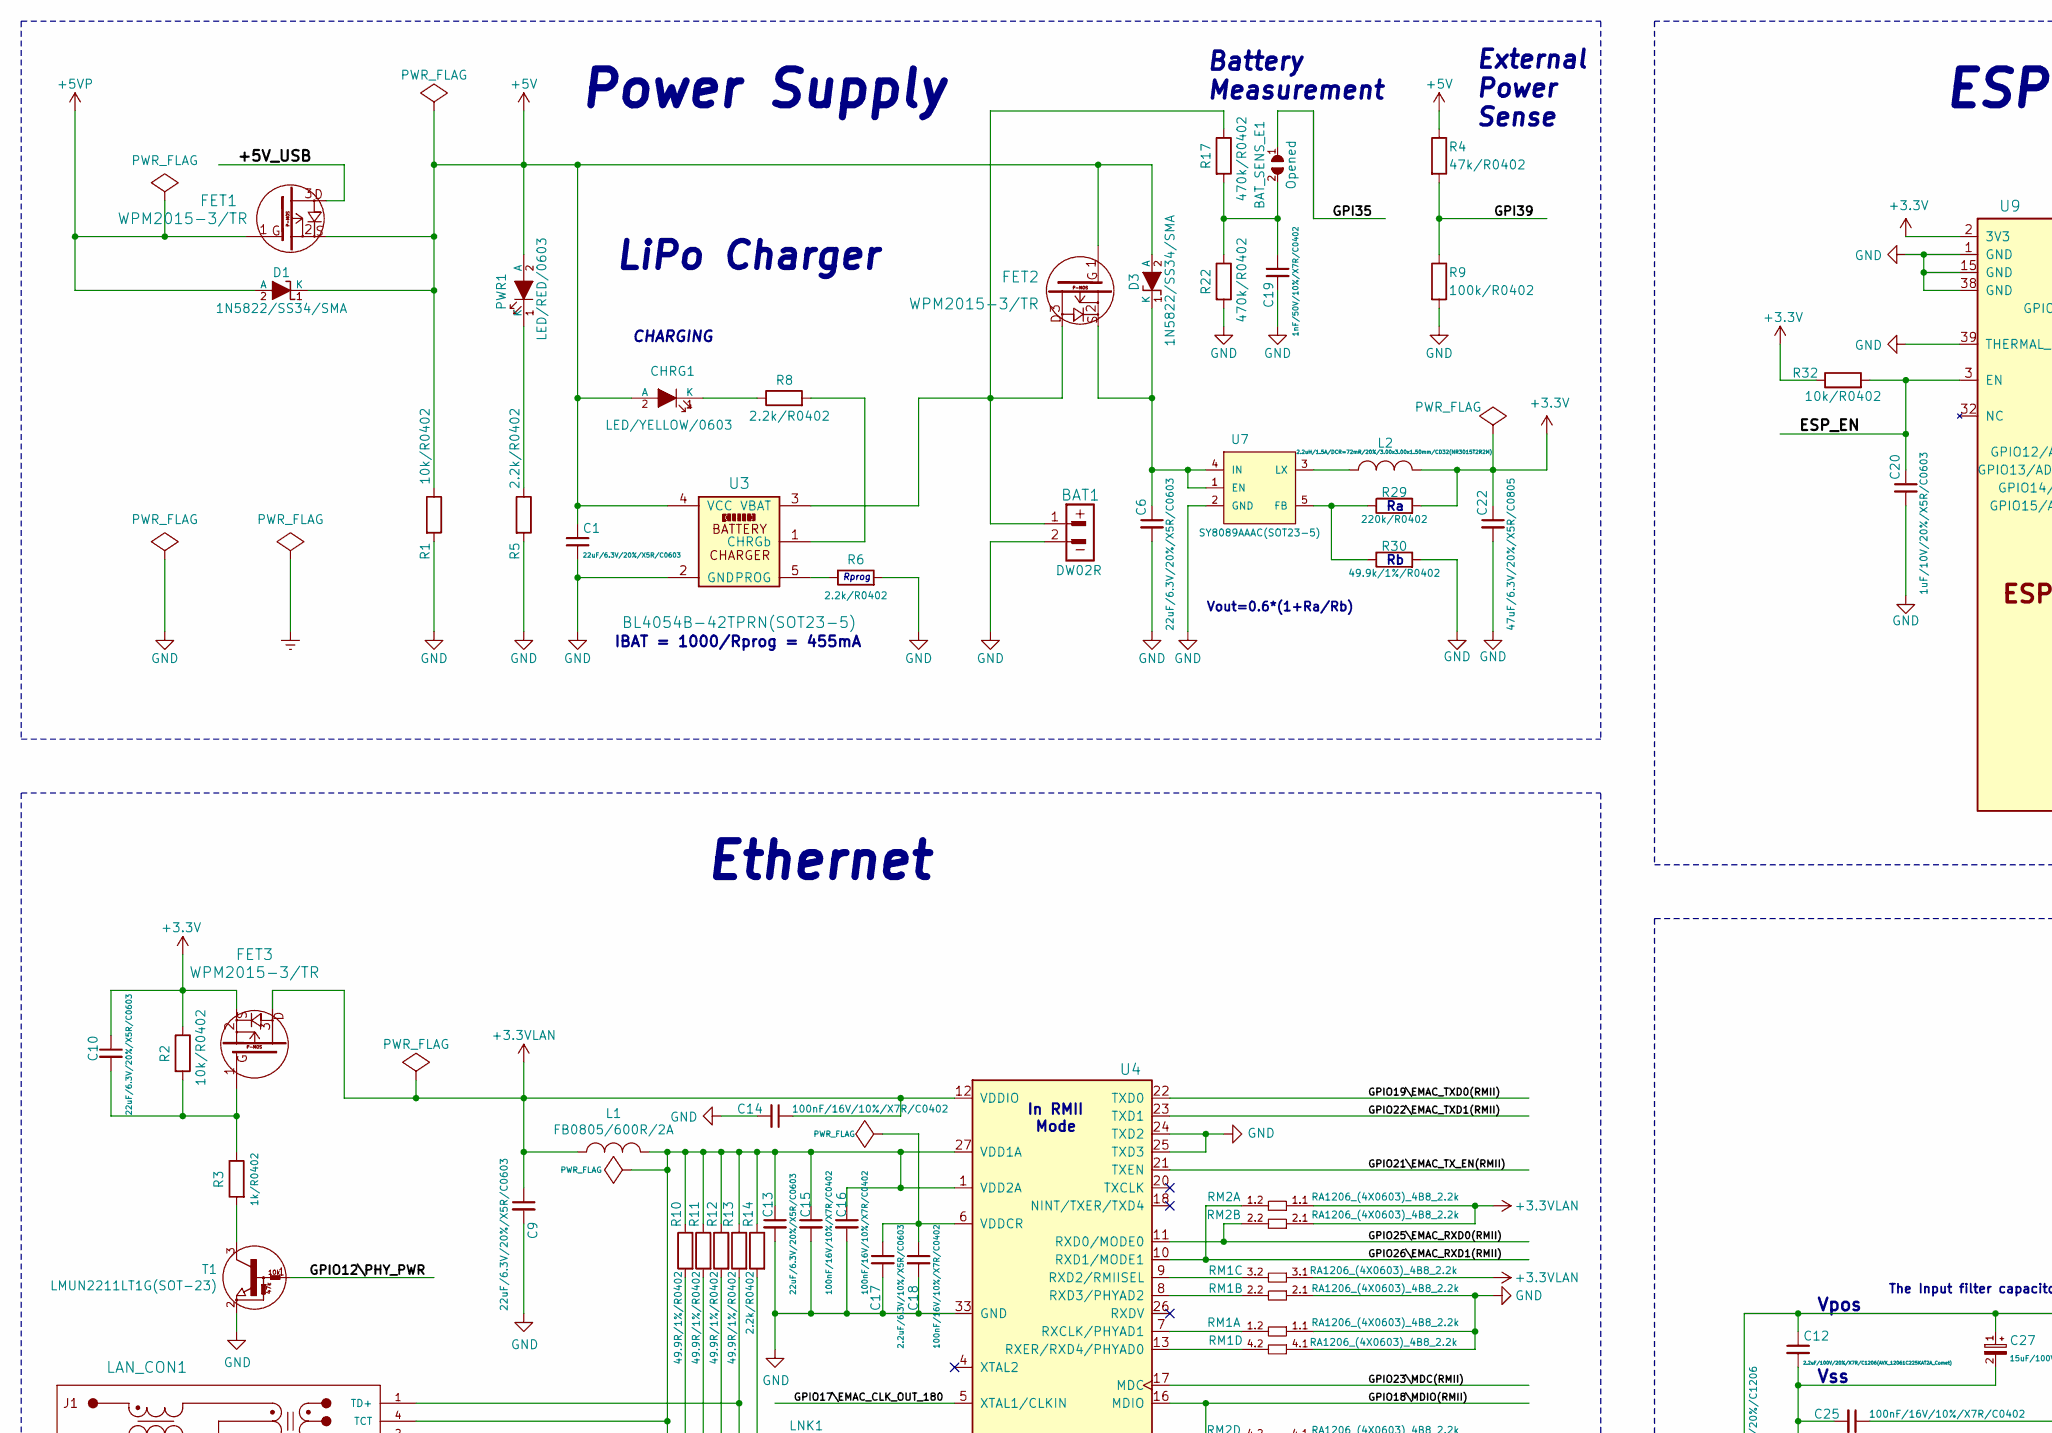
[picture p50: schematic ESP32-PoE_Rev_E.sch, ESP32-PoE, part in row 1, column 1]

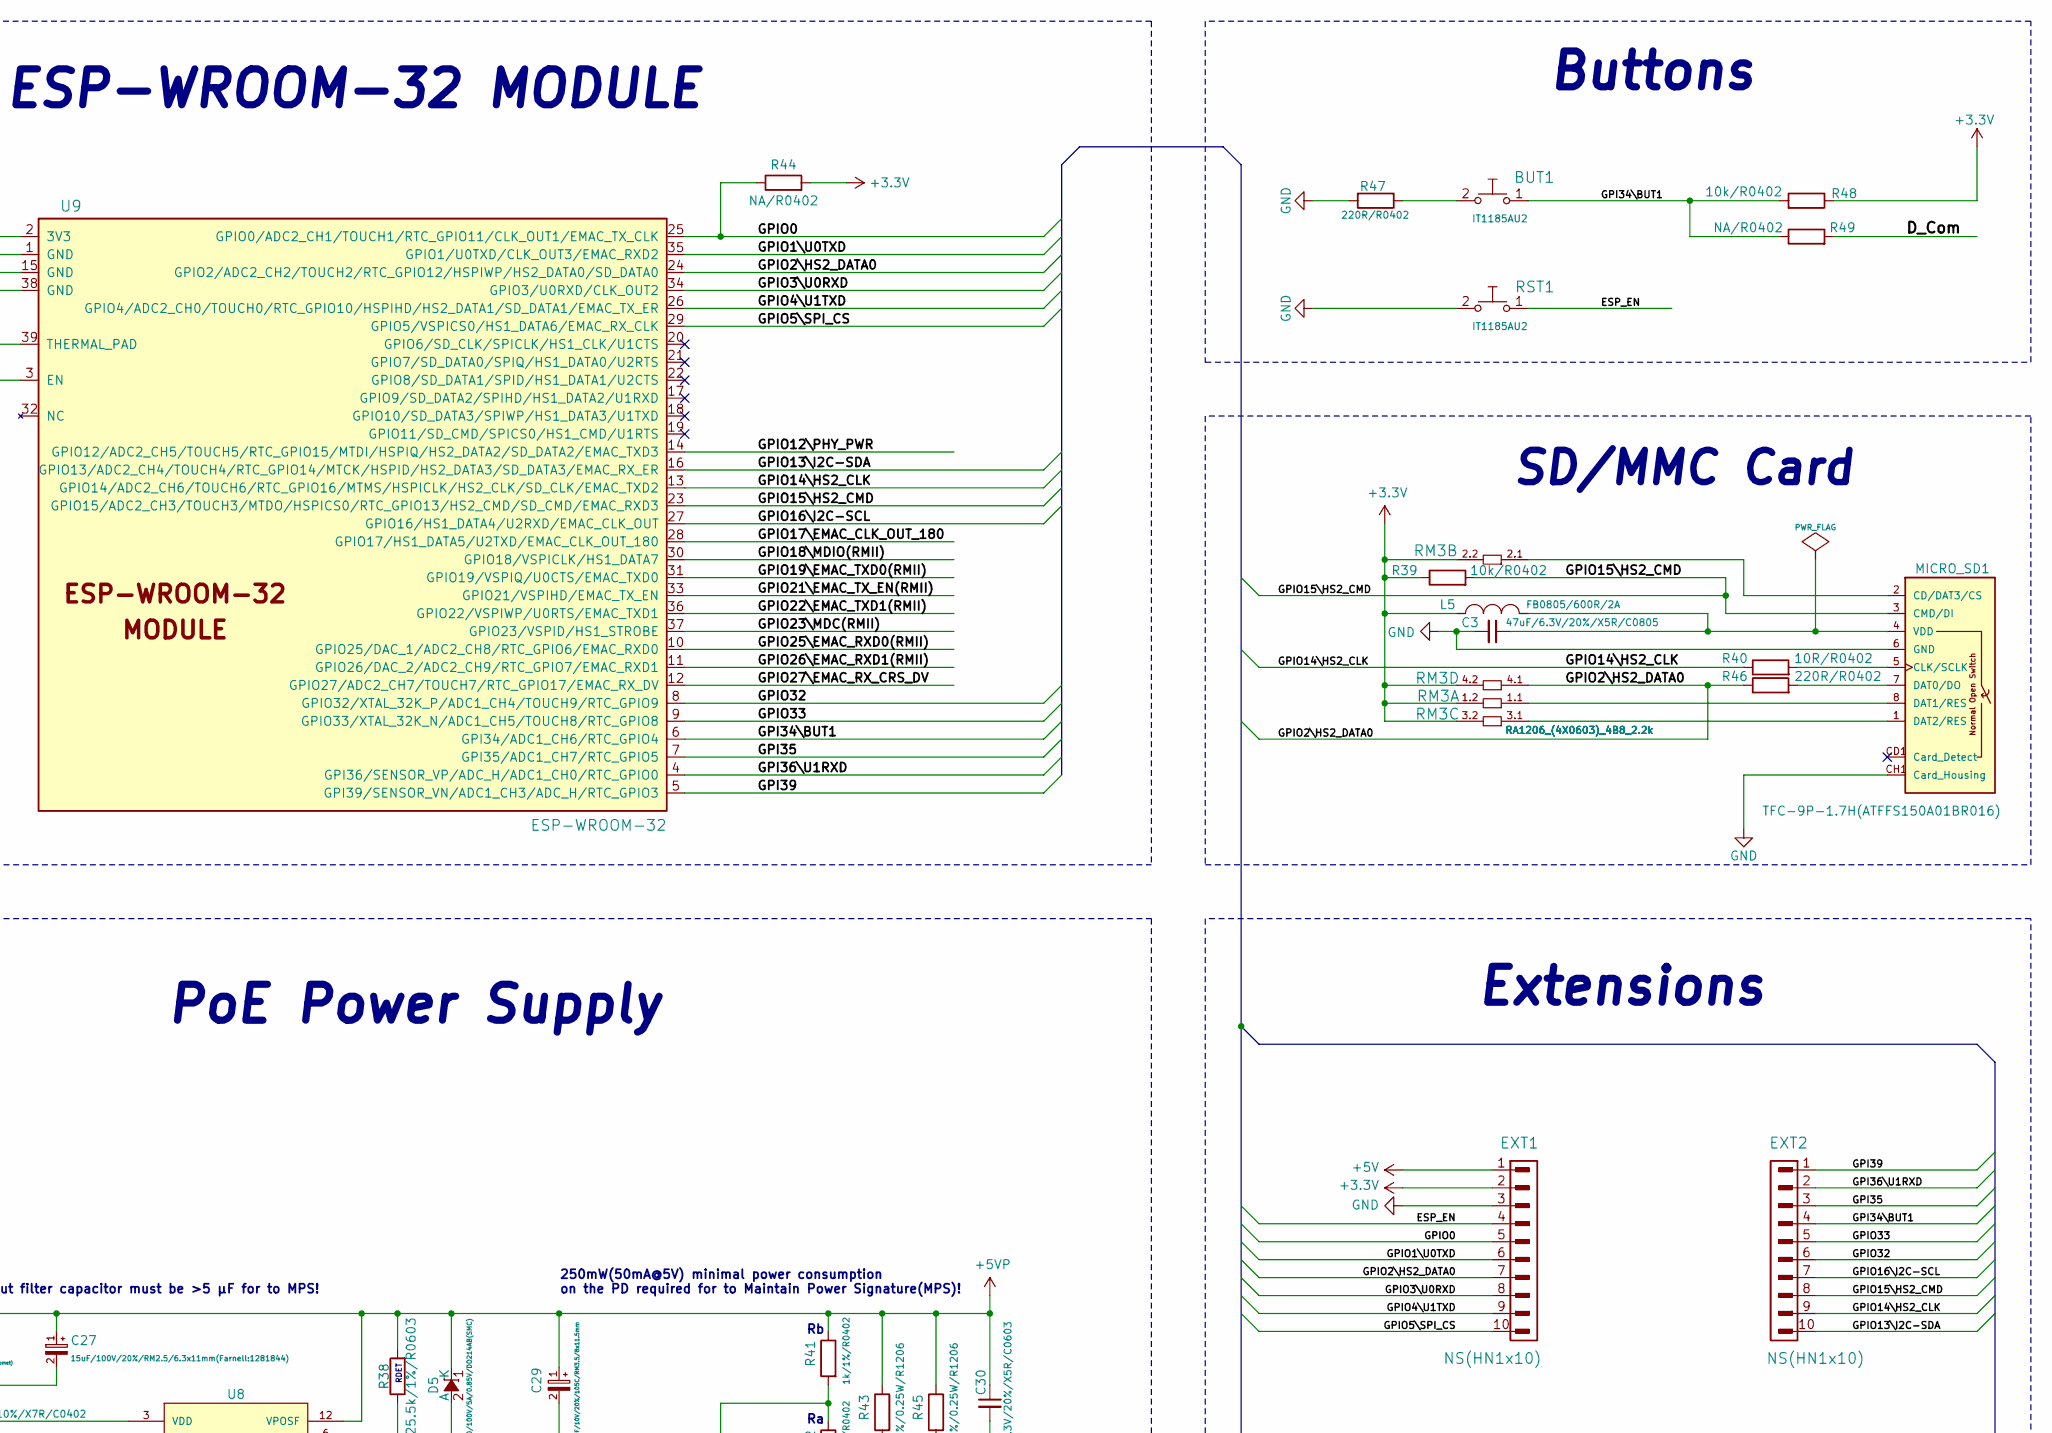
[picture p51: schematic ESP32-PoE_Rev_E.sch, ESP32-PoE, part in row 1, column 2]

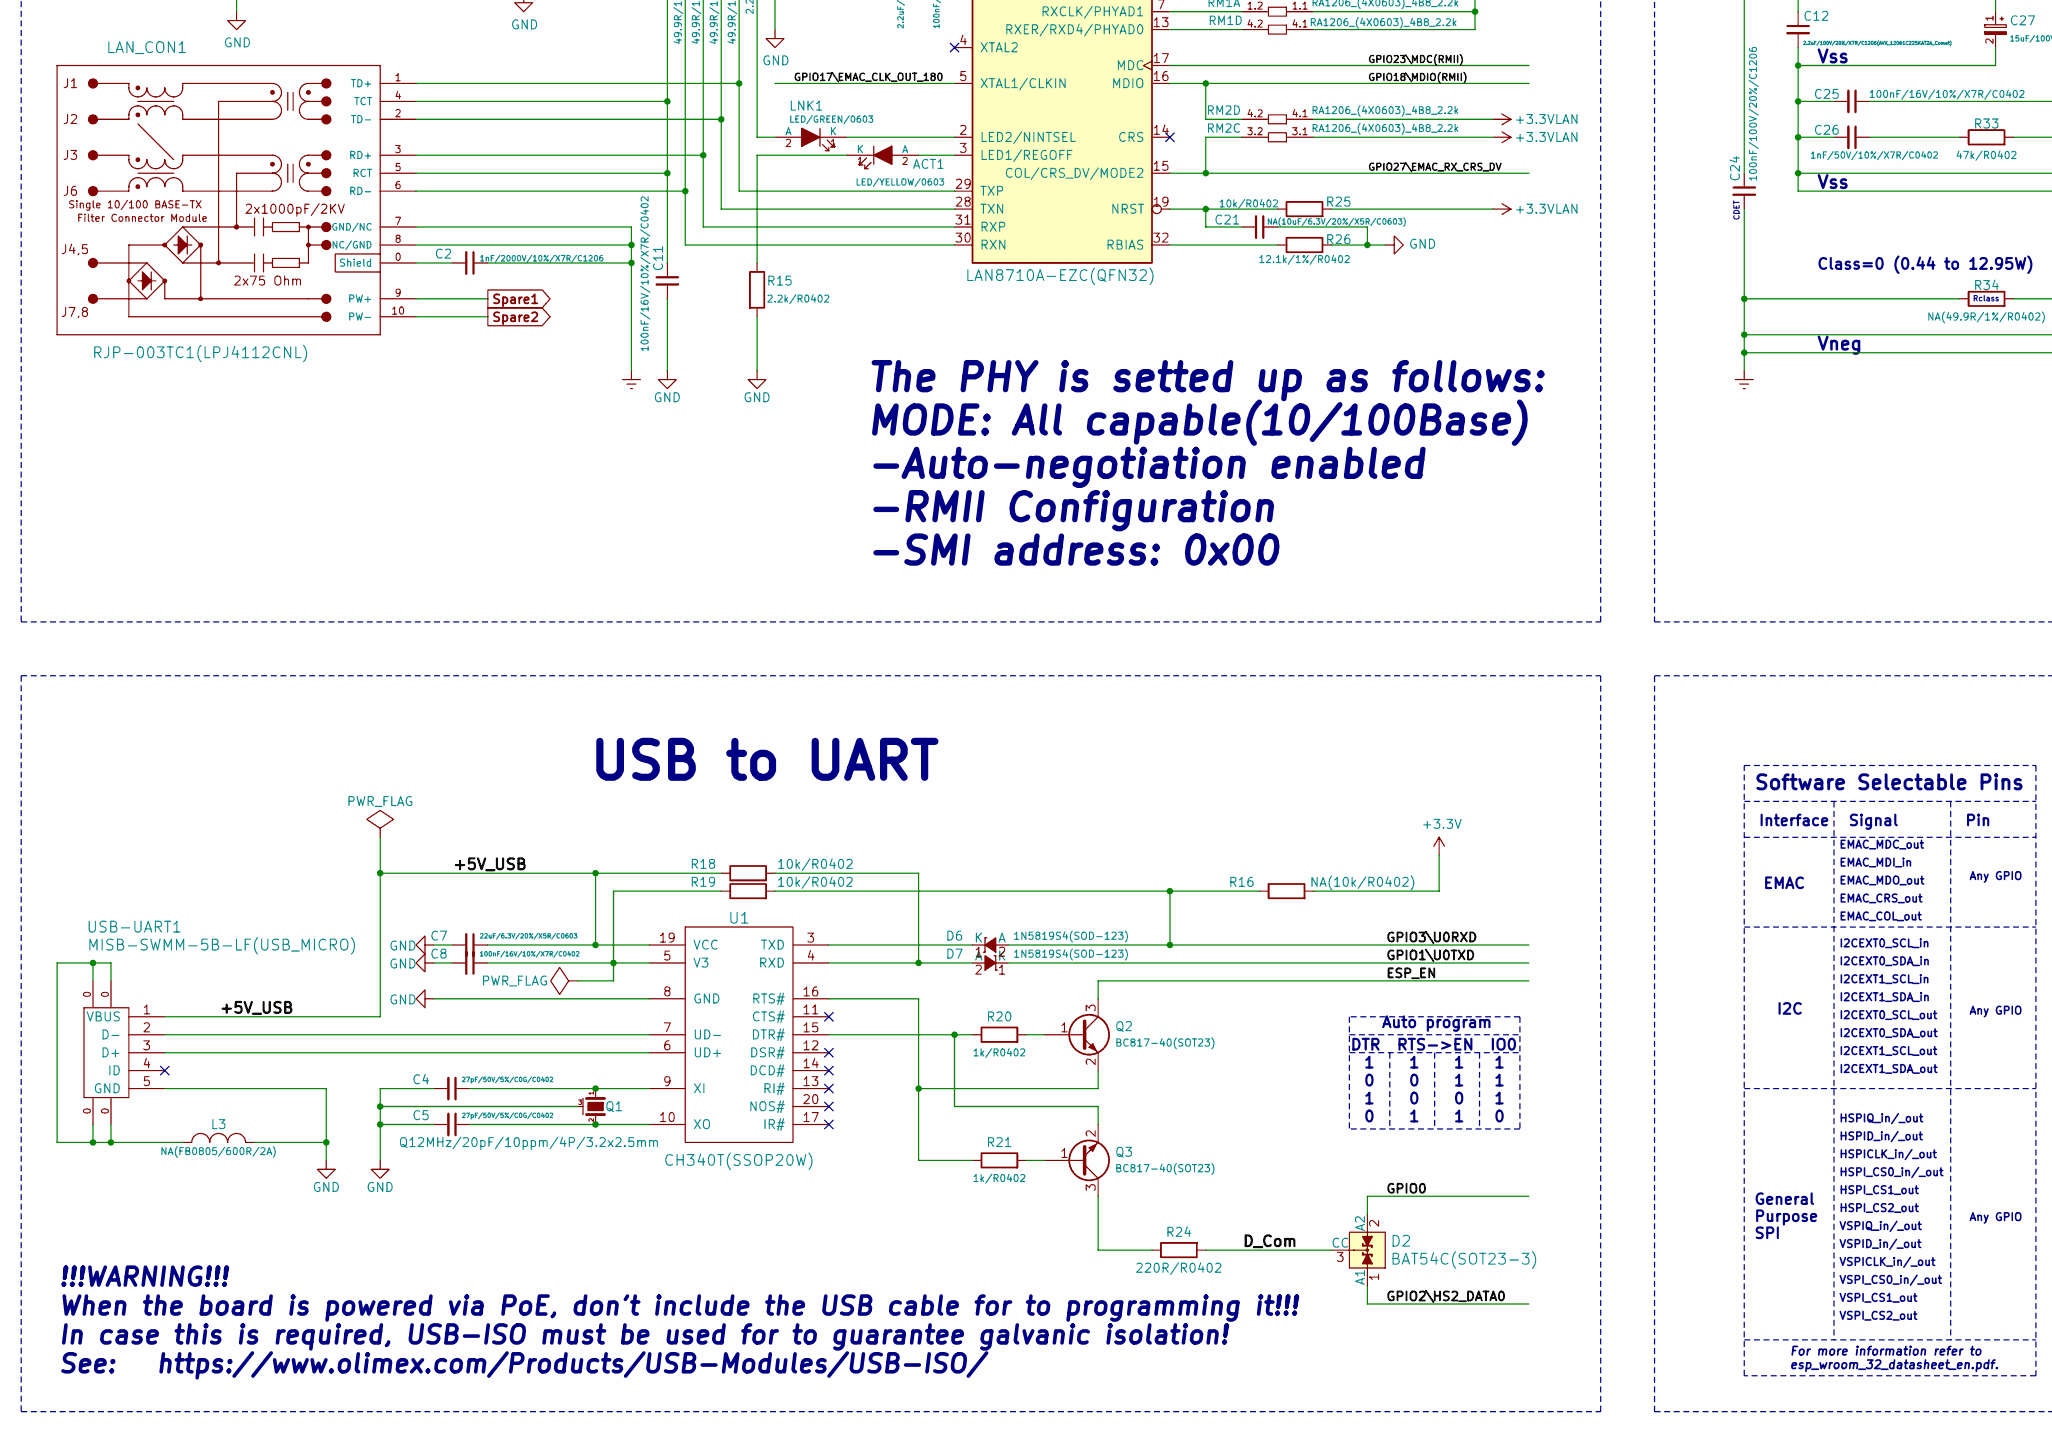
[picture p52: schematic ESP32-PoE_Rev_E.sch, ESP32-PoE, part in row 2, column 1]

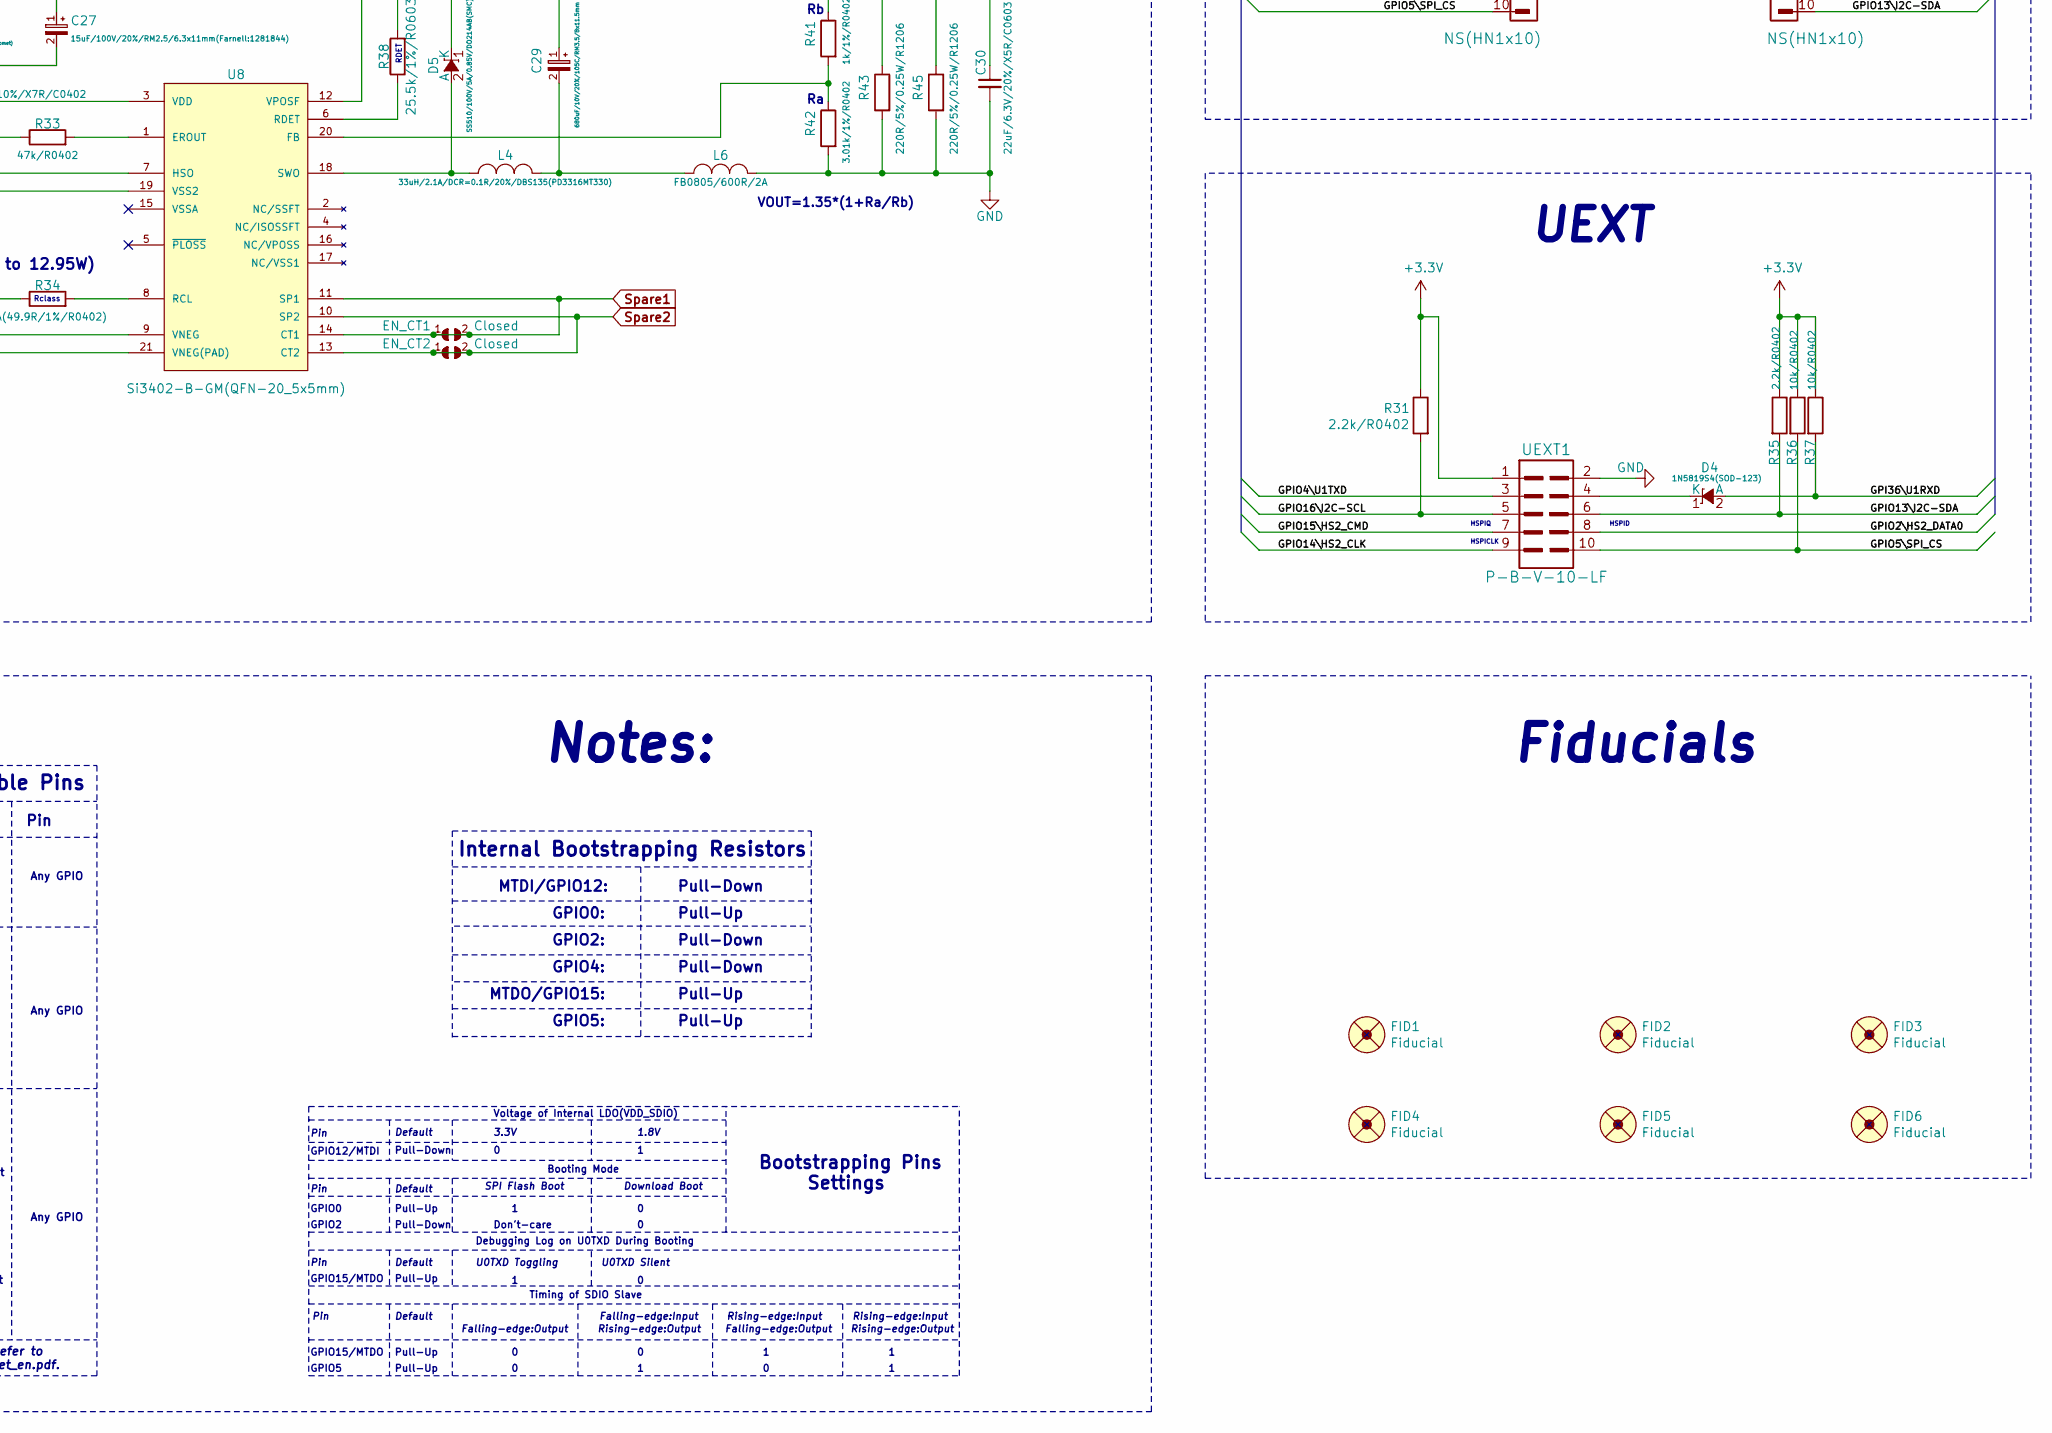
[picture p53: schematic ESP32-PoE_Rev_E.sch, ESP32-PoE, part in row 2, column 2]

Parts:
ACT1: LED/YELLOW/0603; LED_0603_KA
BAT1: DW02R; LIPO_BAT-CON2DW02R
BAT_SENS_E1: Opened; SJ_1_SMALLER
BUT1: IT1185AU2; IT1185AU2_V2
C1, C6, C7, C9, C10, C13, C30: 22uF/6.3V/20%/X5R/C0603; C_0603_5MIL_DWS
C2: 1nF/2000V/10%/X7R/C1206; C_1206_5MIL_DWS_ISO
C3, C22: 47uF/6.3V/20%/X5R/C0805; C_0805_5MIL_DWS
C4, C5: 27pF/50V/5%/C0G/C0402; C_0402_5MIL_DWS
C8, C11, C14, C15, C16, C18, C25: 100nF/16V/10%/X7R/C0402; C_0402_5MIL_DWS
C12: 2.2uF/100V/20%/X7R/C1206(AVX_12061C225KAT2A_Comet); C_1206_5MIL_DWS_ISO
C17: 2.2uF/6.3V/10%/X5R/C0603; C_0603_5MIL_DWS
C19, C26: 1nF/50V/10%/X7R/C0402; C_0402_5MIL_DWS
C20: 1uF/10V/20%/X5R/C0603; C_0603_5MIL_DWS
C21: NA(10uF/6.3V/20%/X5R/C0603); C_0603_5MIL_DWS
C24: 100nF/100V/20%/C1206; C_1206_5MIL_DWS
C27: 15uF/100V/20%/RM2.5/6.3x11mm(Farnell:1281844); CPOL-RM2.5mm_6.3x11mm_SMD
C29: 680uF/10V/20%/105C/RM3.5/8x11.5mm; CPOL-RM3.5mm_8.0x11.5mm_SMD
CHRG1: LED/YELLOW/0603; LED_0603_KA
D1, D3: 1N5822/SS34/SMA; SMA-KA
D2: BAT54C(SOT23-3); SOT23-3
D4, D6, D7: 1N5819S4(SOD-123); SOD-123_1C-2A_KA
D5: SS510/100V/5A/0.85V/DO214AB(SMC); DO214AB(SMC)_1(K)-2(A)
EN_CT1, EN_CT2: Closed; SJ_1_SMALLER
EXT1, EXT2: NS(HN1x10); HN1x10
FET1, FET2, FET3: WPM2015-3/TR; SOT23
FID1, FID2, FID3, FID4, FID5, FID6: Fiducial; Fiducial1x3
L1, L5, L6: FB0805/600R/2A; L_0805_5MIL_DWS
L2: 2.2uH/1.5A/DCR=72mR/20%/3.00x3.00x1.50mm/CD32(NR3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; CD32
L3: NA(FB0805/600R/2A); L_0805_5MIL_DWS
L4: 33uH/2.1A/DCR=0.1R/20%/DBS135(PD3316MT330); DBS135
LAN_CON1: RJP-003TC1(LPJ4112CNL)
LNK1: LED/GREEN/0603; LED_0603_KA
MICRO_SD1: TFC-9P-1.7H(ATFFS150A01BR016); uSD(TFC-9P-1.xH(ATFFS150A01BR016))
PWR1: LED/RED/0603; LED_0603_KA
Q1: Q12MHz/20pF/10ppm/4P/3.2x2.5mm; TSX-3.2x2.5mm_GND(3)
Q2, Q3: BC817-40(SOT23); SOT23
R1, R2, R18, R19, R25, R32, R36, R37, R39, R48: 10k/R0402; R_0402_5MIL_DWS
R3, R20, R21: 1k/R0402; R_0402_5MIL_DWS
R4, R33: 47k/R0402; R_0402_5MIL_DWS
R5, R6, R8, R14, R15, R31, R35: 2.2k/R0402; R_0402_5MIL_DWS
R9: 100k/R0402; R_0402_5MIL_DWS
R10, R11, R12, R13: 49.9R/1%/R0402; R_0402_5MIL_DWS
R16: NA(10k/R0402); R_0402_5MIL_DWS
R17, R22: 470k/R0402; R_0402_5MIL_DWS
R24, R46, R47: 220R/R0402; R_0402_5MIL_DWS
R26: 12.1k/1%/R0402; R_0402_5MIL_DWS
R29: 220k/R0402; R_0402_5MIL_DWS
R30: 49.9k/1%/R0402; R_0402_5MIL_DWS
R34: NA(49.9R/1%/R0402); R_0402_5MIL_DWS
R38: 25.5k/1%/R0603; R_0603_5MIL_DWS
R40: 10R/R0402; R_0402_5MIL_DWS
R41: 1k/1%/R0402; R_0402_5MIL_DWS
R42: 3.01k/1%/R0402; R_0402_5MIL_DWS
R43, R45: 220R/5%/0.25W/R1206; R_1206_5MIL_DWS
R44, R49: NA/R0402; R_0402_5MIL_DWS
RM1, RM2, RM3: RA1206_(4X0603)_4B8_2.2k; R_MATRIX_4
RST1: IT1185AU2; IT1185AU2_V2
T1: LMUN2211LT1G(SOT-23); SOT23
U1: CH340T(SSOP20W); SSOP-20W
U3: BL4054B-42TPRN(SOT23-5); SOT-23-5
U4: LAN8710A-EZC(QFN32); QFN32_EP(33)_5.00x5.00x0.90mm_Pitch_0.50mm
U7: SY8089AAAC(SOT23-5); SOT-23-5
U8: Si3402-B-GM(QFN-20_5x5mm); QFN-20_5x5mm(Si3402-B-GM)
U9: ESP-WROOM-32; ESP-WROOM-32_MODULE
UEXT1: P-B-V-10-LF; GBH-254-SMT-10
USB-UART1: MISB-SWMM-5B-LF(USB_MICRO); USB-MICRO_MISB-SWMM-5B_LF

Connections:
+3.3VLAN: C9.1, C14.1, FET3.3, L1.1, R25.2, RM1.3.1, RM2.1.1, RM2.2.1, RM2.3.1, RM2.4.1, U4.12 (VDDIO)
+3V3: C10.1, C22.1, EXT1.2, FET3.2, L2.2, L5.1, R2.1, R16.2, R29.2, R31.1, R32.1, R35.1, R36.1, R37.1, R39.1, R44.2, R48.1, RM3.1.2, RM3.2.2, RM3.3.2, RM3.4.2, U9.2 (3V3), UEXT1.1
+5V: C1.1, CHRG1.2 (A), D1.1 (K), D3.2 (A), EXT1.1, FET1.2, FET2.1, PWR1.2 (A), R1.1, R4.1, U3.4 (VCC)
+5VP: C12.1, C24.1, C27.1 (+), C29.1 (+), C30.1, D1.2 (A), D5.1 (K), FET1.1, R38.2, R41.1, R43.1, R45.1, U8.12 (VPOSF)
/+5V_USB: C7.1, FET1.3, R18.1, U1.19 (VCC), USB-UART1.1 (VBUS)
/D_Com: D2.3 (CC), R24.2, R49.2
/ESP_EN: C20.1, EXT1.4, Q2.3 (C), R32.2, RST1.1, U9.3 (EN)
/GPI34\BUT1: BUT1.1, EXT2.4, R48.2, R49.1, U9.6 (GPI34/ADC1_CH6/RTC_GPIO4)
/GPI35: BAT_SENS_E1.1, EXT2.3, U9.7 (GPI35/ADC1_CH7/RTC_GPIO5)
/GPI36\U1RXD: D4.2 (A), EXT2.2, R37.2, U9.4 (GPI36/SENSOR_VP/ADC_H/ADC1_CH0/RTC_GPIO0)
/GPI39: EXT2.1, R4.2, R9.1, U9.5 (GPI39/SENSOR_VN/ADC1_CH3/ADC_H/RTC_GPIO3)
/GPIO0: D2.2 (A2), EXT1.5, R44.1, U9.25 (GPIO0/ADC2_CH1/TOUCH1/RTC_GPIO11/CLK_OU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)
/GPIO1\U0TXD: D7.1 (K), EXT1.6, U9.35 (GPIO1/U0TXD/CLK_OUT3/EMAC_RXD2)
/GPIO2\HS2_DATA0: D2.1 (A1), EXT1.7, R46.1, RM3.4.1, U9.24 (GPIO2/ADC2_CH2/TOUCH2/RTC_GPIO12/HSPIWP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), UEXT1.8
/GPIO3\U0RXD: D6.2 (A), EXT1.8, R16.1, R19.2, U9.34 (GPIO3/U0RXD/CLK_OUT2)
/GPIO4\U1TXD: EXT1.9, U9.26 (GPIO4/ADC2_CH0/TOUCH0/RTC_GPIO10/HSPIHD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), UEXT1.3
/GPIO5\SPI_CS: EXT1.10, R36.2, U9.29 (GPIO5/VSPICS0/HS1_DATA6/EMAC_RX_CLK), UEXT1.10
/GPIO12\PHY_PWR: T1.1 (B), U9.14 (GPIO12/ADC2_CH5/TOUCH5/RTC_GPIO15/MTDI/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)
/GPIO13\I2C-SDA: EXT2.10, R35.2, U9.16 (GPIO13/ADC2_CH4/TOUCH4/RTC_GPIO14/MTCK/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), UEXT1.6
/GPIO14\HS2_CLK: EXT2.9, R40.1, U9.13 (GPIO14/ADC2_CH6/TOUCH6/RTC_GPIO16/MTMS/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), UEXT1.9
/GPIO15\HS2_CMD: EXT2.8, MICRO_SD1.3 (CMD/DI), R39.2, U9.23 (GPIO15/ADC2_CH3/TOUCH3/MTDO/HSPICS0/RTC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), UEXT1.7
/GPIO16\I2C-SCL: EXT2.7, R31.2, U9.27 (GPIO16/HS1_DATA4/U2RXD/EMAC_CLK_OUT), UEXT1.5
/GPIO17\EMAC_CLK_OUT_180: U4.5 (XTAL1/CLKIN), U9.28 (GPIO17/HS1_DATA5/U2TXD/EMAC_CLK_OUT_180)
/GPIO18\MDIO(RMII): RM2.4.2, U4.16 (MDIO), U9.30 (GPIO18/VSPICLK/HS1_DATA7)
/GPIO19\EMAC_TXD0(RMII): U4.22 (TXD0), U9.31 (GPIO19/VSPIQ/U0CTS/EMAC_TXD0)
/GPIO21\EMAC_TX_EN(RMII): U4.21 (TXEN), U9.33 (GPIO21/VSPIHD/EMAC_TX_EN)
/GPIO22\EMAC_TXD1(RMII): U4.23 (TXD1), U9.36 (GPIO22/VSPIWP/U0RTS/EMAC_TXD1)
/GPIO23\MDC(RMII): U4.17 (MDC), U9.37 (GPIO23/VSPID/HS1_STROBE)
/GPIO25\EMAC_RXD0(RMII): RM2.2.2, U4.11 (RXD0/MODE0), U9.10 (GPIO25/DAC_1/ADC2_CH8/RTC_GPIO6/EMAC_RX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)
/GPIO26\EMAC_RXD1(RMII): RM2.1.2, U4.10 (RXD1/MODE1), U9.11 (GPIO26/DAC_2/ADC2_CH9/RTC_GPIO7/EMAC_RX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)
/GPIO27\EMAC_RX_CRS_DV: RM2.3.2, U4.15 (COL/CRS_DV/MODE2), U9.12 (GPIO27/ADC2_CH7/TOUCH7/RTC_GPIO17/EMAC_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)
/GPIO32: EXT2.6, U9.8 (GPIO32/XTAL_32K_P/ADC1_CH4/TOUCH9/RTC_G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)
/GPIO33: EXT2.5, U9.9 (GPIO33/XTAL_32K_N/ADC1_CH5/TOUCH8/RTC_G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)
Earth: C2.1, C24.2, LAN_CON1.7 (GND/NC), LAN_CON1.8 (NC/GND), R34.1, U8.9 (VNEG), U8.21 (VNEG(PAD))
GND: BAT1.2, C1.2, C3.2, C4.2, C5.2, C6.2, C7.2, C8.2, C9.2, C11.2, C13.2, C14.2, C15.2, C16.2, C17.2, C18.2, C19.2, C20.2, C21.1, C22.2, C30.2, EXT1.3, L3.2, L6.2, MICRO_SD1.6 (GND), MICRO_SD1.CH1 (Card_Housing), Q1.3 (case), R1.2, R5.2, R6.2, R9.2, R15.2, R22.2, R26.2, R30.2, R42.2, R43.2, R45.2, R47.2, RM1.1.1, RM1.2.1, RM1.4.1, RST1.2, T1.2 (E), U1.8 (GND), U3.2 (GND), U4.24 (TXD2), U4.25 (TXD3), U4.33 (GND), U7.2 (GND), U9.1 (GND), U9.15 (GND), U9.38 (GND), U9.39 (THERMAL_PAD), UEXT1.2, USB-UART1.5 (GND)
unnamed: ACT1.1 (K), R15.1
unnamed: ACT1.2 (A), U4.3 (LED1/REGOFF)
unnamed: BAT1.1, FET2.3, R17.1, U3.3 (VBAT)
unnamed: BAT_SENS_E1.2, C19.1, R17.2, R22.1
unnamed: BUT1.2, R47.1
unnamed: C2.2, LAN_CON1.0 (Shield)
unnamed: C3.1, L5.2, MICRO_SD1.4 (VDD)
unnamed: C4.1, Q1.1, U1.9 (XI)
unnamed: C5.1, Q1.2, U1.10 (XO)
unnamed: C6.1, D3.1 (K), FET2.2, U7.1 (EN), U7.4 (IN)
unnamed: C8.1, R19.1, U1.5 (V3)
unnamed: C10.2, FET3.1, R2.2, R3.1
unnamed: C11.1, C13.1, C15.1, C16.1, L1.2, LAN_CON1.4 (TCT), LAN_CON1.5 (RCT), R10.1, R11.1, R12.1, R13.1, R14.1, U4.1 (VDD2A), U4.27 (VDD1A)
unnamed: C12.2, C25.2, C26.2, C27.2 (-), U8.7 (HSO), U8.19 (VSS2)
unnamed: C17.1, C18.1, U4.6 (VDDCR)
unnamed: C21.2, R25.1, U4.19 (NRST)
unnamed: C25.1, U8.3 (VDD)
unnamed: C26.1, R33.1
unnamed: C29.2 (-), L4.2, L6.1
unnamed: CHRG1.1 (K), R8.1
unnamed: D4.1 (K), UEXT1.4
unnamed: D5.2 (A), L4.1, U8.18 (SWO)
unnamed: D6.1 (K), U1.3 (TXD)
unnamed: D7.2 (A), R18.2, U1.4 (RXD)
unnamed: L2.1, U7.3 (LX)
unnamed: L3.1, USB-UART1.0
unnamed: LAN_CON1.1 (TD+), R13.2, U4.29 (TXP)
unnamed: LAN_CON1.2 (TD-), R12.2, U4.28 (TXN)
unnamed: LAN_CON1.3 (RD+), R11.2, U4.31 (RXP)
unnamed: LAN_CON1.6 (RD-), R10.2, U4.30 (RXN)
unnamed: LNK1.1 (K), U4.2 (LED2/NINTSEL)
unnamed: LNK1.2 (A), R14.2
unnamed: MICRO_SD1.1 (DAT2/RES), RM3.3.1
unnamed: MICRO_SD1.2 (CD/DAT3/CS), RM3.2.1
unnamed: MICRO_SD1.5 (CLK/SCLK), R40.2
unnamed: MICRO_SD1.7 (DAT0/DO), R46.2
unnamed: MICRO_SD1.8 (DAT1/RES), RM3.1.1
unnamed: PWR1.1 (K), R5.1
unnamed: Q2.1 (B), R20.2
unnamed: Q2.2 (E), R21.1, U1.16 (RTS#)
unnamed: Q3.1 (B), R21.2
unnamed: Q3.2 (E), R20.1, U1.15 (DTR#)
unnamed: Q3.3 (C), R24.1
unnamed: R3.2, T1.3 (C)
unnamed: R6.1, U3.5 (PROG)
unnamed: R8.2, U3.1 (CHRGb)
unnamed: R26.1, U4.32 (RBIAS)
unnamed: R29.1, R30.1, U7.5 (FB)
unnamed: R33.2, U8.1 (EROUT)
unnamed: R34.2, U8.8 (RCL)
unnamed: R38.1, U8.6 (RDET)
unnamed: R41.2, R42.1, U8.20 (FB)
unnamed: RM1.1.2, U4.7 (RXCLK/PHYAD1)
unnamed: RM1.2.2, U4.8 (RXD3/PHYAD2)
unnamed: RM1.3.2, U4.9 (RXD2/RMIISEL)
unnamed: RM1.4.2, U4.13 (RXER/RXD4/PHYAD0)
unnamed: U1.6 (UD+), USB-UART1.3 (D+)
unnamed: U1.7 (UD-), USB-UART1.2 (D-)
Spare1: EN_CT1.1, EN_CT1.2, LAN_CON1.9 (PW+), U8.11 (SP1), U8.14 (CT1)
Spare2: EN_CT2.1, EN_CT2.2, LAN_CON1.10 (PW-), U8.10 (SP2), U8.13 (CT2)

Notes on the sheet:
Vout=0.6*(1+Ra/Rb)
Power Supply
Buttons
UEXT
In RMII Mode
Ethernet
ESP-WROOM-32 MODULE
SD/MMC Card
Bootstrapping Pins Settings
Internal Bootstrapping Resistors
MTDI/GPIO12:
Pull-Down
GPIO0:
Pull-Up
GPIO2:
GPIO4:
MTDO/GPIO15:
GPIO5:
Voltage of Internal LDO(VDD_SDIO)
Pin
Default
3.3V
1.8V
Booting Mode
GPIO12/MTDI
GPIO0
GPIO2
SPI Flash Boot
Download Boot
Don't-care
Debugging Log on U0TXD During Booting
U0TXD Toggling
U0TXD Silent
GPIO15/MTDO
Timing of SDIO Slave
For more information refer to esp_wroom_32_datasheet_en.pdf.
Falling-edge:Output
Falling-edge:Input
Rising-edge:Output
Rising-edge:Input

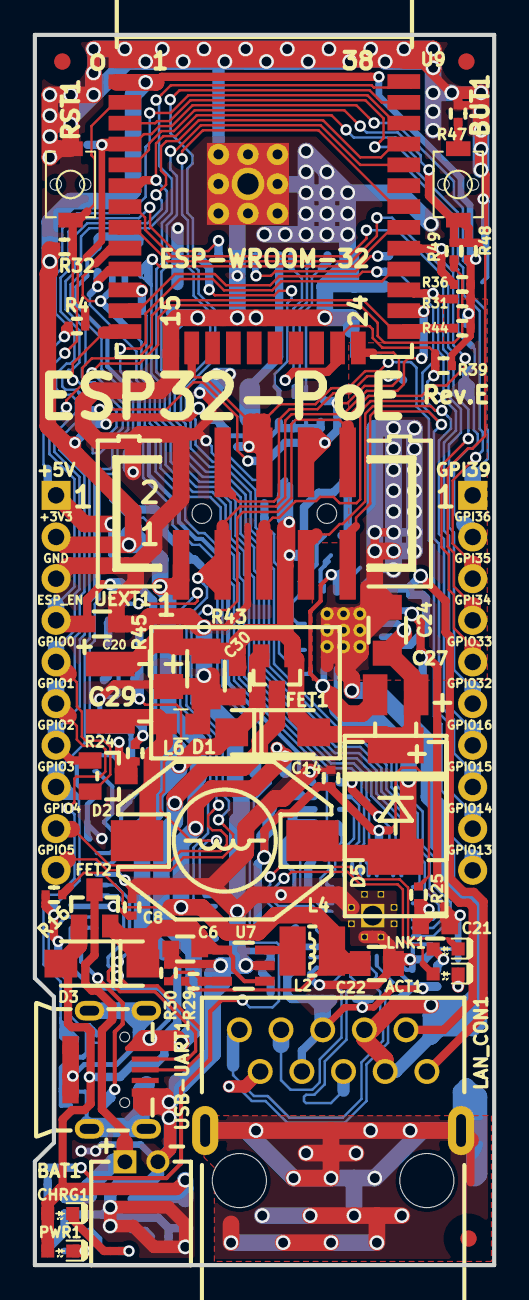
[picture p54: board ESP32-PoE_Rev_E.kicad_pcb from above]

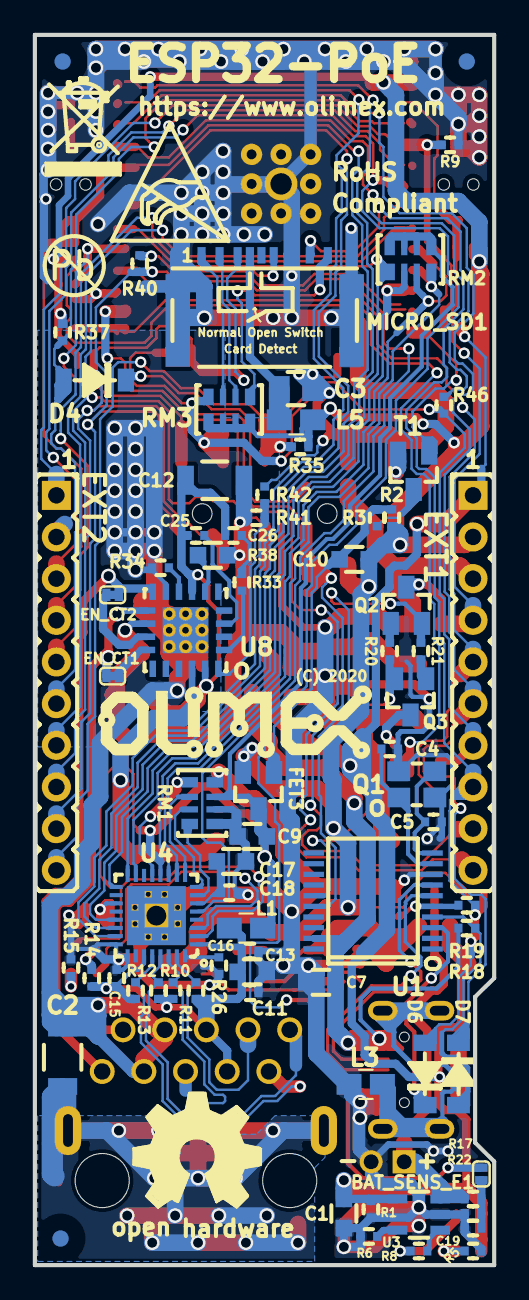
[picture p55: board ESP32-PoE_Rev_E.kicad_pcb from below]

Board: 2 copper layers, 28.0 x 75.0 mm, 129 parts (79 on the bottom side), 95 nets.

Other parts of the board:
Logo_OSHW: LOGO_OPENHARDWARE_8x8
Logo_Olimex: OLIMEX_LOGO_TB
Sign_Antistatic: Val**; LOGO_ANTISTATIC_1
Sign_PB-Free: LOGO_PBFREE
Sign_RecycleBin: LOGO_RECYCLEBIN_1

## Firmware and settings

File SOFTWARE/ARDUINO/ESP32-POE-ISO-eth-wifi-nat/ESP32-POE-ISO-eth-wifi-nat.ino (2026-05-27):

/*
  Olimex ESP32-POE-ISO Ethernet-to-WiFi NAT Router Demo
  =====================================================

  Board:
    Olimex ESP32-POE-ISO
    ESP32-WROOM module
    LAN8720A / LAN87xx Ethernet PHY

  Demo purpose:
    Ethernet is used as WAN/uplink.
    WiFi SoftAP is used as LAN/downlink.
    A phone/laptop connects to the ESP32 WiFi AP and gets internet through
    Ethernet using NAT/NAPT.
    Debug info printed over the ESP32's serial; test page available on the phone/laptop

  WiFi AP:
    SSID:     OLIMEX-ESP32-POE-ISO
    Password: 12345678

  Debug page:
    http://192.168.4.1/

  Tested reference environment:
    Arduino IDE: 1.8.19
    ESP32 Arduino core: 3.3.8
    Selected board: ESP32 Dev Module
    CPU frequency: 240 MHz
    Flash mode: QIO
    Flash frequency: 80 MHz
    Flash size: 4 MB
    PSRAM: Disabled
    Upload speed: 921600

  ESP32-POE-ISO Ethernet settings:
    PHY type:   ETH_PHY_LAN8720
    PHY addr:   0
    PHY power:  GPIO12
    MDC:        GPIO23
    MDIO:       GPIO18
    RMII clock: ESP32 outputs 50 MHz clock on GPIO17

    ESP32-POE-ISO:
      ESP32 outputs 50 MHz RMII clock -> PHY
      ETH_CLOCK_GPIO17_OUT

  Important PHY power/clock note:
    On ESP32-POE-ISO, GPIO12 controls PHY power/reset behavior.
    The PHY should not be powered before the ESP32 RMII clock is available.
    Therefore this sketch first holds GPIO12 LOW, then lets ETH.begin()
    initialize Ethernet using ETH_CLOCK_GPIO17_OUT and GPIO12 as the power pin.

  NAT/DNS notes:
    NAT must be enabled from lwIP TCP/IP context via tcpip_callback().
    SoftAP DHCP must advertise a real DNS server, here 1.1.1.1.
    Otherwise Android may connect but report "no internet", and normal web
    browsing may fail.
*/

#include <WiFi.h>
#include <ETH.h>
#include <WebServer.h>
#include <NetworkClient.h>

extern "C" {
  #include "lwip/lwip_napt.h"
  #include "lwip/tcpip.h"
  #include "lwip/netif.h"
  #include "lwip/ip4_addr.h"
  #include "esp_netif.h"
}

// -----------------------------------------------------------------------------
// WiFi SoftAP configuration
// -----------------------------------------------------------------------------

#define AP_SSID "OLIMEX-ESP32-POE-ISO"
#define AP_PASS "12345678"

#define AP_IP      IPAddress(192, 168, 4, 1)
#define AP_GATEWAY IPAddress(192, 168, 4, 1)
#define AP_NETMASK IPAddress(255, 255, 255, 0)

// DNS advertised to WiFi clients by the SoftAP DHCP server.
#define AP_DNS_A 1
#define AP_DNS_B 1
#define AP_DNS_C 1
#define AP_DNS_D 1

// -----------------------------------------------------------------------------
// Ethernet configuration for Olimex ESP32-POE-ISO
// -----------------------------------------------------------------------------

#define ETH_PHY_TYPE  ETH_PHY_LAN8720
#define ETH_PHY_ADDR  0
#define ETH_PHY_POWER 12
#define ETH_MDC_PIN   23
#define ETH_MDIO_PIN  18

// ESP32 outputs 50 MHz RMII clock on GPIO17.
#define ETH_CLK_MODE  ETH_CLOCK_GPIO17_OUT

#ifndef OFFER_DNS
  #define OFFER_DNS 2
#endif

// -----------------------------------------------------------------------------
// Global state
// -----------------------------------------------------------------------------

WebServer server(80);

bool ethUp = false;
bool natEnabled = false;
bool natRequested = false;

uint32_t natEnableAttempts = 0;
uint32_t lastWanTestMs = 0;
bool lastWanTcpTest = false;

esp_netif_t *ethNetif = NULL;
esp_netif_t *apNetif = NULL;

// -----------------------------------------------------------------------------
// ESP-NETIF helpers
// -----------------------------------------------------------------------------

void findNetifs() {
  ethNetif = esp_netif_get_handle_from_ifkey("ETH_DEF");
  apNetif  = esp_netif_get_handle_from_ifkey("WIFI_AP_DEF");

  Serial.println();
  Serial.println("[ESP-NETIF] Handles:");

  Serial.print("[ESP-NETIF] ETH_DEF: ");
  Serial.println((uint32_t)ethNetif, HEX);

  Serial.print("[ESP-NETIF] WIFI_AP_DEF: ");
  Serial.println((uint32_t)apNetif, HEX);
}

// -----------------------------------------------------------------------------
// Configure SoftAP DHCP DNS
// -----------------------------------------------------------------------------

void setApDnsDhcpOption() {
  esp_netif_t *ap = esp_netif_get_handle_from_ifkey("WIFI_AP_DEF");

  if (!ap) {
    Serial.println("[DNS] WIFI_AP_DEF not found");
    return;
  }

  Serial.println();
  Serial.println("[DNS] Reconfiguring SoftAP DHCP server DNS option");

  esp_err_t err;

  err = esp_netif_dhcps_stop(ap);
  Serial.print("[DNS] esp_netif_dhcps_stop: ");
  Serial.println(err == ESP_OK ? "OK" : "FAILED/ALREADY STOPPED");

  esp_netif_dns_info_t dns;
  memset(&dns, 0, sizeof(dns));

  dns.ip.type = IPADDR_TYPE_V4;
  IP4_ADDR(&dns.ip.u_addr.ip4, AP_DNS_A, AP_DNS_B, AP_DNS_C, AP_DNS_D);

  err = esp_netif_set_dns_info(ap, ESP_NETIF_DNS_MAIN, &dns);
  Serial.print("[DNS] esp_netif_set_dns_info DNS_MAIN = 1.1.1.1: ");
  Serial.println(err == ESP_OK ? "OK" : "FAILED");

  uint8_t dns_offer = OFFER_DNS;

  err = esp_netif_dhcps_option(
    ap,
    ESP_NETIF_OP_SET,
    ESP_NETIF_DOMAIN_NAME_SERVER,
    &dns_offer,
    sizeof(dns_offer)
  );

  Serial.print("[DNS] esp_netif_dhcps_option OFFER_DNS: ");
  Serial.println(err == ESP_OK ? "OK" : "FAILED");

  err = esp_netif_dhcps_start(ap);
  Serial.print("[DNS] esp_netif_dhcps_start: ");
  Serial.println(err == ESP_OK ? "OK" : "FAILED/ALREADY STARTED");

  Serial.println("[DNS] Use DHCP on the phone/client.");
  Serial.println("[DNS] Forget the WiFi network after flashing, then reconnect.");
}

// -----------------------------------------------------------------------------
// lwIP netif scan and NAT enable by AP netif number
// -----------------------------------------------------------------------------

void printLwipNetifsAndEnableNatOnAp() {
  Serial.println();
  Serial.println("[LWIP] netif list:");

  IPAddress apIP = WiFi.softAPIP();

  for (struct netif *n = netif_list; n != NULL; n = n->next) {
    String ip   = String(ip4addr_ntoa(netif_ip4_addr(n)));
    String gw   = String(ip4addr_ntoa(netif_ip4_gw(n)));
    String mask = String(ip4addr_ntoa(netif_ip4_netmask(n)));

    Serial.print("[LWIP] name=");
    Serial.print(n->name[0]);
    Serial.print(n->name[1]);
    Serial.print(" num=");
    Serial.print(n->num);
    Serial.print(" ip=");
    Serial.print(ip);
    Serial.print(" gw=");
    Serial.print(gw);
    Serial.print(" mask=");
    Serial.print(mask);
    Serial.print(" flags=0x");
    Serial.println(n->flags, HEX);

    if (ip == apIP.toString()) {
      Serial.println("[LWIP] This netif matches SoftAP IP");
      Serial.print("[LWIP] Enabling NAPT by netif number: ");
      Serial.println(n->num);

      ip_napt_enable_no(n->num, 1);

      Serial.println("[LWIP] ip_napt_enable_no() called");
    }
  }
}

// -----------------------------------------------------------------------------
// NAT enable callback; runs in lwIP TCP/IP context
// -----------------------------------------------------------------------------

void enableNatCore(void *arg) {
  natEnableAttempts++;

  Serial.println();
  Serial.println("[NAT] tcpip_callback context");
  Serial.print("[NAT] Attempt: ");
  Serial.println(natEnableAttempts);

  findNetifs();

  if (ethNetif) {
    esp_err_t err = esp_netif_set_default_netif(ethNetif);
    Serial.print("[NAT] esp_netif_set_default_netif(ETH_DEF): ");
    Serial.println(err == ESP_OK ? "OK" : "FAILED");
  } else {
    Serial.println("[NAT] ETH_DEF handle not found");
  }

#if ESP_IDF_VERSION_MAJOR >= 5
  if (apNetif) {
    esp_err_t err = esp_netif_napt_enable(apNetif);
    Serial.print("[NAT] esp_netif_napt_enable(WIFI_AP_DEF): ");
    Serial.println(err == ESP_OK ? "OK" : "FAILED/ALREADY ENABLED");
  } else {
    Serial.println("[NAT] WIFI_AP_DEF handle not found");
  }
#endif

  IPAddress apIP = WiFi.softAPIP();

  Serial.print("[NAT] Enabling old lwIP NAPT by AP IP: ");
  Serial.println(apIP);

  ip_napt_enable(apIP, 1);

  Serial.println("[NAT] Scanning lwIP netifs and enabling NAPT by AP netif number");
  printLwipNetifsAndEnableNatOnAp();

  natEnabled = true;
  natRequested = false;

  Serial.println("[NAT] NAT enable sequence finished");
}

void requestNatEnable() {
  if (natEnabled || natRequested) return;

  if (!ethUp) {
    Serial.println("[NAT] Ethernet not up yet");
    return;
  }

  if (WiFi.softAPIP() == IPAddress(0, 0, 0, 0)) {
    Serial.println("[NAT] AP IP is 0.0.0.0");
    return;
  }

  natRequested = true;

  Serial.println("[NAT] Scheduling NAT enable via tcpip_callback()");
  err_t err = tcpip_callback(enableNatCore, NULL);

  if (err != ERR_OK) {
    Serial.print("[NAT] tcpip_callback failed, err=");
    Serial.println((int)err);
    natRequested = false;
  }
}

// -----------------------------------------------------------------------------
// WAN test from ESP32 itself
// -----------------------------------------------------------------------------

bool testWanTcp() {
  if (!ethUp) return false;

  NetworkClient client;

  Serial.println("[WAN TEST] ESP32 connecting to 1.1.1.1:80 over Ethernet route...");

  bool ok = client.connect(IPAddress(1, 1, 1, 1), 80, 3000);

  if (ok) {
    Serial.println("[WAN TEST] ESP32 TCP connect OK");
    client.stop();
    return true;
  }

  Serial.println("[WAN TEST] ESP32 TCP connect FAILED");
  return false;
}

// -----------------------------------------------------------------------------
// Local debug web page at http://192.168.4.1/
// -----------------------------------------------------------------------------

void handleRoot() {
  String s;

  s += "<!doctype html><html><head>";
  s += "<meta name='viewport' content='width=device-width,initial-scale=1'>";
  s += "<meta http-equiv='refresh' content='3'>";
  s += "<title>Olimex ESP32-POE-ISO ETH/WIFI NAT Debug</title>";
  s += "</head><body>";

  s += "<h1>Olimex ESP32-POE-ISO</h1>";
  s += "<h2>Ethernet to WiFi NAT Router Demo</h2>";

  s += "<p>";
  s += "Ethernet is WAN/uplink. WiFi SoftAP is LAN/downlink. ";
  s += "Clients connected to this AP are routed through Ethernet using NAPT.";
  s += "</p>";

  s += "<h2>Ethernet WAN</h2>";
  s += "ETH up: ";
  s += ethUp ? "YES" : "NO";
  s += "<br>ETH IP: ";
  s += ETH.localIP().toString();
  s += "<br>Gateway: ";
  s += ETH.gatewayIP().toString();
  s += "<br>DNS from Ethernet DHCP: ";
  s += ETH.dnsIP().toString();
  s += "<br>ETH MAC: ";
  s += ETH.macAddress();

  s += "<h2>WiFi AP LAN</h2>";
  s += "SSID: ";
  s += AP_SSID;
  s += "<br>AP IP / Gateway: ";
  s += WiFi.softAPIP().toString();
  s += "<br>AP MAC: ";
  s += WiFi.softAPmacAddress();
  s += "<br>Connected clients: ";
  s += String(WiFi.softAPgetStationNum());
  s += "<br>DHCP DNS offered to clients: 1.1.1.1";

  s += "<h2>NAT/NAPT</h2>";
  s += "NAT enabled flag: ";
  s += natEnabled ? "YES" : "NO";
  s += "<br>NAT requested flag: ";
  s += natRequested ? "YES" : "NO";
  s += "<br>NAT enable attempts: ";
  s += String(natEnableAttempts);

  s += "<h2>WAN test from ESP32</h2>";
  s += "TCP connect to 1.1.1.1:80: ";
  s += lastWanTcpTest ? "OK" : "FAILED";

  s += "<h2>Client setup</h2>";
  s += "Use DHCP, not static IP.<br>";
  s += "After flashing, forget this WiFi network and reconnect.";

  s += "<h2>Client tests</h2>";
  s += "1. This page: <b>http://192.168.4.1/</b><br>";
  s += "2. Plain HTTP: <a href='http://neverssl.com/'>http://neverssl.com/</a><br>";
  s += "3. Plain HTTP: <a href='http://example.com/'>http://example.com/</a><br>";
  s += "4. HTTPS/IP: <a href='https://1.1.1.1/'>https://1.1.1.1/</a><br>";

  s += "<h2>Build environment used</h2>";
  s += "Arduino IDE: 1.8.19<br>";
  s += "ESP32 Arduino core: 3.3.8<br>";
  s += "Board: ESP32 Dev Module<br>";
  s += "CPU: 240 MHz<br>";
  s += "Flash mode: QIO<br>";
  s += "Flash frequency: 80 MHz<br>";
  s += "Flash size: 4 MB<br>";
  s += "PSRAM: Disabled<br>";

  s += "</body></html>";

  server.send(200, "text/html", s);
}

// -----------------------------------------------------------------------------
// Serial status
// -----------------------------------------------------------------------------

void printStatus() {
  Serial.println();
  Serial.println("========== ROUTER STATUS ==========");

  Serial.print("ETH up: ");
  Serial.println(ethUp ? "YES" : "NO");

  Serial.print("ETH IP: ");
  Serial.println(ETH.localIP());

  Serial.print("ETH gateway: ");
  Serial.println(ETH.gatewayIP());

  Serial.print("ETH DNS: ");
  Serial.println(ETH.dnsIP());

  Serial.print("ETH MAC: ");
  Serial.println(ETH.macAddress());

  Serial.print("AP SSID: ");
  Serial.println(AP_SSID);

  Serial.print("AP IP: ");
  Serial.println(WiFi.softAPIP());

  Serial.print("AP MAC: ");
  Serial.println(WiFi.softAPmacAddress());

  Serial.print("AP clients: ");
  Serial.println(WiFi.softAPgetStationNum());

  Serial.print("NAT enabled flag: ");
  Serial.println(natEnabled ? "YES" : "NO");

  Serial.print("NAT requested flag: ");
  Serial.println(natRequested ? "YES" : "NO");

  Serial.print("NAT attempts: ");
  Serial.println(natEnableAttempts);

  Serial.print("WAN TCP test from ESP32: ");
  Serial.println(lastWanTcpTest ? "OK" : "FAILED");

  Serial.print("Free heap: ");
  Serial.println(ESP.getFreeHeap());

  Serial.println("===================================");
}

// -----------------------------------------------------------------------------
// Arduino WiFi/Ethernet event handler
// -----------------------------------------------------------------------------

void onEvent(WiFiEvent_t event) {
  switch (event) {
    case ARDUINO_EVENT_ETH_START:
      ETH.setHostname("olimex-esp32-poe-iso");
      Serial.println("[ETH] Started");
      break;

    case ARDUINO_EVENT_ETH_CONNECTED:
      Serial.println("[ETH] Link up");
      break;

    case ARDUINO_EVENT_ETH_GOT_IP:
      ethUp = true;

      Serial.println();
      Serial.println("[ETH] GOT IP");
      Serial.print("[ETH] IP: ");
      Serial.println(ETH.localIP());
      Serial.print("[ETH] Gateway: ");
      Serial.println(ETH.gatewayIP());
      Serial.print("[ETH] DNS: ");
      Serial.println(ETH.dnsIP());
      Serial.print("[ETH] MAC: ");
      Serial.println(ETH.macAddress());

      requestNatEnable();
      break;

    case ARDUINO_EVENT_ETH_DISCONNECTED:
      ethUp = false;
      natEnabled = false;
      natRequested = false;
      Serial.println("[ETH] Link down");
      break;

    case ARDUINO_EVENT_ETH_STOP:
      ethUp = false;
      natEnabled = false;
      natRequested = false;
      Serial.println("[ETH] Stopped");
      break;

    case ARDUINO_EVENT_WIFI_AP_START:
      Serial.println("[AP] Started");
      Serial.print("[AP] IP: ");
      Serial.println(WiFi.softAPIP());
      break;

    case ARDUINO_EVENT_WIFI_AP_STACONNECTED:
      Serial.println("[AP] Client connected");
      Serial.print("[AP] Clients now: ");
      Serial.println(WiFi.softAPgetStationNum());
      break;

    case ARDUINO_EVENT_WIFI_AP_STADISCONNECTED:
      Serial.println("[AP] Client disconnected");
      Serial.print("[AP] Clients now: ");
      Serial.println(WiFi.softAPgetStationNum());
      break;

    default:
      break;
  }
}

// -----------------------------------------------------------------------------
// Arduino setup()
// -----------------------------------------------------------------------------

void setup() {
  Serial.begin(115200);
  delay(1000);

  Serial.println();
  Serial.println("Olimex ESP32-POE-ISO Ethernet-to-WiFi NAT router demo");
  Serial.println("Arduino IDE 1.8.19, ESP32 Arduino core 3.3.8");
  Serial.println();

  WiFi.onEvent(onEvent);

  // Important for ESP32-POE-ISO:
  // Keep PHY power disabled before ETH.begin().
  // The LAN8720A/LAN87xx PHY must not be powered before the ESP32 RMII clock
  // is available on GPIO17.
  pinMode(ETH_PHY_POWER, OUTPUT);
  digitalWrite(ETH_PHY_POWER, LOW);
  delay(200);

  // Start WiFi SoftAP first.
  WiFi.mode(WIFI_AP);

  WiFi.softAPConfig(
    AP_IP,
    AP_GATEWAY,
    AP_NETMASK
  );

  bool apOk = WiFi.softAP(AP_SSID, AP_PASS);

  Serial.print("[AP] softAP result: ");
  Serial.println(apOk ? "OK" : "FAILED");

  // Reconfigure SoftAP DHCP DNS option.
  delay(500);
  setApDnsDhcpOption();

  // Start local debug page.
  server.on("/", handleRoot);
  server.begin();

  Serial.println("[HTTP] Debug server started");
  Serial.println("[HTTP] Open from AP client: http://192.168.4.1/");
  Serial.println("[CLIENT] Use DHCP. Forget WiFi after flashing, then reconnect.");

  // Start Ethernet.
  //
  // ESP32 Arduino core 3.3.8 ETH.begin() order:
  //   ETH.begin(type, phy_addr, mdc, mdio, power, clk_mode);
  //
  // For ESP32-POE-ISO:
  //   type      = LAN8720
  //   phy_addr  = 0
  //   power     = GPIO12
  //   clk_mode  = GPIO17 output
  ETH.begin(
    ETH_PHY_TYPE,
    ETH_PHY_ADDR,
    ETH_MDC_PIN,
    ETH_MDIO_PIN,
    ETH_PHY_POWER,
    ETH_CLK_MODE
  );
}

// -----------------------------------------------------------------------------
// Arduino loop()
// -----------------------------------------------------------------------------

void loop() {
  server.handleClient();

  if (ethUp && !natEnabled && !natRequested) {
    requestNatEnable();
  }

  if (millis() - lastWanTestMs > 10000) {
    lastWanTestMs = millis();
    lastWanTcpTest = testWanTcp();
    printStatus();
  }
}

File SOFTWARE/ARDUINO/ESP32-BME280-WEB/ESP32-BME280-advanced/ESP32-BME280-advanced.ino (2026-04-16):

/*
  =====================================================================
  PROJECT: ESP32 Real-Time Environmental Dashboard (Web Graph Station)
  =====================================================================

  This project turns an ESP32 board into a standalone WiFi
  environmental monitoring station with an advanced real-time
  graphical web dashboard.

  The ESP32 reads data from a BME280 environmental sensor and hosts
  a live interactive website — no cloud, no external server, no PC
  software required.

  Everything runs directly on the ESP32.

  =====================================================================
  WHAT THE DEVICE MEASURES

      • Temperature (°C or °F)
      • Relative Humidity (%)
      • Air Pressure (hPa or PSIA)

  =====================================================================
  WHAT YOU SEE IN THE WEB BROWSER

  When you open the ESP32's IP address, you get a full dashboard with:

      • Live sensor values (big numbers)
      • Scrolling historical graphs
      • Mouse hover crosshair with time + value
      • Real clock time OR elapsed time display
      • Min/Max markers automatically detected
      • Grid and axis label toggles
      • Unit switching (°C/°F, hPa/PSIA)
      • Custom graph colors

  Important:
  The ESP32 ONLY sends sensor data.
  ALL graphs and UI are drawn inside your browser using JavaScript.

  =====================================================================
  SUPPORTED ESP32 BOARDS (AUTO PIN CONFIGURATION)

      • Olimex ESP32-POE
      • Olimex ESP32-POE-ISO
      • Olimex ESP32-POE2
      • Olimex ESP32-EVB
      • Olimex ESP32-C3-DevKit-Lipo
	  • Olimex ESP32-C6-DevKit-Lipo

  The sketch automatically selects the correct I2C pins depending on
  the board you choose in Arduino IDE.

  If you select the wrong board → wrong pins → sensor not detected.

  =====================================================================
  SENSOR USED

      Olimex MOD-BME280
      Measures temperature, humidity, and pressure via I2C.

  =====================================================================
  SOFTWARE YOU MUST INSTALL (ONE TIME)

  1) Install Arduino IDE
     https://www.arduino.cc/en/software

  2) Install ESP32 board support:
     https://docs.espressif.com/projects/arduino-esp32/en/latest/installing.html

     After installation:
     Tools → Board → Select your ESP32 board

  3) Install required libraries:
     Sketch → Include Library → Manage Libraries

     Install these:

        • ESPAsyncWebServer
        • AsyncTCP
        • Adafruit BME280
        • Adafruit Unified Sensor

  =====================================================================
  SPECIAL NOTE FOR ESP32-C3-DevKit-Lipo and ESP32-C6-DevKit-Lipo (JTAG)

  In Arduino IDE:
      Tools → "USB CDC On Boot" → ENABLE

  Without this, the Serial Monitor will not work.

  =====================================================================
  HARDWARE CONNECTION (I2C SENSOR)

  - ESP32-POE / POE2 / POE-ISO / EVB / ESP32-C6 / ESP32-C3 (UEXT)
      Just plug MOD-BME280 into the UEXT connector.

  - ESP32-C3-DevKit-Lipo (NO UEXT connector in older revisions)
      Use wires:

         BME280  →  ESP32-C3
         3.3V    →  3V3
         GND     →  GND
         SDA     →  GPIO 8
         SCL     →  GPIO 9

  =====================================================================
  HOW THE SYSTEM WORKS (STEP-BY-STEP)

  1. ESP32 starts
  2. I2C bus is initialized
  3. BME280 sensor is detected
  4. ESP32 connects to your WiFi
  5. ESP32 starts a web server
  6. Your browser connects to the ESP32
  7. ESP32 sends new sensor data every 2 seconds
  8. Browser updates graphs in real time

  =====================================================================
  HOW TO USE (BEGINNER GUIDE)

  STEP 1 — Enter your WiFi credentials in this code:
      #define WIFI_SSID     "WIFI-NAME"
      #define WIFI_PASSWORD "WIFI-PASSWORD"

  STEP 2 — Upload the sketch to your ESP32

  STEP 3 — Open Serial Monitor
      Tools → Serial Monitor
      Baud rate: 115200

  STEP 4 — Wait for connection
      You will see:
          WiFi Connected!
          IP Address: 192.168.x.xxx

  STEP 5 — Open a web browser and type:
      http://192.168.x.xxx

  That page is hosted directly by your ESP32.

  =====================================================================
  TROUBLESHOOTING

  "BME280 NOT FOUND!"
      → Wrong board selected
      → Wrong wiring (C3 board)
      → Sensor not connected

  No IP address appears
      → Wrong WiFi password
      → Router too far away

  Page opens but no graphs
      → Refresh browser
      → Check Serial Monitor for sensor data

  =====================================================================
  BEGINNER NOTES

  • No Internet is required after WiFi connection.
  • Data resets every time ESP32 restarts.
  • Browser does all graph drawing, ESP32 only sends numbers.
  • You can open the dashboard on phone, tablet, or PC.

  =====================================================================
*/


#include <WiFi.h>
#include <AsyncTCP.h>
#include <ESPAsyncWebServer.h>
#include <Wire.h>
#include <Adafruit_BME280.h>

/* ================= USER WIFI SETTINGS ================= */

#define WIFI_SSID     "WIFI-NAME"
#define WIFI_PASSWORD "WIFI-PASSWORD"

/* ============================================================
   I2C PIN AUTO-CONFIGURATION BASED ON SELECTED BOARD
   ============================================================ */

#if defined(ARDUINO_ESP32_POE) || defined(ARDUINO_ESP32_POE_ISO) || defined(ARDUINO_ESP32_POE2)
// Olimex ESP32-POE / POE-ISO / POE2 (UEXT boards)

  #define SDA_PIN 13
  #define SCL_PIN 16
  #define BOARD_NAME "ESP32-POE family"

#elif defined(ARDUINO_ESP32_POE2)
  #define SDA_PIN 13
  #define SCL_PIN 33
  #define BOARD_NAME "ESP32-POE2"

#elif defined(ARDUINO_ESP32_EVB)
// Olimex ESP32-EVB

  #define SDA_PIN 13
  #define SCL_PIN 16
  #define BOARD_NAME "ESP32-EVB"

#elif defined(ARDUINO_ESP32C3_DEVKIT_LIPO)
// Olimex ESP32-C3-DevKit-Lipo

  #define SDA_PIN 8
  #define SCL_PIN 9
  #define BOARD_NAME "ESP32-C3-DevKit-Lipo"
  
#elif defined(ARDUINO_ESP32C6_DEV)
// Olimex ESP32-C6-DevKit-Lipo

#define SDA_PIN 6
#define SCL_PIN 7
#define BOARD_NAME "ESP32C6 Dev Module"

#else
  #warning "Board not recognized — using default I2C pins!"
  #define SDA_PIN 21
  #define SCL_PIN 22
  #define BOARD_NAME "Unknown board (default pins)"
#endif

#define BME_ADDR 0x77


Adafruit_BME280 bme;

AsyncWebServer server(80);
AsyncWebSocket ws("/ws");
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

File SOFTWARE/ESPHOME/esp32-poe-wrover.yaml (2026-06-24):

esphome:
  name: esp32-poe-wrover
  comment: Olimex ESP32-POE WROVER N4R8 variant with PSRAM and UEXT support

esp32:
  board: esp32dev
  flash_size: 4MB
  framework:
    type: arduino

psram:
  mode: quad
  speed: 80MHz

logger:

# ================= NETWORKING =================

# ---- WiFi (Primary) ----
# Add these entries to secrets.yaml:
# wifi_ssid: "your_wifi_name"
# wifi_password: "your_wifi_password"
wifi:
  ssid: !secret wifi_ssid
  password: !secret wifi_password
  ap:
    ssid: "ESP32-POE-WROVER Fallback"
    password: "fallback123"

captive_portal:

# ---- Ethernet (Alternative to WiFi) ----
# ESPHome cannot use WiFi and Ethernet at the same time.
# To use Ethernet:
#   1. Comment the whole wifi: section above
#   2. Comment captive_portal:
#   3. Uncomment the ethernet: section below
#
# WROVER variants use GPIO0 as Ethernet clock output.
#
#ethernet:
#  type: LAN8720
#  mdc_pin: GPIO23
#  mdio_pin: GPIO18
#  clk:
#    pin: GPIO0
#    mode: CLK_OUT
#  phy_addr: 0
#  power_pin:
#    number: GPIO12
#    ignore_strapping_warning: true

# ================= ONBOARD IO =================

# ---- User Button (BUT1) ----
binary_sensor:
  - platform: gpio
    name: "BUT1 Button"
    pin:
      number: GPIO34
      mode:
        input: true
      inverted: true

# ---- External Power Sense ----
sensor:
  - platform: adc
    pin: GPIO39
    name: "External Power Sense"
    attenuation: 12db
    update_interval: 10s

# ---- Optional Battery Sense ----
# Requires closing the battery sense solder jumper on boards that support it.
#
#  - platform: adc
#    pin: GPIO35
#    name: "Battery Sense"
#    attenuation: 12db
#    update_interval: 10s

# ================= UEXT CONNECTOR =================

# ---- UART on UEXT ----
uart:
  - id: uext_uart
    tx_pin: GPIO4
    rx_pin: GPIO36
    baud_rate: 115200

# ---- I2C Bus on UEXT ----
# WROVER variants use GPIO33 instead of GPIO16 for UEXT SCL.
i2c:
  - id: uext_i2c
    scl: GPIO33
    sda: GPIO13
    scan: true

# ---- SPI Bus on UEXT ----
# UEXT pin 8 MOSI is GPIO2, pin 7 MISO is GPIO15.
# These pins are shared with the microSD interface.
spi:
  - id: uext_spi
    clk_pin: GPIO14
    mosi_pin: GPIO2
    miso_pin: GPIO15

# UEXT SPI chip-select is GPIO5. Add it in the specific SPI device:
#
# cs_pin: GPIO5

# ================= OPTIONAL SD CARD (DISABLED) =================
# To use an SD card, remove the UEXT SPI section above first. SD-card SPI
# uses the same physical pins, but CMD/DATA0 map as MOSI/MISO below.
#
# spi:
#   id: sd_spi
#   clk_pin: GPIO14
#   mosi_pin: GPIO15
#   miso_pin: GPIO2

# ================= CORE SERVICES =================

ota:
  - platform: esphome

api:

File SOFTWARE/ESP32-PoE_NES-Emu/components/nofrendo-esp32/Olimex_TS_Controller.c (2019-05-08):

#include <stdio.h>
#include "driver/i2c.h"

#include "Olimex_I2C.h"
#include "Olimex_TS_Controller.h"
#ifdef	CONFIG_HW_TS_ENA

// empirically derived data: MinX = 307; MaxX = 7759; MinY = 541; MaxY = 7767
// also needs to change the X and Y axis
#define	MAX_X	7450
#define	MAX_Y	7200
#define	OFFSET_X	307
#define	OFFSET_Y	541

const Rectangle
//                 MinX  MaxX, MinY  MaxY
Button_Start    = {   0, 1000, 6500, 7500},
Button_Select   = {6500, 7500, 6500, 7500},
Button_Up       = {3250, 4250, 6500, 7500},
Button_Down     = {3250, 4250,    0, 1000},
Button_Left     = {   0, 1000, 3250, 4250},
Button_Right    = {6500, 7500, 3250, 4250},
Button_ButtonA  = {   0, 1000,    0, 1000},
Button_ButtonB  = {6500, 7500,    0, 1000},

// up + left	1300 5400
// up + right	5400 5200
// up + A		1500 4400
// up + B		5400 3400
// down + left	2100 1800
// down + right	5100 2200
// down + A		2000  700
// down + B		5100  700
// left + A		 500 1700
// left + B		4000 1600
// right + A	2600 2300
// right + B	6800 2300
Combo_Up_Left    = {1300-500, 1300+500, 5400-500, 5400+500},
Combo_Up_Right   = {5400-500, 5400+500, 5200-500, 5200+500},
Combo_Up_ButA    = {1500-500, 1500+500, 4400-500, 4400+500},
Combo_Up_ButB    = {5400-500, 5400+500, 3400-500, 3400+500},

Combo_Down_Left  = {2100-500, 2100+500, 1800-500, 1800+500},
Combo_Down_Right = {5100-500, 5100+500, 2200-500, 2200+500},
Combo_Down_ButA  = {2000-500, 2000+500,  700-500,  700+500},
Combo_Down_ButB  = {5100-500, 5100+500,  700-500,  700+500},

Combo_Left_ButA  = { 500-500,  500+500, 1700-500, 1700+500},
Combo_Left_ButB  = {4000-500, 4000+500, 1600-500, 1600+500},
Combo_Right_ButA = {2600-500, 2600+500, 2300-500, 2300+500},
Combo_Right_ButB = {6800-500, 6800+500, 2300-500, 2300+500};


int TS_Read_I2C_Data (unsigned char Data[])
{
	//#define	PRINT_BYTES
	I2C_Read_Slave(TS_I2C_ADDR, TS_MASTER_NUM, Data, 5);
	#ifdef	PRINT_BYTES
	for (int i=0; i<5; i++)
		printf ("Byte[%d] = %d (0x%x);\t", i, Data[i], Data[i]);
	printf ("\n");
	#endif
	if (Data[0] != 0x81)	// if screen is touched 0th byte will have value 0x81
		return 0;

	return 1;
}

Coordinates TS_Calculate_Data (unsigned char InputData[])
{
	Coordinates OutputData;
	// convert I2C data into TS coordinates
	OutputData.X = ((int)InputData[2]<<8) | InputData[1];
	OutputData.Y = ((int)InputData[4]<<8) | InputData[3];

	// fix the offset
	OutputData.X  = OutputData.X - OFFSET_X;
	OutputData.Y  = OutputData.Y - OFFSET_Y;
	
	// fix the direction of the value
	OutputData.Y  = MAX_Y - OutputData.Y;
	if (OutputData.Y < 0)
		OutputData.Y = 0;

	// fix the axis
	OutputData.X  = OutputData.X  ^ OutputData.Y;
	OutputData.Y  = OutputData.X  ^ OutputData.Y;
	OutputData.X  = OutputData.X  ^ OutputData.Y;

	return OutputData;
}

int TS_Detect_Buttons (Coordinates Data)
{
	int Result = 0xffff;

	Result &= ~(TS_Check_Pressed (Button_Start  , Data.X, Data.Y)<<TS_BUTTON_START);
	Result &= ~(TS_Check_Pressed (Button_Select , Data.X, Data.Y)<<TS_BUTTON_SELECT);
	Result &= ~(TS_Check_Pressed (Button_ButtonA, Data.X, Data.Y)<<TS_BUTTON_A);
	Result &= ~(TS_Check_Pressed (Button_ButtonB, Data.X, Data.Y)<<TS_BUTTON_B);

	Result &= ~(TS_Check_Pressed (Button_Up     , Data.X, Data.Y)<<TS_BUTTON_UP);
	Result &= ~(TS_Check_Pressed (Button_Down   , Data.X, Data.Y)<<TS_BUTTON_DOWN);
	Result &= ~(TS_Check_Pressed (Button_Left   , Data.X, Data.Y)<<TS_BUTTON_LEFT);
	Result &= ~(TS_Check_Pressed (Button_Right  , Data.X, Data.Y)<<TS_BUTTON_RIGHT);

	if (TS_Check_Pressed(Combo_Up_Left , Data.X, Data.Y))Result&=~((1<<TS_BUTTON_UP)|(1<<TS_BUTTON_LEFT));
	if (TS_Check_Pressed(Combo_Up_Right, Data.X, Data.Y))Result&=~((1<<TS_BUTTON_UP)|(1<<TS_BUTTON_RIGHT));
	if (TS_Check_Pressed(Combo_Up_ButA , Data.X, Data.Y))Result&=~((1<<TS_BUTTON_UP)|(1<<TS_BUTTON_A));
	if (TS_Check_Pressed(Combo_Up_ButB , Data.X, Data.Y))Result&=~((1<<TS_BUTTON_UP)|(1<<TS_BUTTON_B));

	if (TS_Check_Pressed(Combo_Down_Left , Data.X, Data.Y))Result&=~((1<<TS_BUTTON_DOWN)|(1<<TS_BUTTON_LEFT));
	if (TS_Check_Pressed(Combo_Down_Right, Data.X, Data.Y))Result&=~((1<<TS_BUTTON_DOWN)|(1<<TS_BUTTON_RIGHT));
	if (TS_Check_Pressed(Combo_Down_ButA , Data.X, Data.Y))Result&=~((1<<TS_BUTTON_DOWN)|(1<<TS_BUTTON_A));
	if (TS_Check_Pressed(Combo_Down_ButB , Data.X, Data.Y))Result&=~((1<<TS_BUTTON_DOWN)|(1<<TS_BUTTON_B));

	if (TS_Check_Pressed(Combo_Left_ButA , Data.X, Data.Y))Result&=~((1<<TS_BUTTON_LEFT) |(1<<TS_BUTTON_A));
	if (TS_Check_Pressed(Combo_Left_ButB , Data.X, Data.Y))Result&=~((1<<TS_BUTTON_LEFT) |(1<<TS_BUTTON_B));
	if (TS_Check_Pressed(Combo_Right_ButA, Data.X, Data.Y))Result&=~((1<<TS_BUTTON_RIGHT)|(1<<TS_BUTTON_A));
	if (TS_Check_Pressed(Combo_Right_ButB, Data.X, Data.Y))Result&=~((1<<TS_BUTTON_RIGHT)|(1<<TS_BUTTON_B));

	if (Result != 0xffff)
	{
		//printf ("Result = %x\n", Result);
		printf ("Buttons pressed: ");
		if ((~Result) & (1<<TS_BUTTON_LEFT))     printf ("Left, ");
		if ((~Result) & (1<<TS_BUTTON_RIGHT))    printf ("Right, ");
		if ((~Result) & (1<<TS_BUTTON_UP))       printf ("Up, ");
		if ((~Result) & (1<<TS_BUTTON_DOWN))     printf ("Down, ");

		if ((~Result) & (1<<TS_BUTTON_START))    printf ("Start, ");
		if ((~Result) & (1<<TS_BUTTON_SELECT))   printf ("Select, ");
		if ((~Result) & (1<<TS_BUTTON_A))        printf ("ButA, ");
		if ((~Result) & (1<<TS_BUTTON_B))        printf ("ButB, ");
		printf ("\n");
	}

	return Result;
}
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

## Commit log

2018-09-06 initial upload
    [ESP32-PoE_Rev_B-B.Cu.gbr, ESP32-PoE_Rev_B-B.Mask.gbr, ESP32-PoE_Rev_B-B.Paste.gbr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]
2018-09-07 Update
    Removed redundant text
    [ESP32-PoE_Rev_B1.kicad_pcb]
2018-09-11 Update
    revision B2 update, added change long
    [ESP32-PoE_Rev_B-B.Cu.gbr, ESP32-PoE_Rev_B-B.Mask.gbr, ESP32-PoE_Rev_B-B.Paste.gbr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]
2019-01-02 Update
    Hardware revision C
    [ESP32-PoE_Rev_C.kicad_pcb, ESP32-PoE_Rev_C.sch]
2019-02-22 Update
    Added 3D view.
    [BM02B-SRSS-TB.step, CD32_inductor.step, ELECTROLITIC_CAPACITOR_RADIAL_8X12.step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]
2019-03-11 add ESP32 Nes Emu
    [partitions.csv]
2019-04-23 Fixing broken symbols.
    o Adding back missing symbols: Earth and Si3402-B-GM(QFN-20_5x5mm) in
    ESP32-PoE_Rev_C.lib
2019-06-13 Added demo
    Added ESP32-PoE iperf demo
    [partitions_example.csv]
2019-12-10 Update ethernet example
    Added ethernet example for ESP-IDF v4.0
    Renamed old one to avoid confusions.
    [ethernet_example_main.c, main.c, olimex_ethernet.c]
2020-01-14 Update
    Latest revision and notes
    [BAT54.step, CD32_inductor.step, Connector_1Port_RJ45_Magjack_10-100Base-T_AutoMDIX_PoE_Wurth_Electronics-7499211002A_DigiKey-732-4976-ND.step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]
2020-06-09 Update
    new revision
    [BAT54.step, Connector_1Port_RJ45_Magjack_10-100Base-T_AutoMDIX_PoE_Wurth_Electronics-7499211002A_DigiKey-732-4976-ND.step, DO-214AB_SMC.step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]
2020-10-27 New example
    Ethernet + WIFI Arduino demo
2021-01-07 New example for ethernet
    Espressif example "ethernet\basic" take as a base (ESP-IDF v4.2) and adapted to match the ESP32-POE hardware.
2021-01-08 Update README.md
    Updated README to match the ESP32-PoE hardware and configurations
2021-04-01 New example
    ESP32 Azure Arduino ETH WIFI example template
2021-08-20 Update
    I2C address changed from 0x76 to 0x77 to match the value defined by the default hardware position of the jumper.
2021-11-05 update
    new reivison
    [BAT54.step, Cap_PTH_6_3x11x2_5mm.step, Connector_1Port_RJ45_Magjack_10-100Base-T_AutoMDIX_PoE_Wurth_Electronics-7499211002A_DigiKey-732-4976-ND.step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]
2022-02-15 Update
    Revision I
    [BAT54.step, Cap_PTH_6_3x11x2_5mm.step, Connector_1Port_RJ45_Magjack_10-100Base-T_AutoMDIX_PoE_Wurth_Electronics-7499211002A_DigiKey-732-4976-ND.step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]
2022-11-15 Update
    Revisions J and K
    [BAT54.step, Cap_PTH_6_3x11x2_5mm.step, Connector_1Port_RJ45_Magjack_10-100Base-T_AutoMDIX_PoE_Wurth_Electronics-7499211002A_DigiKey-732-4976-ND.step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]
2022-11-30 New example
    Power sense and battery sense examples
2023-05-11 Update
    Revision L
    [BAT54.step, Cap_PTH_6_3x11x2_5mm.step, Connector_1Port_RJ45_Magjack_10-100Base-T_AutoMDIX_PoE_Wurth_Electronics-7499211002A_DigiKey-732-4976-ND.step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]
2023-10-18 Examples update
    Updated ethernet examples with updated macro prefix (from "SYSTEM_" to "ARDUINO_").
2024-03-03 Fixed missing LED pinMode assignement
    The LED ont pin 13 does not work without this.
    [ESP32_PoE_Ethernet_WebServer.ino]
2024-03-03 Added comments + fixed missing LED pin mode assignment
    [ESP32_PoE_Ethernet_WebServer.ino]
2024-03-05 Update on examples
    Updated Ethernet+SD card example to work with ESP32 package 3.x.x.
    Added an additional comment on the LED pin for the WebServer demo
2025-04-03 Update
    New hardware revision
    [ESP32-PoE_Rev_M-B_Cu.gbr, ESP32-PoE_Rev_M-B_Mask.gbr, ESP32-PoE_Rev_M-B_Paste.gbr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]
2025-11-28 New demo
    MOD-GPS and ESP32-POE/ESP32-POE-ISO demo
2026-02-05 Update
    Web-page demos with visualisation of ESP32 and BME280
2026-02-06 Update
    Added Olimex ESP32-C6 support
2026-05-07 Update
    Added case design for esp32-poe with antenna
    [bambu-lab-pattern-olimex-esp32-poe-ea-f.3mf, olimex-esp32-poe-ea-f-v13.stl]
2026-06-09 Update
    ESPHome configs for ESP32-POE and ESP32-POE-WROVER variants
2026-06-24 Added platformio configs
    for esp32-poe and esp32-poe-iso and board variants
2026-06-24 Update
    Added more yamls for all board variants and READMEs for
2026-07-28 Update
    Hardware revision M2
    [ESP32-PoE_Rev_M-B_Cu.gbr, ESP32-PoE_Rev_M-B_Mask.gbr, ESP32-PoE_Rev_M-B_Paste.gbr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]

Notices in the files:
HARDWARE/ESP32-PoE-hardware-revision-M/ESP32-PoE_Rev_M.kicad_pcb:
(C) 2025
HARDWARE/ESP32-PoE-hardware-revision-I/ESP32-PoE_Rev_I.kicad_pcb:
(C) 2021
